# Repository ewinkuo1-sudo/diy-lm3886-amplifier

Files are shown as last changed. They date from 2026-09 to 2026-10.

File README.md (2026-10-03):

# LM3886 DIY AB 類立體聲後級

用兩顆 LM3886T 製作**內建電源的雙聲道純後級**，搭配使用者現有的 **Eversolo DAC-Z10（DAC＋前級）**。訊號路徑為 **DAC-Z10 RCA 前級輸出 → 本後級 → 喇叭**，音量與訊源選擇由 Z10 負責。本機採固定增益，前面板規劃電源及狀態指示。

這是第三個獨立擴大機專案，可與 [TPA3255 練習機](https://github.com/ewinkuo1-sudo/diy-tpa3255-amplifier) 及 [Purifi 主力機](https://github.com/ewinkuo1-sudo/diy-purifi-amplifier) 比較架構與製作經驗。

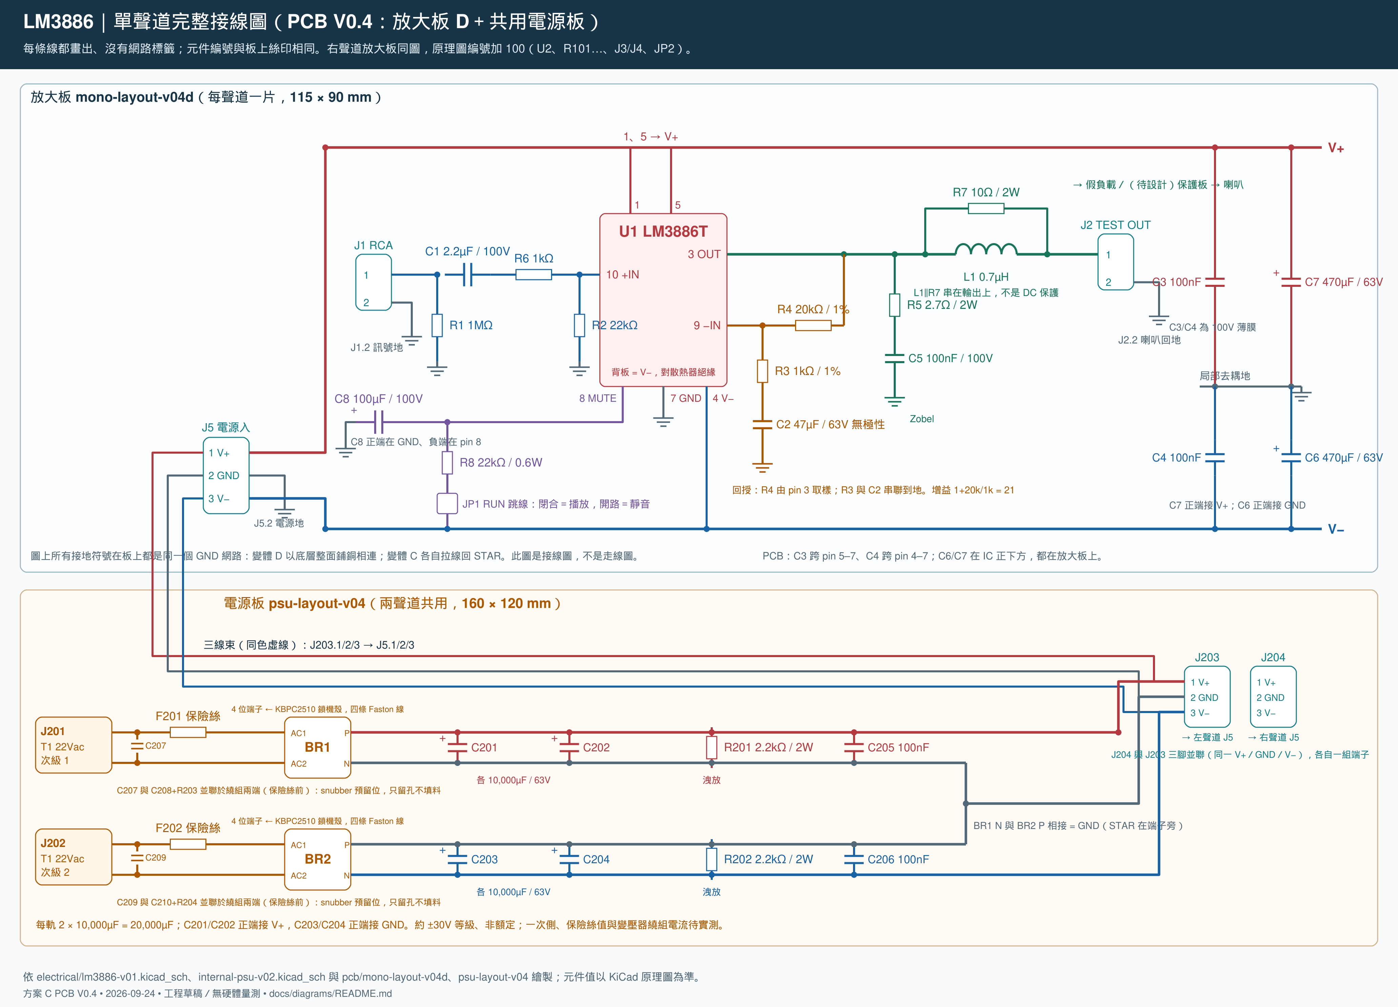
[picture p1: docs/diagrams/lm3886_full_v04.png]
單聲道完整接線圖（放大與電源電路自 V0.4 起未變，適用 V0.5.1 與規劃中的 V0.6）


## 目前狀態（2026-10-01 深夜）

- **方向改為「先挑殼、散熱器放殼內、以現有零件重排 PCB＝V0.6」**。機殼改選台灣現貨 **弘宙 102**（型錄 b420 前面板寬、d395 機身寬、c285 深不含把手、e105 高 → 內尺寸估 **393×273×100**，賣家未確認；BZ4312A2 留給下一台）。配置：後排「放大板 L｜電源板｜放大板 R」、前排變壓器居中、左前控制板、右前市電板；散熱器 **150×90×30 鋁擠 ×2 內置兩側**（鰭片朝牆、底板朝板、上蓋底板開通風孔；規格依 8 Ω 連續正弦 θSA ≤1.2 °C/W）。3D 配置：[chassis_102_v06_3d.png](docs/diagrams/chassis_102_v06_3d.png)。下單前問賣家內寬、通風孔、後面板是否空白。
- **控制／保護板 CTRL 與市電板 MAINS 第一版原理圖＋PCB V0.6 已畫**（2026-10-01 深夜）：CTRL 70×120（UPC1237 保護、7812 輔助電源、G2RL-1-E 喇叭繼電器 ×2、SFH617A 光耦靜音、TL431 旁通計時）、MAINS 70×100（SL22 10005 NTC、K_BYP、K_TRIG）。ERC 0、DRC 0 錯誤，市電／低壓銅箔距離 7.25 mm。繼電器 DC 分斷取 30 VDC 等級（使用者接受）。見 [docs/14](docs/14-V0.4-控制與保護板設計草案.md) 狀態列、[pcb/README「PCB V0.6」](pcb/README.md)。
- **放大板與電源板 V0.6 也畫了（2026-10-02 凌晨，以型錄幾何先畫）**：放大板 **90×80**，U1 用 KiCad 函式庫 TO-220-11 直立封裝、背板貼板邊直接鎖散熱器；電源板 **92×120**，兩欄 381LX、GBJ 朝前、AC 端子朝變壓器、DC 端子朝放大板（snubber 預留位未上板）。**V0.6 五板皆 DRC 0 錯誤**，機箱 3D 已換成真板。IC 幾何、C2 腳距、繼電器腳位到貨要核對。詳見 [pcb/README](pcb/README.md)；V0.5.1／V0.5／V0.4／V0.3 為歷史。**全部仍是工程草稿，不可送製。**
- **放大板與電源板現行為 V0.6.1（2026-10-03 使用者選定併入 main）**：零件、擺位、板尺寸、機殼與散熱器配置與 V0.6 完全相同，只把載流走線加寬到間距規則與鄰近焊盤允許的上限（放大板負電源腳間線 0.5→0.9、電源板主幹 3→5 等），兩板 DRC 0；V0.6 vs V0.6.1 走線電阻對照見 [pcb/README「PCB V0.6.1」](pcb/README.md)。CTRL／MAINS 仍為 V0.6 板檔。
- **目標喇叭 Usher Be-718**（標稱 8 Ω、實測低中音 >6 Ω、約 85 dB）：匹配估算見 [docs/01](docs/01-設計規格.md)；功率／散熱討論以 6–8 Ω 為準。
- **已到貨**：環形變壓器、yosontw 40 件電阻／WIMA／CDE／ROE（2026-09-22）、LM3886T 拆機品 ×4（2026-09-29，T 封裝、NS 打標）。已付 NT$4,821，整機估 10.9k–16.2k（[採購總表 §5](docs/00-採購總表.md)）。
- **2026-10-01 已量變壓器電氣**（採購總表 §1）：標籤 22V 4.2A×2＋12V 1A ≈ **197 VA**；兩組 22V 空載各 22.29 Vac（DCR 0.25／0.2 Ω）、串接 44.6 Vac 同相；12V 12.27 Vac；一次側約 2 Ω；市電 110 V。最壞軌電壓 **±33.5 V**，帶載推估連續 30–32 W／8 Ω。保險絲提案：一次側 T2.5A（有軟啟動）／T3.15A、22V 各 T5A、12V T1.25A。**未量：帶載電壓、絕緣、溫升。**
- **已量零件尺寸**（2026-09-23）：381LX Ø35×50 腳距 10；EKE Ø12×25 腳距 5；EGW 軸向 40×Ø20（V0.5 起改站立封裝，**腳距 15 是假設待實量**）；變壓器 Ø120×約 50、中心孔 Ø40。
- **選型定案**：C 方案雙聲道、雙橋整流、4×10,000µF／63V；47µF＝ROE EGW 無極性、470µF＝ROE EKE／63V；每聲道 30～40W／8Ω 為探索範圍而非額定。
- **本輪可買**：GBJ2510 ×2＋小散熱片＋M3 件、保險絲、機殼（弘宙 102）、散熱器 150×90×30 ×2、控制板零件一套（G2RL-1-E 12VDC ×5、UPC1237 ×2、SL22 10005、SFH617A-3 ×2、TL431、BC327 ×2、7812 等，見採購總表控制板列）；其餘未購件與順序見採購總表 §2／§3。

**要買零件看 [採購總表](docs/00-採購總表.md)**（已買／未買兩張表＋購買順序）。**要接手看 [HANDOFF.md](HANDOFF.md)**。**歷史逐日紀錄看 [CHANGELOG.md](CHANGELOG.md)**。

## 系統方塊

```mermaid
flowchart LR
    PRE[DAC-Z10\nDAC＋前級／音量控制]
    subgraph AMP[LM3886 純後級機殼]
        IN[RCA 輸入] --> C[兩顆 LM3886T 功率級]
        C --> D[輸出穩定網路]
        D --> REL[喇叭保護／繼電器\nCTRL 板 V0.6 草稿]
        AC[AC 入口／保險絲／開關] --> SS[軟啟動 NTC＋旁通\nMAINS 板 V0.6 草稿]
        SS --> T[隔離環形變壓器]
        T --> PSU[雙橋整流／濾波]
        PSU --> C
        CTRL[UPC1237 啟停／DC 偵測\nCTRL 板 V0.6 草稿] -. 控制 .-> C
        CTRL -. 控制 .-> REL
    end
    PRE --> IN
    REL --> SPK[喇叭]
```

## 設計重點

| 項目 | 目前選擇／待驗證 |
|---|---|
| 功率級 | LM3886T ×2，非橋接、非並聯；已訂拆機品，/NOPB 未確認 |
| 輸出目標 | 每聲道約 30～40W／8Ω 探索範圍，額定待實測 |
| 電源 | 已訂雙 22Vac＋單 12Vac；雙橋架構保留，約 ±30V 等級；VA／電流／最大電壓待確認 |
| 增益 | IC 中頻閉迴路 21 倍；含輸入串阻後約 20.09 倍 |
| 輸入 | DAC-Z10 RCA 前級輸出；後級 40W 約需 0.89Vrms，音量由 Z10 控制 |
| 靜音／保護 | 放大板保留測試跳線；CTRL 板 V0.6 草稿以 UPC1237 做 DC 偵測、開機延遲、掉電快斷，光耦接管 JP1 靜音，解除靜音＝喇叭繼電器吸合 |
| 散熱 | T 封裝，**2026-10-01 改以 8 Ω 連續正弦為準：每聲道散熱器 ≤1.2 °C/W**（6 Ω 正弦需 ≤0.65）、介面 ≤0.3 °C/W；選 150×90×30 鋁擠內置兩側，估法 θSA≈1000／表面積(cm²)；原 0.4 °C/W 是 ±41 V 前提的保守值 |
| 本版負載 | 8Ω 非感性假負載；目標喇叭 Usher Be-718（標稱 8Ω、低中音實測 >6Ω、靈敏度實測約 85dB），匹配估算見 [01](docs/01-設計規格.md)「目標喇叭」節；真實喇叭需另外驗證 |

TI 列出 ±35V、8Ω 下 50W 的元件性能條件；這不是本機實測規格。[原廠資料](https://www.ti.com/product/LM3886)

## 文件

| 文件 | 內容 |
|---|---|
| [採購總表](docs/00-採購總表.md) | **採購單一入口**：已買／未買、購買順序、商品連結 |
| [設計規格](docs/01-設計規格.md) | 電路、接地、Z10 介面與保護邊界 |
| [功率與散熱估算](docs/02-功率與散熱估算.md) | 可重算的數字、公式與假設 |
| [上電與驗收](docs/04-上電與驗收.md) | 從低電壓到雙聲道功率測試 |
| [內建電源與機構](docs/05-內建電源與機構.md) | 變壓器、整流、接地、機殼分區與電源估算 |
| [喇叭保護與啟停設計計畫](docs/13-喇叭保護與啟停設計計畫.md) | V0.4 需求：保護、延遲、DC 偵測與啟停方案 |
| [V0.4 控制與保護板設計草案](docs/14-V0.4-控制與保護板設計草案.md) | 控制板架構、啟停時序、與現有板介面、繼電器篩選、軟啟動與輔助電源計算；開頭狀態列記 2026-10-01 的選型決定與原理圖／PCB V0.6 偏離之處 |
| [控制板原理圖 CTRL](electrical/preview/control-v01.png)／[市電板 MAINS](electrical/preview/mains-v01.png) | 2026-10-01 第一版（生成器 `tools/build_control_board.py`，ERC 0）；[CTRL PDF](electrical/preview/control-v01.pdf)、[MAINS PDF](electrical/preview/mains-v01.pdf) |
| [導讀圖索引](docs/diagrams/README.md) | 單聲道完整接線圖（放大板＋電源板全部畫出）與五張中文導讀圖 |
| [BOM 草案](electrical/bom-draft.csv) | 由 KiCad netlist 匯出，含選型條件 |
| [驗證紀錄](electrical/validation.md) | ERC、網路核對與未驗證事項 |
| [原理圖說明](electrical/README.md) | 放大板與電源次級 KiCad 圖、看圖與重建方式 |
| [PCB](pcb/README.md) | **現行五板：放大板 V0.6.1 90×80 ×2、電源板 V0.6.1 92×120（V0.6 擺位＋加寬走線）、CTRL V0.6 70×120、MAINS V0.6 70×100，皆 DRC 0**；V0.6 放大板／電源板、V0.5.1／V0.5／V0.4／V0.3 歷史：板檔、DRC、審查結論與載流計算表 |
| [機箱 3D 配置](docs/diagrams/chassis_102_v06_3d.png) | 弘宙 102 內部等角＋俯視（`tools/draw_chassis_scene_v06.py`，pyvista；CTRL／MAINS 為真板 3D，放大板與電源板為 V0.6 目標外形示意） |
| [PCB 看圖資料](pcb/inspection-v051/README.md) | V0.5.1（放大板 D＋電源板）正反面銅箔、組裝、3D 預覽與零件核對表；[V0.5](pcb/inspection-v05/README.md)／[V0.4](pcb/inspection-v04/README.md)／[V0.3](pcb/inspection-v03/README.md) 版保留 |
| [工具說明](tools/README.md) | 各腳本用途與執行順序 |
| [接班進度](HANDOFF.md) | 現況與下一階段工作 |
| [變更紀錄](CHANGELOG.md) | 逐日進度歷史 |

## 電路圖與 PCB 預覽

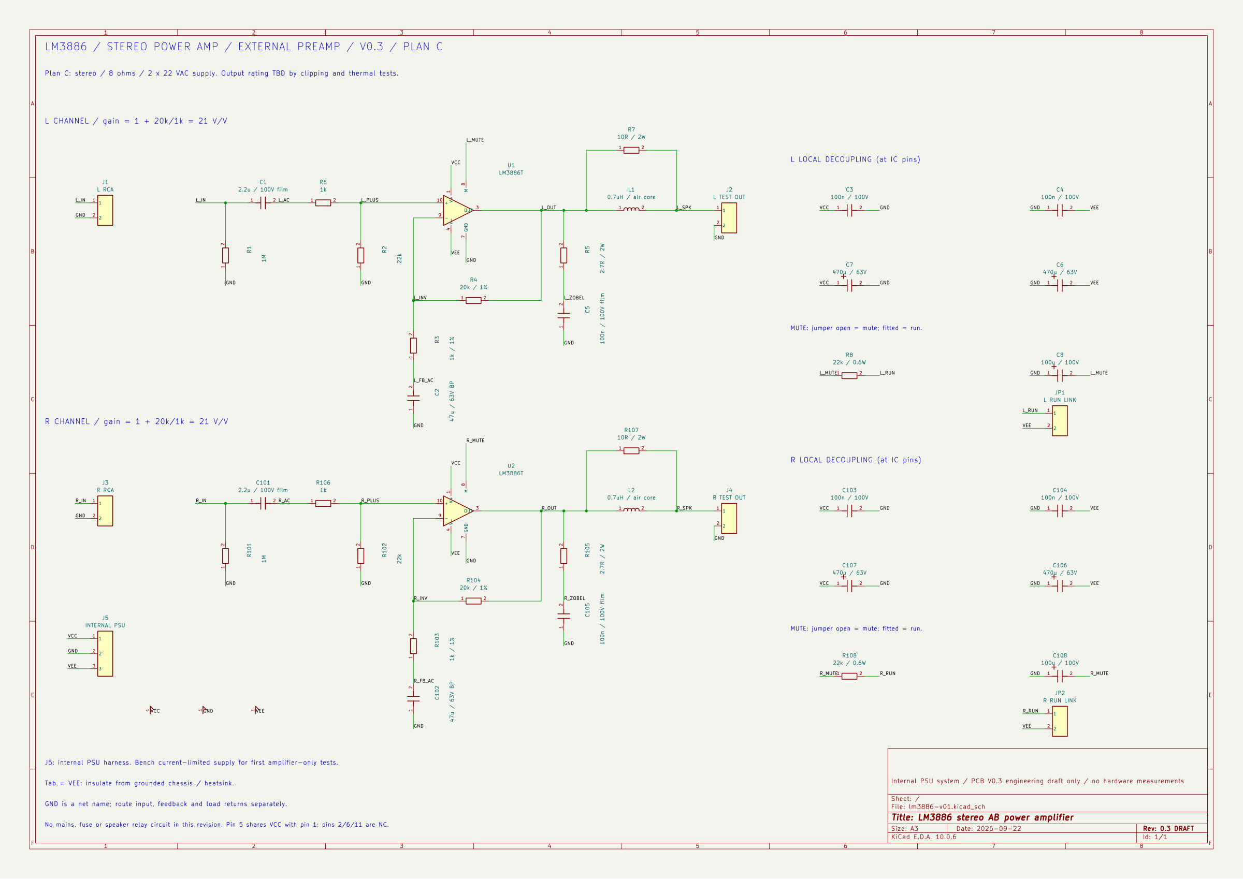
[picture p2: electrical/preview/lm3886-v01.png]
LM3886 放大板電路草案


[放大板 PDF](electrical/preview/lm3886-v01.pdf) · [KiCad 原理圖](electrical/lm3886-v01.kicad_sch)

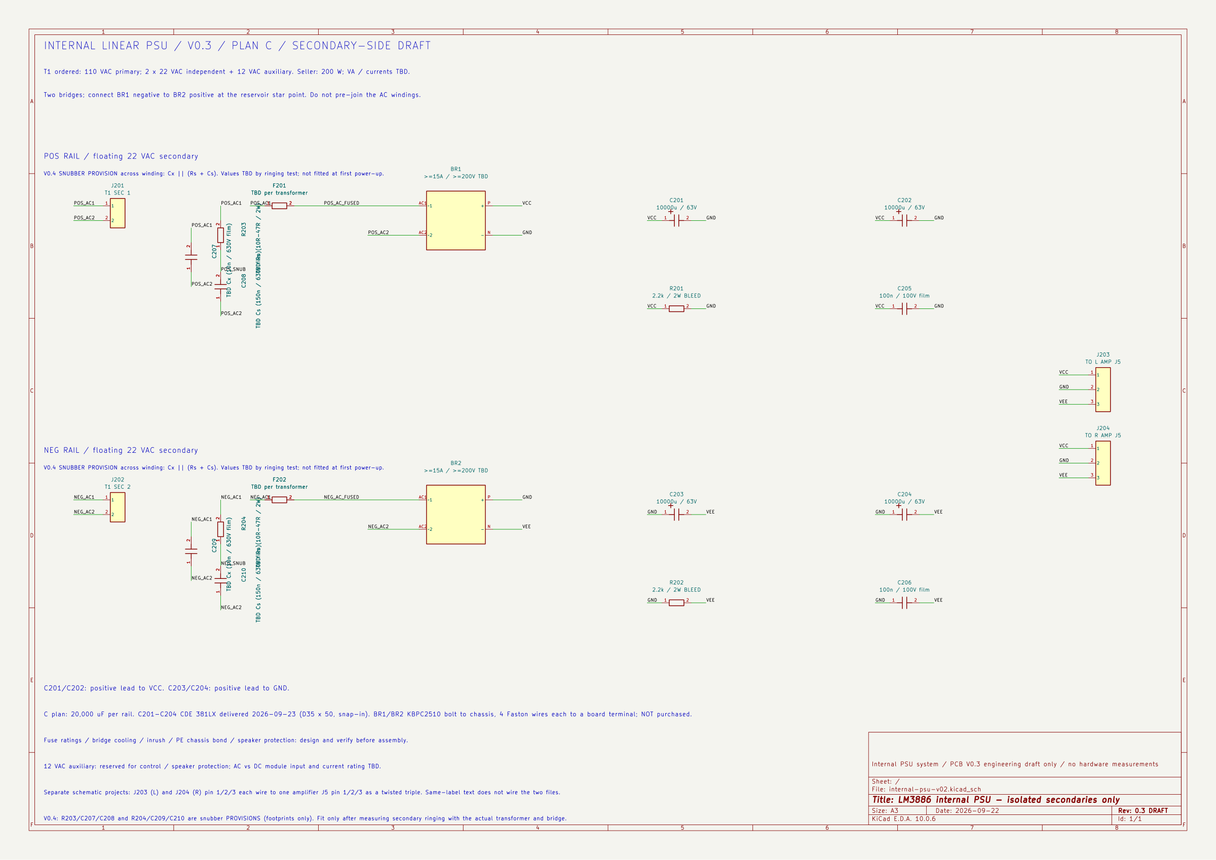
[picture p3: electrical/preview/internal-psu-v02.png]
內建電源次級整流濾波草案


[電源 PDF](electrical/preview/internal-psu-v02.pdf) · [電源 BOM](electrical/psu-bom-draft.csv)

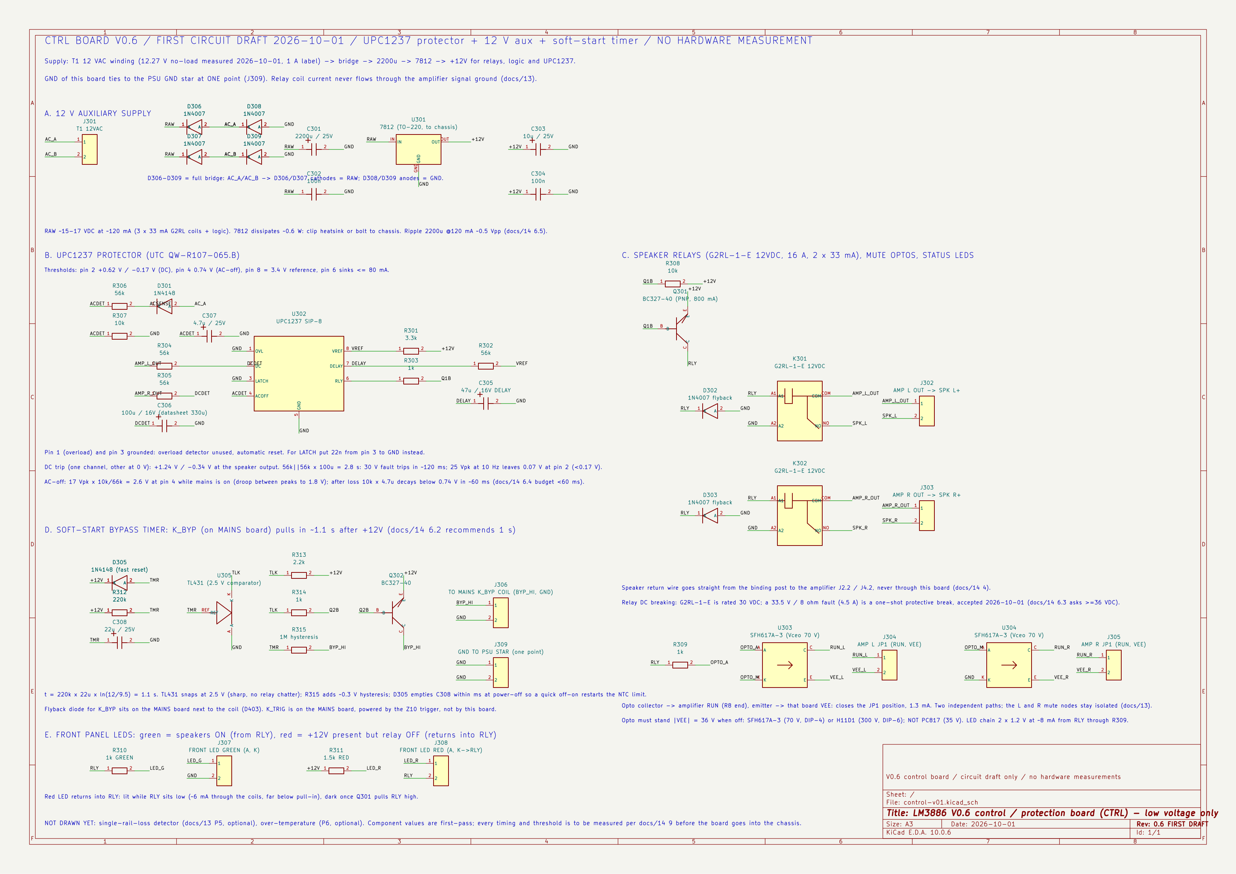
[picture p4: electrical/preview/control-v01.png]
控制／保護板 CTRL 原理圖 V0.6 第一版


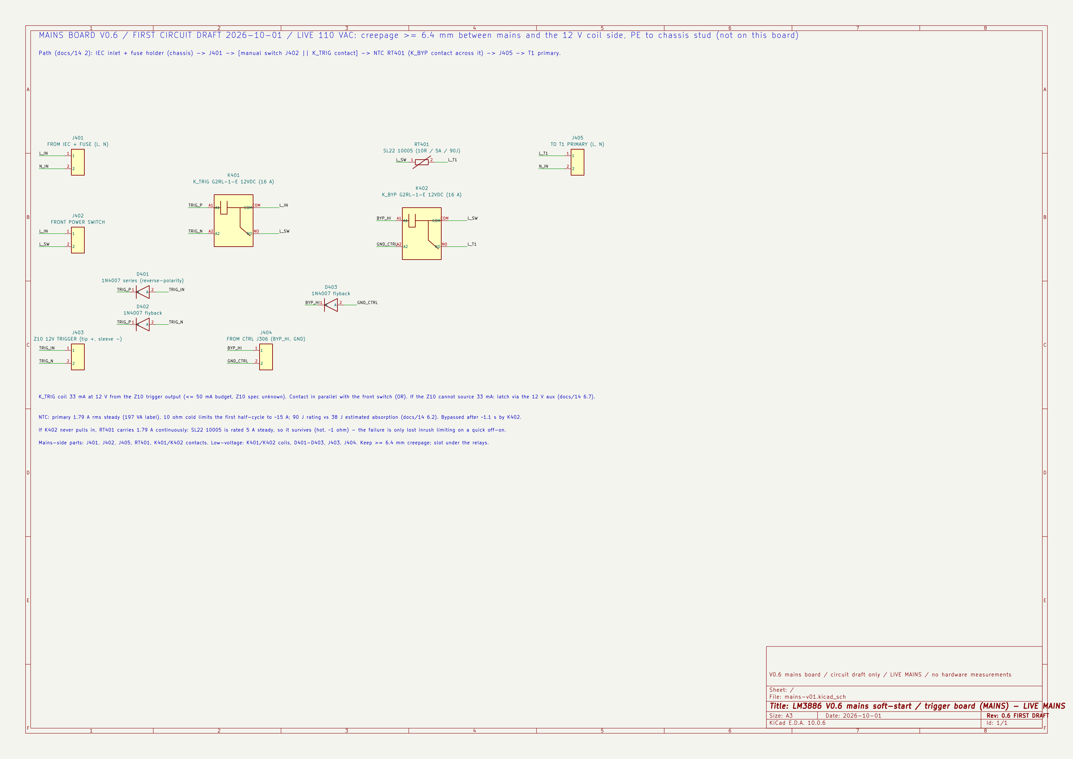
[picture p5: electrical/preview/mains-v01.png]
市電板 MAINS 原理圖 V0.6 第一版


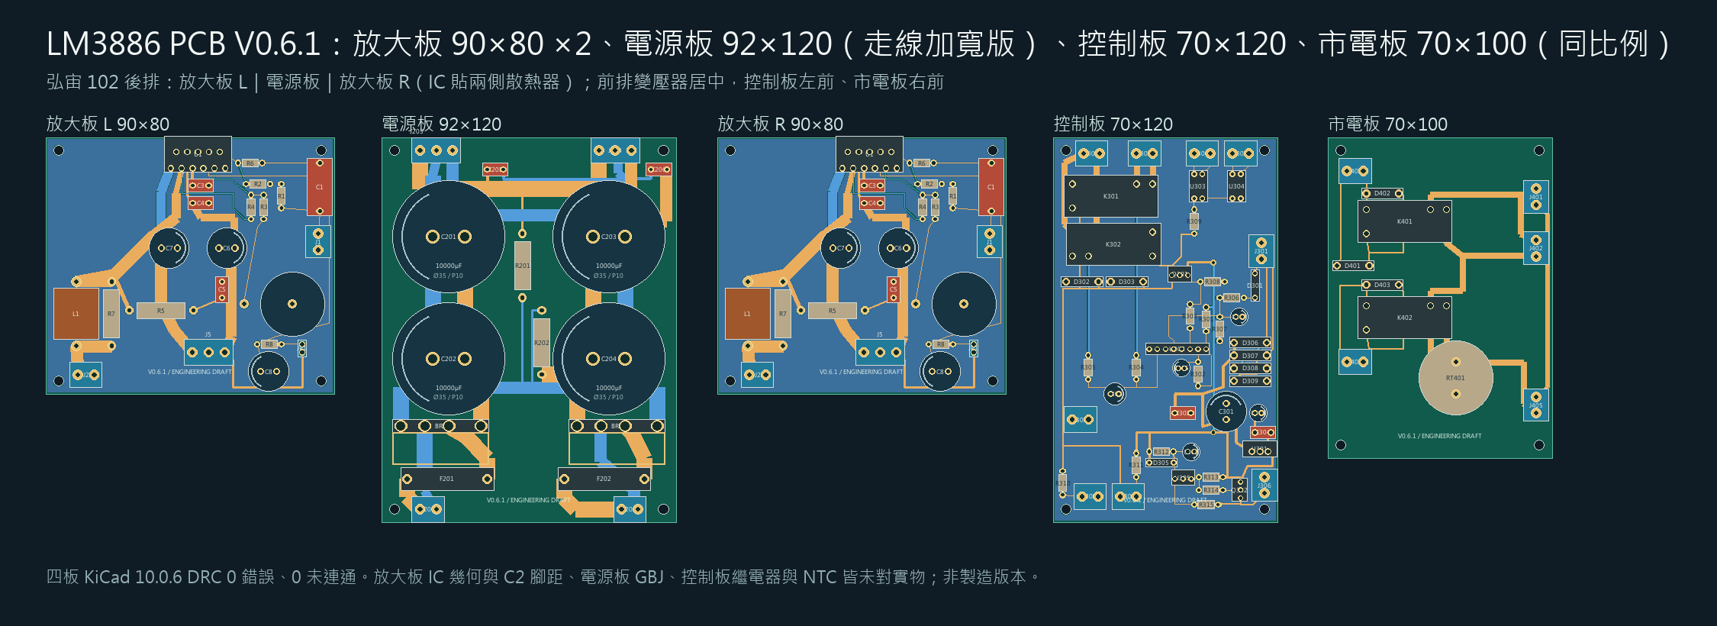
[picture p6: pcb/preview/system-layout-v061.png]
PCB 現行五板：放大板 V0.6.1 90×80 ×2、電源板 V0.6.1 92×120、控制板 V0.6 70×120、市電板 V0.6 70×100


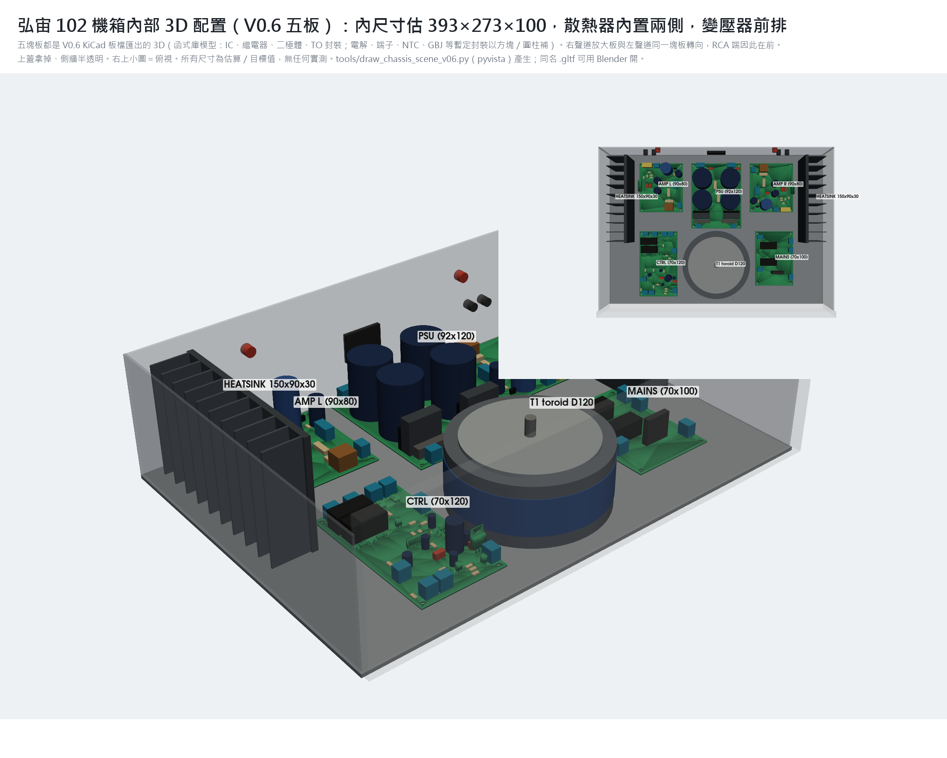
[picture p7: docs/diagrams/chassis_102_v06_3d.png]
弘宙 102 機箱內部 3D 配置（V0.6 五板；V0.6.1 外形、零件與擺位相同，3D 不變）


## 重建與下一步

需要 Python 3、KiCad 10 CLI、Poppler 的 `pdftoppm`，Python 無第三方套件需求：

```sh
python3 tools/rebuild.py
```

`rebuild.py` 目前只重建放大板與電源次級原理圖；控制板與市電板（`tools/build_control_board.py`）和所有 PCB 腳本要手動跑，順序見 [tools/README](tools/README.md)。

下一步（詳見 [HANDOFF](HANDOFF.md)）：量 LM3886T 三個尺寸、問賣家弘宙 102 內寬 → 必要時修正 V0.6.1 放大板的 U1 位置；審控制板原理圖與 PCB、買控制板零件並核對繼電器腳位；麵包板實測 UPC1237 在 12 V 供電下的門檻與延遲；變壓器帶載量測。放大板單獨驗證時仍可用限流實驗電源；成機供電採內建方案。

PDF 重製：先執行 `python3 tools/rebuild.py`，再以安裝 reportlab／pypdf 的 Python 執行 `tools/build_project_pdf.py`；非 Windows 環境需設定 `LM3886_FONT` 指向 CJK TrueType 字型。產物在 `output/`，不入版控。

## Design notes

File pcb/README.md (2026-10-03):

# PCB

**現行版本：放大板與電源板 V0.6.1（2026-10-03 使用者選定併入 main，V0.6 擺位不動、載流走線加寬，見「PCB V0.6.1」節），CTRL／MAINS V0.6。** V0.6 放大板／電源板自同日起為歷史（板檔保留）。**V0.5.1 自 2026-10-02 起為歷史**（2026-10-01 使用者選定併入 main：電源板的整流橋改為 GBJ2510 直立上板，取代 KBPC2510 鎖機殼＋Faston 線；放大板 D 90×90 與 V0.5 相同），兩板 KiCad 10.0.6 DRC 0 違規、0 未連通，見下方「PCB V0.5.1」節；正反面銅箔、組裝極性、3D 預覽與零件核對表在 [inspection-v051](inspection-v051/README.md)。**V0.5 電源板（`psu-layout-v05`）自 2026-10-01 起為歷史**，板檔與 [inspection-v05](inspection-v05/README.md) 保留。**V0.4 自 2026-09-29 起為歷史版本**（放大板 D／C 與電源板板檔、DRC、[inspection-v04](inspection-v04/README.md) 保留）。**V0.3 自 2026-09-24 起為歷史版本**：板檔、DRC、雜湊綁定與審查結論原樣保留供對照，不再修改。

PCB 現行五板（放大板／電源板 V0.6.1，CTRL／MAINS V0.6）

---

## PCB V0.3（B 方案，歷史版本）

**兩片 100×90 mm 單聲道放大板＋一片 160×120 mm 共用電源板。**（2026-09-24 放大板已改為 **115×90 mm** 並重建，DRC 0 違規、0 未連通。）

> ⚠️ **工程草稿，不可送製。** 兩板在 KiCad 10.0.6 下 0 DRC 違規、0 未連通，54＋35 焊盤網路與原理圖相符；但封裝是暫定外框與假設高度，溫升、散熱、機構與線束都沒驗證，**沒有 Gerber**。DRC 與中心線幾何不代表高頻穩定、載流溫升或製造條件已驗證。

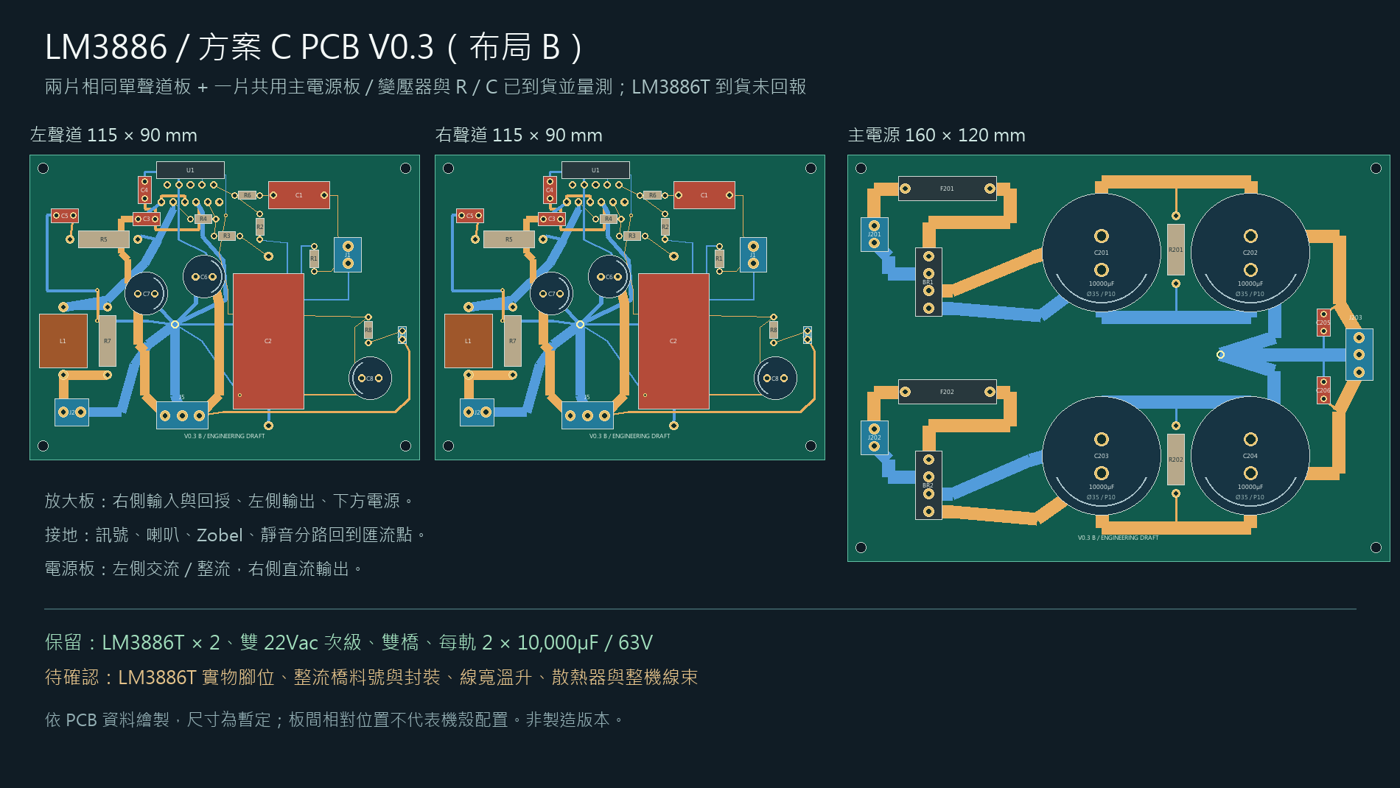
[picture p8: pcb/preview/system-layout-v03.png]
PCB V0.3（歷史）


| 項目 | 單聲道板 ×2 | 電源板 ×1 |
|---|---|---|
| 可編輯 PCB | [mono-layout-v03.kicad_pcb](mono-layout-v03.kicad_pcb) | [psu-layout-v03.kicad_pcb](psu-layout-v03.kicad_pcb) |
| 專案規則 | [KiCad 專案](mono-layout-v03.kicad_pro) | [KiCad 專案](psu-layout-v03.kicad_pro) |
| 圖面 | [PNG](preview/mono-layout-v03.png)／[原生 SVG](preview/mono-v03-native.svg) | [PNG](preview/psu-layout-v03.png)／[原生 SVG](preview/psu-v03-native.svg) |
| 封裝假設 | [清單](mono-layout-v03-footprints.csv) | [清單](psu-layout-v03-footprints.csv) |
| 原生 DRC | [0 違規、0 未連通](mono-v03-drc.json) | [0 違規、0 未連通](psu-v03-drc.json) |

其他資料：[銅箔計算表](current-budget-v03.md)／[完整計算資料與輸入雜湊](current-budget-v03.json)、[驗證摘要](validation-v03.json)、[DRC 檔案綁定](drc-provenance-v03.json)、[正反面／組裝／3D 看圖資料](inspection-v03/README.md)、[零件與封裝核對表](inspection-v03/parts-audit.md)、[左右聲道對照](mono-channel-mapping.csv)。

V0.1／V0.2 板檔、封裝庫與舊腳本已於 2026-09-21 刪除，從 Git 歷史（`41b217c`）取回；僅保留 `archive/v02/*-layout-v02.json` 供 `analyze_pcb_v03.py` 做 V0.2→V0.3 對照。

## PCB V0.4 放大板・變體 C（改良星型接地，2026-09-24 晚）

> ⚠️ **工程草稿，不可送製。** 電路、零件與封裝外框全部沿用 V0.3；只改零件位置與銅箔。KiCad 10.0.6 下 **0 DRC 違規、0 未連通**，54 焊盤網路與原理圖相符，接地分路檢查通過（[validation-v04.json](validation-v04.json)）。變體 D 與電源板 V0.4 見後兩節；**使用者 2026-09-24 選定 D 為主，C 保留備查**。

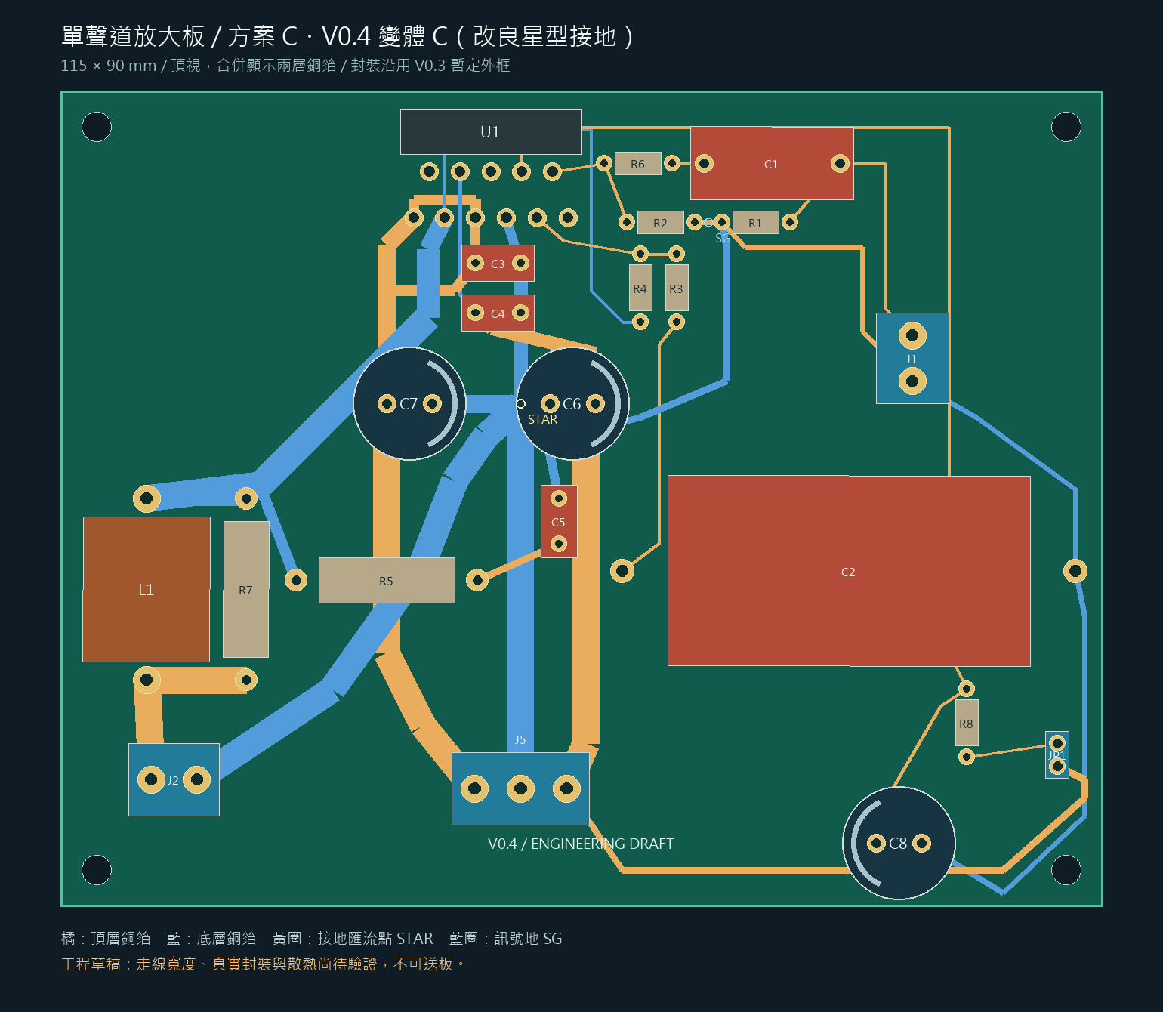
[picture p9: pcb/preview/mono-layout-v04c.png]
PCB V0.4 變體 C


| 項目 | 檔案 |
|---|---|
| 可編輯 PCB／專案 | [mono-layout-v04c.kicad_pcb](mono-layout-v04c.kicad_pcb)／[.kicad_pro](mono-layout-v04c.kicad_pro) |
| 位置與逐段走線定義 | [tools/pcb_layout_v04.py](../tools/pcb_layout_v04.py)（生成器 [build_pcb_v04.py](../tools/build_pcb_v04.py) 沿用 V0.3 封裝庫與 `build()`） |
| 原生 DRC／驗證 | [mono-v04c-drc.json](mono-v04c-drc.json)／[validation-v04.json](validation-v04.json)（`verify_pcb_v04.py`，匯合半徑 5 mm，V0.3 為 4 mm） |
| 走線資料／封裝清單 | [mono-layout-v04c.json](mono-layout-v04c.json)／[footprints.csv](mono-layout-v04c-footprints.csv) |

**改了什麼（對應 2026-09-24 審 V0.3 的七點中屬於放大板的五點）：**

1. 100n 旁路貼 IC 腳：C3 (45.8,19) 跨 pin 5 (V+)–pin 7 (GND)，C4 (50.8,24.5) 跨 pin 4 (V-)–pin 7；V- 從 pin 3／pin 5 之間以 0.5 mm 底層線直下 pin 4（IC 腳間隙 1.4 mm 只容得下這個寬度，是全板最窄處）。
2. 470µF C7 (36,34.5)／C6 (54,34.5) 上移到 IC 正下方，**STAR (50.8,34.5) 就是兩顆之間 9 mm 長的接地條**；J5 留板底，GND 以 3 mm 底層線沿 x=50.8 直上 STAR。
3. J1 訊號與接地並排走到 C1／R1／R2 角落，R1.1 與 R2.1 相鄰 3 mm 形成訊號地 SG (71.5,14.5)，再一條 0.8 mm 底層線回 STAR；C2 與 C8 的接地併入這條訊號地分路（靜音電容只有 mA 級，不再另走一路）。
4. Zobel C5 移到 (55,45)，接地 1.0 mm 直入 STAR；R5 輸出端接到輸出主幹的轉折點 (22,43.5)。
5. C2 改平放在右半 (112,53)，C2.2 靠 R3.1；R8／C8／JP1 移到右下角。**4 個過孔全部取消**（V0.3 有 3 個），每個網路都在單層走完或用零件焊盤換層。

| 銅箔中心線長度（mm） | V0.3 | V0.4 C |
|---|---:|---:|
| C3 接地端→U1.7 | 24.2 | **5.2** |
| C4 接地端→U1.7 | 33.2 | **10.7** |
| C3 旁路迴路（U1.5→C3.1＋C3.2→U1.7） | 43.6 | **10.2** |
| C4 旁路迴路（U1.4→C4.2＋C4.1→U1.7） | 50.2 | **27.0** |
| C6 接地端→STAR | 16.5 | **3.2** |
| C7 接地端→STAR | 11.5 | 9.8 |
| Zobel C5 接地端→STAR | 72.1 | **11.5** |
| J1 接地→STAR（訊號地） | 64.6 | 76.5 |
| C2 接地→STAR（訊號地） | 69.7 | 107.1 |
| J5 接地→STAR | 27.4 | 42.5 |
| U1.3→L1.1 輸出主幹 | 48.8 | 50.2 |
| U1.3→R4.2 回授取樣線 | 7.1 | **50.4** |
| U1.9→R4.1（-IN） | 5.5 | 12.5 |

粗體是本輪目標項。**代價**（有意為之、可再議）：回授取樣線改由 pin 3 向上穿過 pin 2／pin 4 之間，沿 IC 本體下方（y=4.3，底層）繞到右側 R4，長 50 mm——它是低阻抗的輸出取樣，長度本身影響小，但與 -IN 線的 12.5 mm 一起，比 V0.3 多暴露在 IC 附近；訊號地與 J5 回流變長是把 STAR 上移到 IC 下方的直接結果。這些都是中心線幾何，**不代表失真或穩定度已改善**，要等實板量。

**還沒做：** 變體 D（同位置、底層整面 GND 鋪銅取代分支；`verify` 的分路檢查對 D 要跳過）、電源板 V0.4（原理圖已加 J204／snubber，PCB 未畫）、V0.4 的 `current-budget`／`analyze` 對照、3D 與導讀圖。V0.3 板檔與雜湊全部未動。

### 變體 D（底層整面接地，2026-09-24 深夜）

零件位置、訊號與電源銅箔與變體 C **完全相同**；只把 C 的全部 GND 分路線拿掉，改成一整片底層 GND 鋪銅（`AMP_D`，間距 0.3、最小寬 0.35、焊盤熱阻隔 spoke 0.8／gap 0.5）。KiCad 10.0.6 **0 DRC 違規、0 未連通**，鋪銅填完只有一個連通區（沒有孤島）；`verify_pcb_v04.py` 對 D 跳過分路檢查，只核對焊盤網路與鋪銅連通區數。

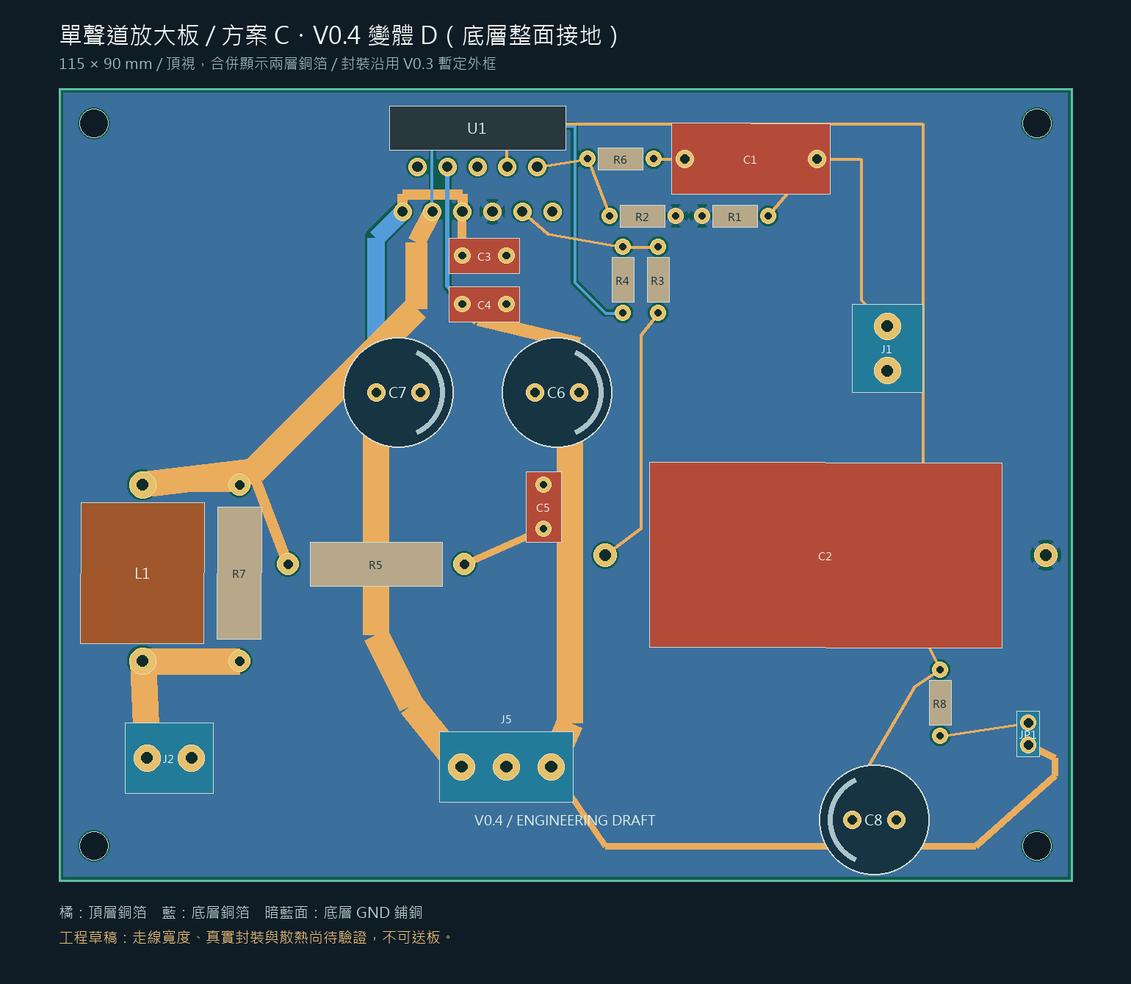
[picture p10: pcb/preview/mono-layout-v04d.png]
PCB V0.4 變體 D


| 項目 | 檔案 |
|---|---|
| 可編輯 PCB／專案 | [mono-layout-v04d.kicad_pcb](mono-layout-v04d.kicad_pcb)／[.kicad_pro](mono-layout-v04d.kicad_pro) |
| 原生 DRC／走線＋鋪銅資料 | [mono-v04d-drc.json](mono-v04d-drc.json)／[mono-layout-v04d.json](mono-layout-v04d.json)（含填銅多邊形） |

**2026-09-24 使用者決定：以 D 為主、C 保留。** 隨即修掉 D 的缺點：3 mm 輸出主幹（pin 3→L1）與 Zobel 接主幹的線改走**頂層**，C7→pin 1 的 V+ 進線改走底層（只在 x=36 切一道 20 mm 的短縫），原本多給 C3.1 的一條 V+ 分支拿掉（C3.1 由 pin 1→pin 5 連線供電）。修後底層鋪銅仍是單一連通區，板左半改由 C7 下方整片相連，不再只靠窄帶；DRC 0 違規、0 未連通。C 與 D 的取捨（星型分路 vs 整面低阻抗回流）沒有實測前不能說哪個一定好，所以 C 的板檔照樣留著。

### 電源板 V0.4（每聲道端子＋snubber 預留，2026-09-24 深夜）

AC 進線、保險絲、橋堆端子、四顆 10,000µF、洩放電阻的位置與 V0.3 相同，對應 2026-09-24 審查的第 5、6 點：

- **J203（左聲道）／J204（右聲道）各一組 3P 端子**在右板邊 (151,42)／(151,66)。STAR 移到 (138,59.08)，C202／C204 的接地各一條 4 mm 底層線斜入 STAR，再各一條 4 mm 線到兩個端子的 G 腳；V+ 走頂層 x=145 到 J203 再沿板邊 x=157 到 J204，V- 走頂層 x=145 從底部上來分別接兩個端子。C205／C206 100n 貼在 STAR 旁。
- **每繞組一組 snubber 預留位**（Cx‖(Rs+Cs)）排在橋堆端子下方一列：C207／C208／R203 在 y=53，C209／C210／R204 在 y=113。接在保險絲**前**的繞組兩端（J201／J202 那一側），1 mm 細線；Cx、Cs 用 `Film_P15`、Rs 用 `R_2W_P20` 暫代，**只留孔不填料**，等變壓器實測振鈴再決定值與是否裝。
- KiCad 10.0.6 **0 DRC 違規、0 未連通**，50 焊盤網路與 V0.4 電源原理圖相符（[psu-v04-drc.json](psu-v04-drc.json)、[validation-v04.json](validation-v04.json)）。負半邊的 snubber 回線原本與 V- 充電線（4 mm）重疊 0.2 mm，改到 y=110.6 後通過。

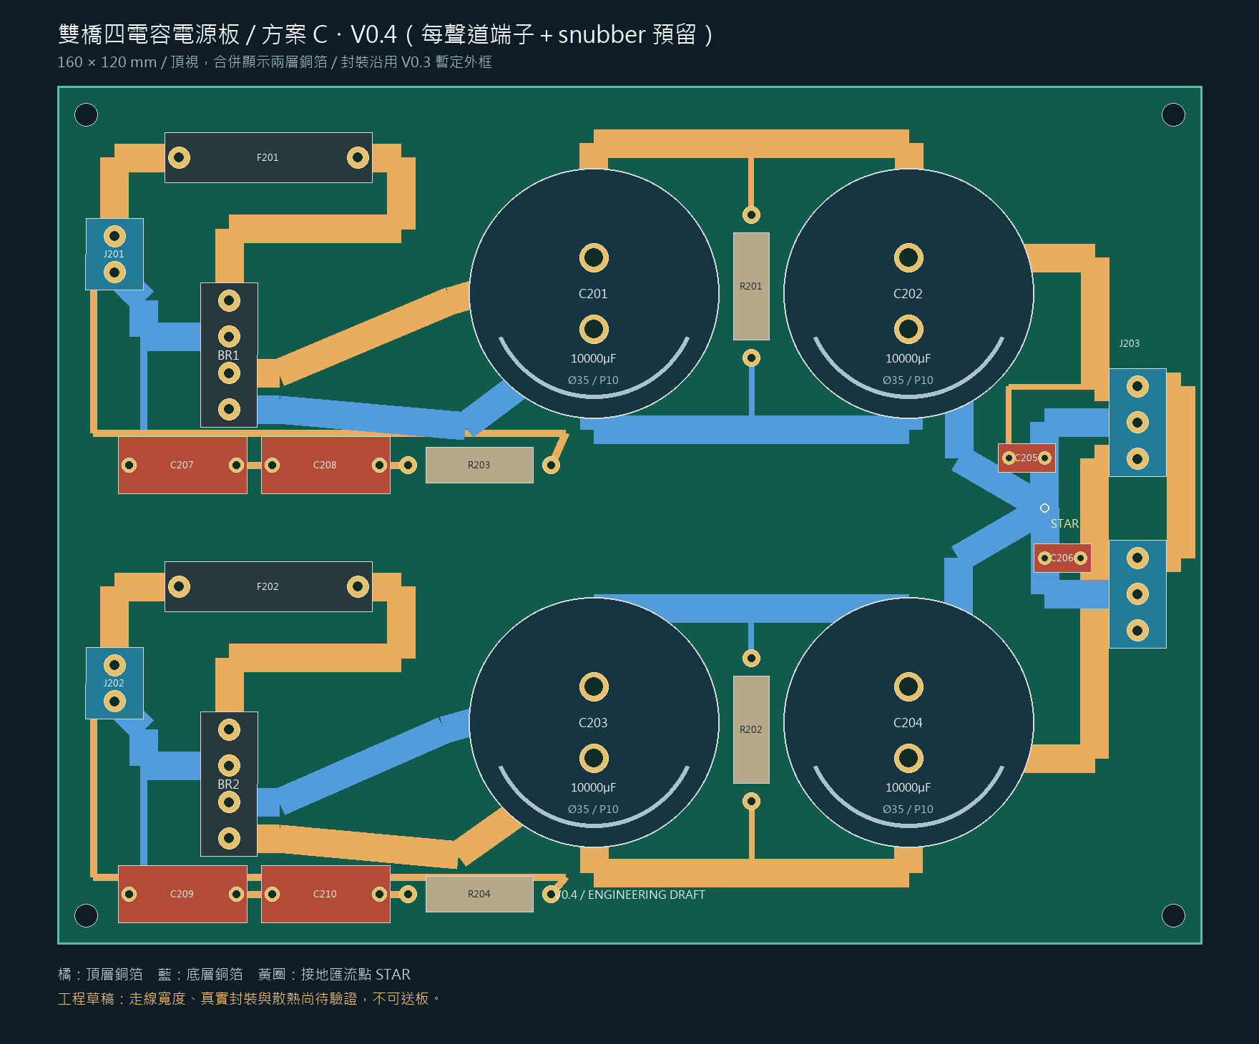
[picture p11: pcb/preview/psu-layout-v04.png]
PCB V0.4 電源板


| 項目 | 檔案 |
|---|---|
| 可編輯 PCB／專案 | [psu-layout-v04.kicad_pcb](psu-layout-v04.kicad_pcb)／[.kicad_pro](psu-layout-v04.kicad_pro) |
| 位置與走線定義 | [tools/pcb_layout_v04_psu.py](../tools/pcb_layout_v04_psu.py) |
| 原生 DRC／走線資料／封裝清單 | [psu-v04-drc.json](psu-v04-drc.json)／[psu-layout-v04.json](psu-layout-v04.json)／[footprints.csv](psu-layout-v04-footprints.csv) |

**V0.4 三塊板都畫完了（放大板 C、放大板 D、電源板）**，等使用者看圖選 C 或 D。之後才做：V0.4 的 `current-budget`／`analyze` 對照、3D 與導讀圖、系統並排圖；V0.3 檔案與雜湊全部未動。

## PCB V0.6.1（2026-10-03，現行：放大板與電源板）

**V0.6.1 = V0.6 放大板與電源板，零件、位置、網路、板尺寸、機殼（弘宙 102）與散熱器（150×90×30 內置）全部不動，只把載流路徑的銅箔加寬到 0.3 mm 間距規則與鄰近焊盤允許的上限。** CTRL／MAINS 不在此版（沿用 V0.6）。兩板 KiCad 10.0.6 DRC **0 錯誤、0 未連通**，[validation-v061.json](validation-v061.json) 通過（同 V0.6 的檢查：焊盤網路、IC 背板貼邊、GBJ 散熱片包絡、鋪銅單一連通區）。

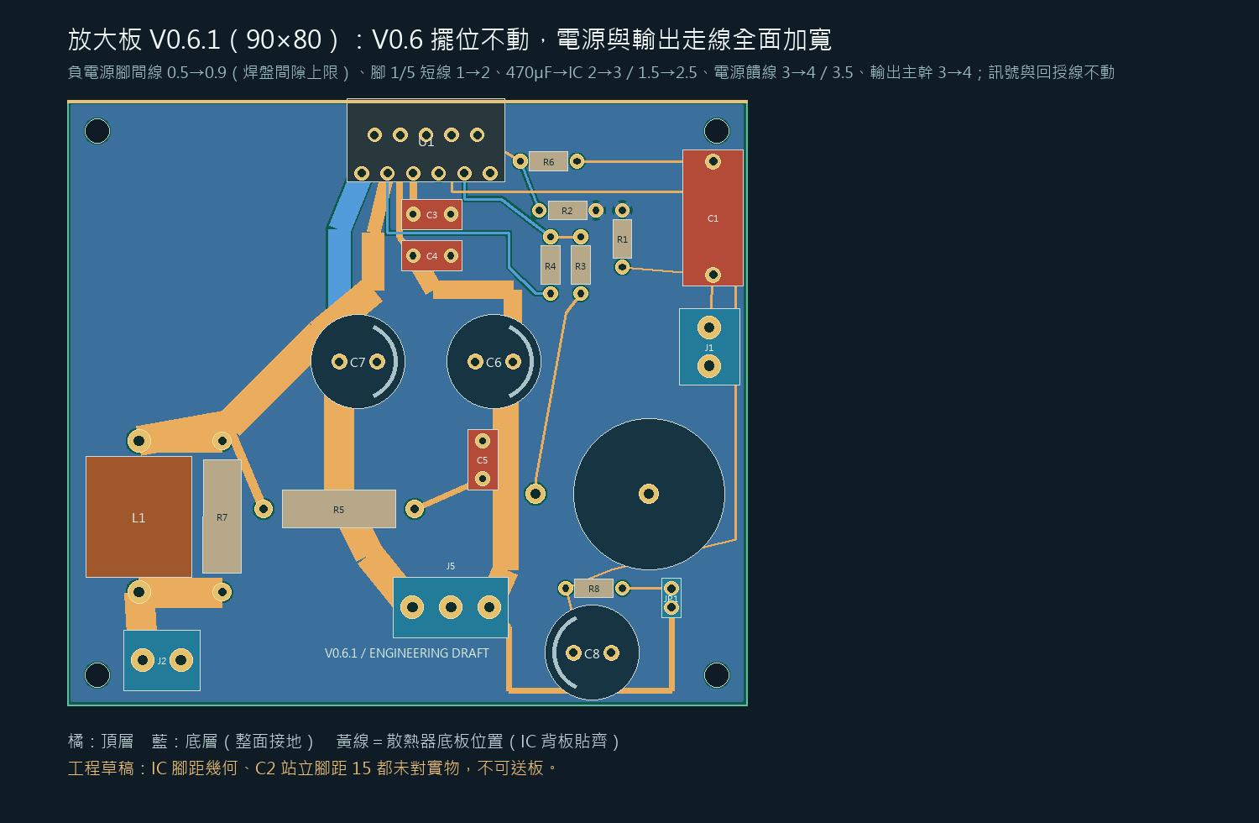
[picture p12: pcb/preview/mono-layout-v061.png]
PCB V0.6.1 放大板


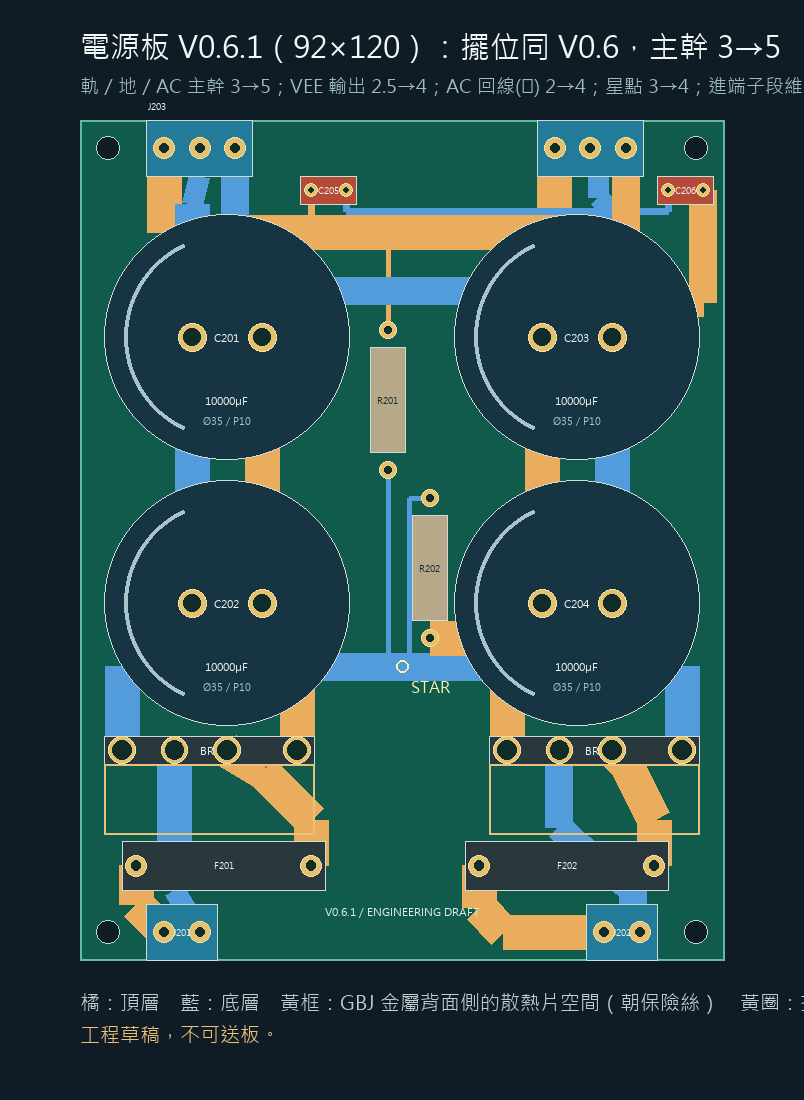
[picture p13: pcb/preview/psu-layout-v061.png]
PCB V0.6.1 電源板


**改了什麼（寬度 mm，V0.6→V0.6.1）**

| 板 | 走線 | V0.6 | V0.6.1 | 限制來源 |
|---|---|---:|---:|---|
| 放大板 | 負電源腳間線 C4→U1 腳 4（從腳 3／5 之間下去） | 0.5 | **0.9** | 焊盤 1.8、同排腳距 3.4 → 最多 1.0；腳 3 的輸出短線同時縮到 1.8（＝焊盤直徑）才能各留 0.3 |
| 放大板 | 腳 1／5 V+ 底層短線（兩排腳之間） | 1.0 | 2.0 | 兩排腳間隙 5.08 扣焊盤 |
| 放大板 | 470 µF→IC：C7→腳 1（底層）／C6→C4（頂層） | 2.0／1.5 | 3.0／2.5 | — |
| 放大板 | 電源饋線 J5→C7／J5→C6 | 3.0／3.0 | 4.0／**3.5** | 負饋線 x=58 夾在 C5（x=55）與 C2.2（x=62）之間，4.0 會碰 C2.2 |
| 放大板 | 輸出主幹 腳 3→L1：短線／立段／主幹 | 2.0／2.5／3.0 | 1.8／3.0／4.0 | 主幹兩個轉折點各往左上移 0.6（(34,31.5)→(33.4,30.9)、(22,43.5)→(21.4,42.9)）避開 4.0 的 VCC 饋線；Zobel 饋線改接到新頂點 |
| 放大板 | L1→R7、L1→J2 喇叭線 | 1.5／3.0 | 3.0／4.0 | — |
| 電源板 | 正負軌、地、AC 主幹 | 3.0 | 5.0 | — |
| 電源板 | VEE 輸出（頂層 y=26、底層 y=24.5） | 2.5 | 4.0 | — |
| 電源板 | AC 回線（−）J202→BR2 | 2.0 | 4.0 | 原本是唯一比同類細的一段 |
| 電源板 | GND 星點連線 y=78 | 3.0 | 4.0 | 5.0 會離 R202.2 焊盤只剩 0.30 |
| 電源板 | 進 3P 端子的地線末段、J201.2→(13.5,110) | 3.0 | 3.0 | 端子焊盤 3.0、腳距 5.08，寬線進焊盤會碰隔壁腳；首輪 DRC 抓到 POS_AC2 的 5.0 端蓋壓到 J201.1，改從 y=110 起寬 |

訊號、回授、靜音、Zobel、洩放與 100 nF 旁路的細線不動（不載負載電流）。回授取樣線長度 35.5 mm、反相輸入線 16.5 mm 與 V0.6 相同；安靜線對電源線的投影最小邊距由 2.33 降到 2.08 mm（L_FB_AC 對 VEE 饋線，頂層同層），對負載線由 9.03 升到 9.13 mm。

**走線電阻對照**（`tools/analyze_pcb_v061.py` → [current-budget-v061.json](current-budget-v061.json)；1 oz／25 °C，±30 V、每聲道 40 W／8 Ω 正弦為尺寸計算點、靜態 85 mA、充電脈衝 15 % 導通；只算銅箔中心線，不含焊盤、孔壁、焊點、接頭、線材、ESR 與電感，**不是溫升預測**）

| 路徑 | 長度 mm | 最窄 V0.6→V0.6.1 | R V0.6 mΩ | R V0.6.1 mΩ | 變化 | 峰值 A | 峰值壓降 V0.6.1 mV | 發熱 V0.6.1 mW |
|---|---:|---:|---:|---:|---:|---:|---:|---:|
| 放大板 IC 腳 3→L1 | 54 | 2.0→1.8 | 9.8 | 8.1 | −17 % | 3.2 | 26 | 41 |
| 放大板 L1→喇叭端子 | 9 | 3.0→4.0 | 1.5 | 1.1 | −25 % | 3.2 | 3 | 6 |
| 放大板 正電源端子→U1 腳 1 | 61 | 2.0→3.0 | 12.0 | 8.5 | −29 % | 3.2 | 28 | 23 |
| 放大板 正電源端子→U1 腳 5 | 73 | 1.0→2.0 | 17.8 | 11.4 | −36 % | 3.2 | 37 | 31 |
| 放大板 負電源端子→U1 腳 4 | 75 | 0.5→0.9 | 29.8 | 18.5 | −38 % | 3.2 | 60 | 50 |
| 放大板 470µF C7→U1 腳 1 | 26 | 2.0→3.0 | 6.2 | 4.2 | −33 % | 3.2 | 13 | 11 |
| 放大板 470µF C6→U1 腳 4 | 42 | 0.5→0.9 | 24.4 | 13.9 | −43 % | 3.2 | 45 | 37 |
| 電源板 正軌 電容→L 輸出 | 79 | 3.0→5.0 | 12.9 | 7.7 | −40 % | 3.2 | 25 | 21 |
| 電源板 正軌 電容→R 輸出 | 107 | 3.0→5.0 | 17.4 | 10.4 | −40 % | 3.2 | 34 | 28 |
| 電源板 負軌 電容→L 輸出 | 109 | 2.5→4.0 | 20.0 | 12.4 | −38 % | 3.2 | 40 | 33 |
| 電源板 負軌 電容→R 輸出 | 77 | 2.5→4.0 | 13.8 | 8.5 | −39 % | 3.2 | 28 | 23 |
| 電源板 地 STAR→L 輸出 | 104 | 3.0→3.0 | 17.0 | 11.7 | −31 % | 3.2 | 37 | 58 |
| 電源板 地 STAR→R 輸出 | 105 | 3.0→3.0 | 17.1 | 11.9 | −31 % | 3.2 | 38 | 59 |
| 電源板 正橋→第一顆電容 | 23 | 3.0→5.0 | 3.8 | 2.3 | −40 % | 14.6 | 33 | 73 |
| 電源板 正橋充電回地 | 31 | 3.0→4.0 | 5.0 | 3.2 | −36 % | 14.6 | 47 | 103 |
| 電源板 負橋→第一顆電容 | 23 | 3.0→5.0 | 3.8 | 2.3 | −40 % | 14.6 | 33 | 73 |
| 電源板 負橋充電回地 | 31 | 3.0→4.0 | 5.0 | 3.2 | −36 % | 14.6 | 47 | 103 |
| 電源板 AC 端子→保險絲（+） | 11 | 3.0→5.0 | 1.8 | 1.1 | −40 % | 14.6 | 16 | 35 |
| 電源板 保險絲→正橋 | 22 | 3.0→5.0 | 3.6 | 2.2 | −40 % | 14.6 | 32 | 69 |
| 電源板 AC 回線（+） | 27 | 3.0→3.0 | 4.5 | 3.1 | −31 % | 14.6 | 45 | 98 |
| 電源板 AC 端子→保險絲（−） | 25 | 3.0→5.0 | 4.1 | 2.5 | −40 % | 14.6 | 36 | 79 |
| 電源板 保險絲→負橋 | 18 | 3.0→5.0 | 3.0 | 1.8 | −40 % | 14.6 | 26 | 57 |
| 電源板 AC 回線（−） | 31 | 2.0→4.0 | 7.6 | 3.8 | −50 % | 14.6 | 56 | 121 |

23 條路徑的發熱合計由 1.99 W 降到 1.23 W（同一情境）。**怎麼看：** 這些 mΩ 跟喇叭 8 Ω、變壓器二次側實量 0.25／0.2 Ω、G2RL 接點（規格上限 100 mΩ）、整流橋壓降相比都是零頭，加寬不會改變聲音或功率數字；改的理由是放大板負電源那段 0.5 mm 與電源板 AC 回線 2.0 mm 明顯比同類細、而加寬不花任何成本。**訂板選 2 oz 銅可以再把全部數字減半**（含改不寬的腳間線），JSON 內附 2 oz 與 85 °C 兩個敏感度欄位。

| 項目 | 放大板 90×80 ×2 | 電源板 92×120 |
|---|---|---|
| 可編輯 PCB | [mono-layout-v061.kicad_pcb](mono-layout-v061.kicad_pcb) | [psu-layout-v061.kicad_pcb](psu-layout-v061.kicad_pcb) |
| 走線 JSON／封裝清單 | [mono-layout-v061.json](mono-layout-v061.json)／[清單](mono-layout-v061-footprints.csv) | [psu-layout-v061.json](psu-layout-v061.json)／[清單](psu-layout-v061-footprints.csv) |
| 原生 DRC | [0 錯誤](mono-v061-drc.json) | [0 錯誤](psu-v061-drc.json) |
| 驗證摘要／電阻對照 | [validation-v061.json](validation-v061.json)／[current-budget-v061.json](current-budget-v061.json) | 同左 |
| 五板同比例圖 | [system-layout-v061.png](preview/system-layout-v061.png)（CTRL／MAINS 為 V0.6） | 同左 |

生成器：`tools/pcb_layout_v061.py`（匯入 V0.6 的定義，只覆寫寬度與兩個轉折點，檔頭列出每項限制）、`build_pcb_v061.py`、`verify_pcb_v061.py`、`render_pcb_v061.py`、`analyze_pcb_v061.py`。**2026-10-03 使用者看圖後「沒問題就併入 main」→ 已 fast-forward 併入，V0.6.1 為放大板／電源板現行版，V0.6 兩板退為歷史。** 機箱 3D 圖仍由 V0.6 板檔 STL 畫（外形、零件、擺位相同，銅箔不入 STL）。

## PCB V0.6（2026-10-02 凌晨；CTRL／MAINS 現行，放大板／電源板自 2026-10-03 起由 V0.6.1 取代）

**V0.6 是為弘宙 102 機殼（散熱器內置兩側）重排的一整套：放大板 90×80 ×2、電源板 92×120、控制板 CTRL 70×120、市電板 MAINS 70×100。** 四種板 KiCad 10.0.6 DRC **0 錯誤、0 未連通**（剩絲印重疊警告），`validation-v06.json`（放大板／電源板）與 `validation-v06-ctrl.json`（CTRL／MAINS）通過。

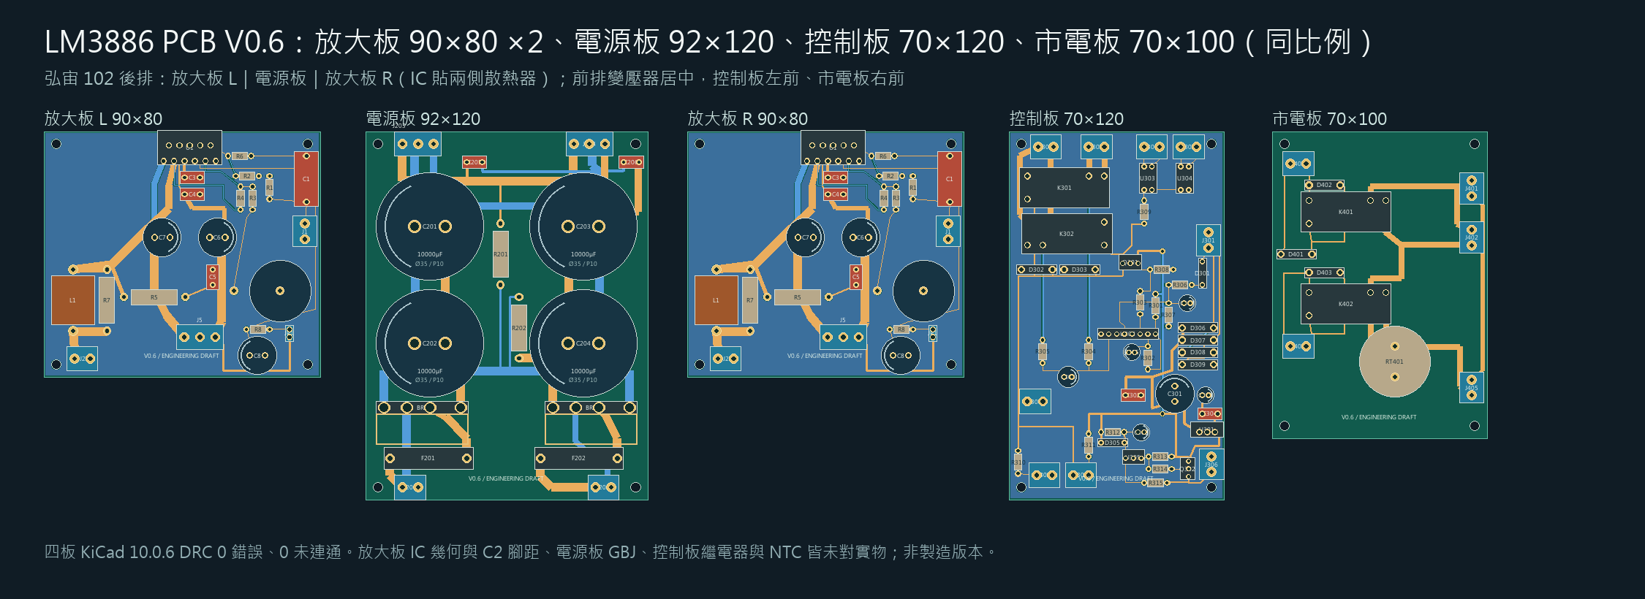
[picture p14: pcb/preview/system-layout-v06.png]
PCB V0.6 五板


- **放大板 `mono-layout-v06` 90×80**：V0.5 D 的電路與大部分擺位，**U1 改用 KiCad 函式庫 TO-220-11 直立封裝並放在 y=9.58，背板與板邊齊平，直接鎖散熱器底板**（使用者方案 B；型錄幾何，未對實物）。IC 上方不再走線：Kelvin 回授改走底層 y=17.5、靜音線從腳 7／9 之間下來走 y=12、pin 1／5 的 V+ 以底層短線在兩排腳之間相連。板高 90→80，輸出端子、電源端子、靜音零件上移 10，C2 站立電容移到 y=52。**同一塊板左右聲道共用**：右聲道板轉 180° 讓 IC 貼右側散熱器，RCA 端子因此在前側，輸入線要沿板邊拉約 90 mm。
- **電源板 `psu-layout-v06` 92×120**：四顆 381LX 兩欄（正欄 x=21、負欄 x=71），洩放電阻立在兩欄之間，GBJ2510 ×2 轉 180° 放前段（金屬背朝保險絲，10 mm 散熱片包絡 y 92–102），保險絲與 AC 端子沿前緣朝變壓器，兩組 3P 直流輸出沿後緣朝放大板。GND 星點是底層 y=78 的連線。**snubber 預留位 C207–C210／R203／R204 放不下、未上板**（原理圖仍有；需要時改接在變壓器端子）。
- **CTRL 70×120**：UPC1237 保護、7812 輔助電源、G2RL-1-E ×2、SFH617A 光耦靜音 ×2、TL431 旁通計時、底層整面接地。**MAINS 70×100**：SL22 10005 NTC、K_BYP、K_TRIG；市電側與低壓側銅箔最小距離 7.25 mm ≥ 6.4。電路來自 `electrical/control-v01`／`mains-v01`。

> ⚠️ 工程草稿，不可送製。U1、繼電器、SIP／DIP／TO、二極體封裝取自 KiCad 10 函式庫（焊盤編號改成原理圖腳名，3D 模型保留）；電解、端子、GBJ、NTC、C2 站立腳距 15 是暫定外框或型錄值，全部未對實物。G2RL 腳位（IEC 11＝COM、14＝NO）到貨要核對。

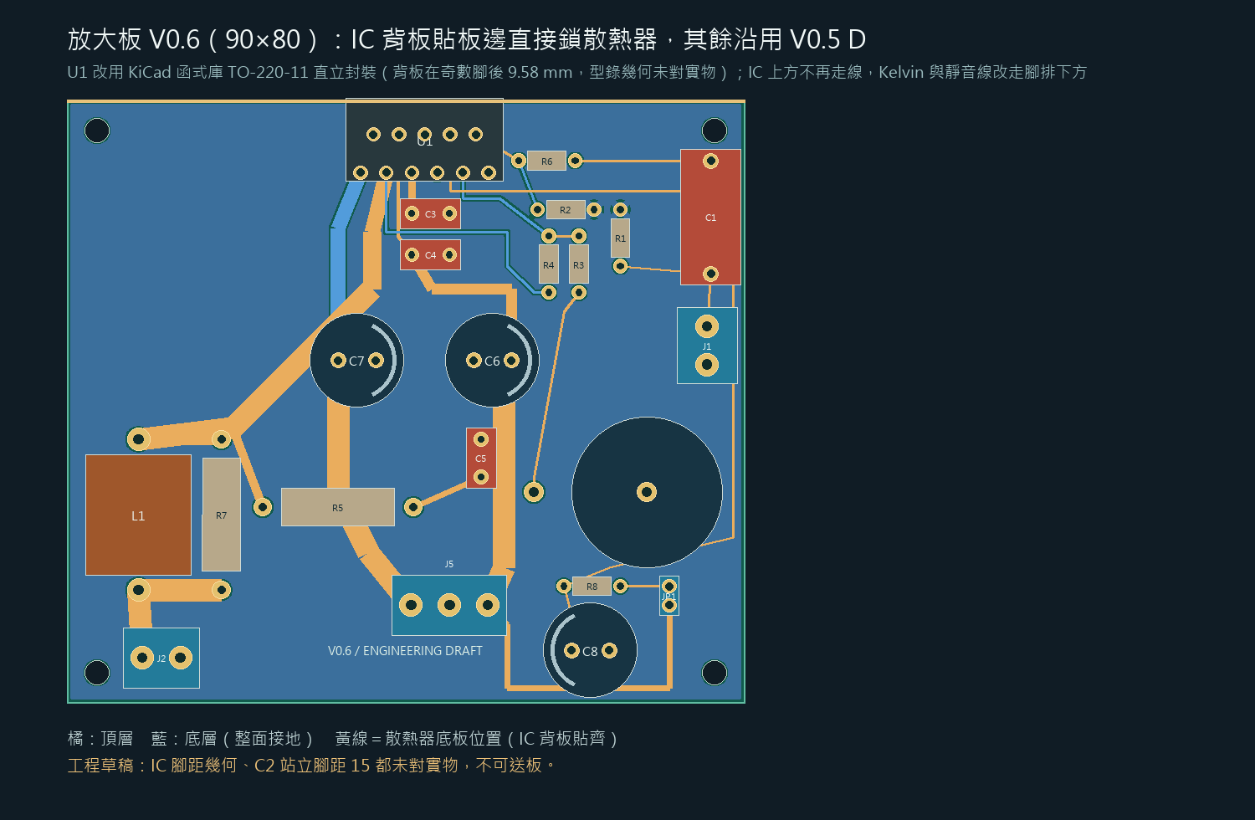
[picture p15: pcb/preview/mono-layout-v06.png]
PCB V0.6 放大板


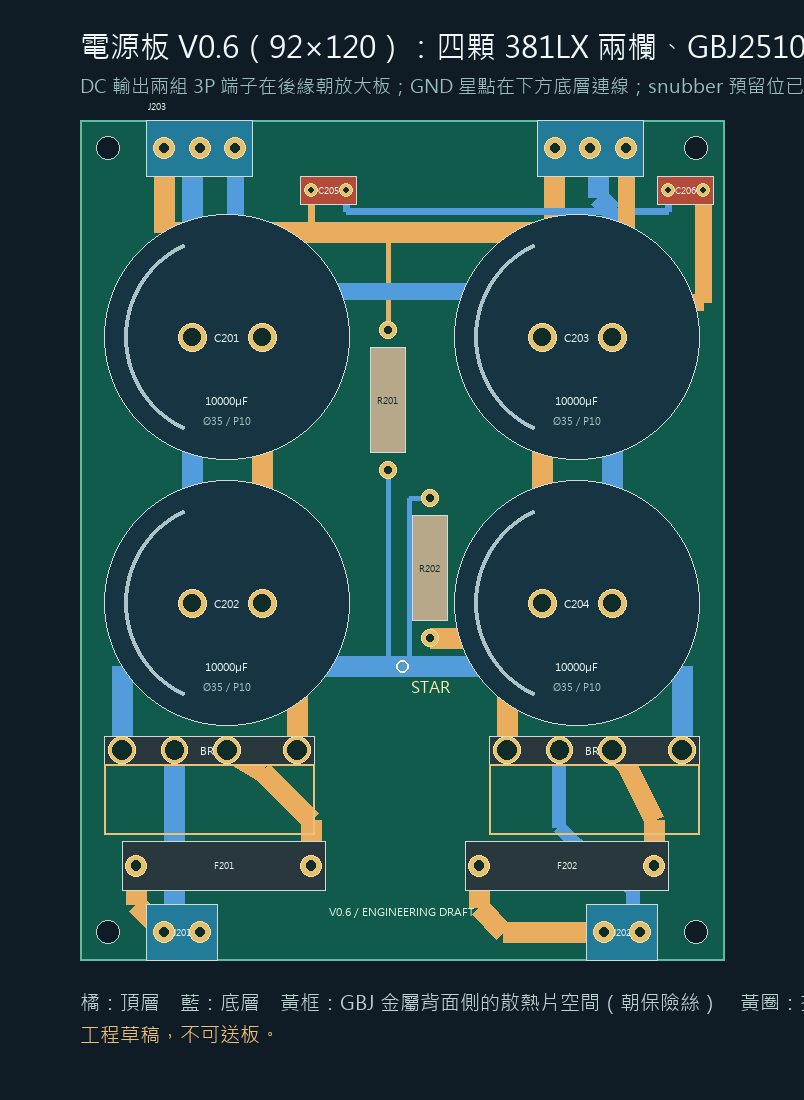
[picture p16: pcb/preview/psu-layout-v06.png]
PCB V0.6 電源板


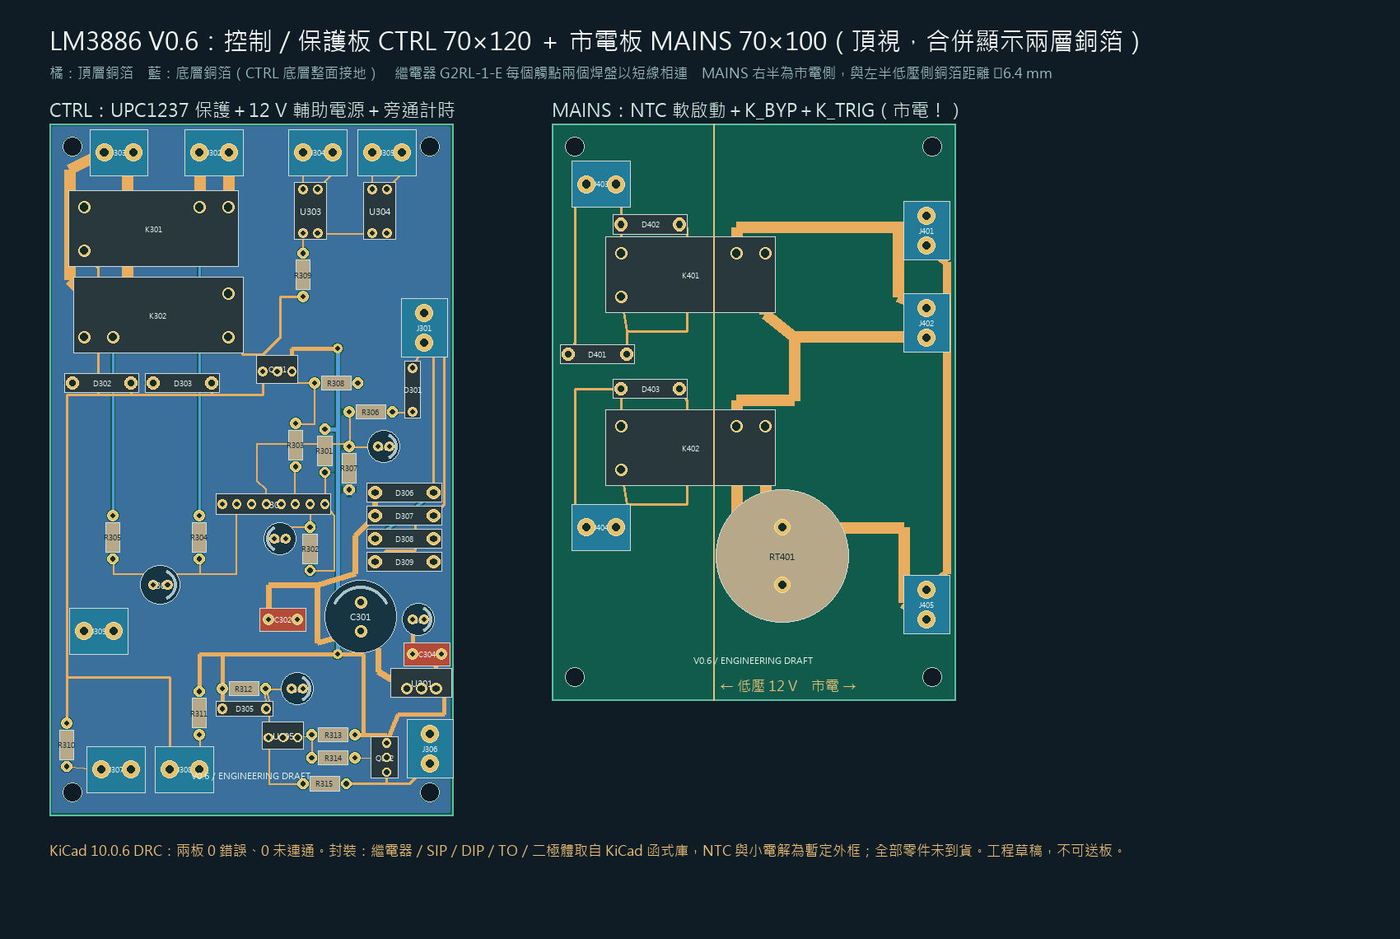
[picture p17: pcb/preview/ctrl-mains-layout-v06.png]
PCB V0.6 CTRL＋MAINS


| 項目 | 放大板 90×80 ×2 | 電源板 92×120 | CTRL 70×120 | MAINS 70×100 |
|---|---|---|---|---|
| 可編輯 PCB | [mono-layout-v06.kicad_pcb](mono-layout-v06.kicad_pcb) | [psu-layout-v06.kicad_pcb](psu-layout-v06.kicad_pcb) | [ctrl-layout-v06.kicad_pcb](ctrl-layout-v06.kicad_pcb) | [mains-layout-v06.kicad_pcb](mains-layout-v06.kicad_pcb) |
| 封裝假設 | [清單](mono-layout-v06-footprints.csv) | [清單](psu-layout-v06-footprints.csv) | [清單](ctrl-layout-v06-footprints.csv) | [清單](mains-layout-v06-footprints.csv) |
| 原生 DRC | [0 錯誤](mono-v06-drc.json) | [0 錯誤](psu-v06-drc.json) | [0 錯誤](ctrl-v06-drc.json) | [0 錯誤](mains-v06-drc.json) |
| 驗證摘要 | [validation-v06.json](validation-v06.json)（含 IC 背板貼邊、GBJ 散熱片包絡） | 同左 | [validation-v06-ctrl.json](validation-v06-ctrl.json)（含市電／低壓距離） | 同左 |

機箱 3D 配置（弘宙 102，散熱器內置、變壓器前排）：[docs/diagrams/chassis_102_v06_3d.png](../docs/diagrams/chassis_102_v06_3d.png)，由 `tools/draw_chassis_scene_v06.py`（pyvista）用 kicad-cli 匯出的五塊板 STL 畫。生成器與流程見 [tools/README](../tools/README.md)。V0.5.1 三板（放大板 D 90×90＋電源板 125×130）自 V0.6 起為歷史。

## PCB V0.5.1（整流橋上板，2026-10-01，現行）

> ⚠️ **工程草稿，不可送製。** 只改電源板：BR1／BR2 由「4 位端子接機殼上的 KBPC2510」改為 **GBJ2510 直立裝在板上**，電路、零件、網路、板尺寸 125×130 與其他零件位置全部不變；放大板 D 沿用 V0.5 板檔（`mono-layout-v05d`）。電源板 KiCad 10.0.6 **0 DRC 違規、0 未連通**，50 焊盤網路與原理圖相符（[validation-v051.json](validation-v051.json)）。**2026-10-01 使用者看過預覽後選定併入 main。** 3D／正反面／零件核對見 [inspection-v051](inspection-v051/README.md)。

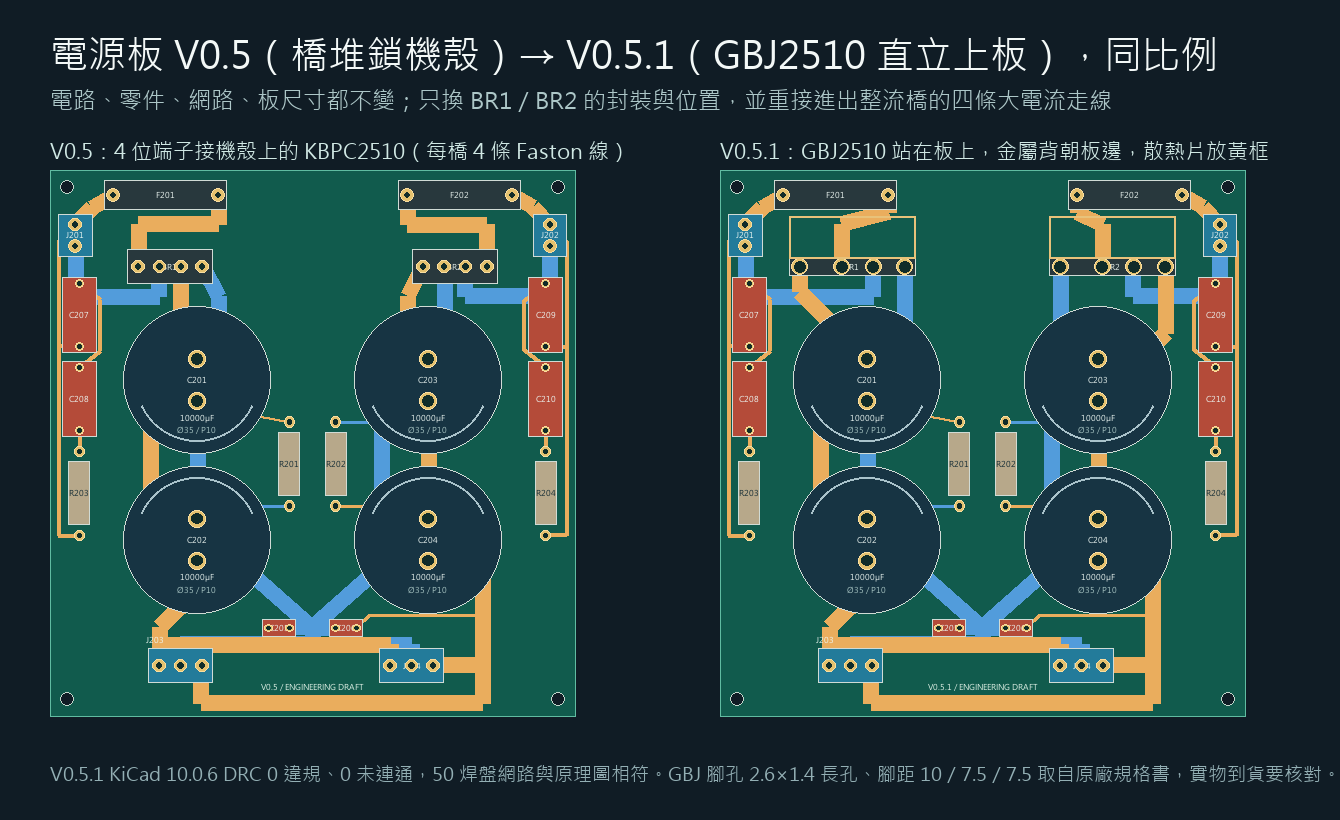
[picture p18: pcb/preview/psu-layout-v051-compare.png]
電源板 V0.5 → V0.5.1


**為什麼改：** 變壓器 2026-10-01 量完（2×22.29 Vac 空載、繞組 4.2 A、次級迴路約 0.3 Ω），使用者想把整流放回板上少掉八個 Faston 壓接點與四條大電流線。KBPC2510W（接腳版）28.5 mm 方塊塞不進上緣 27 mm 的條帶，GBJ2510 直立只占 30×4 mm，放得下且板不必加大。

| 項目 | V0.5 | V0.5.1 |
|---|---|---|
| BR1／BR2 封裝 | `BridgeTerminal4_P5.08`（4 位 5.08 螺絲端子） | **`GBJ_Upright_P10_7.5_7.5`**（新；Diodes DS21221：腳距 10／7.5／7.5、扁腳 1.0×2.2 → 長孔 2.6×1.4、焊盤 3.8×2.6，腳序 ＋ ～ ～ －，絲印標極性與散熱面粗線） |
| 位置 | (21,23) 轉 0°／(104,23) 轉 180° | **(19,23)／(81,23) 都轉 0°**：印字面朝電容（+y）、金屬背朝板邊（−y）。右邊不鏡射旋轉，否則金屬背會朝向電容；右半四條線因此另外佈，與左邊不完全對稱 |
| 散熱 | 橋堆鎖機殼 | 金屬背那側預留寬 30×厚 10 mm 散熱片空間（離保險絲座 1.0、離電容外框 1.5 mm，`verify_pcb_v051.py` 檢查） |
| 進出走線 | — | 僅 POS／NEG_AC_FUSED、POS／NEG_AC2、VCC／GND／VEE 進電容的七條重接；其餘 0 改動 |

| 板 | 檔案 |
|---|---|
| 電源板 V0.5.1 | [psu-layout-v051.kicad_pcb](psu-layout-v051.kicad_pcb)／[.kicad_pro](psu-layout-v051.kicad_pro)／[JSON](psu-layout-v051.json)／[封裝清單](psu-layout-v051-footprints.csv)／[DRC](psu-v051-drc.json)／[預覽](preview/psu-layout-v051.png)／[與 V0.5 對照](preview/psu-layout-v051-compare.png) |
| 放大板 D | 同 V0.5：[mono-layout-v05d.kicad_pcb](mono-layout-v05d.kicad_pcb) |
| 生成器／驗證 | `tools/pcb_layout_v051_psu.py`（由 `pcb_layout_v05_psu.py` 衍生，只覆寫 BR 與七條走線）、`build_pcb_v051.py`（新增 `make_fp_oval`）、`verify_pcb_v051.py`、`render_pcb_v051.py`、`*_inspection_v051.py` |

重建：`kicad-cli sch export netlist`（psu）→ KiCad 內建 python 跑 `tools/build_pcb_v051.py` → `kicad-cli pcb drc --format json --exit-code-violations -o pcb/psu-v051-drc.json pcb/psu-layout-v051.kicad_pcb` → `py -3.13 tools/verify_pcb_v051.py` → `render_pcb_v051.py` → `git checkout -- pcb/DraftV03.pretty`（只保留新增的 `GBJ_Upright_P10_7.5_7.5.kicad_mod`）。**未做：** GBJ 實物核對、散熱片選定後的 3D、原理圖 BR 符號的封裝欄位（原理圖未重建，網路表不受影響）。

## PCB V0.5（機殼配合縮板，2026-09-29；電源板自 2026-10-01 起為歷史、放大板沿用）

> ⚠️ **工程草稿，不可送製。** 電路、零件、網路與 V0.4 完全相同；只改板形與零件位置。兩板 KiCad 10.0.6 **0 DRC 違規、0 未連通**，54＋50 焊盤網路與原理圖相符，放大板底層鋪銅單一連通區、0 過孔（[validation-v05.json](validation-v05.json)）。**2026-09-29 使用者看過預覽後選定，已併入 main 成為現行版本；** 3D／正反面／零件核對見 [inspection-v05](inspection-v05/README.md)。

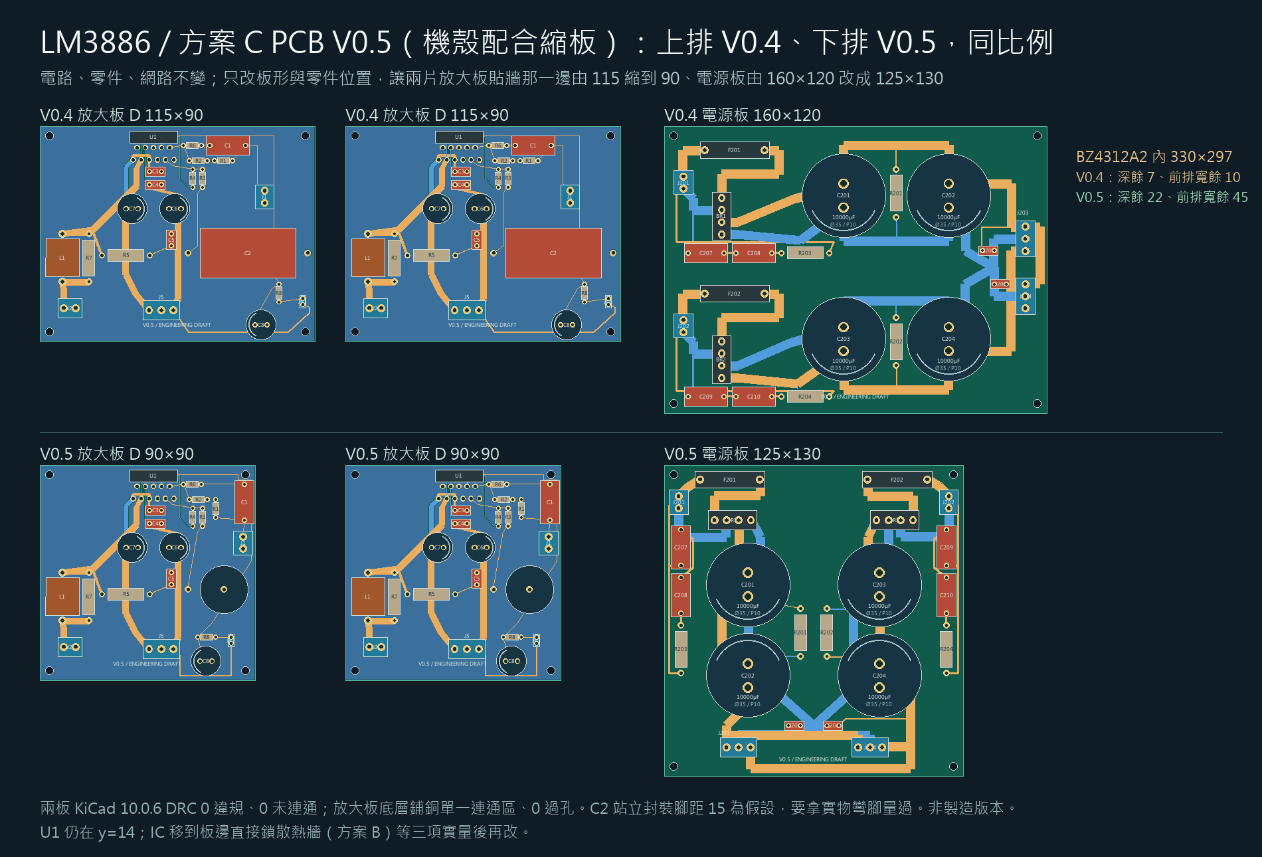
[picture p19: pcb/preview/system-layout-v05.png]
PCB V0.5 對照 V0.4


**為什麼要縮：** BZ4312A2 內 330×297 配置 A 下，放大板貼牆那一邊是 115 mm 那邊，直接吃深度：25（後板端子帶）＋115＋30＋120（變壓器）＝290，前面只剩 7 mm；前排變壓器 Ø120＋電源板 160 只剩 30 mm 空隙。三板分法本身沒錯（IC 一定貼側牆散熱器，重物一定在前排），要改的是兩塊板的形狀。對照圖 [docs/diagrams/chassis_bz4312a2_v05_fit.png](../docs/diagrams/chassis_bz4312a2_v05_fit.png)（`tools/draw_chassis_fit_v05.py`，板尺寸直接讀板檔 JSON）。

| 板 | V0.4 | V0.5 | 改了什麼 |
|---|---|---|---|
| 放大板 D | 115×90 | **90×90** | C2（ROE EGW 47µF）由躺式 `BP_Axial_L40_D20_P50` 改**站立** `BP_Axial_Vert_D20_P15`（pad 1 在本體正下方、pad 2 為反折腳，腳距 15 **是假設，要拿實物彎腳量**）；R1 改直立 (73.5,14.5)、C1 改沿右邊直立 (85.5,23)、J1 移到 C1 正下方 (85,30)，右上角固定孔才不會壓進 C1 保留區；靜音零件 R8／C8／JP1 搬到 C2 下方右下角，L_MUTE 沿上緣→穿過固定孔與 C1.2 之間→沿右邊 x=88.5 下行→穿過 C2 本體下方到 R8；靜音 VEE 沿下緣 y=88。IC 區（U1、C3、C4、C6、C7、J5）、輸出區（L1、R7、R5、C5、J2）與回授網路（R2–R4、R6）座標與 V0.4 相同 |
| 電源板 | 160×120 | **125×130** | 四顆 381LX 本來就是 2×2；160 寬是左邊 AC／橋堆端子區 50＋右邊輸出端子區 20 夾著電容。V0.5 把 AC 區（J201／F201／BR1 左、J202／F202／BR2 右，鏡射）搬到上緣，輸出區（STAR、C205／C206、J203／J204）搬到下緣；電容兩欄 x=35（正電容組）、x=90（負電容組），每欄下面那顆轉 90° 讓同網路焊盤相鄰、組內匯流線走本體下方直線，另一軌繞欄外側（VCC x=24 頂層、GND x=79 底層）；洩放電阻 R201／R202 站在兩欄之間 20 mm 空隙；snubber 預留位（每繞組 Cx、Cs＋Rs）直立貼左右邊；VCC 匯流頂層 y=113、GND 底層 y=113、VEE 繞外側 y=127 |

**機殼結果（配置 A，同樣假設：後板帶 25、排距 30、變壓器左右各 20）：** 深度餘裕 7 → **22** mm，前排寬餘 10 → **45** mm（validation-v05.json `chassis_fit_bz4312a2`）。

**沒改的：** U1 仍在 y=14。IC 移到板邊直接鎖散熱牆（使用者 2026-09-29 選的方案 B）等 docs/00 §3 第 2 條的三項實量後再改，屆時只動 U1／C3／C4 與相關中繼點，不影響這次的縮板。變體 C 不做 V0.5。

**DRC 三輪：** 第一輪放大板 1 錯（固定孔 H2 在 C1 保留區內）＋1 警告，電源板 2 錯（C205／C206 與大電容保留區重疊 0.5 mm）＋6 絲印警告；第二輪放大板 1 錯（R1 直立後與 R2 保留區重疊 0.15）、電源板 1 錯（VEE 4 mm 短樁頂到 y=114 的 VCC 匯流）；第三輪兩板 0 違規、0 未連通。

| 項目 | 檔案 |
|---|---|
| 放大板 D | [mono-layout-v05d.kicad_pcb](mono-layout-v05d.kicad_pcb)／[.kicad_pro](mono-layout-v05d.kicad_pro)／[走線＋鋪銅 JSON](mono-layout-v05d.json)／[封裝清單](mono-layout-v05d-footprints.csv)／[DRC](mono-v05d-drc.json)／[預覽](preview/mono-layout-v05d.png) |
| 電源板 | [psu-layout-v05.kicad_pcb](psu-layout-v05.kicad_pcb)／[.kicad_pro](psu-layout-v05.kicad_pro)／[JSON](psu-layout-v05.json)／[封裝清單](psu-layout-v05-footprints.csv)／[DRC](psu-v05-drc.json)／[預覽](preview/psu-layout-v05.png) |
| 生成器／驗證 | `tools/pcb_layout_v05.py`、`pcb_layout_v05_psu.py`、`build_pcb_v05.py`（沿用 V0.3 封裝庫與 `build()`、V0.4 `add_zones()`；新增 `BP_Axial_Vert_D20_P15`）、`verify_pcb_v05.py`、`render_pcb_v05.py`、`draw_chassis_fit_v05.py` |

重建：`kicad-cli sch export netlist` 兩份 → KiCad 內建 python 跑 `tools/build_pcb_v05.py` → `kicad-cli pcb drc --format json --exit-code-violations -o pcb/mono-v05d-drc.json pcb/mono-layout-v05d.kicad_pcb`（電源板同理）→ `py -3.13 tools/verify_pcb_v05.py` → `render_pcb_v05.py` → `git checkout -- pcb/DraftV03.pretty`。**未做：** current-budget 對照、導讀圖的 PCB 對應文字（仍寫 V0.4 座標描述，電路未變）。

## 審查結論（2026-09-17，以 V0.2 `d39b623` 為比較基準）

**改了什麼：** C3/C4 的高頻回地改在 IC 附近接至 U1.7，再由獨立局部去耦地線回匯流區，輸入／回授仍走自己的低電平支路；主輸出改走 B.Cu，R4 取樣仍由 U1.3 單獨走 F.Cu；放大板主電流段加寬（主幹 3.0 mm），電源板 AC／DC 主幹由 2.0／3.0 加寬至 4.0 mm；**移除正電源上的兩個換層導通孔**，剩下 3 孔只用於靜音與 Zobel 地線，不在主供電或喇叭電流路徑上；固定生成後的專案規則並加入 DRC 前後設定核對與檔案雜湊綁定。沒有改增益、元件值或電路網路。

| 量化結果 | V0.2 | V0.3 |
|---|---:|---:|
| C3 地端→U1.7 中心線路徑 | 102.94 mm | 24.15 mm |
| C4 地端→U1.7 中心線路徑 | 126.16 mm | 33.15 mm |
| C3→U1.1 電源線＋回地線總長 | 110.55 mm | 32.76 mm |
| C4→U1.4 電源線＋回地線總長 | 147.18 mm | 50.17 mm |
| U1.3→L1.1 走線電阻（1 oz／25°C） | 20.93 mΩ | 9.25 mΩ |
| 正電源 J5→U1.5 走線電阻 | 33.41 mΩ | 22.98 mΩ |
| 負電源 J5→U1.4 走線電阻 | 30.33 mΩ | 26.77 mΩ |

這些是**銅箔中心線的幾何與電阻指標**，不是完整換流迴路、電感或阻抗值，**不能換算成失真改善比例或不振盪保證**。計算條件：±30V、每聲道 40W／8Ω 正弦（40W 是走線尺寸計算點，不是額定）、每軌 85mA 靜態電流、`R = ρΣ(L/W)/t × [1+α(T−25)]`（ρ=17×10⁻⁶ Ω·mm，α=0.0039/°C）、名義 1 oz／2 oz 銅厚 0.0348／0.0696 mm，並以 25°C／85°C 作敏感度比較——**85°C 是輸入值，不是算出來的溫度**。孔壁、焊點、接頭、線材與元件電阻未併入。依據 [TI LM3886 datasheet pp.20–22](https://www.ti.com/lit/ds/symlink/lm3886.pdf) 與 [TI Analog Engineer's Pocket Reference](https://www.ti.com/seclit/eb/slyw038c/slyw038c.pdf)。

**整流充電只有情境、沒有預測。** 變壓器繞組電阻、漏感、空載電壓、橋壓降與電容 ESR 都未知，採矩形脈衝敏感度模型 `Ipeak=Idc/d`、`Irms=Idc/√d`：d=15% 時每軌平均 2.183A、RMS 5.637A、峰值 14.554A；d=35% 時 RMS 3.690A、峰值 6.238A。**這不是實測預測也不是保證上界**，到貨後波形可能超出。保險絲到橋的 50 mm AC 銅箔加寬到 4.0 mm 後，15% 情境下發熱由 0.388 降至 0.194 W，所以本輪優先加寬 AC 線而不只加寬 DC 輸出。

**本輪算的是發熱功率 W，不是溫升 °C**；實際溫升還取決於成品銅厚、板材、鄰近發熱零件、機殼溫度與通風。沒有使用 [IPC-2152](https://www.ipc.org/TOC/IPC-2152.pdf) 完整圖表，不宣稱符合該標準。

**規則重設問題的更正：** V0.2 生成器的 `SaveBoard` 會重建同名 `.kicad_pro` 把人工設定還原，已發布的 V0.2 實際是 Default 網路類別 0.2 mm，不是舊文字宣稱的 0.3 mm。V0.3 在所有 PCB 儲存後才寫入規則，`run_pcb_drc_v03.py` 於執行前後檢查 0.30 mm 間距、0.35 mm 線寬、0.50 mm 板邊距、0.20 mm 導通孔環寬、0.15 mm 絲印間距，並綁定 DRC／PCB／專案／走線 JSON 的 SHA-256。

**2026-09-19 絲印組裝標記（僅改封裝庫與生成器，板檔未重建）：** `DraftV03.pretty` 的 `CP_D12.5_P5`／`CP_D8_P3.5`／`CP_D35_P10` 加上「+」記號與負極粗條，`LM3886T_UNVERIFIED` 加上 pad 1 標記與「TAB = V- HEATSINK」字樣。幾何集中在 [tools/silk_marks_v03.py](../tools/silk_marks_v03.py)，重建時自動寫入；**兩份 `.kicad_pcb`、預覽圖與 DRC 雜湊未變**，要在 KiCad 環境跑完下方指令才會出現在板面。C8 極性依 mute 拓樸推定，到料後再核對。

**2026-09-24 橋堆裝法定案（方案 A）：** 使用者比較兩張預覽（A 鎖機殼＋4 位端子／B KBPC-W 焊板）後選 A。`Bridge_LOGICAL_UNVERIFIED` 移除，改 `BridgeTerminal4_P5.08`（焊盤編號沿用 AC1／AC2／P／N，原理圖不必改），BR1／BR2 位置 (24,30)／(24,90) 轉 270°，四條進出走線各加一個轉折點以避免 4 mm 寬線壓到相鄰端子。電源板重建後 DRC 0 違規、0 未連通。

**2026-09-23 依實量改（2026-09-24 已重建）：** ROE EGW 47µF 實量軸向 40×Ø20、腳徑約 0.8–1.0 → 新增 `BP_Axial_L40_D20_P50`（腳距 50、鑽孔 1.2、焊盤 2.6、外框 40×21），C2 躺式直放於 (70.5,80) 轉 90°，C2.2 在上方距 R3.1 約 10 mm、C2.1 在下方以 1.0 mm B.Cu 回 SG；放大板 100→**115×90**，R8／C8／JP1 右移至新增區（R8 100,48／C8 103,66 轉 180／JP1 110,52），R2 接地改繞 (76,26)(76,43) 避開 C2.2，靜音供電 VEE 改走 F.Cu 沿 y=76 避開 C2.1 接地線。`CP_D12.5_P5` 鑽孔 0.9→1.0（EKE、361R 腳徑 0.8）。**2026-09-24 KiCad 重建結果：** 首輪 DRC 抓到 C2 與 R1 零件保留區重疊（C2 由 x=72 移到 70.5 解決），以及 9/19 絲印那輪留下的兩個警告（U1「TAB」字高 0.7→0.8、U1 位號移到 (60,3) 不再壓字）；`verify_pcb_v03.py` 抓到 C2 訊號地與靜音回流在 (72,56) 相碰（同為 GND，DRC 不報，但違反「分路只在 STAR 匯合」），靜音回流改為 C8.1→F.Cu→`via_mute_ret` (62,71)→B.Cu→STAR。修正後兩板 0 違規、0 未連通、回地分組通過。走線寬度與訊號完整性仍只是工程假設。C2 本體下方有 F.Cu（L_MUTE、靜音回流）與 B.Cu 走線及 `via_mute_ret`；EGW 為絕緣套管軸向件，靠阻焊隔離，組裝時不要刮傷套管。

**2026-09-22 依型錄改封裝庫與生成器（板檔未重建，比照 9/19 絲印那輪）：** `LM3886T_UNVERIFIED` 鑽孔 0.9→1.1、焊盤 1.65→2.0（TI 腳寬 0.97）；`CP_D35_P10` 鑽孔 1.3→2.5、焊盤 3→4（snap-in 腳片 2.0×0.8，圓孔暫代槽孔，腳距 10 待到貨確認）；`pcb_layout_v03.py` C8 改 `CP_D12.5_P5`（CDE 361R EG 殼 Ø12.5×20、腳距 5.0；位置 74,63 不動，與 R8／JP1 淨空已按座標核過）。C2 `BP_D10_P5` 立式→臥式等 ROE EGW 實測。**兩份 `.kicad_pcb`、預覽圖、DRC 雜湊未變**；重建後 U1 焊盤變大，要重看 pin 間走線間距。預覽圖標題已改為「方案 C PCB V0.3（布局 B）」，B 只是布局代號，不是電路方案。

**2026-09-29 待改（IC 直接鎖機殼側牆，使用者決定）：** BZ4312A2 配置 A 下放大板長邊貼牆，U1 需由 (39,14) 移到離板邊約 2–3 mm（依實量「背板背面到腳距離」−1），C3/C4 與 `negative-pin`／`local-decoupling` 走線的中繼點同步上移；`LM3886T_UNVERIFIED` 外框改為不含背板以免邊緣間距 DRC；只改 D 板，C 不動。等 IC 三項實量（見 docs/00 §3 第 2 條）後執行。

**還不能定案，依序要核對：** ①LM3886T 實際腳距／彎腳／散熱片位置，再縮短負軌去耦與 470µF 回路（負電源近 IC 的 0.8 mm 段是目前最窄處）②變壓器 VA／繞組電流、整流橋與電容的實際料號與尺寸 ③板廠成品銅厚、孔壁最小鍍層、接頭與保險絲座額定 ④板外線束、機殼接地與整機保護 ⑤板級限流上電、假負載、示波器穩定性與熱量測。

## 重建

需要 KiCad 10 CLI、能匯入 `pcbnew` 的 Python、繪圖用 Pillow。位置與逐段走線定義在 `tools/pcb_layout_v03.py`。

```sh
kicad-cli sch export netlist --format kicadxml -o electrical/netlist.xml electrical/lm3886-v01.kicad_sch
kicad-cli sch export netlist --format kicadxml -o electrical/psu-netlist.xml electrical/internal-psu-v02.kicad_sch
python3 tools/build_pcb_v03.py
python3 tools/run_pcb_drc_v03.py --cli kicad-cli
python3 tools/verify_pcb_v03.py
python3 tools/analyze_pcb_v03.py
python3 tools/test_pcb_analysis_v03.py
python3 tools/render_pcb_v03.py
kicad-cli pcb export svg --layers F.Cu,B.Cu,F.SilkS,Edge.Cuts --mode-single --fit-page-to-board --exclude-drawing-sheet -o pcb/preview/mono-v03-native.svg pcb/mono-layout-v03.kicad_pcb
kicad-cli pcb export svg --layers F.Cu,B.Cu,F.SilkS,Edge.Cuts --mode-single --fit-page-to-board --exclude-drawing-sheet -o pcb/preview/psu-v03-native.svg pcb/psu-layout-v03.kicad_pcb
```

繪圖 Python 可與 KiCad Python 分開；非 macOS／Windows 以 `LM3886_FONT` 指向中文字型。**改過 PCB、規則或走線 JSON 後必須重跑原生 DRC，否則雜湊驗證會拒絕舊報告。**

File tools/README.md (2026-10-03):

# tools/ 腳本索引

更新：2026-10-01。腳本以 PCB 版號分家族（v03／v04／v05／v051），**現行是 V0.5.1**：放大板用 v05 家族建、電源板用 v051 家族建。舊家族保留，只為重現歷史板檔，不再修改。

原理圖側入口只有一支：

```sh
python3 tools/rebuild.py
```

`rebuild.py` 需要 KiCad 10 CLI 與 Poppler `pdftoppm`；它只重建**原理圖側**：畫兩份 KiCad 原理圖、跑 ERC、匯出 netlist／PDF／PNG、獨立核對網路，再重新產生 docs/02。任何驗證失敗即中止。**它不呼叫任何 pcb 腳本**；PCB、看圖資料、導讀圖、PDF 需另外手動執行。Windows 本機沒有 `pdftoppm`，照 rebuild.py 的步驟手動跑並用 PyMuPDF 轉 PNG（見 HANDOFF「環境注意」）。

## 原理圖與估算（由 rebuild.py 呼叫）

| 腳本 | 用途 |
|---|---|
| `build_schematic.py` | 產生放大板原理圖 `electrical/lm3886-v01.kicad_sch`（純標準庫） |
| `build_power_supply.py` | 產生次級電源原理圖 `electrical/internal-psu-v02.kicad_sch`；引用 build_schematic 的繪圖函式 |
| `build_control_board.py` | **2026-10-01 新增，rebuild.py 尚未呼叫**：產生控制／保護板 `electrical/control-v01.kicad_sch`（UPC1237、G2R-1-E ×2、光耦靜音、TL431 旁通計時、7812 輔助電源）與市電板 `electrical/mains-v01.kicad_sch`（NTC、K_BYP、K_TRIG）。手動跑 `kicad-cli sch erc／export pdf／export netlist`，PyMuPDF 轉 PNG 到 `electrical/preview/` |
| `verify_electrical.py` | 以獨立電路規格核對 KiCad 匯出的放大板 netlist |
| `verify_power_supply.py` | 電源板拓樸、極性與線束核對 |
| `power_budget.py` | 理想 B 類功率／散熱估算，輸出 docs/02 |
| `mains_budget.py` | 市電變動、空載電壓、紋波估算，**只印到 stdout**，人工更新 docs/05 估算段（docs/06 已於 2026-09-21 併入 docs/05）；引用 power_budget。**前提仍是「22 V＋8% 調整率」，尚未改成 2026-10-01 實測值** |
| `control_budget.py` | 控制板估算：湧流／軟啟動、繼電器 DC 分斷、掉電時序、12 Vac 輔助電源、靜音、Z10 trigger；輸出 docs/14 §6（不由 rebuild.py 呼叫，手動執行） |

## PCB 現行 V0.5.1（需 KiCad Python 環境）

每個版本家族都是同一組角色：**layout（資料檔）→ build → DRC → verify → render**，再加六支 inspection 腳本。V0.5.1 只重畫電源板，放大板沿用 V0.5。

| 腳本 | 用途 |
|---|---|
| `pcb_layout_v05.py` | 放大板 D 90×90 位置與走線定義（**現行放大板**；底層整面接地） |
| `pcb_layout_v05_psu.py` | 電源板 V0.5 125×130 定義（歷史；v051 由它衍生） |
| `pcb_layout_v051_psu.py` | 電源板 V0.5.1 定義：V0.5 只覆寫 BR1／BR2 改 GBJ2510 直立上板與相關七條走線（**現行電源板**） |
| `build_pcb_v05.py` | 一次建放大板 D＋電源板 V0.5（沿用 v03 的 `build()` 與 v04 的 `add_zones()`；新增封裝 `BP_Axial_Vert_D20_P15`） |
| `build_pcb_v051.py` | 只建電源板 V0.5.1；新增封裝 `GBJ_Upright_P10_7.5_7.5`（`make_fp_oval` 長孔） |
| `verify_pcb_v05.py` | DRC 0、焊盤網路對照、放大板鋪銅單一連通區 → `pcb/validation-v05.json` |
| `verify_pcb_v051.py` | 同上（電源板）＋ GBJ 本體與 10 mm 散熱片包絡不撞件 → `pcb/validation-v051.json` |
| `render_pcb_v05.py` | 由 JSON 畫 `pcb/preview/*-v05*.png` 與 `system-layout-v05.png` |
| `render_pcb_v051.py` | 畫 `psu-layout-v051.png` 與 V0.5／V0.5.1 並排對照圖 |
| `build_pcb_inspection_v051.py` → `export_` → `frame_` → `render_` → `write_pcb_parts_audit_v051.py` → `verify_pcb_inspection_v051.py` | 看圖資料 `pcb/inspection-v051/`：導讀 SVG、暫定 VRML、預覽板、kicad-cli 分層與 3D 匯出、加註假設框、SVG→PNG（PyMuPDF）、零件核對表、來源綁定核對。中間產物（`3d/models/`、`*-preview.*`、`raw-*.png`）不入版控 |

DRC 不再有專用腳本（v03 的 `run_pcb_drc_v03.py` 之後直接用 `kicad-cli pcb drc`），完整指令順序見 HANDOFF「V0.5.1 重建流程」。

## PCB V0.6.1（放大板／電源板現行，2026-10-03 併入 main）

| 腳本 | 用途 |
|---|---|
| `pcb_layout_v061.py` | 匯入 `pcb_layout_v06` 的 AMP_V06／PSU_V06，依 (網路, 群組, 原寬) 表與逐條覆寫改走線寬度、替換輸出主幹兩個轉折點與三條進端子走線；檔頭列出每項寬度的限制來源。零件位置不動 |
| `build_pcb_v061.py`／`verify_pcb_v061.py`／`render_pcb_v061.py` | 由 v06 三支 sed 衍生（板名 v061、`validation-v061.json`、`preview/*-v061.png`；系統圖的 CTRL／MAINS 仍讀 v06） |
| `analyze_pcb_v061.py` | 載流路徑銅箔電阻對照 V0.6 vs V0.6.1（重用 `analyze_pcb_v03` 的 path／resistance／coupling_screen；1 oz／2 oz、25／85 °C 敏感度）→ `pcb/current-budget-v061.json`，並印出 pcb/README 用的 Markdown 表 |

流程同 V0.6（netlist → KiCad python `build_pcb_v061.py` → DRC 兩板 → `verify_pcb_v061.py` → `render_pcb_v061.py` → `analyze_pcb_v061.py`），跑完 `git checkout -- pcb/DraftV03.pretty`。

## PCB V0.6（現行五板，2026-10-01 深夜～10-02 凌晨；需 KiCad Python 環境與 `py -3.13`）

| 腳本 | 用途 |
|---|---|
| `pcb_layout_v06.py` | 放大板 90×80（U1 用函式庫 TO-220-11，背板貼板邊 y=0）與電源板 92×120 的位置與走線定義；檔頭列出與 V0.5／V0.5.1 的差異 |
| `build_pcb_v06.py` | 一次建放大板＋電源板；借 `build_pcb_v06_ctrl.import_std` 複製 TO-220-11 封裝成 `LM3886T_TO220-11`（3D 模型保留），GBJ 封裝來自 `build_pcb_v051` |
| `verify_pcb_v06.py` | DRC 0 錯誤、焊盤網路對照、焊盤在板內、放大板鋪銅單一連通區、U1 背板在板邊、GBJ 本體與 10 mm 散熱片包絡（+y 側）不撞件、列出未上板的 snubber 零件 → `pcb/validation-v06.json` |
| `render_pcb_v06.py` | `pcb/preview/mono-layout-v06.png`、`psu-layout-v06.png`、五板同比例 `system-layout-v06.png` |
| `pcb_layout_v06_ctrl.py` | CTRL 70×120 與 MAINS 70×100 的位置與走線定義（檔頭有樓層圖；CTRL 底層 GND 鋪銅、+12V 走底層 x=50 兩個過孔；MAINS 市電側 x≥32、低壓側 x≤24） |
| `build_pcb_v06_ctrl.py` | 一次建兩板。`import_std()` 把 KiCad 函式庫封裝（G2RL-1-E、SIP-8、DIP-4、TO-92 wide、TO-220、DO-41、DO-35）複製進 `pcb/DraftV03.pretty` 並把焊盤編號改成原理圖腳名；另做 `NTC_D22_P10`、`CP_D5_P2`、`CP_D6.3_P2.5` 暫定外框。跑完 `git checkout -- pcb/DraftV03.pretty` 只還原既有檔（新封裝檔要保留） |
| `verify_pcb_v06_ctrl.py` | DRC 0 錯誤、焊盤網路對照、焊盤在板內、CTRL 鋪銅單一連通區、**MAINS 市電網路與低壓網路銅箔最小距離 ≥6.4 mm** → `pcb/validation-v06-ctrl.json` |
| `render_pcb_v06_ctrl.py` | 畫 `pcb/preview/ctrl-mains-layout-v06.png`（兩板並排，頂視） |
| `draw_chassis_scene_v06.py` | 弘宙 102 機箱內部 3D（pyvista／VTK 離屏算圖）：吃 `kicad-cli pcb export stl --subst-models --include-pads` 匯出的五塊板 STL（`place_board(name, origin, rot)` 以純旋轉放進機殼，右聲道放大板＝左板轉 180°），沒有模型的零件照板檔 JSON 補方塊／圓柱；散熱器、變壓器為估算尺寸 → `docs/diagrams/chassis_102_v06_3d.png`（另輸出 .gltf 給 Blender，不入版控） |

流程：`kicad-cli sch export netlist`（四份原理圖）→ KiCad python `build_pcb_v06.py`、`build_pcb_v06_ctrl.py` → `kicad-cli pcb drc --format json --severity-all --exit-code-violations`（四板）→ `py -3.13 verify_pcb_v06.py`、`verify_pcb_v06_ctrl.py` → `render_pcb_v06.py`、`render_pcb_v06_ctrl.py` → `kicad-cli pcb export stl` ×4 → `draw_chassis_scene_v06.py <stl 目錄>`。跑完 `git checkout -- pcb/DraftV03.pretty` 還原既有封裝的 UUID（新封裝檔保留）。

## 歷史家族（保留，不再改）

| 家族 | 板 | 腳本 |
|---|---|---|
| **v03**（2026-09-17～24） | 放大板 115×90＋電源板 160×120 | `pcb_layout_v03.py`、`build_pcb_v03.py`（其他版本的 `build()` 都來自這支）、`run_pcb_drc_v03.py`（雜湊綁定 DRC）、`verify_pcb_v03.py`、`render_pcb_v03.py`（其他版本的畫圖函式來源）、`silk_marks_v03.py`（封裝極性絲印）、`analyze_pcb_v03.py`＋`test_pcb_analysis_v03.py`（載流對照 V0.2→V0.3，讀 `pcb/archive/v02/*.json`，**之後版本沒再做**）、`*_inspection_v03.py` 五支＋`render_pcb_inspection_v03.cjs`（需 sharp） |
| **v04**（2026-09-24） | 放大板 C（星型改良）／D（整面接地）115×90＋電源板 160×120 | `pcb_layout_v04.py`（含 AMP_C／AMP_D）、`pcb_layout_v04_psu.py`、`build_pcb_v04.py`（一次建三板；`add_zones()` 鋪銅）、`verify_pcb_v04.py`、`render_pcb_v04.py`、`*_inspection_v04.py` 六支（SVG→PNG 改用 PyMuPDF） |
| **v05**（2026-09-29） | 放大板 D 90×90（現行）＋電源板 125×130（歷史） | 見上表 |

## 機殼、導讀圖與 PDF

| 腳本 | 用途 |
|---|---|
| `draw_chassis_fit_v05.py` | BZ4312A2 俯視配置 A，左 V0.4／右 V0.5 三板，板尺寸讀 `pcb/*.json` → `docs/diagrams/chassis_bz4312a2_v05_fit.png` |
| `draw_chassis_iso.py` | BZ4312A2 內部等角立體示意（配置 A）→ `chassis_bz4312a2_3d.png`（PIL） |
| `build_diagram_full_v04.py` | 單聲道完整接線圖 `docs/diagrams/svg/lm3886_full_v04.svg`（每條線畫出、無網路標籤；電路到 V0.5.1 未變，仍適用） |
| `build_diagrams.py` | 其餘五張導讀 SVG（色塊圖需 PyMuPDF 讀 KiCad PDF） |
| `render_diagrams.py` | SVG→PNG（PyMuPDF，Windows 用這支） |
| `render_diagrams.cjs` | SVG→PNG（Node＋sharp；mac 用） |
| `build_project_pdf.py` | 產生 `output/pdf/*.pdf`（需 reportlab、pypdf、CJK 字型；非 Windows 設 `LM3886_FONT`）。`output/` 不入版控 |

## 已刪除的歷史腳本

V0.1（`*_draft.py`）與 V0.2（`*_v02.py`）腳本已於 2026-09-21 刪除，需要時從 Git 歷史（`41b217c`）取回。`pcb/archive/v02/mono-layout-v02.json`、`psu-layout-v02.json` **刻意保留**，因為 `analyze_pcb_v03.py` 要讀它們做對照。

**檔名裡的 v01／v02 是 PCB 版號；`electrical/` 的 lm3886-v01、internal-psu-v02 是現行原理圖，別混淆。**

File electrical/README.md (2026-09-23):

# V0.3 放大板與內建電源次級圖

> 2026-09-16：本目錄兩份圖面、PDF／PNG 與計算已更新成 V0.3 C 方案；檔名保留以維持連結。12Vac 控制／一次側仍待設計，電氣檢查結果見 validation.md。
>
> 2026-09-24：本目錄的 `.kicad_sch`、PDF、PNG、BOM 已以 KiCad 10.0.6 重建，帶入實購規格（C1／C3／C4／C8 100V、R8 0.6W）；ERC 0 違規，netlist 獨立核對通過。

原理圖預覽

[下載 PDF](preview/lm3886-v01.pdf)。以 KiCad 10 開啟 [lm3886-v01.kicad_pro](lm3886-v01.kicad_pro)，即可編輯原理圖；自有符號庫已隨附。未指派 footprint，尚無 PCB。

放大板檔名保留 `lm3886-v01` 以維持既有連結，圖框版本已更新為 V0.3。J5 現在表示機內電源線束，日常使用由內建電源供電，訊號由現有前級送入。

內建電源次級整流濾波草案

[電源 PDF](preview/internal-psu-v02.pdf) · [電源 KiCad 專案](internal-psu-v02.kicad_pro) · [電源 BOM](psu-bom-draft.csv)。這份圖只畫變壓器隔離次級之後的整流、濾波與洩放，市電一次側及軟啟動仍在[整機規劃](../docs/05-內建電源與機構.md)階段。

電源 J203 的 1／2／3 與放大板 J5 的 1／2／3 用線束相接。兩份圖是獨立 KiCad 專案，不靠同名網路自動跨檔連線。橋式整流符號的 AC1／AC2／P／N 是功能端子，選實體料件後再對應腳位。

左右各一套相同電路，RCA／電源／靜音間相同的網路名稱表示電氣相接。IC 1、5 兩腳共用正電源符號位置，2、6、11 是隱藏的 NC 腳；匯出 netlist 會分別核對。

本版 C2／C102 為無極性回授電容；C6／C106 負軌電解及 C8／C108 靜音電解的正端接 GND。輸出標記 TEST OUT，供假負載使用。

在專案根目錄執行 `python3 tools/rebuild.py` 會重建兩份原理圖、ERC、netlist、BOM、PDF、PNG、功率／市電報告與驗證紀錄。生成器會覆寫原理圖；手動修改後需先同步修改生成器，或明確改成以 KiCad 手動檔為主，避免覆蓋人工編輯。

[BOM](bom-draft.csv) · [驗證紀錄](validation.md) · [中文設計說明](../docs/01-設計規格.md)

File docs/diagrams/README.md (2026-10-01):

# 方案 C 電路導讀圖

更新：2026-10-01 補註——本頁六張圖畫的是**電路**（元件與接線），V0.4→V0.5→V0.5.1 只改板形、零件位置與整流橋封裝，電路與元件編號沒變，所以圖仍適用於現行 V0.5.1；唯一差異是整流橋 BR1／BR2 現在在電源板上，接線圖裡「橋堆→板上端子」那段線束已不存在。機殼配置圖另見 `chassis_bz4312a2_*.png`（`tools/draw_chassis_iso.py`、`draw_chassis_fit_v05.py`）。

2026-09-24。新增**單聲道完整接線圖**（每條線都畫出、沒有網路標籤、元件編號＝板上絲印），取代舊的「完整電路總覽」；其餘四張向量圖與兩張色塊圖重建，底圖改用 2026-09-24 匯出的 KiCad PDF（電源圖含 J204 與 snubber 預留位）。舊總覽移到 [archive-v03/](archive-v03/)。沒有新增硬體量測或重跑 ERC／DRC。

| 圖片 | 內容 |
|---|---|
| [單聲道完整接線圖](lm3886_full_v04.png) | 放大板 D（22 件）＋共用電源板（22 件）全部畫出；電源、去耦、靜音、回授、Zobel、線束都在同一張 |
| [輸入級與回授](lm3886_input_stage.png) | R1/C1/R6/R2、R4 回授與串聯 R3/C2 |
| [IC → 輸出級](lm3886_ic_to_output.png) | Zobel、L1∥R7、假負載及回授取樣點 |
| [電源級 → IC](lm3886_power_to_ic.png) | 雙橋四電容、極性、線束、去耦與靜音 |
| [放大板色塊導讀](lm3886_sch_annotated.png) | 現行雙聲道 KiCad 原理圖的向量底圖與功能分區 |
| [電源板色塊導讀](lm3886_psu_sch_annotated.png) | 現行次級 KiCad 原理圖（含 J204、snubber 預留）的向量底圖與功能分區 |

單聲道完整接線圖

## 為什麼要另畫一張接線圖

KiCad 原理圖（`electrical/*.kicad_sch`）電氣上是完整的，PCB 就是從它匯出的網路表建的；但它用 VCC／GND／VEE／L_MUTE 等**網路標籤**代替實際畫線，去耦電容、靜音電路、C2 都孤立擺在旁邊，看起來像沒接。接線圖把這些線全部畫出來，並標出哪些零件在放大板、哪些在電源板、線束怎麼接。**元件值以 KiCad 原理圖為準**；接線圖是導讀，不是走線圖，所有接地符號在板上是同一個 GND 網路（變體 D 以底層鋪銅相連、變體 C 各自拉線回 STAR）。

## 與 V0.3 導讀圖不同之處

- 電源板加了 J204（右聲道端子）與每繞組的 snubber 預留位（Cx‖(Rs+Cs)，只留孔不填料）。
- 整流橋定案 KBPC2510 鎖機殼，板上是 4 位端子，四條 Faston 線接入。
- PCB 對應文字改為 V0.4：C3 跨 pin 5–7、C4 跨 pin 4–7 貼 IC 腳；變體 D 底層整面接地、主輸出走頂層。
- 採購狀態改為 9/22 到貨後的現況；電路、元件值與網路沿用 V0.3 未改。

## 來源與核對

電路以 [放大板](../../electrical/lm3886-v01.kicad_sch)、[次級電源](../../electrical/internal-psu-v02.kicad_sch) 及各自生成器為準。色塊底圖直接從 `electrical/preview/` 的向量 PDF 轉出，沒有重新猜畫原理圖。接線圖依原理圖網路表與 [PCB V0.4](../../pcb/README.md) 的元件編號手繪，逐一核對 54＋50 個焊盤網路（見 [pcb/inspection-v04](../../pcb/inspection-v04/drawings/)）。這是文件同步，不代表新的電氣驗證或製造核准。

## 重建

可編輯原稿位於 [svg/](svg/)，SHA-256 來源清單在 [sources.json](sources.json)（綁四個生成器與兩份 PDF，不綁 `.kicad_sch`）。需要 Python 3 與 PyMuPDF；PNG 轉檔改用 `render_diagrams.py`（PyMuPDF），不再需要 Node.js／sharp（`render_diagrams.cjs` 保留可用）。中文字型預設 Microsoft JhengHei，其他平台需 Noto Sans CJK TC。

```sh
py -3.13 -X utf8 tools/build_diagrams.py          # 五張導讀圖 SVG + sources.json
py -3.13 -X utf8 tools/build_diagram_full_v04.py  # 單聲道完整接線圖 SVG + PNG
py -3.13 -X utf8 tools/render_diagrams.py         # 全部 SVG -> PNG
```

若改動電路，先依專案流程重建 KiCad 原理圖、netlist、PDF 與電氣檢查，再同步兩支生成器的導讀內容，重建並逐張檢視。色塊圖的彩色框座標是依當前 PDF 版面手調的，PDF 版面變動後要重新對位。

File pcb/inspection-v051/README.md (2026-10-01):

# PCB V0.5.1：正反面、組裝、3D 與零件核對

2026-10-01，依 `v051-psu-gbj` `456e574` 的 PCB V0.5.1 製作：**放大板變體 D**（與 V0.5 完全相同的 `mono-layout-v05d` 板檔，圖面重出以便整套對齊）與**電源板 V0.5.1**（整流橋 BR1／BR2 由機殼上的 KBPC2510＋4 位端子改為 **GBJ2510 直立裝在板上**，新封裝 `GBJ_Upright_P10_7.5_7.5`；其他零件、走線與 125×130 板形同 V0.5）。做法、限制與 [V0.5 那套](../inspection-v05/README.md) 相同；**沒有改變原理圖、PCB 走線、元件值或採購狀態**。這是一套工程審查資料，尚不可送廠。

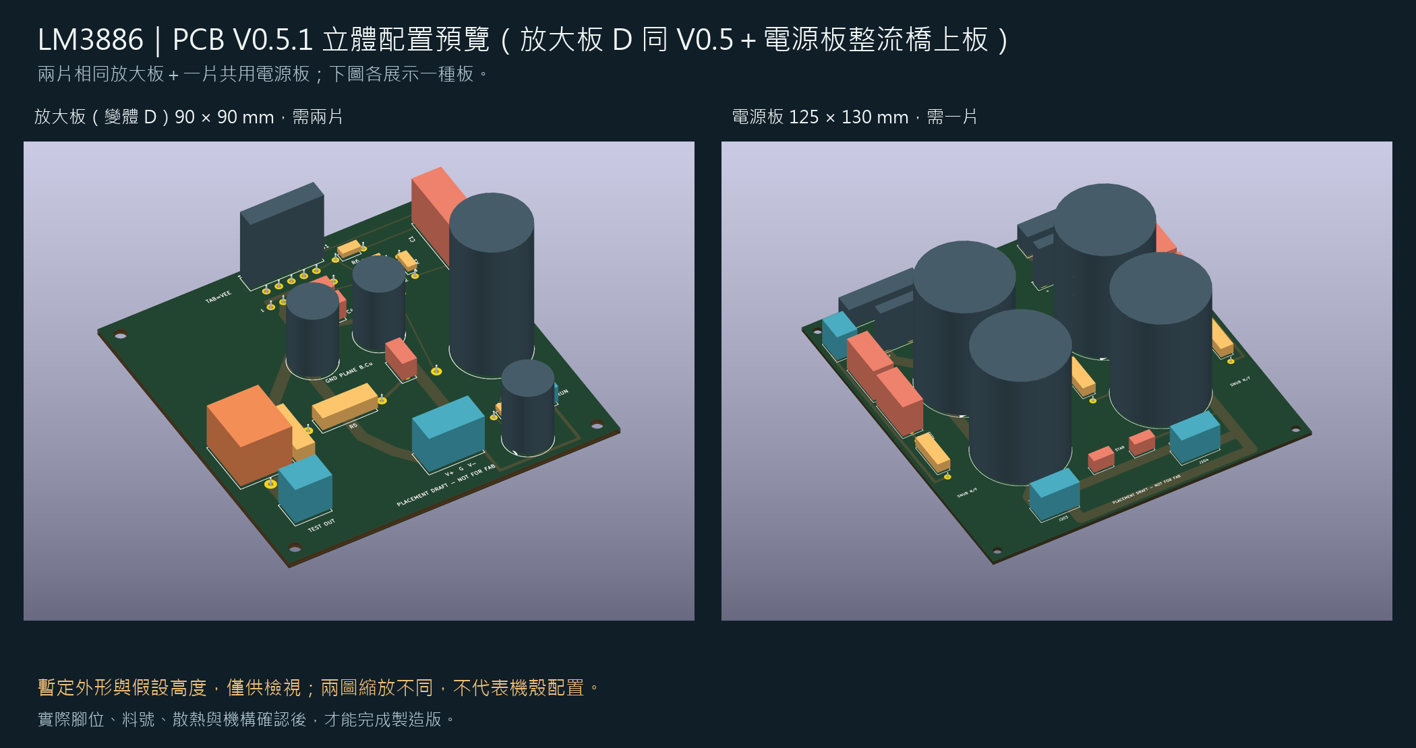
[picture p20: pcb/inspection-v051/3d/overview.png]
PCB 立體預覽


## A：正反面與組裝圖

兩片單聲道板完全相同，因此提供一套放大板圖與一套電源板圖。

| 圖面 | 單聲道板（D）×2 | 電源板 ×1 |
|---|---|---|
| 正面銅箔 F.Cu | [PNG](drawings/mono-top.png)／[SVG](drawings/mono-top.svg) | [PNG](drawings/psu-top.png)／[SVG](drawings/psu-top.svg) |
| 背面銅箔 B.Cu | [PNG](drawings/mono-bottom.png)／[SVG](drawings/mono-bottom.svg) | [PNG](drawings/psu-bottom.png)／[SVG](drawings/psu-bottom.svg) |
| 正面組裝／極性圖 | [PNG](drawings/mono-assembly.png)／[SVG](drawings/mono-assembly.svg) | [PNG](drawings/psu-assembly.png)／[SVG](drawings/psu-assembly.svg) |
| 值、接頭用途、逐腳網路 | [對照表](drawings/mono-assembly-notes.md) | [對照表](drawings/psu-assembly-notes.md) |
| KiCad 原生銅箔匯出 | [正面](native/mono-top.svg)／[背面](native/mono-bottom.svg) | [正面](native/psu-top.svg)／[背面](native/psu-bottom.svg) |

**觀看方向：**正面圖從元件側看；背面銅箔圖相對正面左右鏡像，等於沿垂直軸把板子翻過來。背面圖中的元件編號只是對位註解，不表示元件裝在背面。原生背面 SVG 同樣使用 KiCad `--mirror`。沒有提供製板底片或保證 1:1 列印的加工圖。

**放大板 D 的背面圖**：暗藍色整面是 GND 鋪銅（KiCad 填銅結果，單一連通區），焊盤周圍的深色環是熱阻隔間隙；淺藍線是底層非接地走線（C7→pin 1 的 V+、pin 4 的 V- 進腳、回授取樣線），它們把鋪銅切出的縫就是圖上看到的深色細線。電源板沒有鋪銅，背面仍是 4 mm 接地與交流走線。

組裝圖的 `1 +`／`2 -` 表示有極性電解的正負焊盤。C2 是無極性電容，不加正負標記。C6、C8、C203／C204 的**正端在 GND**，不能把所有 GND 一律當成電容負端。BR1／BR2 是 GBJ2510 直立整流橋：焊盤 P＝＋、N＝－、AC1／AC2＝～（原廠腳序 ＋ ～ ～ －），**印字面朝電容、金屬背面朝板邊**（板上絲印粗線那側，裝散熱片）；3D 模型只是 30×4×20 的方塊，沒有畫出固定孔與散熱片。C207–C210、R203／R204 是 snubber 預留位，**只留孔不填料**，值等變壓器實測振鈴再定。

左右聲道實體板都使用 U1、R1、C1 等同一套絲印；右聲道對應 U2、R101、C101 等原理圖編號，見 [原理圖對照](../mono-channel-mapping.csv)。

## B：PCB 3D 預覽

| 角度 | 單聲道板（D） | 電源板 |
|---|---|---|
| 斜視 | [PNG](3d/mono-isometric.png) | [PNG](3d/psu-isometric.png) |
| 正面 | [PNG](3d/mono-top.png) | [PNG](3d/psu-top.png) |
| 背面 | [PNG](3d/mono-bottom.png) | [PNG](3d/psu-bottom.png) |

**可旋轉的 KiCad 預覽板不入版控。** 先執行 `python3 tools/build_pcb_inspection_v051.py`（純 Python 標準庫，不需 KiCad），它會產生 `3d/models/*.wrl` 與 `3d/*-preview.kicad_pcb/.kicad_pro`；再用 KiCad 開啟 preview 專案，「檢視 → 3D 檢視器」即可旋轉縮放。模型以 `${KIPRJMOD}/models/…` 相對路徑連結，`models/` 要留在 preview 板旁邊。

原 PCB 沒有修改；另產生的 preview 板只新增 3D 模型引用。外框高度沿用 V0.3 的假設值表（2026-09-22 已把 WIMA、LM3886T、CDE A05 改成型錄值，其餘仍是假設），詳見核對表；不是原廠 CAD，也不是保證能容納實物的最大外框。模型沒有表達 IC 真正彎腳及背板、電感繞線、接頭插線口、螺絲工具空間、保險絲夾、散熱器或焊錫。板厚 1.6 mm 及四角固定孔仍是設計假設。3D 圖有助於討論配置，但不能據此宣稱無干涉或散熱合格。沒有 STEP、Gerber 或鑽孔製造包。

原生算繪的未加框 PNG（`3d/raw-*.png`）是 `export_pcb_inspection_v051.py` 的中間產物，**不入版控**；上表是加了假設說明框的版本。

## C：零件與封裝核對

[完整核對表](parts-audit.md) 按板上編號列出元件值、暫定外形、假設高度、腳距、孔徑、採購狀態與選料優先順序。[JSON](parts-audit.json) 另含每個焊盤的本地座標與網路。**採購狀態欄的文字沿用 2026-09-22 的版本**，之後的量測與到貨以 [docs/00](../../docs/00-採購總表.md) 為準；V0.5.1 的 BR1／BR2 改為「待購 GBJ2510＋散熱片＋M3」；散熱片選法見 docs/00 §2.1。

## 檢查與來源

- [來源 SHA-256](sources.json)：`mono-layout-v05d`／`psu-layout-v051` 的 PCB、專案與走線 JSON。
- [本輪核對結果](verification.json)：preview 板刪除模型節點後與原板語法樹一致；22＋22 個模型、外框尺寸與 54＋50 焊盤位置／網路對照通過。雜湊表**不含**可重建中間產物（models／preview 板／raw PNG），跑 `verify_pcb_inspection_v051.py` 前要先重建它們。
- [KiCad 匯出紀錄](native-export-log.json)：四份原生銅箔 SVG 與六張 3D 算繪。
- 既有 PCB V0.5.1 的 DRC／網路驗證見 [上層說明](../README.md)。本輪沒有改走線，沒有新增 ERC／DRC 或實機測試；不把 3D 顯示當作電氣驗證。

## 重建

依序執行（Python 3、KiCad 10 CLI；PNG 需 PyMuPDF 與 Pillow，不再需要 node／sharp）：

```sh
python3 tools/build_pcb_inspection_v051.py
python3 tools/write_pcb_parts_audit_v051.py
python3 tools/render_pcb_inspection_v051.py
python3 tools/export_pcb_inspection_v051.py --cli kicad-cli
python3 tools/frame_pcb_inspection_v051.py
# 使用能匯入 pcbnew 的 KiCad Python：
python3 tools/verify_pcb_inspection_v051.py
```

中文圖片字型：macOS 用 STHeiti，Windows 預設微軟正黑體（`msjh.ttc`），或以 `LM3886_FONT` 指定字型檔。若電路或封裝改動，需先依主專案流程重建與檢查，再重製本套圖面；不得把本資料夾的 preview 板當成後續電路來源。

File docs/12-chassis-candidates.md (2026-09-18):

# 12 機殼候選（淘寶，2026-09-18 查）

**本文件是選型調查，不是採購決定。所有尺寸為賣場標題標示的外部尺寸，未向賣家確認內部可用空間，未核對散熱熱阻，未下單。** 台幣為淘寶頁面自帶換算，**不含運費與集運**。

## 1. 需求推導

依 V0.3 C 方案現有文件：

| 項目 | 尺寸／需求 | 來源 |
|---|---|---|
| 環形變壓器 | Ø120 × H43 mm、約 2.4kg | [09 採購後修訂計畫](09-purchased-plan.md)，賣場宣稱 |
| 電源板 | 160 × 120 mm | [README](../README.md) PCB V0.3 |
| 放大板 | 100 × 90 mm × 2 片 | 同上 |
| 主濾波電容 | 10,000µF／63V × 4，**料號未選** | [08 採購狀態](08-procurement.md) |
| 散熱 | 每聲道 ≤0.4 °C/W、介面 ≤0.3 °C/W，每聲道耗散約 20–23W | [05 內建電源與機構規劃](05-internal-power.md)、[02 功率與散熱估算](02-calculations.md) |
| 絕緣 | **LM3886T 背板為 VEE**，鎖上接地機殼必須用絕緣介面與螺絲絕緣套 | [01 設計規格](01-design.md) |

推得最低內部空間：

- **寬 ≥ 300 mm** — 環牛（含固定盤約 140）＋電源板 160 並排
- **深 ≥ 250 mm** — 環牛 120 ＋電源板 120／160 前後排列，另需線束空間
- **高 ≥ 90 mm** — 被主電容卡住：Ø35 × 50 mm snap-in 加腳座約需 70 mm；若選牛角式（如 CDE 381LX）需 110 mm 以上

**高度需求會隨主電容選型改變。電容料號未定前，機殼高度不應定案。**

另需容納：市電入口／開關／保險絲、浪湧限制、喇叭 DC 保護板、PE 機殼接地點。

## 2. 首選

### ¥408（約 NT$1,960）4312A 兩側散熱全鋁功放機箱 430 × 120 × 311 mm

<https://www.taobao.com/list/item/V0lLOFBGSFJKTXZKS0Nrc0txaW9FQT09.htm>

唯一三圍全部標示、且兩側帶散熱的候選。430 寬容得下環牛與電源板並排，311 深可容環牛（120）＋電源板（160）前後排列，120 高即使改用牛角電容也有餘裕。評分 5.0。

## 3. 次選

### ¥315（約 NT$1,513）全銀色兩側散熱全鋁機箱 360 × 120 × 275 mm

<https://www.taobao.com/list/item/aG5UZU02OTVHVmZRTGx4TTF5anJRZz09.htm>

比首選便宜約 NT$450，仍在需求之上。深 275 放環牛加電源板較擠，走線與一次側元件空間變少。評分 5.0。

### ¥338（約 NT$1,623）3212 兩側散熱小甲機箱

<https://www.taobao.com/list/item/V3J3K3Fud2RZK1Z3TWJkTzQrMDF2dz09.htm>

型號推測為 320 寬 × 120 高，**深度未標示，需向賣家確認**。評分 5.0。

## 4. 替代路線：素機箱 ＋ 另購散熱鋁擠

總價可壓到約 ¥270（NT$1,300）以下，但**需自行加工開孔、對位，並處理散熱片與機箱的機械與熱介面**。

素機箱：

- ¥198（NT$951）3690 全鋁 360 × 90 — <https://www.taobao.com/list/item/dXJmQnllY3NvNVpSY2h6QU1iblZjdz09.htm>
- ¥178（NT$855）3290 全鋁 320 × 92 — <https://www.taobao.com/list/item/T3N6WjAvQjNBbGcvT0RkR3ZNMDFydz09.htm>

散熱鋁擠：

- ¥59（NT$283）寬 300 × 高 85 mm — <https://www.taobao.com/list/item/WEZZV29JZnRSWTVQRGxQNmlvRHNxZz09.htm>
- ¥75（NT$360）寬 350 × 高 80 mm 高倍齒 — <https://www.taobao.com/list/item/M1RITFJBWWQ2WlBMVHJhZmkwVkpvZz09.htm>
- ¥105（NT$504）寬 300／400 × 高 50 mm — <https://www.taobao.com/list/item/KzlOOUJuaGEvWGVrZHRwc3RuWFBFUT09.htm>

## 5. 已排除

| 商品 | 價格 | 排除理由 |
|---|---|---|
| [1560 機箱 151 × 60，標題寫「適合安裝 LM3886/LM1875」](https://www.taobao.com/list/item/elpFWWwrLzdLejVLczFZNncvZXE3UT09.htm) | ¥85 | **標題有 LM3886 但尺寸不可能**。環牛直徑就 120 mm |
| [BRZHiFi BZ3207S 單側散熱](https://www.taobao.com/list/item/TUtXRjhBN3dENy9jU1E1VkVpZmprdz09.htm) | ¥198 | 型號推測高度僅 70 mm，主電容立不起來；且僅單側散熱 |
| [BRZHiFi 2107 兩側散熱](https://www.taobao.com/list/item/YU4yb1hKN2ZDL2RzVTdORHJwWnJJZz09.htm) | ¥155 | 型號推測 210 × 70 mm，過小 |
| [430 × 200 純後級大功率散熱機箱](https://www.taobao.com/list/item/Y2xqTU1NSStvMitVeGFiRFg2eTA1dz09.htm) | ¥780 | 高度 200 mm 對本機過剩，價格近首選兩倍 |
| LM833+LM3886 / 5532+LM3886 功放機 | ¥989–998 | **是整機成品，不是機殼**。搜尋結果混入 |

## 6. 下單前必須確認

1. **散熱熱阻**：所有候選都只標尺寸，**沒有任何一個標 °C/W**。需求是每聲道 ≤0.4 °C/W，必須自行按鰭片面積估算或到料實測
2. **內部可用空間**：標示為外部尺寸，扣除側板與散熱片基座厚度後的淨空間未知
3. **型號推測的尺寸**：3212、2107、3207 的長寬高是依命名慣例推的，**不是賣家標示**
4. **主電容選型先於機殼**：高度需求由電容決定，見 [10 預計下單清單](10-planned-parts.md)
5. **變壓器到貨核對**：實際直徑、高度與固定件尺寸需以實物為準，賣場 Ø120 × 43 未經驗證
6. **絕緣介面**：LM3886T 背板帶 VEE，兩側散熱機箱的側板通常與機殼共構並接 PE，必須確認絕緣墊片與絕緣套方案
7. 運費與集運成本未計入

## 7. 查詢方法備註

淘寶搜尋頁（`s.taobao.com/search`）為 JS 渲染，無法直接讀取。可用的是關鍵字落地頁 `https://www.taobao.com/list/product/<關鍵字>.htm`，標題、價格、台幣換算與評分均可取得；**商品詳情頁不含規格文字**，故本文件所有尺寸皆來自商品標題。

查詢關鍵字：`全铝功放机箱`、`后级功放机箱`、`铝合金功放机箱`、`功放机箱diy`、`大功率功放机箱`、`lm3886功放机箱`、`全铝机箱`，共取得 126 筆去重商品。

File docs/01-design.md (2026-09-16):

# V0.3 設計規格

> V0.3／2026-09-16：採用 C 方案，只有變壓器與 LM3886T 已購；額定電流、保護與實際功率待確認。

本版規劃內建線性電源的純後級，外接 Eversolo DAC-Z10 的 RCA 前級輸出，音量由 Z10 控制。數值分為原廠條件、專案選擇及計算估算；沒有實測性能宣稱。

## 範圍與訊號路徑

左右聲道各一顆 LM3886T，非反相接法。RCA 訊號依序經 2.2µF 薄膜隔直電容、1k 串聯電阻進入正相輸入，22k 提供輸入偏壓回路，插座側另有 1M 洩放。本機由 DAC-Z10 的可調 RCA 輸出驅動；原廠 2.5Vrms／0dBFS 全電平超過本設計滿功率需要，詳見[Z10 電平搭配](07-z10-interface.md)。

20k 回授及 1k 回授下臂設定約 21 倍中頻增益。47µF 無極性回授電容使 DC 增益趨近 1，減少 DC 偏移放大。加入輸入 1k／22k 分壓後，中頻整機增益約 20.09 倍；實際結果還包括訊源阻抗、元件誤差與 IC 頻率響應。

輸出腳先接 2.7Ω／2W 與 100nF 串聯的 Zobel 支路，再經 0.7µH 與 10Ω／2W 並聯的隔離網路送往假負載。回授取自電感之前。這些值是本專案的起始選擇，需以 PCB 原型確認高頻穩定度。

## IC 腳位與靜音

| 腳位 | 網路／用途 |
|---|---|
| 1、5 | VCC，兩腳都接正電源；符號中重疊顯示 |
| 2、6、11 | NC，不接線 |
| 3 | 功率輸出，接回授及輸出網路 |
| 4 | VEE，負電源 |
| 7 | GND，電源中點／訊號參考 |
| 8 | 各聲道 MUTE 節點 |
| 9、10 | 反相、正相輸入 |

來源：[TI SNAS091C，圖 1–2、Application Information](https://www.ti.com/lit/ds/symlink/lm3886.pdf)。原廠最低穩定閉迴路增益為 10；不能單純調低回授比來配合大輸出 DAC。

每聲道 pin 8 → 22k → RUN 跳線 → VEE。跳線開路時靜音，閉合後由負電源汲取電流解除靜音。100µF 靜音電容正端接 GND、負端接 MUTE。原廠要求解除靜音電流超過 0.5mA；±20V 至 ±36V 的本版計算約 0.79–1.52mA，詳見估算報告。

`22k × 100µF = 2.2s` 只是元件 RC 時間常數，**不等於固定的開機或關機靜音時間**。啟停行為受 pin 8 內部電路與電源變化影響，待量測。JP1／JP2 可於下一版改成額定足夠的雙極開關；兩個 MUTE 節點不直接相接。接點開路時可能承受接近 36V DC，建議選 ≥60V DC 額定。

## 電源與接地

J5 依序為 1=VCC、2=GND、3=VEE；這是正、零、負三線電源，不可把單顆 70V 電源的兩端直接當作本機雙電源。

成機採已訂 AC110V、兩組獨立 22Vac 加一組 12Vac 變壓器。兩組主次級各接一橋，DC 輸出串聯形成正負電源，每軌 20,000µF（10,000µF／63V ×2）。J203 的 1／2／3 接放大板 J5 的 VCC／GND／VEE。供電約 ±30V 等級，實際帶載與空載電壓待測；36V 只是假設情境。詳見[內建電源規劃](05-internal-power.md)。±20V 限流實驗電源只用於板級初測。

每聲道正負軌各有 100nF 及 470µF／63V 去耦；470µF 只負責本地儲能，不替代整機電源濾波。負電源的 470µF 正端接 GND、負端接 VEE。

原理圖上的 GND 為相同電氣網路，但 PCB 必須分開安排輸入、回授、Zobel、喇叭回流至合適匯流點，避免大電流流經輸入地線。100nF 去耦與 Zobel 靠近 IC；輸入接線遠離電源及喇叭線。以上佈線原則參照 [TI datasheet 的 Layout, Ground Loops and Stability](https://www.ti.com/lit/ds/symlink/lm3886.pdf)。

## 散熱與保護邊界

選 LM3886T 非絕緣封裝；金屬背板為 VEE，安裝到接地散熱器／機殼時需合適的絕緣介面與螺絲絕緣套。不可把 LM3886TF 的熱阻當成 T 封裝相同；若改料必須重算。[TI 封裝說明，圖 2 註 1](https://www.ti.com/lit/ds/symlink/lm3886.pdf)

散熱初選每聲道 ≤0.4°C/W、絕緣介面 ≤0.3°C/W，兩者都是選型條件。估算對象為 8Ω 電阻及機內 40°C 環境；真實喇叭阻抗與相角可能加重熱負擔。詳見[計算](02-calculations.md)。

放大板有 IC 內建保護與手動靜音；V0.3 電源次級圖加入整流、儲能、洩放及未定額定值的次級保險絲位置。一次側保險絲與浪湧控制、單軌掉電監測、喇叭 DC 偵測及輸出繼電器尚未完成。上電使用受限流保護的實驗電源與假負載。後續喇叭保護需驗證正負 DC 故障、繼電器 DC 斷開能力、延遲接通與快速斷開；不能以靜音功能替代。

## 原廠參考

- [LM3886 datasheet SNAS091C](https://www.ti.com/lit/ds/symlink/lm3886.pdf)：腳位、電路拓樸、靜音、供電、熱阻與佈線。
- [LM3886 產品頁](https://www.ti.com/product/LM3886)：50W／8Ω／±35V 的元件條件，查閱日期 2026-09-11。

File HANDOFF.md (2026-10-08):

# 接班進度

更新：2026-10-01（整理版，取代 9 月累積的逐日段落；逐日細節一律看 [CHANGELOG.md](CHANGELOG.md)）。

使用者指定**內建供電、純後級，外接現有 DAC 與前級**。已確認 Eversolo DAC-Z10（DAC＋前級，RCA 2.5 Vrms／0 dBFS；XLR 5 Vrms）；音量由 Z10 控制，本機固定增益約 20 倍。目標喇叭 **Usher Be-718**（標稱 8 Ω、實測低中音 >6 Ω、約 85 dB），匹配估算在 [docs/01](docs/01-設計規格.md)「目標喇叭」節。

## 現況（2026-10-01）

- **電路**：放大板 `electrical/lm3886-v01` 與電源次級 `electrical/internal-psu-v02` 兩份 KiCad 原理圖是電路唯一來源（生成器 `tools/build_schematic.py`／`build_power_supply.py`），43＋15 元件，ERC 0 錯誤 0 警告。改電路 → 改生成器 → `python3 tools/rebuild.py`。**2026-10-01 深夜新增控制／保護板第一版**：`electrical/control-v01`（CTRL，46 件：UPC1237、7812 輔助電源、G2R-1-E ×2、光耦靜音 ×2、TL431 旁通計時）＋`electrical/mains-v01`（MAINS，11 件：SL22 10005 NTC、K_BYP G2R-1-E、K_TRIG G5LE-1），生成器 `tools/build_control_board.py`，ERC 0；**rebuild.py 尚未呼叫它**，手動跑 ERC／PDF／netlist。決定與偏離 docs/14 之處見 docs/14 開頭狀態列。**同夜 PCB 也畫了**：`pcb/ctrl-layout-v06`（70×120）與 `pcb/mains-layout-v06`（70×100），DRC 0 錯誤、`validation-v06-ctrl.json` 通過（含市電／低壓 ≥6.4 mm 檢查），工具 `tools/*_v06_ctrl.py`，見 pcb/README「PCB V0.6」。繼電器定為 G2RL-1-E ×4（低背，KiCad 有封裝）、橋改 1N4007 ×4、光耦 SFH617A-3。機箱 3D：`docs/diagrams/chassis_102_v06_3d.png`（`tools/draw_chassis_scene_v06.py`，pyvista）。
- **機殼與配置（2026-10-01 深夜改向）**：BZ4312A2 延到下一台；**改選弘宙 102**（型錄 d395×c290×e105，內估 393×273×100，賣家未確認），**散熱器內置**兩側：150 長×90 高×30 深黑色鋁擠 ×2（規格依 8 Ω 連續正弦 θSA ≤1.2 °C/W，估法 θSA≈1000/表面積 cm²），鰭片朝牆、底板朝板、上蓋底板開通風孔。配置：後排 放大板 L 80×90｜電源板 87×120｜放大板 R 80×90，變壓器前排中央，控制板 70×120 平放左側、市電板右側。**V0.6 三板尚未畫**（目標尺寸如上，對 103 也成立）。下單前問賣家：內寬實際值、上蓋通風孔、後面板是否空白。
- **PCB：現行為放大板／電源板 V0.6.1（2026-10-03 併入 main；`pcb/mono-layout-v061`、`psu-layout-v061`，與 V0.6 只差走線寬度，見 pcb/README「PCB V0.6.1」）＋ CTRL／MAINS V0.6**。**2026-10-08 放大板與電源板 V0.6.1 已送嘉立創試印（各 5 片、1 oz、US$12.87；送件檔 `pcb/fab-20261008/`；IC／C2／機殼內寬都未實量就送，到貨先乾插核對，見 CHANGELOG）**；CTRL／MAINS 仍是工程草稿，不可送製。V0.6 基礎：放大板 `pcb/mono-layout-v06` 90×80（U1 用 KiCad TO-220-11 直立封裝、背板貼板邊 y=0 直接鎖散熱器＝方案 B，型錄幾何）、電源板 `pcb/psu-layout-v06` 92×120（兩欄 381LX、GBJ 朝前、AC 朝變壓器、DC 朝放大板；snubber 預留位未上板）、CTRL 70×120、MAINS 70×100。四板 DRC 0 錯誤、`validation-v06.json`／`validation-v06-ctrl.json` 通過；圖 `pcb/preview/system-layout-v06.png`。**看圖資料（inspection-v06）未做。** V0.5.1、V0.5、V0.4、V0.3 均為歷史，檔案原樣保留。右聲道放大板＝左板轉 180°，RCA 端子落在前側。
- **機殼**：定案淘寶清風工作室 **BZ4312A2**（BRZHIFI，「無音量前＋平衡後」版，¥458，內 330×297×112，兩側散熱器 300×118×50，附保險絲尾插與電源開關）。**未下單**，只剩問賣家能否加開 12 V trigger 孔。配置 A（放大板貼後側牆、中間控制板、前排變壓器＋電源板）餘裕深 22／前排寬 45 mm，圖 `docs/diagrams/chassis_bz4312a2_v05_fit.png`。XLR 只當接頭：pin 2→DPDT→J1，pin 3 空接。
- **IC 固定**：使用者傾向方案 B（IC 搬到板邊直接鎖側牆散熱器，不用 L 型鋁角），**等三項實量才改板**。
- **採購**：已付 NT$4,821（變壓器、yosontw 40 件、LM3886T ×4 拆機品已到貨，T 封裝、NS 打標）。整機估 10.9k–16.2k，總覽在 [docs/00](docs/00-採購總表.md) §5。待買清單與順序一律看 docs/00 §2／§3；本輪可買：GBJ2510 ×2＋小散熱片＋M3 件、保險絲（提案：一次側 T2.5A 有軟啟動／T3.15A 無、22 V 各 T5A、12 V T1.25A）、機殼、XLR 母座 ×2、DPDT 開關。
- **變壓器**：2026-10-01 已量空載——標籤 22 V 4.2 A×2＋12 V 1 A ≈ 197 VA；兩組 22 V 各 22.29 Vac（DCR 0.25／0.2 Ω，串接同相 44.6 V）；12 V 12.27 V；一次側約 2 Ω；市電 110 V。最壞軌電壓 **±33.5 V**，帶載推估連續 30–32 W／8 Ω。**未量：帶載電壓、繞組間絕緣（應 OL）、溫升。**
- **選型定案**：C2／C102＝ROE EGW 47 µF 無極性（V0.5 起站立封裝 `BP_Axial_Vert_D20_P15`，**腳距 15 是假設**）；C6／C7／C106／C107＝ROE EKE 470 µF／63 V；C8 `CP_D12.5_P5`；主電容 381LX A05 殼 Ø35×50 `CP_D35_P10`。

## 下一步（依順序）

1. **核對 LM3886T 實物與 V0.6 放大板的 IC 幾何**：量①背板背面到奇數／偶數腳排的距離（板檔假設 9.58／4.5）②背板孔中心離腳根高度 ③背板厚度。差超過 0.5 mm 就改 `pcb_layout_v06.py` 的 U1 y 值（其他零件不動；`pcb_layout_v061.py` 匯入它所以會跟著變），重跑 `build_pcb_v061.py`→DRC→`verify_pcb_v061.py`→`render_pcb_v061.py`→`analyze_pcb_v061.py`。散熱器底板每聲道一個 M3 孔，高＝8（銅柱）＋1.6＋②。
2. **C2 站立腳距實量**：把 EGW 47 µF 實物彎腳量腳距，不是 15 就改 `BP_Axial_Vert_D20_P15` 並重建。
3. **變壓器帶載量測**：照 [docs/04](docs/04-上電與驗收.md) 與 [docs/14](docs/14-V0.4-控制與保護板設計草案.md) §8 量帶載電壓、絕緣、溫升；然後把 `tools/mains_budget.py` 的「22 V＋8% 調整率」前提改成實測值重跑，更新 docs/05 試算段。
4. **採購**：照 docs/00 §3 順序。機殼下單前問 trigger 孔；GBJ2510 到貨核腳距 10／7.5／7.5、本體 30×20×3.8、背面絕緣；原理圖 BR1／BR2 的封裝欄位還沒改成 `GBJ_Upright_P10_7.5_7.5`（板檔已是）。
5. **控制板（docs/13／14）**：原理圖與 PCB 第一版都已畫（見現況）。接下來：①使用者審圖；②買零件（G2RL-1-E 12VDC ×5、UPC1237 ×2、SL22 10005 ×1、SFH617A-3 ×2、TL431、BC327 ×2、7812、1N4007 ×9、1N4148 ×2、2200µF/25V 等）→ 到貨核對 G2RL 腳位（COM／NO）、SL22 腳距 10、小電解直徑；③把 `build_control_board.py` 接進 `rebuild.py`，補 `verify_control_board.py`（比照 verify_power_supply）；④docs/14 §6 用 22.4 J 重算、§3 時序表改成「解除靜音＝繼電器吸合」、§7 清單改 G2RL；⑤麵包板實測 UPC1237 在 12 V 供電下的門檻與延遲（型錄是 25–60 V）；⑥CTRL／MAINS 看圖資料（inspection）與絲印整理尚未做。
5b. **V0.6 放大板與電源板已畫（2026-10-02）**。剩：①賣家回 102 內寬後核對 55＋90＋（餘）＋92＋（餘）＋90＋55 ≤ 內寬；②`inspection-v06`（比照 v051 六支腳本衍生）；③~~current-budget 載流對照仍未做~~ → 2026-10-03 `analyze_pcb_v061.py` 已做 V0.6 vs V0.6.1；④決定右聲道 RCA 線走法（同板轉 180°，接頭在前）或另出鏡像放大板。
5c. **V0.6.1（走線加寬）已於 2026-10-03 併入 main 成為放大板／電源板現行版**。後續改放大板／電源板一律改 `pcb_layout_v06.py`（擺位）或 `pcb_layout_v061.py`（寬度）再跑 v061 流程；`inspection` 若要做請做 v061。訂板時另決定 1 oz 或 2 oz（2 oz 全部電阻減半）。機箱 3D 仍吃 V0.6 STL（外形相同）。
6. **工具對照**：V0.4／V0.5／V0.5.1 沒做 current-budget；V0.6→V0.6.1 已有 `analyze_pcb_v061.py`（模型同 v03）。
7. **測試順序**：放大板先用限流實驗電源；內建電源獨立驗證後再整合；假負載／熱／失真量完才接喇叭（docs/04）。

封裝定案後另有待辦：J1／J2 極性標示、JP1（RUN）說明文字、全板零件值顯示。

## 未解決問題

- **一次側接線、軟啟動、控制輔助電源與喇叭 DC 保護尚未設計。** 電源圖只涵蓋隔離次級，**不是完整市電施工圖**。
- **沒有 SPICE 模擬、Gerber、機構加工圖或任何實機量測。** ERC／DRC 通過不等於電路穩定、安全或低失真。
- 每聲道 30–40 W／8 Ω 是探索範圍不是額定；Be-718 低中音 >6 Ω、±36 V 連續 6 Ω 時散熱可能超溫，要實測；4 Ω 未驗。
- 機殼散熱器熱阻賣家未標（估 0.5 °C/W 級），介面材料（雲母＋絕緣粒＋導熱膏）已選未買；PE 接點、屏障、端子與線束尚未納入整機 BOM。
- GBJ2510 散熱片候選未找（鋁鰭片寬 ≤30、厚 ≤10、高 25–35、M3 孔，估 8–12 °C/W），`inspection-v051` 的 GBJ 高度 20 mm 是假設。
- 軟體檢查的詳細結果與限制見 [electrical/validation.md](electrical/validation.md)。

## 環境注意（這台 Windows）

- **KiCad 10.0.6 有裝但不在 PATH**：`%LOCALAPPDATA%\Programs\KiCad\10.0\bin\` 有 `kicad-cli.exe` 與內建 `python.exe`（可 import pcbnew）。沒有 `pdftoppm`，`rebuild.py` 會停在那一步，用 PyMuPDF 轉 PNG 代替並手動照 `rebuild.py` 的步驟跑。
- **行尾**：OneDrive 工作樹是 `autocrlf=true`（CRLF），repo 是 LF。重建板檔一律另開 `git clone -c core.autocrlf=false` 的工作樹（放 scratchpad），改完 commit → push → 回 OneDrive repo `git merge --ff-only`（OneDrive 的 main 是 checked-out，不能直接 push 進去）。雜湊綁定檔（`verification.json`、`sources.json`、`drc-provenance`）一律 LF 正規化後再算。
- **Python**：PyMuPDF、Pillow 只在 3.13，圖表腳本用 `py -3.13 -X utf8`。SVG→PNG 用 `tools/render_diagrams.py`（PyMuPDF），不需 sharp；PyMuPDF 不支援巢狀 `<svg viewBox>` 與 `clip-path`。
- `verify_pcb_v0x.py` 需要 `electrical/netlist.xml`／`psu-netlist.xml`，由 `kicad-cli sch export netlist` 匯出且不入版控；沒匯出就會失敗，不是程式錯誤。
- 板檔生成器會重寫 `pcb/DraftV03.pretty` 的 UUID，跑完要 `git checkout -- pcb/DraftV03.pretty`。
- `tools/build_project_pdf.py` 需 reportlab、pypdf，非 Windows 設 `LM3886_FONT`；產物在 `output/`，不入版控。
- 每次接手先檢查 Git 工作樹與遠端，保留其他協作者的修改，不強制覆寫遠端。

## V0.5.1 重建流程

```
# 在 LF 工作樹，PATH 已加 KiCad bin
kicad-cli sch export netlist -o electrical/netlist.xml     electrical/lm3886-v01.kicad_sch
kicad-cli sch export netlist -o electrical/psu-netlist.xml electrical/internal-psu-v02.kicad_sch
<KiCad python> tools/build_pcb_v051.py            # 只建電源板；放大板用 build_pcb_v05.py
kicad-cli pcb drc --format json --exit-code-violations -o pcb/psu-v051-drc.json pcb/psu-layout-v051.kicad_pcb
py -3.13 -X utf8 tools/verify_pcb_v051.py
py -3.13 -X utf8 tools/render_pcb_v051.py
# 看圖資料：build_ → export_ → frame_ → render_ → write_pcb_parts_audit_ → verify_pcb_inspection_v051.py
git checkout -- pcb/DraftV03.pretty
```

## 分支

- `main`：現行。GitHub `origin/main` 同步。
- `v052-layout`：**未採用**的 V0.5.2 合板候選（每聲道放大＋濾波 90×142，DRC 0），保留供日後參考，不併入。
- `origin/v04-layout`、`origin/v05-layout`、`origin/v051-psu-gbj`：都已併入 main，只剩遠端分支。

## 歷史紀錄

逐日進度、各版 PCB 與採購的完整歷史見 [CHANGELOG.md](CHANGELOG.md)。V0.1／V0.2 板檔與舊腳本已刪除，從 Git 歷史（`41b217c`）取回。

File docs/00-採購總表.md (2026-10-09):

# 00 採購總表

**買零件看這一份就好。** 分「已買」與「未買」兩張表，後面是購買順序與相容性結論。

價格為 2026-09-18 商品頁顯示的參考價，**全部未含運**。商品標題不是原廠認證、不是真偽保證、不是 PCB 封裝核對。已購不等於已驗收，目前**沒有任何實測數據**。

2026-09-22 更新：補入 CDE 原廠型錄尺寸（標「型錄值」，到貨仍要實測）、四項先前漏列的整機零件、小計，以及電感自繞方案。

---

## 1. 已買

露天 yosontw 訂單 **26092068825254**（2026-09-20 結帳，40 件 $2,238＋運 $60＝$2,298）。變壓器為蝦皮「小白的生活工場」**$1,700**（含運；商品名「200W 環型變壓器 雙22+單12 A芯矽鋼片 (22-0)X2組」，2026-09-22 取貨）；LM3886T 為露天 zergaiur 訂單 **26091168002383**（2026-09-11 下單，「二手 功放積體電路 原裝進口拆機 LM3886T 141-17928」4 顆×$187＝$748＋運 $75＝**$823**，2026-09-29 取貨）。**已付合計 $4,821。**

**到貨狀態（2026-09-22）：** yosontw 40 件與環形變壓器**已到貨**；LM3886T **2026-09-29 已到貨，實收 4 顆**（訂購 4 顆，2 顆裝機、2 顆備品）；照片初核：四顆皆金屬背板 T 封裝、NS 商標；細節見下表該列，**腳長、腳寬、背板平整度尚未實測**。**2026-09-23 已量機構尺寸**（變壓器外形、四款電解；細節在各列）。**2026-10-01 已量變壓器電氣：各繞組直流電阻、空載電壓、線色分組、兩組 22V 串接相位，並抄下標籤電流（22V 4.2A×2、12V 1A ⇒ 約 197 VA）；量測時市電 110 V**；細節在下表該列，**帶載電壓與溫升未測**。下表「到貨要核對／要量什麼」欄是待辦清單，量完寫回本節與 1.1。

| 料件 | 數量 | 對應位號 | 到貨要核對／要量什麼 |
|---|---:|---|---|
| 環形變壓器 AC110V／2×22Vac＋12Vac（標示 200W） | 1 | — | **最優先**：標籤、線色相位、三組繞組是否互相獨立、**各繞組電流**、空載電壓、熱保護。200W 不等於 200VA。**2026-09-23 初量**（[到貨照片](photos/20260923-transformer-arrival.jpg)）**：外徑約 Ø120 mm、高度 ≥45 mm（含出線處鼓起約 50 mm）、出線 8 條各約 30 cm**（8 條＝一次側 2＋22V×2 組 4＋12V 2，與三組獨立繞組相符）（賣場標 Ø120×43；中心為開放孔，內徑目測約 Ø40 mm，非灌封）。**2026-10-01 電氣實量**（三用電表，電阻值已扣掉表筆短路讀值；[手寫稿照片](photos/20261001-transformer-electrical.jpg)）：**標籤 22V 4.2A ×2、12V 1A ⇒ 22×4.2×2＋12×1≈197 VA**（使用者 2026-10-01 核對標籤確為 4.2 A）。**量測時市電 110 V**。線色分組（22V 兩組線色由使用者口頭確認，一次側與 12V 依手寫稿字母）：一次側 R＋B（B 是黑或藍未問，接法上不影響），DCR 4.4／4.5 讀值扣 2.4／2.6 ⇒ **約 1.9–2.0 Ω**；12V 繞組 **黃＋黃**，**空載 12.27 Vac、0.4 Ω**；22V 第 1 組 **綠＋綠**，**空載 22.29 Vac、0.25 Ω**；22V 第 2 組 **藍＋藍**，**空載 22.29 Vac、0.2 Ω**（手寫稿寫 G／B 是指串接時兩端取的那條綠與那條藍）。同組兩條線同色，**裝機前仍要先用電阻檔配對再接**（同色線互量約 0.2–0.25 Ω 才是同一組，OL 就不是）。兩組 22V 串接：**一端綠到另一端藍讀 44.6 Vac、串接 DCR 9.7−9.3＝0.4 Ω** ⇒ 兩組同相、可當 22-0-22 用；電壓用 1 kΩ 假負載（約 22 mA）量的，等同空載。匝比 110／22.29＝4.93。由電阻推估：滿載銅損約 15 W（一次側 1.79 A×1.95 Ω＝6.2 W、22V 兩組 4.4＋3.5 W、12V 0.4 W，約 7% VA）、每組 22V 滿載 4.2 A 時電壓約掉 1.6–1.8 V（**調整率約 7–8%**，滿載約 20.5 V），與 200 VA 環形變壓器的常見值相符；標籤的 22 V 因此是偏空載的標法，不是滿載值。**仍未做：帶載電壓（真正接整流濾波帶電阻負載量）、繞組間與對一次側的絕緣（應 OL）、溫升、熱保護有無。** |
| LM3886T（二手拆機） | 4（裝機 2＋備品 2） | U1, U2 | **2026-09-29 到貨，實收 4 顆**（[照片](photos/20260929-lm3886t-arrival.jpg)）。照片初核：**四顆皆為金屬裸背板＋單孔 ⇒ T 封裝（背板＝VEE）**，不是 TF；本文第 133 行「若為 TF 要重算」的疑慮解除。打標皆為 National Semiconductor 商標＋第二行 `LM3886T`（NS 時期品，/NOPB 不印在殼上，無法由打標判斷）；批號第一行由左至右約為 `M04AEE3`、`M11PDG3`、`3CA97?HG3`（照片斜拍，字元不確定），圓圈記號 T1／?／U4／T1。**第 1 顆（最左）正面打標幾乎全磨掉，只剩圓圈 T1**——可能是拆機時清潔磨損，也可能是重印品，**要換角度補拍或用放大鏡看**；先當備品，不裝機。背板有刮痕與導熱膏／氧化殘留，確為拆機品（賣場「全新」欄位不實）。引腳 11 支、已上錫、有舊焊錫；第 2、3 顆數支腳明顯歪斜，插板前要理直。**待實測：腳長（剪短過嗎，需 ≥ 板厚 1.6 mm＋焊點）、腳寬（封裝鑽孔已改 1.1 mm）、背板是否平整（放玻璃上看縫）**。/NOPB 未確認 |
| ROE EGW 47µF／63V BP-NP 臥式 | 2 | C2, C102 | **量臥式本體長度與引線腳距**。現板是立式 `BP_D10_P5`，**立式改臥式為必改**。ROE（Roederstein）為停產品牌，沒有可靠的公開型錄，尺寸只能實測。**2026-09-23 實量：本體長約 40 mm、直徑約 Ø20 mm**（軸向），腳徑目測約 0.8–1.0 mm（比 EKE 粗、未超過 1.0；新封裝鑽孔宜取 1.2 mm） |
| ROE EKE 470µF／63V | 4 | C6, C7, C106, C107 | **量直徑與腳距**；現板占位 Ø12.5／腳距 5mm，超過就要改封裝。同上，無公開型錄。**2026-09-23 實量：Ø約 12 mm、高約 25 mm、腳距約 5 mm → 現板 `CP_D12.5_P5` 相容，不必改封裝**；腳徑目測約 0.8 mm，現行鑽孔 0.9 mm 餘隙僅 0.1 mm，**建議 `CP_D12.5_P5` 鑽孔改 1.0 mm**（C8 的 361R 腳徑也是 0.8，同封裝一併受益） |
| CDE 381LX103M063A052 10,000µF／63V 牛角 | 4 | C201–C204 | **量本體直徑、高度、牛角腳形狀與間距**、鑽孔（現板 1.3mm 不視為合格）。**這顆的高度決定機殼高度**。型錄值：尾碼 A05 ＝ **Ø35 × 50 mm**、約 74 g，snap-in 腳片寬 ≤2.0／厚 0.8 mm，圓孔 1.3 mm 一定插不進。⚠️ **現行 CDE 381LX 型錄的 63V／10,000µF 只列 K452（Ø30×45）與 K052（Ø30×50），沒有 A052 這個料號**；到貨先對殼上印字，若實收 Ø30 則封裝與機殼估算都要重算。**2026-09-23 初量：腳距約 10 mm**（與 `CP_D35_P10` 一致）；殼上印字（1 顆，隔袋拍照）：CDE USA／381LX／10000µF／63 WV／+105°C／8040（推測為日期碼），**殼上無完整料號，A05 或 K05 殼只能靠量直徑判斷**；**實量本體 Ø約 35 × 高約 50 mm、2 腳 → 確為 A05 殼尺寸**，`CP_D35_P10` 外框相容；底部照片：2 支扁片 snap-in 腳、腳片中段有卡勾彎折，端子頂面刻「−」「＋」，負極端靠套管黑色負極條；**腳片實量寬約 1.5 × 厚約 1.0 mm**（比型錄厚 0.8 略厚），對角約 1.8 mm，現行 2.5 mm 圓孔可插入；圓孔內卡勾卡不牢，本體（約 74 g）另以束帶或矽膠固定 |
| CDE 361R101M100EG2 100µF／100V | 2 | C8, C108 | 型錄值：EG 殼 ＝ **Ø12.5 × 20 mm、腳距 5.0 mm、腳徑 0.8 mm**。現板 `CP_D8_P3.5`（Ø8／3.5 mm）**確定不合，必改為 Ø12.5／P5**（可沿用 `CP_D12.5_P5`）；到貨量一次確認即可。**2026-09-23 使用者目視核對：直徑、高度、腳距、腳徑與型錄值相符**（未逐項以尺量出數字），`CP_D12.5_P5`（鑽孔已改 1.0）可用 |
| WIMA MKS4 2.2µF／100V 15mm | 2 | C1, C101 | 對值與數量即可，腳距與現板相容 |
| WIMA MKS2 100nF／100V 5mm | 8 | C3, C4, C5, C103, C104, C105, C205, C206 | 同上 |
| Vishay PR02 2.2kΩ／2W／1% | 2 | R201, R202 | 對值與數量即可，軸向件可彎腳吸收腳距 |
| Vishay PR02 10Ω／2W／1% | 2 | R7, R107 | 同上 |
| RNU2 2.7Ω／2W | 2 | R5, R105 | 同上；製造商與低電感特性待確認 |
| Vishay MRS25 1kΩ／0.6W／1% | 4 | R3, R103, R6, R106 | 同上 |
| Vishay MRS25 20kΩ／0.6W／1% | 2 | R4, R104 | 同上；**這顆決定增益** |
| Vishay MRS25 22kΩ／0.6W／1% | 4 | R2, R102, R8, R108 | 同上 |
| Vishay MRS25 1MΩ／0.6W／1% | 2 | R1, R101 | 同上 |

**到貨後的動作鏈：** 量四款電解尺寸（其中 C8 已由型錄確定要改 Ø12.5／P5，C2 確定改臥式）→ 改 `pcb/DraftV03.pretty/` 封裝 → 重建 PCB、重跑 DRC。量變壓器各繞組電流 → 才能決定保險絲與整流橋。

型錄來源與逐項比對見下方 1.1。
### 1.1 型錄尺寸 vs 現板封裝（2026-09-22 查閱）

只列原廠文件查得到的項目；ROE 兩款沒有公開型錄，只能實測。「通過」指腳距與孔徑相容，不代表已核對真實彎腳與相鄰零件淨空。

| 元件（來源） | 型錄尺寸 | 現板封裝 | 結論 |
|---|---|---|---|
| LM3886T（[TI NDJ0011B](https://www.ti.com/lit/ds/symlink/lm3886.pdf)） | 11 腳、腳距 1.7 mm、兩排交錯 5.08 mm、全寬 17.02 mm；腳 0.97×0.41 mm；本體寬 20.02、厚 4.5 mm；散熱片孔 Ø3.81 mm | `LM3886T_UNVERIFIED`：1.7／5.08／17.0 mm，鑽孔 0.9 mm | 腳位排列正確。**鑽孔 0.9 mm 小於腳寬 0.97 mm，必改 ≥1.1 mm**。TF 版（背板絕緣）同腳位，不影響 PCB |
| KBPC2510（[EIC BR50M 外形](http://www.eicsemi.com/DataSheet/KBPC2500%20-%20KBPC2510.pdf)） | 28.4–28.7 mm 方、高 10.95–11.25 mm、中心孔 Ø5.1–5.3 mm；四支 6.35×0.8 mm **Faston 端子**，端子間距 15.7–16.7 mm | ~~`BridgeTerminal4_P5.08`~~ → **`GBJ_Upright_P10_7.5_7.5`**（2026-10-01 起，PCB V0.5.1） | ~~2026-09-24 定案：橋堆鎖機殼，四支 Faston 各接一條線到板上 4 位端子~~ **2026-10-01 改為 GBJ2510 直立上板**（Diodes DS21221：本體 30×20×3.8、扁腳 1.0×2.2、腳距 10／7.5／7.5、#6 孔）：封裝長孔 2.6×1.4、焊盤 3.8×2.6。KBPC2510 不買了，這列的 KBPC 尺寸只留紀錄 |
| WIMA MKS4 2.2µF／100V（[MKS4 型錄](https://www.wima.de/wp-content/uploads/media/e_WIMA_MKS_4.pdf)） | 8 × 15 × 18 mm（W×H×L）、PCM 15 mm、腳 Ø0.8 mm | `Film_P15`：外框 18×8、腳距 15、鑽孔 1.0 mm | 通過；3D 假設高 12 應為 15 |
| WIMA MKS2 100nF／100V（[MKS2 型錄](https://www.wima.de/wp-content/uploads/media/e_WIMA_MKS_2.pdf)） | 2.5 × 6.5 × 7.2 mm、PCM 5 mm、腳 Ø0.5 mm | `Film_P5`：外框 8×4、腳距 5、鑽孔 0.8 mm | 通過 |
| Vishay PR02 2W（[28729](https://www.vishay.com/docs/28729/pr010203.pdf)） | Ø3.9 mm、本體 10 mm（含帽 12 mm）、腳 Ø0.78 mm | `R_2W_P20`：外框 15×5、腳距 20、鑽孔 1.0 mm | 通過；每側彎腳約 4 mm |
| Vishay MRS25（[28724](https://www.vishay.com/docs/28724/mrs16m25.pdf)） | Ø2.5 × 6.5 mm、腳 Ø0.6 mm | `R_P7.5`：外框 5.1×2.5、腳距 7.5、鑽孔 0.8 mm | 通過 |
| CDE 361R101M100EG2（[361R](https://www.cde.com/resources/catalogs/361R.pdf)） | Ø12.5 × 20 mm、腳距 5.0 mm、腳 Ø0.8 mm | `CP_D8_P3.5`：Ø8、腳距 3.5、鑽孔 0.9 mm | **必改**為 Ø12.5／P5（可沿用 `CP_D12.5_P5`） |
| CDE 381LX A05 殼（[381LX](https://www.cde.com/resources/catalogs/381-383.pdf)） | Ø35 × 50 mm；snap-in 腳片寬 ≤2.0、厚 0.8 mm。**腳距未從型錄文字取得**（2026-09-23 實物初量約 10 mm） | `CP_D35_P10`：Ø35、腳距 10、鑽孔 1.3 mm 圓孔（2026-09-22 已改 2.5） | 2026-09-23 實量 Ø35×50、腳片 1.5×1.0 → 2.5 mm 圓孔可用；**圓孔 1.3 必改為可容 2.0×0.8 腳片的槽孔或 ≥2.5 mm 圓孔** |
| ROE EGW 47µF、ROE EKE 470µF | 無公開型錄；**2026-09-23 實量** EGW 長約 40 × Ø約 20 mm（軸向）、EKE Ø約 12 × 高約 25 mm、腳距約 5 mm | `BP_D10_P5`（立式）、`CP_D12.5_P5` | EKE **通過**；EGW 本體遠大於 Ø10，**C2／C102 必改**：臥式腳距約需 ≥50 mm、占板約 50×20 mm（或立式反折，腳距約 25 mm、高 >40 mm）。**2026-09-23 使用者選躺式**：已新增 `BP_Axial_L40_D20_P50`（腳距 50、鑽孔 1.2）並將放大板加寬為 115×90 mm（2026-09-24 已重建，DRC 0 違規）；EKE 同封裝鑽孔改 1.0 |

歸納：不必等到貨就能改的封裝有 **LM3886T 鑽孔、C8、C2 臥式、C201–C204 槽孔** 四項；KBPC 是設計決策不是量測問題；ROE 兩款才是真的要等。

**2026-09-22 已改（封裝庫＋生成器，板檔未重建）：** `LM3886T_UNVERIFIED` 鑽孔 0.9→1.1／焊盤 1.65→2.0；`CP_D35_P10` 鑽孔 1.3→2.5／焊盤 3→4（圓孔暫代槽孔）；`pcb_layout_v03.py` 的 C8 改指派 `CP_D12.5_P5`；3D 高度表 Film_P15→15、LM3886T→22。**C2 臥式沒改**（ROE EGW 無型錄，本體長度未知）。

---

## 2. 未買

### 2.1 電路上必要的

| 料件 | 商品頁 | 數量 | 價格 | 下單前要問什麼 |
|---|---|---:|---:|---|
| **GBJ2510 整流橋（直立上板）** | 候選待找（Diodes GBJ2510-F、Panjit、光寶、MCC 同型皆可；[Diodes 規格書 DS21221](https://www.diodes.com/assets/Datasheets/ds21221.pdf)） | 2 | 約 $20–40／顆 | **2026-10-01 使用者定案：整流橋改上電源板，PCB V0.5.1 已畫（`pcb/psu-layout-v051`，DRC 0）**，取代 9/24 的 KBPC2510 鎖機殼方案。規格核對（以 2026-10-01 變壓器實測）：1000 V 對反向峰值約 63 V；25 A（有散熱片）對每橋平均直流約 2.5 A；單次湧浪 350 A 對實測次級迴路 0.3 Ω 推估約 100 A；I²t 510 A²s。封裝 `GBJ_Upright_P10_7.5_7.5`：腳距 10／7.5／7.5、扁腳 1.0×2.2、長孔 2.6×1.4，腳序 ＋ ～ ～ －，**印字面朝電容、金屬背面朝板邊**（絲印粗線那側）。到貨核對：腳距、腳寬、本體 30×20×3.8、孔徑 3.1–3.4、背面是否絕緣（原廠 2500 Vrms）。耐熱：裸裝約 20 °C/W，聽音樂每橋 1–1.5 W 可裸裝，滿功率正弦每橋 4–5 W 一定要散熱片 |
| **GBJ 用小散熱片＋M3×8 螺絲、螺帽、彈簧華司** | 候選待找 | 2 組 | 約 $20–50／片 | **放在金屬背面那側，板上已預留寬 30 × 厚 10 mm 的空間（離保險絲座 1.0、離電容外框 1.5 mm，`validation-v051.json`）**。選法：鋁擠鰭片式，寬 ≤30、含鰭總厚 ≤10、高 25–35 mm，中間有 M3 孔（或自鑽；GBJ 孔中心離本體底約 11 mm），估 8–12 °C/W → 滿功率正弦時溫升約 40–55 °C，機內 40 °C 環境下外殼約 85–95 °C，接面在 150 °C 上限內；若只找得到 30×30×3 mm 鋁平板（約 15 °C/W）也可，只是正弦測試要縮短。背面與散熱片間薄塗導熱膏（與 TS-KS101 共用），GBJ 背面原廠已絕緣，不需雲母片。**不要買 TO-220 夾式小散熱片**（只有 10 mm 寬，夾不住 30 mm 寬的 GBJ） |
| ~~KBPC2510 整流橋~~ | [露天](https://www.ruten.com.tw/item/22605098060064/) | ~~2~~ | ~~$51~~ | **2026-10-01 作廢**（使用者改選 GBJ2510 上板）。保留紀錄：2026-09-24 曾定案鎖機殼＋Faston 線接；2026-10-01 曾以實測核過 PIV／電流／湧浪／耗熱皆可 |
| ~~Faston 6.35 mm 母端子（絕緣護套）＋耐溫線~~ | — | ~~8 只＋約 1.5 m~~ | — | **2026-10-01 作廢**（整流橋上板後沒有橋堆到板的線）。變壓器到板端子的線另計：22 V 繞組 4.2 A ⇒ AWG18 即夠、AWG16 更保險，耐溫 105 °C |
| 5×20mm 保險絲座 | [露天](https://www.ruten.com.tw/item/21840721329469/) | 2 | $4 | PCB 安裝型態、腳距、孔徑、DC 額定。5×20 是保險管尺寸不是焊腳距 |
| 5×20 延時保險絲 | [露天](https://www.ruten.com.tw/item/22410976060232/) | 一次側 1＋次級 2 起 | $136 | 禁止照頁面預設值買。**2026-10-01 依標籤 197 VA 初定（提案，未買）**：一次側滿載約 1.8 A，有軟啟動（docs/14）用 **T2.5A**、沒有軟啟動用 **T3.15A**（環形變壓器開機湧浪大，太小會莫名斷）；次級每組 22V（額定 4.2 A）各 **T5A**；12V（額定 1 A）**T1.25A** 或 T1.6A。一次側那顆裝在機殼附的尾插保險管座（BZ4312A2 配件），要確認是 5×20 還是 6.3×32 |
| 0.7µH 空心電感 | **建議自繞**；備選 [露天](https://www.ruten.com.tw/item/22615433056210/) | 2 | 自繞 ≈ $0；買 $379 | 露天品線徑 2.1mm、腳距 28mm，**塞不進現板 `AirCoil_P20`**，兩顆 $758 是未買清單最貴的一項。TI LM3886 datasheet 建議的輸出隔離電感為 0.7µH 空心，用 Ø1.0 mm 漆包線在 Ø10 mm 圓棒上密繞約 10 圈即接近此值，腳距可直接做成 20 mm，DCR 自行量測。繞好用 LCR 表或以已知電容諧振法核對感值 |
| KF301 2P／5.08mm | [露天](https://www.ruten.com.tw/item/22409916143944/) | 6（電源板橋堆端子另需 4P×2，或 2P×4 拼接） | $1 | 一件含幾個、廠牌、孔徑、插線方向、載流 |
| KF301 3P／5.08mm | [露天](https://www.ruten.com.tw/item/22410924930141/) | 3 | $2 | 一件含幾個、**VCC/GND/VEE 順序**、孔徑、載流 |
| 2.54mm 單排針 1×40P | [露天](https://www.ruten.com.tw/item/21839712907740/) | 裁 2 段×2pin | $3 | 單件包裝、跳線帽配合高度、≥60VDC 絕緣。是排針不是排母 |
| 2.54mm 跳線帽 | [露天](https://www.ruten.com.tw/item/22410924645672/) | 2 | $23／100只 | ≥60VDC 絕緣。買 1 包會剩 98 只 |
| RCA 面板母座 | [露天](https://www.ruten.com.tw/item/21840724685995/) | 紅 1 黑 1 | $12 | **必須附能隔離外殼與金屬面板的絕緣墊圈／套管**，商品頁沒證明 |
| 喇叭接線柱 | [露天](https://www.ruten.com.tw/item/22410923188279/) | 紅 2 黑 2 | $17 | 頁面沒有顏色選項要問；≥60VDC、載流、面板絕緣、開孔與板厚 |
| TO-3P 雲母絕緣片 22×30mm | [露天](https://www.ruten.com.tw/item/22410921549515/) | 2 | $23／10張 | 是否適合 LM3886T 孔位與金屬背板；整套介面熱阻 ≤0.3°C/W、耐壓、公差 |
| 絕緣螺絲套（TO-220 絕緣粒／T 型絕緣粒 M3） | [露天](https://www.ruten.com.tw/item/21711492321878/)；關鍵字「TO-220 絕緣粒」「T型絕緣粒 M3」 | 2（買 10 顆包） | $20／10顆 | **規格（2026-09-29）：管外徑 3.5–3.7（LM3886T 背板孔 Ø3.81）、管內徑約 3.2（M3）、帽緣外徑 6–7、管長 ≤ 背板厚（約 1.5，到貨實量）——管過長會先頂散熱器，背板壓不緊。** 候選頁寫「外徑 6／內徑 3」不知指管還是帽緣，下單前要問；6 是管外徑就不能用。材質尼龍／PBT；不可用尼龍螺絲代替（受熱鬆弛）。**不取代雲母片**，兩者一起用（見 mica_washer 圖） |
| TS-KS101 導熱膏 | [露天](https://www.ruten.com.tw/item/22410921235113/) | 1 | $57／45g | 材料是否導電；**導熱膏不提供 LM3886T 背板絕緣**。橋堆鎖機殼也共用這一管 |
| ~~KBPC2510 固定件：M5 螺絲＋螺帽＋彈簧華司~~ | — | ~~2 組~~ | — | **2026-10-01 作廢**（KBPC2510 不買了；GBJ 的 M3 固定件併入上面散熱片那列） |
| 環形變壓器固定件：中央螺栓、上下橡膠墊、金屬壓碟 | 候選待找（先問變壓器賣家是否附） | 1 組 | — | 賣場未說明是否附；螺栓長度等變壓器實高（本體含出線鼓起約 50 mm → 加上下墊與壓碟疊高約 65–70 mm，螺栓約 M6×75–80；中心開孔約 Ø40，螺栓粗細由壓碟決定、不由孔徑決定，壓碟須 ≥Ø100 壓住繞組頂面，橡膠墊 ≥Ø120）。**壓碟不可同時碰到機殼上下蓋形成短路環**。**先前漏列** |
| 熱縮套管（Ø3–10 mm 混裝）與 UL 認證絕緣套 | 候選待找 | 1 包 | — | 市電端子、變壓器接線、保險絲座腳都要包；一次側用 600V 級。**先前漏列** |

**2.1 小計（粗估，頁面單價×需求數，不含運）：約 NT$1,230，其中電感 $758；電感改自繞則約 NT$480。** 三項「候選待找」未計。

⚠️ LM3886T 的金屬背板是 VEE（負電源），鎖到接地機殼一定要絕緣介面＋螺絲絕緣套，這不是可選項。

### 2.2 設計未定案（買了可能白買）

| 料件 | 商品頁 | 數量 | 價格 | 下單前要問什麼／卡在哪 |
|---|---|---:|---:|---|
| 大型鋁型材散熱器 400×50×200 | [露天](https://www.ruten.com.tw/item/22407792090091/) | 2 | $1,012–2,531 | **沒有任何賣家標 °C/W**，需求是每聲道 ≤0.4°C/W。可能超出機殼空間；買附散熱器的機殼就不要重複買 |
| 機殼（BRZHIFI **BZ4312** 兩側散熱全鋁 430×120×311；淘寶常寫「4312 兩側散熱 甲類機箱」） | [原廠頁](https://brz-hifi-audio.com/products/bz4312-full-aluminum-chassis-power-amplifier-case-class-a-enclosure-hifi-diy-powersupply-box-430x120x311mm)、[Alibaba](https://www.alibaba.com/product-detail/BRZHIFI-BZ4312-Double-Radiator-Aluminum-Alloy_1600455646602.html)、AliExpress 品號 4001099426678；原淘寶連結（2026-09-24 記）已失效 | 1 | ¥408／約 NT$1,960（AliExpress 約 US$78） | **2026-09-29 查到原廠內部尺寸：寬 330／高 112／深 300 mm；面板 10 mm、後板與上下蓋 3 mm；每側散熱器 300×50×118 mm。** 對照三板：電源板 160＋變壓器 Ø120＝280 ＜ 330；深 25（後板端子）＋120＋90＝235 ＜ 300；高 112 對電容疊 60 綽綽有餘。**尺寸可放，散熱器熱阻未標，估 0.5 °C/W 級，實測為準。** 秋硕 360×80×268（內 280×74×257）已核為塞不下（2026-09-29）。**2026-09-29 使用者找到淘寶「佛山清風工作室2店（工廠店）」的 BZ4312A2，¥458≈NT$2,195，直郵台灣（大陸段 ¥21＋海運）**，落地估 2,400–2,600；**版本：「無音量前＋平衡後」**（使用者 2026-09-29 決定；前板只有電源鈕；後板預鑽每聲道 XLR＋RCA、中間一個切換開關孔、IEC 電源座、喇叭端子 ×4）。本機為單端輸入，XLR 只當接頭用：RCA 中心與 XLR pin 2 各接 DPDT 迷你搖頭開關兩側、公共腳→J1 訊號；RCA 殼與 XLR pin 1→J1 地；**XLR pin 3 空接**（Z10 差動輸出，勿接地）。走 XLR 訊號大約 6 dB，由 Z10 音量補；開關孔緊鄰電源座，訊號線用屏蔽、走短、遠離變壓器。真正平衡輸入需另加差動接收級，暫不做。未購件新增：DPDT 迷你搖頭開關 ×1、XLR 母座 ×2。**2026-09-29 商品頁規格：內 330 寬 × 297 深 × 112 高**（深比原廠網頁少 3）；外 430×310×120；重 7.2 kg；散熱器 300×118×50 每側各 1.6 kg；面板 10／後板 3／上下蓋 3。**配件含：後拉手 ×2、橡膠機腳 ×4、電源開關 ×1、帶保險管電源尾插 ×1、鋁旋鈕 ×1**（不含 RCA 與喇叭柱）。⇒ 內部尺寸與電源座孔兩問已解，**AC-01 三合一座不用買**（§2.2 該列作廢，一次側保險絲改用尾插內的保險管）；下單前只剩問 trigger 孔能否加開。**內部配置圖** `docs/diagrams/chassis_bz4312a2_layout.png`（2026-09-29）：A（建議）放大板 L/R 各 90 寬貼後側牆（IC 邊朝牆）、中間 150 留控制板、前排變壓器 Ø120＋電源板 160×120 並排，深 25＋115＋30＋120＋7＝297；B 變壓器在後中，可放但緊鄰輸入端、控制板無處放。使用者未選。**等角立體示意** `docs/diagrams/chassis_bz4312a2_3d.png`（配置 A，`tools/draw_chassis_iso.py` 產生，PIL 等角投影＋畫家排序；右散熱器與前板線框）。前板電源鈕建議只當低壓觸發接控制板繼電器（docs/14 K_TRIG），不拉市電到前板。**12 V trigger 3.5 mm 母座後板無預鑽孔：**請賣家連同電源座孔一起加開 Ø6–8（依母座螺紋），或自鑽（3 mm 鋁板）；母座買塑膠殼絕緣型，保留 trigger 地是否接訊號地的選擇（docs/14 §6.7 待定）。先不鑽也可用前板按鈕開關機。另比較過睿捷 A4312 拼裝版（¥195≈NT$934，側板平板無散熱器、深 260/320/380）：機殼便宜但散熱器另購 1,000–2,500，合計不比 BZ4312 低；若採用只選 320 深、後級版面板。需求下限 寬 ≥300／深 ≥250／高 ≥90mm（**此三值由 100×90 放大板推導，2026-09-24 放大板已加寬為 115×90，寬度需求要重算**） |
| ~~AC-01 電源入口＋帶燈開關＋保險座~~（**2026-09-29 作廢：BZ4312A2 附帶保險管電源尾插與電源開關**） | [露天](https://www.ruten.com.tw/item/22410919510431/) | 1 | $29 | 安規、極數、接地端、一次側接法、面板尺寸未核；保險絲電流還沒決定 |
| AC105–235V 軟啟動板 | [露天](https://www.ruten.com.tw/item/22546454641812/) | 1 | $660 | 只有標題電壓涵蓋 110V；額定功率、限流電阻、繼電器、失效行為未知，未整合設計 |
| UPC1237 雙聲道喇叭保護板 | [露天](https://www.ruten.com.tw/item/22631277223445/) | 1 | $258 | 賣家公告部分二手以全新欄位上架，要確認本件。需 ±DC 偵測、掉電釋放、**繼電器 DC 分斷能力**、12Vac 繞組容量。「300W×2」是文案不是規格。到貨照 [14 §9](14-V0.4-控制與保護板設計草案.md) 驗證 |
| V0.4 控制板繼電器（K_SPK×2、K_BYP、K_TRIG）、R_s／NTC、7812、小訊號零件 | **2026-10-01 深夜已選型（原理圖 `electrical/control-v01`／`mains-v01`）**：Omron **G2RL-1-E 12VDC ×5**（K_SPK×2、K_BYP、K_TRIG＋1 備；低背 16 A／250 VAC、線圈 33 mA；**PCB V0.6 已照 KiCad 函式庫的 G2RL-1-E 封裝畫**，不要買成 G2R-1-E／G5LE 腳位不同；光華今華、良興或露天約 $60–90）、**UPC1237**（UTC，SIP-8）×2、**Ametherm SL22 10005** NTC（10 Ω／5 A／90 J，腳距 10）×1、光耦 **SFH617A-3**（DIP-4，Vceo 70 V；不可 PC817 35 V；H11D1 是 6 腳與板不合）×2、TL431（TO-92）、BC327-40 ×2、7812、1N4007 ×9（含輔助電源橋 4 顆）、1N4148 ×2、2200µF/25V Ø12.5、47µF/16V、100µF/16V、4.7µF/25V、22µF/25V、10µF/25V（Ø5–6.3），電阻電容值見原理圖 | 1 套 | 繼電器約 $400、其餘約 $200 | 下單前核對：線圈 **12 VDC**、型號尾碼有 **E**（無 E 只有 12 A）。G2RL-1-E DC 額定 30 VDC，故障時 33.5 V／8 Ω 4.5 A 一次性分斷，使用者 2026-10-01 接受（docs/14 §6.3 原要求 ≥36 VDC 市售小繼電器達不到）。SL22 10005 台灣不易買時，找 20 mm 10 Ω、能量 ≥60 J、穩態 ≥3 A 的 NTC 代替。繼電器到貨先量腳位再畫封裝 |
| 電源線 POLYWELL 三腳→IEC C13 3P 10A（BSMI R41048） | [露天](https://www.ruten.com.tw/item/22420549073222/) | 1 | $110–280 | 各長度個別價格頁面沒寫（只標 60cm=$110） |
| PE 接地線 黃綠 UL3135 16AWG | [露天](https://www.ruten.com.tw/item/22623855466302/) | 依機殼 | $115–230／**米** | 單位是每米。UL 字號、絞線股數、耐壓未標 |
| O 型端子 RV2-4／RV2-5 | [露天](https://www.ruten.com.tw/item/22634438104388/) | 數個 | $66–220 | **每規格包裝數量未標**，標「散賣」但沒說最小量 |
| 星形華司（PE 接地選外齒） | [露天](https://www.ruten.com.tw/item/22016439955668/) | 數個 | $8–20／10片 | **厚度與齒數未標** |
| M3 銅柱／螺絲／螺帽 | [露天](https://www.ruten.com.tw/item/22601863290504/) | 三板共 12 支柱 | $25–95 | 長度要等機構定案。銅柱 10 個／包 |
| 16AWG 矽膠線 [黑](https://www.ruten.com.tw/item/22407795970619/)／[紅](https://www.ruten.com.tw/item/22407795970226/) | 同左 | 依機殼 | $35／米 | 長度等機殼排布。**不自動當市電線或 PE 線** |
| 20cm 屏蔽訊號線 | [露天](https://www.ruten.com.tw/item/22325050050240/) | 2 | $8 | 原帶 XH2.54 3P 插頭，現板 J1 是 2P／5.08，**插不上**，要改端接 |
| 護線圈（小孔 4.5–24mm） | [露天](https://www.ruten.com.tw/item/22432293356001/) | 依開孔 | $53–130 | **適用板厚未標，工字型必須問**。電源線入線孔常用 8–12mm |
| 護線圈（大孔 16–35mm） | [露天](https://www.ruten.com.tw/item/22434390764554/) | 依開孔 | $1–4／個 | 板厚與是否單顆出貨未標 |
| KSS 紮線帶 CV-180 | [露天](https://www.ruten.com.tw/item/22323909228462/) | 1 包 | $39／100入 | 規格明確，可直接買 |
| 機腳（鋁 20mm） | [露天](https://www.ruten.com.tw/item/22521589179236/) | 4 | $93 | 配全鋁機箱用；橡膠款見[露天](https://www.ruten.com.tw/item/22636558732515/) $20／4個 |
| 8Ω 假負載（厚膜無感 **5Ω＋3Ω 串聯**） | [露天](https://www.ruten.com.tw/item/22629123836127/) | 各 2 | $159–305 | 該賣場 100W 檔明列 3Ω／5Ω，不必賭備註。**TO-247 的 100W 是貼散熱片的額定，裸裝只有十幾瓦**；要問背板是否與端子導通（共用散熱片會短路）。露天的 RX24 鋁殼是繞線式有電感，不能做高頻驗收 |
| 假負載散熱片（每聲道 ≥40W 連續、附風扇或大面積鋁擠） | 候選待找 | 2 | — | 上一列自己寫了裸裝只有十幾瓦，卻沒列散熱片。兩顆 TO-247 若背板與端子導通，要各自絕緣或分開散熱片。**先前漏列** |

**2.2 小計（粗估）：機殼含散熱器方案約 NT$4,200–5,600**（機殼 ¥408≈$1,960、軟啟動 $660、保護板 $258、假負載 4 顆 $636–1,220、其餘線材五金約 $700–1,500）；若另購鋁擠散熱器再加 $1,000–2,500。全部為頁面顯示價，未問賣家、未含運。

仍未選型、連候選都沒有的：獨立狀態指示燈、絕緣屏障／套管、機殼獨立接地螺栓，以及機殼 PE 接點與整機線束。都要等機殼定案。

---

## 3. 購買順序（有依賴關係，別跳）

1. **等變壓器到貨，量各繞組電流與空載電壓** → 才能定**一次側與次級保險絲額定**、**整流橋規格**、AC 入口。額定靠實測，照商品頁預設值買一定錯。**2026-10-01 已量空載電壓、直流電阻與標籤電流（§1 變壓器列）：197 VA、22V 4.2A×2。保險絲額定已有提案（§2.1 該列），整流橋對 4.2 A 繞組餘裕極大，湧浪與耗熱也核過（§2.1 該列）。**2026-10-01 使用者改選 GBJ2510 直立上板（PCB V0.5.1），要買的是 GBJ2510 ×2＋小散熱片 ×2＋M3 固定件＋保險絲；KBPC2510、M5 固定件、Faston 線三列作廢。**剩下帶載電壓未量，不影響這些採購。**
2. **機殼可先買，不必等變壓器電流量測（2026-09-29 決定）。** 381LX 已實量 Ø35×50，BZ4312A2 內部 330×112×300 對三板核過（寬剩 50、深剩 65）；繞組電流只影響保險絲／橋堆／snubber 與 30 或 40 W 的取捨，散熱器是殼固定的，兩種結果都用同一個殼。**2026-09-29 晚補：V0.4 三板在配置 A 下其實只剩深 7／前排寬 30 mm（早先「寬剩 50、深剩 65」是用 100×90 舊板算的）；已另畫 V0.5 候選（放大板 90×90、電源板 125×130，分支 `v05-layout`，DRC 0），餘裕變成深 22／前排寬 45，對照圖 [chassis_bz4312a2_v05_fit.png](diagrams/chassis_bz4312a2_v05_fit.png)。機殼結論不變、照買。**下單前僅需問客服：①A2 內部尺寸是否 330×112×300（不對才停）②電源座孔規格③加開 trigger 孔。殼到貨後才能定：銅柱長度、線材長度、PE 螺栓位置。**IC 固定方式 2026-09-29 使用者選 B：IC 站直、背板直接貼側牆散熱器（不用 L 型鋁角）。** 須先量 IC 實物：①背板背面到兩排腳各自的距離 ②背板孔中心離腳根高度 ③背板厚度。之後改 `tools/pcb_layout_v04.py`：U1 由 y=14 移到「①−1」約 2–3 mm、C3/C4 與其 VEE/GND 走線轉折點同步上移、移除 TAB=VEE 絲印、封裝外框改為不含背板（否則 DRC 報邊緣間距）；只改 D 板；重跑 build→DRC→verify→render。側牆每側 M3 一孔，高＝8＋1.6＋②；板邊離牆 1 mm，銅柱孔留公差。組裝：板鎖銅柱→IC 隔雲母＋絕緣粒鬆鎖→最後才焊 IC 腳→鎖緊→量背板對機殼 OL。L 型鋁角與 M4 不必買。
3. **機殼定案後** → 才買**散熱器、M3 銅柱長度、線材長度、面板接頭**。買附散熱器與電源座的機殼就不要重複買鋁擠和 AC 入口。
4. 不受上述牽制、隨時可買：紮線帶、機腳、KF301 接頭、排針與跳線帽、RCA／喇叭端子、雲母片、絕緣套、導熱膏（仍要先問清表中的規格）。
5. 保護板與軟啟動要等 12Vac 繞組電流確認、繼電器 DC 分斷能力核完才決定，見 [喇叭保護與啟停設計計畫](13-喇叭保護與啟停設計計畫.md)。

---

## 4. 相容性結論

**所有選料的電壓與功率額定都搭配得上已購變壓器，餘裕充足。** 最壞情境軌電壓為 22×1.10×1.08×√2−1.2 ＝ **±35.8V／軌**（市電 +10%、調整率 +8%、空載）；帶載濾波峰值約 ±28.9V。以 35.8V 核對：主濾波與本地儲能電解 63V（1.76×）、靜音電容與薄膜 100V（2.80×）、整流橋 1000V、喇叭端子與 RUN 跳線需 ≥60V DC（1.68×）、LM3886 總供電 71.5V 對原廠上限 94V（餘裕 24%）——全部通過。洩放 R201／R202 實耗 0.58W 對 2W 額定為 3.4×。增益鏈也對得上：Z10 輸出 2.5Vrms／0dBFS，本機增益約 20.09 倍，40W／8Ω 只需 0.891Vrms，要衰減 8.96dB，Z10 的 R2R 音量衰減得掉（反過來不成立，**原廠最低穩定閉迴路增益是 10**）。

**真正未定的不是選料，是已購件自己的規格：變壓器的 VA 與各繞組電流未知，381LX 的 A052 料號不在現行型錄**（賣場標「200W」不是 VA）。這卡住保險絲額定、整流橋持續電流驗證，以及 2×40W 到底做不做得到（粗估需約 123–145W 持續 AC）。另一個未知是 LM3886T 拆機品若實收為 TF 封裝（背板絕緣），絕緣件、散熱器熱阻與 PCB footprint 全部要重算。以上電壓與功率數字**全部是計算估算，沒有任何一項來自實測**。

**2026-10-01 更新：** 變壓器標籤 22V 4.2A×2＋12V 1A ⇒ **約 197 VA**，兩組 22V 空載各 **22.29 Vac**（§1 該列）。對照上面：①2×40W 粗估需 123–145 W 持續 AC，197 VA 夠；雙聲道 40W／8Ω 正弦滿載每組 22V 繞組約 3.2–3.6 Arms，在 4.2 A 額定內但不寬，聽音樂實際只有幾分之一。②量測時市電 110 V，空載 22.29 V 只比標籤 22 V 高 1.3%，而由直流電阻推估的滿載調整率約 7–8%，所以標籤 22 V 是偏空載的標法。③**最壞情境軌電壓改算為 22.29×1.10×√2−1.2＝±33.5 V**，取代先前的 ±35.8 V（那個數字多乘了一次 +8% 空載調整率，現在空載值是實測的）；110 V 空載直流約 ±30.3 V。所有選料在 ±35.8 V 下已通過，±33.5 V 餘裕只會更大，**結論不變**。④帶載粗估：雙聲道 40W／8Ω 正弦時每組繞組約 3.4 Arms、電壓約掉 1.4 V 到 20.9 V，整流濾波後軌約 ±26.5 V（含紋波谷），扣 LM3886 約 4 V 壓降 ⇒ **連續雙聲道正弦約 30–32 W／8Ω，音樂瞬間（繞組輕載、軌約 ±29 V）40 W 可達**，與一直以來「30–40 W 探索範圍」一致。這一條是電阻推估，要等 docs/04 的帶載量測確認。381LX 已於 2026-09-23 實量確認 A05 殼、LM3886 已確認 T 封裝，這兩個未知已解。

機器可讀資料：[10-planned-parts.json](10-planned-parts.json)、[11-ruten-shopping-links.json](11-ruten-shopping-links.json)。

## 5. 整機預算總覽（2026-09-29）

| 項目 | 金額（NT$） | 狀態 |
|---|---:|---|
| 露天 yosontw 40 件（電阻、電容，含運 $60） | 2,298 | 已付 |
| 環形變壓器（蝦皮，含運） | 1,700 | 已付 |
| LM3886T 拆機品 ×4（露天，含運 $75） | 823 | 已付 |
| **已付小計** | **4,821** | |
| §2.1 必要小件 | 480–1,230 | 電感自繞取低值 |
| §2.2 未定案大件（機殼 BZ4312A2 落地約 2,400–2,600、軟啟動、保護板、假負載、線材五金） | 4,600–6,200 | 等機殼定案 |
| 另購鋁擠散熱器（機殼未附才需要） | 0 或 1,000–2,500 | 看機殼 |
| PCB 製板三塊含運 | 約 1,000–1,500 | **2026-10-08 試印已付 US$12.87**（放大板＋電源板 V0.6.1 各 5 片、1 oz、順豐、券 −$6）；定版重印與 CTRL／MAINS 另計 |
| V0.4 控制板零件 | 未估（數百元等級） | docs/14 仍是草案 |
| **未付小計** | **約 6,100–11,400** | |
| **整機合計** | **約 10,900–16,200** | 典型值約 12,200（機殼附散熱器、電感自繞、假負載 4 顆） |

可省的：假負載 636–1,220 為測試用不裝機，能借就省；機殼附散熱鰭片即免另購鋁擠。每買一項回來更新本表。

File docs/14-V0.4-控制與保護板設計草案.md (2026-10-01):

# 14 V0.4 控制與保護板設計草案

> **狀態（2026-10-01 更新）：原理圖第一版已畫（`electrical/control-v01.kicad_sch` CTRL＋`electrical/mains-v01.kicad_sch` MAINS，生成器 `tools/build_control_board.py`，ERC 0），沒有 PCB、沒有 BOM、沒有量測。** 2026-10-01 的決定：方案 B 自製、核心用 UPC1237 晶片（UTC 型錄 QW-R107-065.B：DC 門檻 +0.62／−0.17 V、AC-off 門檻 0.74 V、pin 8 參考 3.4 V、pin 6 ≤80 mA）、三顆繼電器都用 Omron G2RL-1-E 12VDC（低背 16 A、線圈 33 mA；DC 分斷 30 VDC 等級，§6.3 的 ≥36 VDC 市售小型繼電器達不到，使用者接受；PCB V0.6 `pcb/ctrl-layout-v06`／`mains-layout-v06` 已於同夜畫好，DRC 0）、R_s 用 Ametherm SL22 10005 NTC（10 Ω／5 A／90 J）、**分兩塊板**（CTRL 低壓板靠 RCA 側，MAINS 市電板在另一側）。與 §3 的兩點差異：解除靜音綁在喇叭繼電器（光耦 LED 由繼電器驅動節點供電，不另做 1–2 s 計時，放大板 R8·C8 仍提供 2.2 s 軟上升）；UPC1237 以 +12 V 供電而非型錄 25–60 V，pin 6 經 PNP 推兩顆線圈。元件值全為第一版，§9 式的驗證仍要做。原文（2026-09-22）如下。需求來源是 [13 喇叭保護與啟停設計計畫](13-喇叭保護與啟停設計計畫.md)，本文件不重複那份的「為什麼」。所有數字由 `tools/control_budget.py` 計算，前提列在該腳本開頭。

## 1. 範圍與已做的決定

V0.4 在 V0.3 的兩片放大板＋一片電源板之外，新增**一片控制板（CTRL）**，集中做五件事：12Vac 輔助電源、一次側軟啟動旁通、喇叭 DC 保護與繼電器、兩聲道靜音控制、Z10 12V trigger 聯動。放大板與電源板**不改電路**，只透過既有的 JP1／JP2、J2／J4、J201／J202 相接。

| 決定 | 內容 | 理由 |
|---|---|---|
| 一片控制板 | 保護、軟啟動、trigger 合在一片 | 三者共用 12Vac 輔助電源與時序；分開做要拉三組線 |
| 方案 A／B 未定 | 先買 UPC1237 模組驗證（13 號文件），本文件是**驗證它的規格書**，也是方案 B 的設計輸入 | 不論最後用模組還是自製，介面與時序都一樣 |
| trigger 繼電器由 Z10 12V 直接供電 | 後級關機時沒有待機電源 | 不必做市電側常通電路；代價是受 Z10 trigger 輸出能力限制，見 §6.7 |
| 靜音由控制板接管 | 每聲道獨立開關元件取代 JP1／JP2 跳線 | 兩個 MUTE 節點維持隔離（既有規則） |
| 掉電偵測取樣點 | 12Vac 整流前 | 時序計算見 §6.4，主軌 DC 取樣不合格 |

## 2. 系統方塊

```mermaid
flowchart LR
    Z10[Z10 trigger out<br/>12VDC] --> KT[K_TRIG 一次側繼電器<br/>線圈由 Z10 12V 供電]
    SW[手動總開關] --> OR((OR))
    KT --> OR
    AC[AC 入口／保險絲／主開關] --> OR
    OR --> RS[R_s 軟啟動電阻／NTC]
    RS --> T[T1 環形變壓器]
    KB[K_BYP 旁通繼電器] -. 並聯 R_s .-> RS
    T -- 2×22Vac --> PSU[電源板 V0.3]
    T -- 12Vac --> AUX[CTRL：全橋＋濾波＋7812]
    AUX --> SEQ[CTRL：時序邏輯]
    T -- 12Vac 取樣 --> LOSS[CTRL：掉電偵測]
    LOSS --> SEQ
    PSU --> AMP[放大板 ×2]
    AMP -- TEST OUT L/R --> DCD[CTRL：±DC 偵測]
    DCD --> SEQ
    SEQ --> KB
    SEQ --> MUTE[CTRL：靜音開關 ×2<br/>接 JP1／JP2 位]
    MUTE --> AMP
    SEQ --> KS[K_SPK 喇叭繼電器 ×2]
    AMP --> KS --> SPK[喇叭端子]
    SEQ --> LED[前面板狀態燈]
```

## 3. 啟停時序

| 步驟 | 事件 | 動作 | 時間（自上一步） | 依據 |
|---|---|---|---|---|
| 上電 1 | Z10 開機或手動開關 | K_TRIG 吸合，市電經 R_s 進變壓器 | 0 | — |
| 上電 2 | 12Vac 出現，CTRL 供電建立 | 靜音維持（開關元件不導通）、K_SPK 保持釋放 | <50ms | 上電預設安全態 |
| 上電 3 | 計時到 | K_BYP 吸合，旁通 R_s | **1s** | §6.2：電容 5τ<0.2s，餘裕給磁化 |
| 上電 4 | 主軌穩定 | 解除靜音（開關元件導通，pin 8 經 R8 接 VEE） | 1～2s | R8·C8＝2.2s 軟上升 |
| 上電 5 | DC 偵測無故障 | K_SPK 吸合 | **3～5s** | 13 號文件 P2 |
| 掉電 | 12Vac 消失 | K_SPK 釋放、靜音同時下達 | <60ms | §6.4：軌壓 1s 內仍 >20V |
| 故障 | 任一聲道 |DC| 超過門檻 | K_SPK 釋放、靜音、狀態燈 | <100ms | 13 號文件 P1 |
| 關機 | trigger 消失或開關斷 | K_TRIG／開關斷 → 進入「掉電」 | — | — |

上電步驟 3 先於 4、5：R_s 若在解除靜音後才旁通，放大器已帶負載，一次側電流大於旁通繼電器的湧流餘裕。

## 4. 與現有板的介面

| 訊號 | 從 | 到 | 電氣條件 | 現有接頭 | 備註 |
|---|---|---|---|---|---|
| 12Vac | T1 第三繞組 | CTRL 輔助電源＋掉電取樣 | 12Vac、≥0.25A rms（§6.5） | 新增 CTRL J301（2P／5.08） | 與 22Vac 繞組隔離要先量 |
| 一次側切換 | CTRL K_TRIG／K_BYP 觸點 | AC 入口→變壓器 | AC250V、≥5A、阻性 | 新增 CTRL J302／J303（一次側，間距≥6.4mm） | **市電區**，與低壓區隔離 |
| 靜音 L／R | CTRL 開關元件 | 放大板 JP1／JP2 位 | 開關耐壓 ≥60V、1.3mA；集極→RUN、射極→VEE | 放大板既有 Header2_P2.54 | 兩路獨立，不可共地短接 |
| 輸出 L／R | 放大板 J2／J4 TEST OUT | CTRL K_SPK 常開觸點與 DC 偵測輸入 | ±36V、≥9A DC 分斷 | 放大板既有 Terminal2_P5.08 | 大電流線不走訊號地 |
| 喇叭 L／R | CTRL K_SPK 觸點 | 面板接線柱 | 同上 | 新增 CTRL J304／J305 | 回線直接回放大板 J2.2／J4.2，不經 CTRL 地 |
| trigger | Z10 3.5mm | CTRL K_TRIG 線圈 | 12VDC、≤50mA | 面板 3.5mm 母座 | trigger 地與訊號地是否相接**待定** |
| 狀態燈 | CTRL | 前面板 | 12V 經限流 | 2P | 綠＝運轉、紅＝保護 |

CTRL 的低壓地（輔助電源負端）接電源板 GND 匯流點**一點**，繼電器線圈電流不流經放大板訊號地（13 號文件既有要求）。

## 5. 各區塊要求

**輔助電源**：12Vac → 全橋 → ≥1000µF／25V → 7812（或 LDO）→ 12V 邏輯與線圈。線圈用未穩壓的 ~15V 或穩壓 12V 依繼電器選擇，見 §6.5。

**軟啟動**：一次側串 R_s（線繞電阻或 NTC），K_BYP 於 1s 後旁通。R_s 要在 K_BYP 不吸合時「燒不起來」（§6.2 失效功率 73～155W），因此**線繞電阻方案必須加熱熔斷或以一次側保險絲保護**；NTC 方案能量額定 ≥58J。

**DC 偵測**：每聲道 RC 低通（截止 1～2Hz）後比較 ±門檻 1～2V，正負都要。取樣點在 K_SPK 之前的放大板側，故障時才量得到。

**掉電偵測**：12Vac 整流前取半波，RC 濾波 20～40ms 後判定消失。

**靜音開關**：每聲道 NPN 或光耦，60V 級，見 §6.6。

**繼電器**：K_SPK ×2 DPDT 或 SPST 各一，DC 分斷 ≥36V／≥9A（§6.3）；K_BYP、K_TRIG AC250V／5A。線圈電壓依 §6.5 統一 DC12V。

**Z10 trigger**：見 §6.7。3.5mm 插座極性（tip＝+12V）以 Z10 手冊確認。

## 6. 計算

以下由 `python3 tools/control_budget.py` 產生；改假設後重跑並整段替換。

### 6.1 儲能與未限流湧流

- 每軌 20000µF；標稱軌壓 28.9V 時每軌儲能 8.4J、兩軌 16.7J；高市電空載 35.8V 時兩軌 25.6J。這是軟啟動元件要吸收的能量下限。
- 未限流時充電峰值只受變壓器繞組電阻與整流橋限制。**2026-10-01 實量：22V 繞組 0.25／0.2 Ω，一次側 1.95 Ω 折算到次級（×(22.29/110)²）約 0.08 Ω，次級迴路 R≈0.3 Ω，就是下表第一列**（次級峰值約 100 A、一次側折算約 20 A、約 11×）。情境表（次級側總串聯電阻 R，峰值≈√2×22V／R；一次側折算×0.20）：

| 次級迴路 R | 次級峰值 | 一次側折算峰值 | 對 200VA 一次側額定 1.8A 的倍數 |
|---:|---:|---:|---:|
| 0.3Ω | 104A | 20.7A | 11× |
| 0.5Ω | 62A | 12.4A | 7× |
| 1.0Ω | 31A | 6.2A | 3× |
| 2.0Ω | 16A | 3.1A | 2× |

環形變壓器本身在市電相位不利時的鐵心磁化湧流另計，常見 10～50× 額定，與電容充電湧流疊加。這兩項都會讓 110V／15A 迴路的斷路器或一次側保險絲誤動作，**軟啟動列為必要**。

### 6.2 一次側軟啟動（串聯電阻／NTC＋延遲旁通）

一次側額定電流以賣場 200W 估 1.82A（2026-10-01 標籤 197 VA ⇒ 1.79 A，相符）。串聯電阻 R_s 把一次側峰值壓到 155V／R_s；電阻吸收的能量約等於電容儲能加變壓器損耗，以兩軌儲能 ×1.5 估。旁通前電容經 R_s 折算到次級的等效電阻充電，時間常數 τ = R_s×(22/110)²×C。

| R_s（一次側） | 一次側峰值 | 折算次級 R | τ／軌 | 5τ（充飽） | 吸收能量估 | 建議額定 |
|---:|---:|---:|---:|---:|---:|---|
| 22Ω | 7.1A | 0.88Ω | 18ms | 88ms | 38J | NTC 能量額定 ≥58J 且穩態電流 ≥2.7A；或線繞電阻 ≥10W 脈衝級 |
| 33Ω | 4.7A | 1.32Ω | 26ms | 132ms | 38J | 同上 |
| 47Ω | 3.3A | 1.88Ω | 38ms | 188ms | 38J | 同上 |

- 5τ 都在 0.2s 內，所以旁通延遲 0.5～2s 主要是等變壓器磁化與一次側電流穩定，不是等電容充飽。**建議 1s**。
- 旁通繼電器觸點：AC250V、≥5A、阻性；它切的是穩態一次側電流，不是湧流。
- 只用 NTC 不旁通會持續發熱且熱態阻值隨室溫變，快速關開時 NTC 未冷卻就失去限流。**旁通為必要**。
- 旁通失效模式：繼電器不吸合時 R_s 持續承受一次側電流（22Ω→73W、33Ω→109W、47Ω→155W），必須燒不起來，或以熱熔斷／保險絲保護。

### 6.3 喇叭繼電器 DC 分斷需求

| 軌壓情境 | 8Ω 故障電流 | 4Ω 故障電流 |
|---|---:|---:|
| 標稱 28.9V | 3.61A | 7.23A |
| 高市電空載 35.8V | 4.47A | 8.94A |

選型門檻：**DC 分斷電壓 ≥36V（建議 48VDC 級）、DC 分斷電流 ≥9A（含 4Ω）**，觸點 AgSnO₂／AgNi。標「10A 250VAC」不算，要看廠商曲線裡的 DC 電阻性負載線。兩組觸點串聯給同一聲道可把每觸點分斷電壓減半，值得評估。

### 6.4 掉電時序：軌壓衰減 vs 繼電器釋放

- 靜態每軌負載 ≈ 2×85mA 靜態電流 + 洩放 13mA = 183mA，軌壓衰減率 9.2V/s，從 28.9V 掉到 20V 約 1.0s。
- 12Vac 消失偵測：半波週期 8.3ms，濾波後 20～40ms 內可判定；繼電器釋放 5～15ms。**合計 <60ms，遠小於 1.0s**，所以「從 12Vac 整流前取樣」的關機快斷在時序上成立。
- 若從主軌 DC 取樣，要等軌壓掉到門檻才動作，期間 IC 已進入不對稱供電，這就是 13 號文件禁止的原因。
- 大訊號時每軌電流更大、衰減更快（40W／8Ω 約 2.2A → 110V/s），仍有 0.1s 以上，但靜音應在繼電器釋放同時或之前下達。

### 6.5 12Vac 輔助電源預算

| 負載項（假設） | 電流 |
|---|---:|
| 喇叭繼電器 ×2（DC12V 線圈） | 80mA |
| 軟啟動旁通繼電器 | 40mA |
| 狀態燈與控制邏輯 | 20mA |
| **合計** | **140mA** |

- 全橋整流：標稱峰值 15.6V；高市電空載 18.8V。1000µF 濾波、140mA 時紋波 1.17Vpp，谷值 14.4V，對 7812（需 ≥14V）餘裕 0.4V——足夠但緊，**建議 2200µF**。
- 穩壓器耗散最壞 (18.8−12)×140mA ≈ 0.95W，TO-220 加小散熱片或鎖機殼。
- 12Vac 繞組需求：DC 140mA × 1.6 ≈ 224mA rms，約 2.7VA。**到貨後用已知負載量繞組壓降確認**；12Vac 直入 UPC1237 類模組時，模組自己的整流電容也算在這裡。
- K_TRIG 線圈**不在**這張表，它由 Z10 供電。

### 6.6 既有靜音支路交給控制板

- VEE = −28.9V：I_mute = 1.28mA；−25.0V：1.10mA；−35.8V：1.59mA。全部 ≥0.5mA，符合 TI 要求。
- R8×C8 = 2.2s：解除靜音的軟上升時間常數，與喇叭繼電器 3～5s 延遲相容。
- 控制板取代 JP1／JP2：每聲道各一顆 NPN／光耦，集極接 R8 的 RUN 端、射極接 VEE，耐壓選 60V 級，開關電流僅 1.3mA。**左右兩顆各自獨立，兩個 MUTE 節點仍不相接。** 板上 JP1／JP2 保留為手動測試位。

### 6.7 Z10 12V trigger 直接驅動一次側繼電器

- 拓樸：Z10 trigger out（12VDC）→ 3.5mm 插座 → 串聯二極體（防反接）→ DC12V 繼電器線圈 ‖ 續流二極體 → trigger 地。**線圈電源就是 Z10 的 12V**，後級關機時不需要任何待機電源，符合 01 號文件「不需額外 PCB」的預留。
- 手動總開關與繼電器觸點**並聯**（OR），總開關前另有 AC 入口保險絲與主開關。
- 線圈電流上限取決於 Z10 trigger 輸出能力，**原廠規格未取得**。門檻：線圈 ≤50mA（DC12V、≥240Ω）。若 Z10 只能供 ≤20mA，改成「觸發鎖住」：trigger 只負責吸合，吸合後由 12Vac 輔助電源自保持，trigger 消失時由控制板釋放；這會多一組觸點與一條邏輯。
- 一次側繼電器觸點：AC250V、≥5A、阻性；串在 R_s 之前。

## 7. 繼電器採購篩選清單

拿去對商品頁，**任一項查不到就不買**：

- [ ] 觸點 DC 分斷曲線或明列「≥36VDC／≥9A 阻性」（K_SPK）
- [ ] 觸點材質 AgSnO₂ 或 AgNi（K_SPK）
- [ ] 線圈 DC12V，額定電流有數字（三種繼電器都要，加總回填 §6.5）
- [ ] 線圈在 15～16V 未穩壓下的耐受，或確定用穩壓 12V
- [ ] K_BYP／K_TRIG：AC250V ≥5A 阻性，一次側與線圈間絕緣 ≥2.5kV
- [ ] 腳位圖（PCB 封裝要畫）
- [ ] K_TRIG 線圈 ≥240Ω（§6.7 門檻），等 Z10 trigger 規格確認後才定

## 8. 等變壓器到貨才能定的事

| 待量 | 影響 |
|---|---|
| 12Vac 繞組是否存在、與 22Vac 隔離、空載電壓 | 整個 CTRL 供電方案 |
| 12Vac 帶載壓降（推 VA） | §6.5 是否成立、能不能直入模組 |
| 一次側空載電流、繞組電阻 | §6.1 的 R、R_s 選值 |
| Z10 trigger 輸出電壓／電流（手冊或實測） | §6.7 直驅或鎖住 |
| 主軌實測衰減曲線 | §6.4 驗證 |

**2026-10-01 狀態**（細節在 [00 §1](00-採購總表.md#1-已買)）：12Vac 繞組存在、黃／黃、空載 12.27 V（市電 110 V）；一次側繞組電阻約 1.95 Ω、22V 繞組 0.25／0.2 Ω；**未做：繞組間隔離、12Vac 帶載壓降、一次側空載電流、Z10 trigger、主軌衰減曲線。**

量法：三組繞組逐一空載量 Vrms 與線間隔離（>1MΩ）；12Vac 掛 47Ω／5W 負載（≈0.25A）量壓降；一次側串電流表量空載電流。全部寫回 [00 採購總表](00-採購總表.md) §1 的到貨核對欄與本文件 §6 的假設。

## 9. 方案 A 模組（UPC1237）到貨驗證清單

1. 反推電路圖，確認正負 DC 都偵測、掉電取樣點在 AC 側。
2. 量延遲時間、DC 門檻（正負各一）、掉電釋放時間。
3. 查板上繼電器料號的 DC 分斷規格，對 §6.3。**幾乎一定不合格**，屆時換繼電器或轉方案 B。
4. 量 AC12V 輸入電流，對 §6.5。
5. 模組**沒有**軟啟動與 trigger，這兩塊無論如何要自製或另買。

## 參考

[TI LM3886 SNAS091](https://www.ti.com/lit/ds/symlink/lm3886.pdf) §Mute Function；[13 喇叭保護與啟停設計計畫](13-喇叭保護與啟停設計計畫.md)；[05 內建電源與機構](05-內建電源與機構.md)；[04 上電與驗收](04-上電與驗收.md) §5 啟停測試待依本文件 §3 擴充。

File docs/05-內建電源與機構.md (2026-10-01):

# V0.3 C 方案內建電源與整機規劃

兩顆 LM3886T 構成雙聲道純後級，由 Eversolo DAC-Z10 的可調 RCA 輸出控制音量。兩聲道共用正負主電源，非橋接、非並聯，也非左右獨立的雙單聲道電源。

## 主電源接法

已下單變壓器的賣場規格為 AC110V，兩組獨立 22Vac＋單 12Vac，標示 200W。**2026-10-01 實量（細節與照片在[採購總表 §1](00-採購總表.md#1-已買)）：標籤 22V 4.2A×2＋12V 1A ≈ 197 VA；兩組 22V 空載各 22.29 Vac、DCR 0.25／0.2 Ω；12V 空載 12.27 Vac、0.4 Ω；一次側 DCR 約 1.9–2.0 Ω；兩組 22V 串接 44.6 Vac 同相。線色：一次側 R／B，22V 兩組各為綠／綠與藍／藍，12V 黃／黃；量測時市電 110 V，最壞情境軌電壓改為 ±33.5 V（見採購總表 §4）。**帶載電壓、頻率額定、熱保護仍待確認。兩組主次級保持彼此獨立：

1. 第一組 22Vac 接 J201，經 F201 接 BR1 AC 端。BR1 正端為 VCC，負端為 GND。
2. 第二組 22Vac 接 J202，經 F202 接 BR2 AC 端。BR2 正端為 GND，負端為 VEE。
3. BR1 負端與 BR2 正端於儲能電容匯流點形成 GND。AC 端不預先互連，不可混用單橋中心抽頭接法。
4. C201、C202 正端接 VCC、負端接 GND；C203、C204 正端接 GND、負端接 VEE。每顆 10,000µF／63V，每軌兩顆並聯成 20,000µF。
5. 每軌並聯 100nF／100V 薄膜旁路及 2.2kΩ／2W 洩放電阻。
6. J203 的 1／2／3 接放大板 J5 的 1／2／3，分別為 VCC／GND／VEE。兩份獨立原理圖需實際線束連接。

四顆主電容已購（2026-09-22 到貨）；兩顆整流橋未購。**2026-10-01 使用者定案整流橋改為 GBJ2510 直立裝在電源板上（PCB V0.5.1），金屬背朝板邊鎖小散熱片**，取代 9/24 的 KBPC2510 鎖機殼方案；以實測繞組電阻與額定電流核過：反向峰值約 63 V／1000 V、平均約 2.5 A／25 A、湧浪約 100 A／350 A、滿載每橋耗熱 4–5 W（見採購總表 §2.1）。AC1／AC2／P／N 是原理圖功能端子，尚未指定 footprint。

## 12Vac 與控制

12Vac 優先留給雙聲道喇叭 DC 保護、繼電器及啟停控制，尚未畫成可施工的控制電路。先確認繞組電流，再依模組規格決定 AC12V 直入或整流、濾波、穩壓成 DC12V。整流後不等於 DC12V；空載電壓也需量測。

整機要求正負 DC 故障偵測、開機延遲接通、掉電快速斷開、雙軌監測與過溫控制。兩個 MUTE 節點不直接相接；測試跳線不取代整機自動控制。繼電器須核對實際 DC 斷開能力。

## 電壓與功率估算

依 22Vac 假設估算約 ±30V 等級。高市電 +10%、空載調整率 +8% 情境得到約 ±35.8V，36V 僅用作熱情境，不是保證上限。繞組額定電流未知，不能保證 2×40W。30～40W／8Ω 為探索範圍，最終以削波、雙聲道連續負載及溫升測試定額定。

以下數字由 `python3 tools/mains_budget.py` 計算，**沒有硬體量測**；改動假設後重跑該腳本並更新本節。試算前提：22Vac 視為額定負載電壓（若實際為空載值，下表會高估）；市電 110V／60Hz ±10%，空載調整率假設 +8%；兩組獨立次級各接全橋、DC 串接；四顆 10,000µF／63V，每軌兩顆並聯；導通二極體帶載每顆 1.1V、空載 0.6V，不含線阻、ESR、充電角與變壓器動態下陷。

`Vpeak=√2×Vac−2Vf`；`紋波=Irail/(2×60×0.020)`；`平均值=峰值−紋波/2`。30W、40W 是計算負載，不表示供電一定支持。

| 市電 | 每聲道假設輸出 | 每軌平均電流 | 紋波 | 平均軌電壓 | 谷值 | 谷值減輸出峰值 |
|---|---:|---:|---:|---:|---:|---:|
| −10% | 30W | 1.93A | 0.80Vpp | ±25.40V | ±25.00V | 3.09V |
| −10% | 40W | 2.19A | 0.91Vpp | ±25.34V | ±24.89V | -0.41V |
| 標稱 | 30W | 1.93A | 0.80Vpp | ±28.51V | ±28.11V | 6.20V |
| 標稱 | 40W | 2.20A | 0.92Vpp | ±28.46V | ±28.00V | 2.70V |
| +10% | 30W | 1.93A | 0.80Vpp | ±31.62V | ±31.22V | 9.31V |
| +10% | 40W | 2.20A | 0.92Vpp | ±31.57V | ±31.11V | 5.81V |

若沿用每側 6V 輸出壓降的保守假設，標稱市電下 40W 餘裕不足，低市電連 30W 也不保證。

空載、放電與儲能：+10% 市電、+8% 空載調整率下 `22×1.10×1.08×√2−1.2 = 35.76V／軌`；36V 時每顆 2.2k 洩放電阻耗散 0.589W（候選 2W，仍須機內降額）；每軌 `RC=44.0s`，僅靠洩放電阻從 36V 降至 5V 約 86.9s，**實際斷電後仍要量殘壓**；兩軌 36V 總儲能約 25.92J，浪湧限制需按充電與快速關開情境設計。

還不能定案：變壓器持續供電能力與保險絲額定（等繞組電流、VA、熱與浪湧資料）；電容紋波額定與整流橋散熱（電容 −20% 容差會讓紋波增為 1.25 倍）；12Vac 全橋濾波約 15～16Vdc、空載可能更高，**AC12V 與 DC12V 保護板不得混接**。

[TI LM3886](https://www.ti.com/lit/ds/symlink/lm3886.pdf)、[TI AN-1849](https://www.ti.com/lit/an/snaa057c/snaa057c.pdf)。採購狀態見 [採購總表](00-採購總表.md)。

## 一次側與機構待辦

| 項目 | 現行要求 | 待完成 |
|---|---|---|
| AC 入口、開關、保險絲 | 機內供電 | 額定、分斷能力、隔離與防觸碰 |
| 浪湧限制 | 對應四顆主電容充電 | 冷啟動、快速關開、旁路失效驗證 |
| PE 保護接地 | 機殼專用可靠固定點 | 不經開關、保險絲或音訊地阻抗元件 |
| 散熱器及介面 | 每聲道 ≤0.4°C/W、介面 ≤0.3°C/W 初選 | 核對真實料號、氣流及安裝；T 背板為負電源 |
| 機殼 | 電源、訊號、放大及控制分區 | 依實際尺寸定開孔與固定 |

變壓器中心螺栓不可與機殼形成穿過中心的封閉導電匝。電源／整流充電回路遠離輸入，避免喇叭大電流流經訊號地。[Talema 安裝提醒](https://talema.com/products/toroidal-transformers-open-style/)

本版主次級與放大板可編輯圖已更新；一次側、12Vac 控制與保護仍是功能規劃，不是完整市電施工圖。沒有 PCB、加工圖或實機驗證。[TI 電源設計參考](https://www.ti.com/lit/an/snaa057c/snaa057c.pdf)

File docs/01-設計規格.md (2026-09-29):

# V0.3 設計規格

> V0.3／2026-09-16：採用 C 方案，只有變壓器與 LM3886T 已購；額定電流、保護與實際功率待確認。

本版規劃內建線性電源的純後級，外接 Eversolo DAC-Z10 的 RCA 前級輸出，音量由 Z10 控制。數值分為原廠條件、專案選擇及計算估算；沒有實測性能宣稱。

## 範圍與訊號路徑

左右聲道各一顆 LM3886T，非反相接法。RCA 訊號依序經 2.2µF 薄膜隔直電容、1k 串聯電阻進入正相輸入，22k 提供輸入偏壓回路，插座側另有 1M 洩放。本機由 DAC-Z10 的可調 RCA 輸出驅動；原廠 2.5Vrms／0dBFS 全電平超過本設計滿功率需要，詳見下方〈與 DAC-Z10 的搭配〉。

20k 回授及 1k 回授下臂設定約 21 倍中頻增益。47µF 無極性回授電容使 DC 增益趨近 1，減少 DC 偏移放大。加入輸入 1k／22k 分壓後，中頻整機增益約 20.09 倍；實際結果還包括訊源阻抗、元件誤差與 IC 頻率響應。

輸出腳先接 2.7Ω／2W 與 100nF 串聯的 Zobel 支路，再經 0.7µH 與 10Ω／2W 並聯的隔離網路送往假負載。回授取自電感之前。這些值是本專案的起始選擇，需以 PCB 原型確認高頻穩定度。

## IC 腳位與靜音

| 腳位 | 網路／用途 |
|---|---|
| 1、5 | VCC，兩腳都接正電源；符號中重疊顯示 |
| 2、6、11 | NC，不接線 |
| 3 | 功率輸出，接回授及輸出網路 |
| 4 | VEE，負電源 |
| 7 | GND，電源中點／訊號參考 |
| 8 | 各聲道 MUTE 節點 |
| 9、10 | 反相、正相輸入 |

來源：[TI SNAS091C，圖 1–2、Application Information](https://www.ti.com/lit/ds/symlink/lm3886.pdf)。原廠最低穩定閉迴路增益為 10；不能單純調低回授比來配合大輸出 DAC。

每聲道 pin 8 → 22k → RUN 跳線 → VEE。跳線開路時靜音，閉合後由負電源汲取電流解除靜音。100µF 靜音電容正端接 GND、負端接 MUTE。原廠要求解除靜音電流超過 0.5mA；±20V 至 ±36V 的本版計算約 0.79–1.52mA，詳見估算報告。

`22k × 100µF = 2.2s` 只是元件 RC 時間常數，**不等於固定的開機或關機靜音時間**。啟停行為受 pin 8 內部電路與電源變化影響，待量測。JP1／JP2 可於下一版改成額定足夠的雙極開關；兩個 MUTE 節點不直接相接。接點開路時可能承受接近 36V DC，建議選 ≥60V DC 額定。

## 電源與接地

J5 依序為 1=VCC、2=GND、3=VEE；這是正、零、負三線電源，不可把單顆 70V 電源的兩端直接當作本機雙電源。

成機採已訂 AC110V、兩組獨立 22Vac 加一組 12Vac 變壓器。兩組主次級各接一橋，DC 輸出串聯形成正負電源，每軌 20,000µF（10,000µF／63V ×2）。J203 的 1／2／3 接放大板 J5 的 VCC／GND／VEE。供電約 ±30V 等級，實際帶載與空載電壓待測；36V 只是假設情境。詳見[內建電源規劃](05-內建電源與機構.md)。±20V 限流實驗電源只用於板級初測。

每聲道正負軌各有 100nF 及 470µF／63V 去耦；470µF 只負責本地儲能，不替代整機電源濾波。負電源的 470µF 正端接 GND、負端接 VEE。

原理圖上的 GND 為相同電氣網路，但 PCB 必須分開安排輸入、回授、Zobel、喇叭回流至合適匯流點，避免大電流流經輸入地線。100nF 去耦與 Zobel 靠近 IC；輸入接線遠離電源及喇叭線。以上佈線原則參照 [TI datasheet 的 Layout, Ground Loops and Stability](https://www.ti.com/lit/ds/symlink/lm3886.pdf)。

## 散熱與保護邊界

選 LM3886T 非絕緣封裝；金屬背板為 VEE，安裝到接地散熱器／機殼時需合適的絕緣介面與螺絲絕緣套。不可把 LM3886TF 的熱阻當成 T 封裝相同；若改料必須重算。[TI 封裝說明，圖 2 註 1](https://www.ti.com/lit/ds/symlink/lm3886.pdf)

散熱初選每聲道 ≤0.4°C/W、絕緣介面 ≤0.3°C/W，兩者都是選型條件。估算對象為 8Ω 電阻及機內 40°C 環境；真實喇叭阻抗與相角可能加重熱負擔。詳見[計算](02-功率與散熱估算.md)。

放大板有 IC 內建保護與手動靜音；V0.3 電源次級圖加入整流、儲能、洩放及未定額定值的次級保險絲位置。一次側保險絲與浪湧控制、單軌掉電監測、喇叭 DC 偵測及輸出繼電器尚未完成。上電使用受限流保護的實驗電源與假負載。後續喇叭保護需驗證正負 DC 故障、繼電器 DC 斷開能力、延遲接通與快速斷開；不能以靜音功能替代。

## 與 DAC-Z10 的搭配

訊號路徑為 Z10 左右 **RCA 前級輸出 → 本後級 → 喇叭**；Z10 具 R2R 音量控制與前級功能，本後級是固定增益，沒有音量旋鈕。原廠列出 RCA 輸出為 **2.5Vrms／0dBFS**。[Eversolo 官方產品規格](https://www.eversolo.com/en/products/dac-z10)

| 項目 | 初步結果 |
|---|---:|
| 40W／8Ω 所需後級輸入 | 約 0.891Vrms |
| 2.5Vrms 降至 40W 所需輸入的電壓衰減 | 約 8.96dB |
| 後級中頻輸入阻抗 | 約 22.48kΩ；1M 與 23k 並聯的估算 |

衰減量由 `20log10(2.5/0.891)` 推算，假設 0dBFS 及原廠標準輸出條件，不是經校正的面板音量位置。**2.5Vrms 全電平直接送入會要求後級超出目前輸出目標**，必須使用 Z10 的可調前級輸出、關閉音量直通（volume passthrough）。原型先在假負載上以已知測試訊號確認音量位置、輸出電壓與削波點，再設定音量上限。

未取得 RCA 輸出阻抗的原廠數值，不填入電路計算；接入約 22.48kΩ 負載後的增益與頻響以實測確認。

**12V Trigger 聯動（V0.4 預留）：** Z10 背板 3.5mm trigger out 開機送 12V DC，可驅動一顆小型 DC 繼電器切通後級一次側市電，實現 Z10 開機→後級自動跟隨。手動總開關仍保留。此功能預計與喇叭保護電路一併設計，不需額外 PCB。

## 目標喇叭：Usher（亞瑟）Be-718 與功率匹配（2026-09-29）

使用者 2026-09-29 告知目標喇叭為 Usher Be-718（Tiny Dancer，兩音路書架、7 吋紙盆低音＋1.25 吋鈹高音、背反射式）。以下規格分「原廠標示」與「第三方實測」，匹配結論全部是計算，沒有接上實機量過。

| 項目 | 原廠標示 | 第三方實測 |
|---|---|---|
| 標稱阻抗 | 8Ω | Stereophile：低音與中音全程 >6Ω，只在高音區短暫低於 6Ω；最難點 2.5kHz 5.7Ω／−41°。Sound & Vision：最低 5.16Ω @2.8kHz，最大相角 −61° @78Hz |
| 靈敏度 | 87dB/W/m | Stereophile 估 85dB(B)/2.83V/m（比標示低約 2dB） |
| 建議功率 | 80–200W | — |
| 頻率響應 | 42Hz–35kHz ±3dB，分頻 2.06kHz | — |

**本機能給的（±30V 軌、每側預留 6V 壓降 → 峰值 24V；全為估算，見 [02](02-功率與散熱估算.md)）：**

| 負載 | 峰值電流 | 功率上界／聲道 | IC 最大耗散 ±30V／±36V | 估計 Tj（θ 合計 1.8°C/W、機內 40°C） |
|---|---:|---:|---:|---:|
| 8Ω（標稱） | 3.0A | 36W | 27.9W／38.9W | 90°C／110°C |
| 6Ω（低中音區實測下限） | 4.0A | 48W | 35.5W／49.9W | 104°C／130°C |
| 5.16Ω（高音區最低點，功率很小，不構成熱負擔） | 4.7A | — | — | — |

**音量（靈敏度取實測 85dB/2.83V/m，兩聲道同放 +3dB，聽音距離 2.5m 自由場 −8dB、一般房間再 +3dB）：**

| 每聲道輸出 | 單顆 1m | 一對、2.5m 房間內 |
|---|---:|---:|
| 1W | 85dB | 約 83dB |
| 10W | 95dB | 約 93dB |
| 36W（削波前） | 100.6dB | 約 98–99dB |

**結論：**

1. **阻抗與電流沒有問題。** 低音、中音全程在 6Ω 以上，峰值電流 ≤4.7A，遠低於 LM3886 的 11.5A 峰值限制；−61° 相角出現在 78Hz，會讓 IC 耗散略高於純電阻估算，但仍在 8Ω 與 6Ω 兩列之間。
2. **散熱在 ±30V 可以，市電偏高（±36V）連續推 6Ω 正弦會超過 125°C。** 這是最壞情境（連續正弦、耗散最大的中等輸出），聽音樂的平均功率遠低於此；但機殼散熱器 0.5°C/W 只是估值，**上電後一定要在 6Ω 假負載、約 1/3 功率下實測背板溫度**。
3. **音量是唯一偏緊的地方。** 原廠建議 80–200W，本機約 36W，比建議下限少 3.5dB。一對喇叭在 2.5m 的房間裡，削波前峰值約 98–99dB：一般到偏大聲的聆聽（平均 75–85dB、峰值 +15dB）夠用；大房間、離很遠、或愛開大聲聽動態大的音樂，會先碰到削波，不會壞喇叭也不會壞機（LM3886 有 SPiKe 保護），只是音量到頂。
4. **要更大聲只有換更高軌壓與更大變壓器**，不是改板；本變壓器 2×22Vac 的 VA 與繞組電流未量，先量完再談 40W 能不能連續。

來源：[Stereophile 規格頁](https://www.stereophile.com/content/usher-audio-technology-be-718-loudspeaker-specifications)、[Stereophile 量測頁](https://www.stereophile.com/content/usher-audio-technology-be-718-loudspeaker-measurements)、[Sound & Vision HT Labs 量測](https://www.soundandvision.com/content/usher-be-718-speaker-system-ht-labs-measures)，查閱日期 2026-09-29。

## 原廠參考

- [LM3886 datasheet SNAS091C](https://www.ti.com/lit/ds/symlink/lm3886.pdf)：腳位、電路拓樸、靜音、供電、熱阻與佈線。
- [LM3886 產品頁](https://www.ti.com/product/LM3886)：50W／8Ω／±35V 的元件條件，查閱日期 2026-09-11。

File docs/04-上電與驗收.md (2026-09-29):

# 原型上電與驗收

> V0.3／2026-09-16：採用 C 方案，只有變壓器與 LM3886T 已購；額定電流、保護與實際功率待確認。

本文件是未來硬體測試計畫；目前沒有焊接成品或量測結果。所有門檻是專案驗收條件，不是原廠保證。先完成單聲道，再複製第二聲道。

成機採內建電源；下列 ±20V 初測及接近實際工作電壓的實驗電源步驟是放大板獨立測試。內建市電供電須先完成一次側、浪湧及保護設計，按文末新增流程驗證後再接放大板。

## 0. 裸 IC 到貨檢測（2026-09-29 新增）

LM3886T 為二手拆機品（實收 4 顆，見 [00 §1.1](00-採購總表.md)），焊上板前先分兩關篩：

**0.1 不通電，三用電表二極體檔。** IC 正面朝自己、腳朝下，最左為 pin 1；用到 1／5（V+）、4（V−，與背板同點）、3（輸出）、7（GND）、9／10（−IN／+IN）。每組紅黑對調各量一次，四顆都量，抄成表：

| 測點 | 預期 | 判定為壞 |
|---|---|---|
| 背板 ↔ 4 | 雙向 ≈0 | 不通：背板斷或非 T 封裝 |
| 1 ↔ 5 | 雙向 ≈0 | 不通：內部斷線 |
| 1 ↔ 4 | 單向數百 mV、反向 OL | **雙向 ≈0：電源短路** |
| 3 ↔ 1、3 ↔ 4 | 單向有讀數、反向 OL | **≈0：輸出級燒毀（最常見）** |
| 10 ↔ 7、9 ↔ 7 | 雙向 OL 或很高 | ≈0：輸入級擊穿 |

判斷以**四顆互比**為主，不以絕對數字為準；同組讀數明顯不同者列為可疑。通過只代表未燒成短路，不代表可正常工作。

**0.2 通電靜態測試。** 即 §2 的做法：±20V、每軌限流 0.2A、輸入短接至 GND、不接負載、背板墊絕緣鎖小散熱片。合格：每軌約 30–60 mA 且四顆接近、輸出 DC 數十 mV 內、只微溫。拉到限流、輸出 DC 貼近任一軌、或快速發熱即判死片。需要能接線的載體：V0.4 放大板，或萬用板最簡測試電路（視退貨期限決定）。

**0.3** 增益與聽感測試見 §3 以後。第 1 顆（打標磨損者）在 0.1／0.2 未通過前一律不裝機。

## 1. 斷電檢查

確認實際 IC pin 1、5 都接 VCC，pin 4 接 VEE、pin 7 接 GND，2／6／11 不接。核對 C6／C106 與 C8／C108 的正端都在 GND；C2／C102 為無極性電容。檢查 IC 背板至散熱器的絕緣與機構固定，安裝散熱器後才上電。量測兩軌對地及彼此之間無短路，等待電容充放電讀值穩定。

## 2. 低電壓靜態測試

使用追蹤且可同步啟停的外接 ±20V 實驗電源，單聲道每軌限流先設約 0.2A。RUN 跳線先拔除，輸入短接至訊號 GND，輸出不接喇叭。

上電記錄正負電壓、每軌電流、輸出 DC、MUTE 腳電壓及散熱器溫度。若供電持續限流、只剩單軌、輸出 DC 過大或快速發熱，立即斷電排查，不直接調高限流。

接上 8Ω 假負載後再解除靜音，觀察輸出 DC。暫定 |DC| ≤50mV 為繼續條件，若超過 100mV 停止；中間區間先查輸入與回授偏壓。拔除 RUN 跳線不代表瞬間靜音：觀察實際延遲及瞬態。

## 3. 小訊號與高頻檢查

先用 1kHz 小正弦，輸入約 50mVrms，在 ±20V 下量測約 1Vrms 輸出；核對左右相位及約 20 倍增益。示波器接地夾只接 GND，不接負電源。觀察放大器 pin 3 與負載端是否有高頻振盪，使用短接地彈簧。

在約 1W 輸出下掃描 20Hz–20kHz，以 1kHz 正規化，暫定 ±0.5dB 為目標。使用小幅度方波檢查過衝及振鈴；本版只先驗證短線 8Ω 電阻負載，容性／實際喇叭負載另列測試，不直接接大電容。

## 4. 工作電源與功率探索

通過前項後，關機、確認電容放電，再設定接近預期帶載值的 ±28V；之後只在實際電源與散熱允許範圍內逐步調整，不直接套用舊版 ±35V。以足夠電流能力的電源及按額定散熱的假負載，逐步增加訊號；確認兩軌不明顯下陷、限流或失衡。

| 階段 | 每聲道負載電壓 | 每聲道功率 | 驗收重點 |
|---|---:|---:|---|
| 小訊號 | 2.83Vrms | 1W／8Ω | 增益、噪聲及頻率響應 |
| 初步探索 | 15.49Vrms | 30W／8Ω | 先單聲道，再雙聲道；出現削波或過熱即降低目標，1kHz THD+N ≤0.1% 為量測目標 |
| 上限探索 | 17.89Vrms | 40W／8Ω，非必達 | 記錄失真、削波、電源電壓與溫度，未達成則保留較低額定 |

`P = Vrms² / 8Ω`，使用實際量得的負載阻值修正。示波器無明顯削波只能證明波形觀察通過，不能證明 THD+N 合格。音訊分析器或經校正的衰減量測前端需有足夠輸入量程；不可把功率輸出直接送進一般音效卡輸入。

## 5. 熱測試與啟停

先逐步熱測，約每五分鐘記錄一次機內環境、散熱器、IC 外殼及電源情況；至少觀察 30 分鐘並確認趨於穩態。每軌 28～30V 下理想熱模型的高耗散區約為每聲道 20～23W，應測試該區，也測實際可達的雙聲道削波點以下輸出。出現保護、持續升溫或估算接面接近 125°C 即停止並重估散熱。

先把輸入降至零，開路 RUN，再觀察靜音完成後關閉雙軌。未完成自動電源監測前，不把手動順序當整機啟停保護。記錄正常啟停與靜音瞬態；單軌異常的受控故障測試留給保護電路完成後的階段。

## 6. 接喇叭前

完成 DC 偵測／輸出繼電器、開關機延遲與電源異常斷開驗證，再用可承擔風險的測試喇叭低音量聆聽。比較 TPA3255／Purifi 時須匹配負載端音量、相同訊源及量測條件，避免把音量差當音質差。

## 量測紀錄欄位

日期、硬體版本、IC／電源／散熱器型號、實測負載阻值、機內環境溫度、供電空載／負載值、輸入與輸出 Vrms、失真量測方法／頻寬、各軌電流、輸出 DC、溫度時間序列及異常波形。保留原始資料，不用計算值填入實測欄。

## 內建電源整合階段

一次側與機構防護完成並核對後，先讓電源獨立工作，檢查兩個次級確實隔離、雙橋極性及儲能中點。確認 PE 對機殼連續性與一次／二次側絕緣；這些檢查不由 KiCad ERC 取代。

測量空載及不同負載的正負軌，記錄 AC 輸入、紋波、最高峰值與最低谷值。把實際一次側額定電壓、空載調整率與電容容差帶回 `mains_budget.py`；若超出 ±36V 評估範圍，不直接接上放大板。

以合適的隔離測試設備驗證冷開機、快速關開、浪湧旁路失敗、過溫及掉電控制。確認斷電時先靜音並斷開喇叭，而不是等待大電容自然放完；放電完成須直接量測，不靠電源指示燈判斷。

通過後才以內建供電做雙聲道功率及熱測，量測中等輸出耗散區與接近削波區；若實際電源負載電壓低於實驗電源條件，依 THD+N、溫度與電壓重新定額定功率。最後接上現有 DAC 與前級，從前級最低音量開始核對增益、嗡聲與啟停聲。

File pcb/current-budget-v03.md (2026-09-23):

# PCB V0.3 銅箔計算表（程式輸出）

由 `tools/analyze_pcb_v03.py` 依 PCB 走線資料計算。完整假設與限制見 [PCB V0.3 說明](README.md)。

以下採名義 1 oz 銅厚 0.0348 mm、假設銅溫 25°C。電流情境為 40W／8Ω；充電列另採 15% 導通占空比矩形脈衝假設。

| 路徑 | RMS A | V0.2 電阻 mΩ | V0.3 電阻 mΩ | V0.3 峰值壓降 mV | V0.3 發熱 W |
|---|---:|---:|---:|---:|---:|
| IC 輸出至 L1 | 2.236 | 20.93 | 9.25 | 29.2 | 0.046 |
| L1 至喇叭端子 | 2.236 | 2.69 | 1.79 | 5.7 | 0.009 |
| 喇叭回地至匯流區 | 2.236 | 10.67 | 7.11 | 22.5 | 0.036 |
| 放大板匯流區至電源地 | 2.236 | 6.68 | 4.45 | 14.1 | 0.022 |
| 正電源端子至 U1.1 | 1.637 | 24.62 | 17.70 | 57.5 | 0.047 |
| 正電源端子至 U1.5 | 1.637 | 33.41 | 22.98 | 74.6 | 0.062 |
| 負電源端子至 U1.4 | 1.637 | 30.33 | 26.77 | 86.9 | 0.072 |
| 共用電源正軌輸出 | 3.273 | 9.39 | 7.04 | 45.7 | 0.075 |
| 共用電源負軌輸出 | 3.273 | 9.33 | 6.99 | 45.4 | 0.075 |
| 共用電源輸出地 | 4.472 | 6.68 | 5.01 | 31.7 | 0.100 |
| 正橋至第一顆濾波電容 | 5.637 | 5.60 | 6.59 | 95.9 | 0.209 |
| 正橋充電回地 | 5.637 | 6.19 | 6.79 | 98.8 | 0.216 |
| 正 AC 端子至保險絲 | 5.637 | 4.89 | 2.44 | 35.5 | 0.078 |
| 正保險絲至整流橋 | 5.637 | 12.21 | 6.11 | 88.9 | 0.194 |
| 正 AC 回線 | 5.637 | 8.57 | 2.77 | 40.3 | 0.088 |
| 負橋至第一顆濾波電容 | 5.637 | 6.16 | 6.77 | 98.5 | 0.215 |
| 負橋充電回地 | 5.637 | 5.59 | 6.59 | 96.0 | 0.209 |
| 負 AC 端子至保險絲 | 5.637 | 4.89 | 2.44 | 35.5 | 0.078 |
| 負保險絲至整流橋 | 5.637 | 12.21 | 6.11 | 88.9 | 0.194 |
| 負 AC 回線 | 5.637 | 8.57 | 2.77 | 40.3 | 0.088 |

2 oz 模型的電阻／壓降／發熱均為表中一半；假設銅溫 85°C 時，三者為 25°C 的 1.234 倍。這不是預測溫升。

各列情境不代表同時可達成，不能把所有列發熱相加當整板結果。未計入零件、導線、接頭、焊接接觸、孔壁或高頻阻抗。

| 去耦外部銅箔長度指標 | V0.2 mm | V0.3 mm |
|---|---:|---:|
| C3→U1.1 | 110.6 | 32.8 |
| C3→U1.5 | 121.4 | 43.6 |
| C4→U1.4 | 147.2 | 50.2 |

指標為電源腳至電容電源端，加電容地端至 U1.7 的中心線最短路徑。不是完整開關電流回路、迴路面積或電感模型。

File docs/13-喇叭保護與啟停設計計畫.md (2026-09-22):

# 13 喇叭保護與啟停設計計畫（V0.4）

> **設計計畫，不是已完成設計，也沒有任何硬體量測。** 架構、時序、介面與計算的設計草案見 [14 V0.4 控制與保護板設計草案](14-V0.4-控制與保護板設計草案.md)（2026-09-22）；原理圖與 PCB 仍未開始。

## 為什麼要做

LM3886 輸出級失效時 pin 3 會被拉到接近 VCC 或 VEE（±30V 等級），該電壓直接加在喇叭音圈上。IC 內建的 SPiKe 保護的是 IC 自己，不保護喇叭。本機現有的 pin 8 靜音支路（R8/22k＋JP1＋C8/100µF）是**板級測試跳線**，IC 已失效時無法切斷輸出。這是本機與成品後級之間唯一有實質安全風險的缺口。

## 必須設計的功能

| # | 功能 | 必要性 | 要求 |
|---|---|---|---|
| P1 | ±DC 偵測 | 必要 | 正負兩方向都要偵測，單向不合格。門檻典型 ±1～2VDC |
| P2 | 開機延遲接通 | 必要 | 電源建立、DC 穩定後才接通喇叭，典型 2～5 秒 |
| P3 | 關機快速斷開 | 必要 | **從 12Vac 繞組整流前取樣**；市電斷開時 12Vac 立即消失，主電容的 ±30V 還能撐數百毫秒到數秒，這個時間差就是安全窗口。不可從整流後 DC 取樣 |
| P4 | 繼電器 DC 分斷能力 | 必要 | 見下節，最容易選錯 |
| P5 | 單軌掉電偵測 | 建議 | 一軌保險絲熔斷時，另一軌會把輸出推向該極性 |
| P6 | 過溫偵測 | 選配 | LM3886 有內建熱關斷，優先度低 |
| P7 | 一次側軟啟動 | 必要 | 每軌 20,000µF、合計 40,000µF，上電湧流可達數十安培，會打跳斷路器。標準做法是一次側串 NTC 或功率電阻，延遲 0.5～2 秒後以繼電器旁通 |

啟停時序：上電＝軟啟動旁通 → 電源穩定 → 解除 MUTE → 延遲 → 繼電器接通喇叭；掉電＝偵測 12Vac 消失 → 立即斷開繼電器；故障＝偵測 DC → 立即斷開繼電器。**兩個 MUTE 節點不得直接相接**（既有規則），控制電路要維持這個隔離。

## 繼電器選型：交流額定不等於直流額定

標示「10A 250VAC / 10A 30VDC」的繼電器，實際工況是切斷帶著 ±30V DC、流過低阻抗喇叭的電路。直流沒有過零點，拉弧不會自行熄滅，觸點可能燒黏而失去保護作用。

| 項目 | 要求 |
|---|---|
| DC 分斷電壓 | ≥ 軌壓（±30V 等級 → 至少 30VDC，建議 48VDC 以上） |
| DC 分斷電流 | 軌壓 ÷ 喇叭阻抗：±30V／8Ω ≈ 3.75A；4Ω ≈ 7.5A |
| 觸點材質 | AgSnO₂ 或 AgNi，避免純銀 |
| 接點形式 | 雙刀（DPDT），左右聲道各一組。部分設計把兩組觸點串聯給同一聲道以分擔拉弧電壓，成本翻倍但安全性顯著提升，值得評估 |
| 線圈電壓 | 配合 12Vac 整流後約 15～16Vdc → 選 DC12V 線圈，須確認 16V 下耐受，或加穩壓 |

## 目前的決策狀態

- **方案 A（現成 UPC1237 模組，$258）**：AC12–18V 直入、約 3 秒延遲、約 1VDC 起控。便宜成熟，但賣家公告部分二手以全新欄位上架，「300W×2」是文案不是規格，**板上繼電器的 DC 分斷能力通常沒標**。
- **方案 B（自製保護板）**：電路全透明、繼電器可自選，代價是多一輪 PCB 打樣與除錯。
- **目前傾向**：先買一片方案 A **作為驗證與學習用，不直接裝進成機**；到貨後反推電路圖、實測延遲與 DC 門檻、查繼電器料號的 DC 分斷規格。不合格（極可能）就換繼電器或轉方案 B。**成機用哪一版尚未決定。**
- ⚠️ **12Vac 繞組電流容量確認前，不得下單保護板。** 賣場標「200W」是整顆變壓器的宣稱值，不是該繞組的配額。

## 未決事項

| 項目 | 狀態 |
|---|---|
| 12Vac 繞組是否真實存在、線色、空載電壓、是否與 22Vac 獨立 | **未確認**，變壓器未到貨。到貨用萬用表逐項量 |
| 12Vac 可供電流 | **未確認**，無法直接量測，需查廠商或以已知負載測壓降。粗估需求：兩顆 DC12V 繼電器線圈約 80mA＋控制電路，合計 150mA 以內（估算，非量測） |
| UPC1237 模組是否二手、電路是否完整 | **未確認** |
| 繼電器 DC 分斷能力與料號 | **未選型** |
| 一次側 NTC 常溫阻值／額定電流／能量額定、旁通繼電器、延遲時間、慢熔保險絲額定 | **未設計**，保險絲額定要等整機功率確認 |
| 保護板機構配置與機殼空間 | **未規劃**，機殼尚未選定 |
| 保護板對訊號地的影響 | **未評估**，繼電器線圈電流不得流經訊號地 |
| Z10 12V trigger 聯動 | **V0.4 預留**，3.5mm trigger in → 小繼電器切一次側市電，與保護板一併設計 |

⚠️ 一次側是市電電路，涉及觸電與火災風險，必須有適當絕緣距離、線徑與保護接地；**PE 的機殼連接不可由訊號 GND 替代**（見 [01 設計規格](01-設計規格.md)）。

驗收方法（未來實機，全部在假負載上做，不接真實喇叭）：開機延遲看觸點接通時 DC 是否已在門檻內；正負 DC 故障各以電阻從 VCC／VEE 注入輸出節點；掉電時觸點須先斷、輸出後衰減；拆一軌保險絲模擬單軌掉電；播大動態低頻至接近削波確認不誤動作。DC 注入會讓 IC 承受異常工況，**等 IC 到貨且有備品再做**，或先以訊號產生器模擬偵測節點電壓。整合進 [04 上電與驗收](04-上電與驗收.md)。

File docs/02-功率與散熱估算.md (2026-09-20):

# 功率、供電與散熱估算

由 `python3 tools/power_budget.py` 產生。這是理想線性電路與 class-B 能量模型，不是 LM3886 SPICE 模擬或實測。

## 計算假設

- 負載為 8Ω 電阻，兩聲道相同。以每軌 28V、30V 與 36V 情境估算；36V 只是高市電空載假設的進位值，不是保證上限。
- 每顆 IC 靜態電流採 85mA 作估算；原廠測試條件主要為 ±28V，外推到本設計電壓仍需實測。
- LM3886T 的 θJC 採 1°C/W；絕緣介面 θCS=0.3°C/W、每顆獨立散熱器 θSA=0.4°C/W 為選型假設。
- 環境為機內 40°C，設計接面溫度目標低於 125°C；不把熱保護作正常工作點。
- 功率餘裕試算預留每側 6V 輸出壓降；此為專案假設，不能套用小電流 dropout 規格來保證大功率輸出。

來源：[TI LM3886 datasheet，Electrical Characteristics／熱設計](https://www.ti.com/lit/ds/symlink/lm3886.pdf)。

## 增益與低頻

- IC 中頻閉迴路增益：1+20k/1k = 21 V/V。含輸入 1k 串阻與 22k 負載：20.087 V/V（26.06dB）。
- 輸入隔直轉折估算：1/[2π×(1k+22k)×2.2µF] = 3.15Hz。
- 回授下臂轉折：1/(2π×1k×47µF) = 3.39Hz，DC 增益趨近 1。
- 理想網路 20Hz 相對 1kHz：-0.228dB；未含 IC 頻寬、訊源阻抗與輸出網路。

## 每聲道輸出需求

| 功率／8Ω | 輸出 Vrms | 輸出 Vpeak | 負載 Ipeak | 輸入 Vrms，按中頻增益 |
|---|---:|---:|---:|---:|
| 1W | 2.828V | 4.000V | 0.500A | 0.141V |
| 30W | 15.492V | 21.909V | 2.739A | 0.771V |
| 40W | 17.889V | 25.298V | 3.162A | 0.891V |

## 供電與耗散

`Pdc = 2 × Vrail × Vpeak / (π × Rload) + 2 × Vrail × Iq`；`Pd = Pdc − Pout`。雙聲道總功率乘 2。

| 每側電源 | 6V 壓降假設下功率上界／聲道 | 30W 試算時雙聲道 DC 需求 | 30W 試算時每軌平均電流 | 最大耗散／顆 | 最大耗散對應輸出／聲道 | 估計 Tj |
|---|---:|---:|---:|---:|---:|---:|
| ±28V | 30.25W | 107.15W | 1.91A | 24.62W | 19.86W | 81.9°C |
| ±30V | 36.00W | 114.81W | 1.91A | 27.90W | 22.80W | 87.4°C |
| ±36V | 56.25W | 137.77W | 1.91A | 38.95W | 32.83W | 106.2°C |

上表的功率上界是電壓幾何估算，不包含限流、SPiKe、失真或電源下陷，不能當額定輸出。

`Pd,max = 2 × Vrail² / (π² × Rload) + 2 × Vrail × Iq`。耗散最大時的輸出功率不是滿功率；因此必須測試中等輸出。

獨立散熱器：`Tj = Ta + Pd × (θJC + θCS + θSA)`。若兩顆共用散熱器，應改成 `Tj = Ta + 2×Pd×θSA,shared + Pd×(θJC+θCS)`；同等條件需共用散熱器約 ≤0.20°C/W。

保留原有低熱阻散熱選型，仍須核對實際介面、通風及真實喇叭相角；空載上界不代表帶載可維持同樣電壓。

2×40W 同相正弦的每軌訊號峰值約 6.32A，另有靜態電流。已訂 2×22Vac 變壓器的 VA 與繞組電流未知，不宣稱連續 DC 能力；詳見[內建電源](05-內建電源與機構.md)。

## 靜音電流

依原廠近似關係：`I8 = (|VEE| − 2.6V) / 22kΩ`。電阻功耗為 `(VEE_abs−2.6)²/22k`，未含瞬態。

| 負電源 | 解除靜音電流估算 | 22k 穩態耗散 |
|---|---:|---:|
| −20V | 0.791mA | 13.76mW |
| −28V | 1.155mA | 29.33mW |
| −30V | 1.245mA | 34.13mW |
| −36V | 1.518mA | 50.71mW |

採 0.25W、1% 電阻。22k×100µF=2.2s 是 RC 常數，實際解除／進入靜音時刻仍需量測。

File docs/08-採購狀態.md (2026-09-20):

# 採購狀態

> 採購資訊的單一入口是 [00 採購總表](00-採購總表.md)；本頁為其附錄，保留設計需求與原始判斷依據。

[露天商品連結與缺項表](11-露天購物連結.md)（2026-09-18）：原清單15項＋新增23項商品；候選未購，保險絲／散熱／保護控制尚未定案。

**2026-09-20 下單：**使用者已在露天 yosontw 結帳一單（訂單 26092068825254，40 件 $2,238＋運 $60）：全部電阻（PR02／RNU2／MRS25）、WIMA MKS4／MKS2、CDE 361R 100µF ×2、CDE 381LX 10,000µF ×4、ROE EKE 470µF ×4、ROE EGW 47µF ×2。**47µF／470µF 二擇一就此定案為 ROE EGW／ROE EKE。**四款電解尺寸均未事先取得，到貨量完才能改 PCB 封裝。明細與到貨核對項見 [00 採購總表](00-採購總表.md) 開頭的下單紀錄。

**2026-09-18 選料更新：**已登記使用者預計下單清單；47µF／470µF 各保留兩款候選，尚未決定。全部未購，詳見 [目前候選與封裝影響](10-預計下單清單.md)。既有 PCB／3D 外框尚未依此換料。

> 2026-09-17 使用者確認：已訂 LM3886T 與變壓器均在寄送中，尚未收到。本次 PCB B／V0.2 修訂未新增其他採購或實物核對紀錄。

更新：2026-09-16。使用者更正：真正已下單的只有下列變壓器與 LM3886T 兩個商品連結，均待到貨；電容、整流橋及其他料件全部未購。已選 C 方案：完整雙聲道、雙橋、四顆主濾波電容。

| 料件 | 狀態與規格 | 數量紀錄 |
|---|---|---|
| [環形變壓器](https://shopee.tw/product/1151719/361359378) | 已下單待到貨；賣場 200W、AC110V、兩組獨立 22Vac＋單 12Vac；VA 與各繞組電流未知 | 設計用量 1 個，訂單數量未另核對 |
| [LM3886T 拆機品](https://www.ruten.com.tw/item/22405749782156/) | 已下單待到貨；賣場標題二手拆機、狀況欄全新，需核對；/NOPB 未確認 | 訂單數量待確認；雙聲道設計需 2 顆，不將舊紀錄 4 顆視為已確認數量 |

電源與功率調整見 [採購後修訂計畫](09-採購後修訂計畫.md)。已購不等於已驗收，沒有量測結果。

## 到料核對

- 變壓器標籤、引線、繞組獨立性、相位、電流、頻率、熱保護及空載電壓。
- IC 數量、封裝、完整打標、批號及引腳狀況；外觀不能保證真偽。若收到不同封裝，先核對機構與熱阻，不直接代換。
- 裝妥散熱與電氣絕緣後，以限流電源和假負載逐顆測試直流、靜態電流、波形及溫升。

## 採購紀錄更正

舊版記載「KBPC2510 ×1、Nichicon 10,000µF／63V ×2 已下單」不正確，依使用者本次更正撤銷。不是退貨或取消訂單，而是先前紀錄錯誤。

## 其餘全部未購

散熱器、絕緣介面、輸出電感、一次側元件、浪湧控制、保護板、機殼及其他被動件均未購。原 300VA／25Vac 變壓器不再採買；額外輔助電源先暫緩，優先評估 12Vac 繞組。

CSV BOM 是由 V0.3 KiCad netlist 自動產生的設計用量，不是庫存或訂單清單；本檔獨立保存採購事實。PCB 與 footprint 尚未定案。

## C 方案待採購清單（設計用量，實際料號待核對）

### 電源板（整流橋未購；主電容、旁路、洩放電阻 2026-09-20 已購）

| 料件 | 規格 | 還需 | 對應 | 備註 |
|---|---|---:|---|---|
| 橋式整流器 | KBPC2510 25A/1000V 可作候選，非指定料號 | 2 | BR1、BR2 | 兩組獨立次級各一橋；核對浪湧、腳位與散熱 |
| 主濾波電容 | **CDE 381LX103M063A052，2026-09-20 已購** | 0 | C201–C204 | 每軌 2 顆並聯，共 20,000µF／軌；核對紋波電流、壽命、尺寸與腳距 |
| 100nF/100V 薄膜電容 | 旁路 | 2 | C205、C206 | |
| 2.2kΩ/2W 電阻 | 洩放 | 2 | R201、R202 | 金屬皮膜或金屬氧化膜 |

### 放大板被動元件（電阻與電容 2026-09-20 已購，下表保留為設計用量）

**電阻（1% 金屬皮膜，0.25W 除非另標）**

| 值 | 數量 | 對應 | 備註 |
|---|---:|---|---|
| 1MΩ | 2 | R1、R101 | 輸入洩放 |
| 22kΩ | 4 | R2、R8、R102、R108 | 輸入偏壓＋靜音 |
| 20kΩ/1% | 2 | R4、R104 | 回授上臂，決定增益 |
| 1kΩ/1% | 2 | R3、R103 | 回授下臂，決定增益 |
| 1kΩ | 2 | R6、R106 | 輸入串聯 |
| 2.7Ω/2W | 2 | R5、R105 | Zobel，低電感 |
| 10Ω/2W | 2 | R7、R107 | 輸出隔離，低電感 |

**電容**

| 值 | 數量 | 對應 | 備註 |
|---|---:|---|---|
| 2.2µF/63V 薄膜 | 2 | C1、C101 | 輸入隔直 |
| 47µF/63V 無極性（BP） | 2 | C2、C102 | 回授，必須真正雙極性 |
| 100nF/63V | 4 | C3、C4、C103、C104 | 電源去耦（薄膜或 X7R） |
| 100nF/100V 薄膜 | 2 | C5、C105 | Zobel |
| 470µF/63V 電解 | 4 | C6、C7、C106、C107 | 本地儲能，注意極性 |
| 100µF/63V 電解 | 2 | C8、C108 | 靜音電容，正端 GND 負端 MUTE |

**電感**

| 值 | 數量 | 對應 | 備註 |
|---|---:|---|---|
| 0.7µH 空心 | 2 | L1、L2 | DCR ≤0.05Ω，≥4A，料號或繞製規格待定 |
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

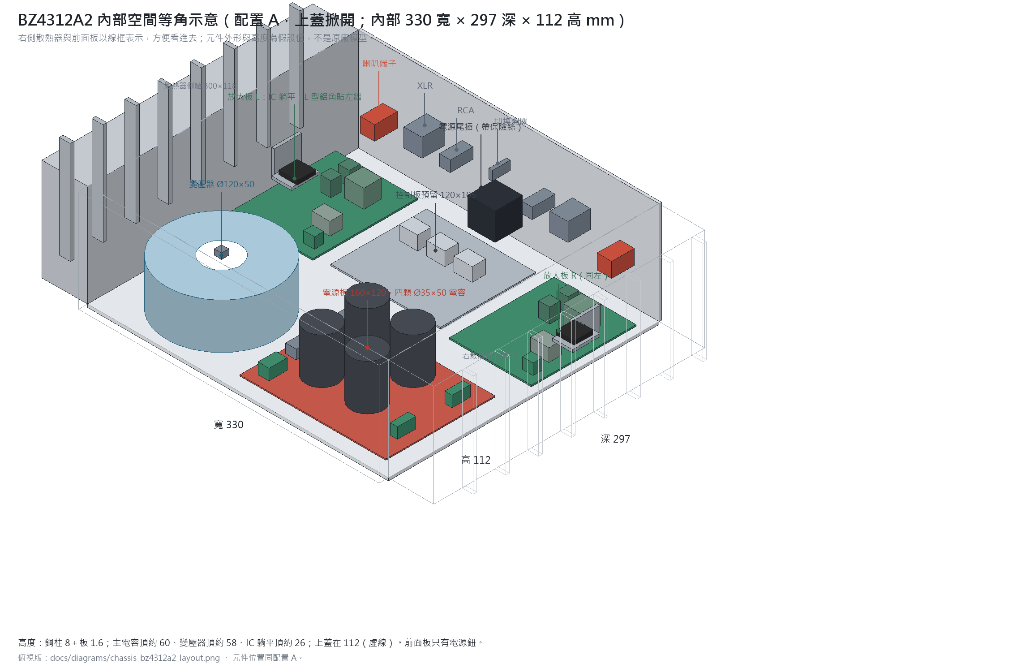
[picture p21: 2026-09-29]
docs/diagrams/chassis_bz4312a2_3d.png

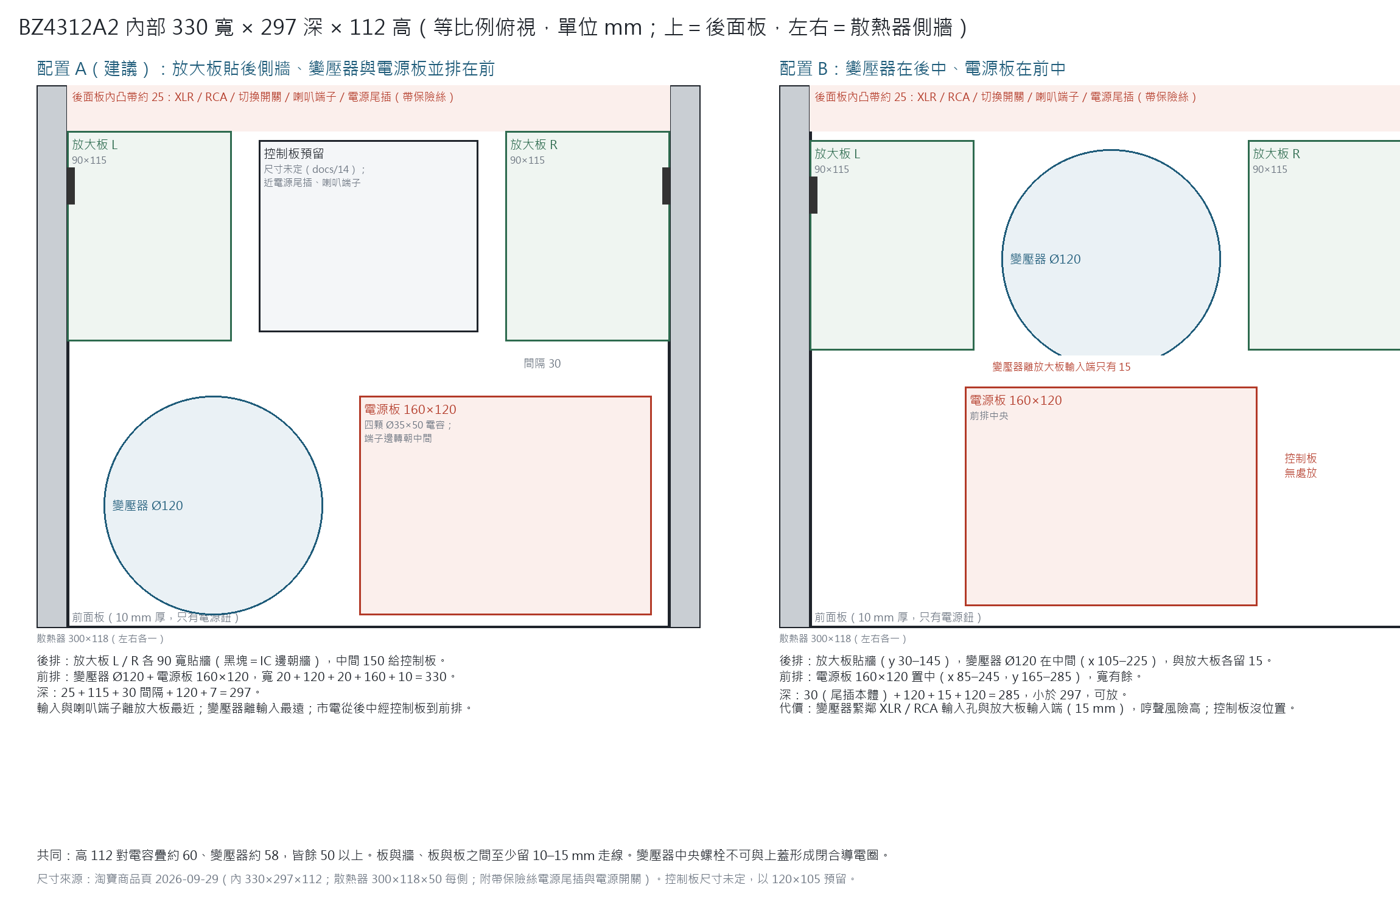
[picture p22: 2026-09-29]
docs/diagrams/chassis_bz4312a2_layout.png

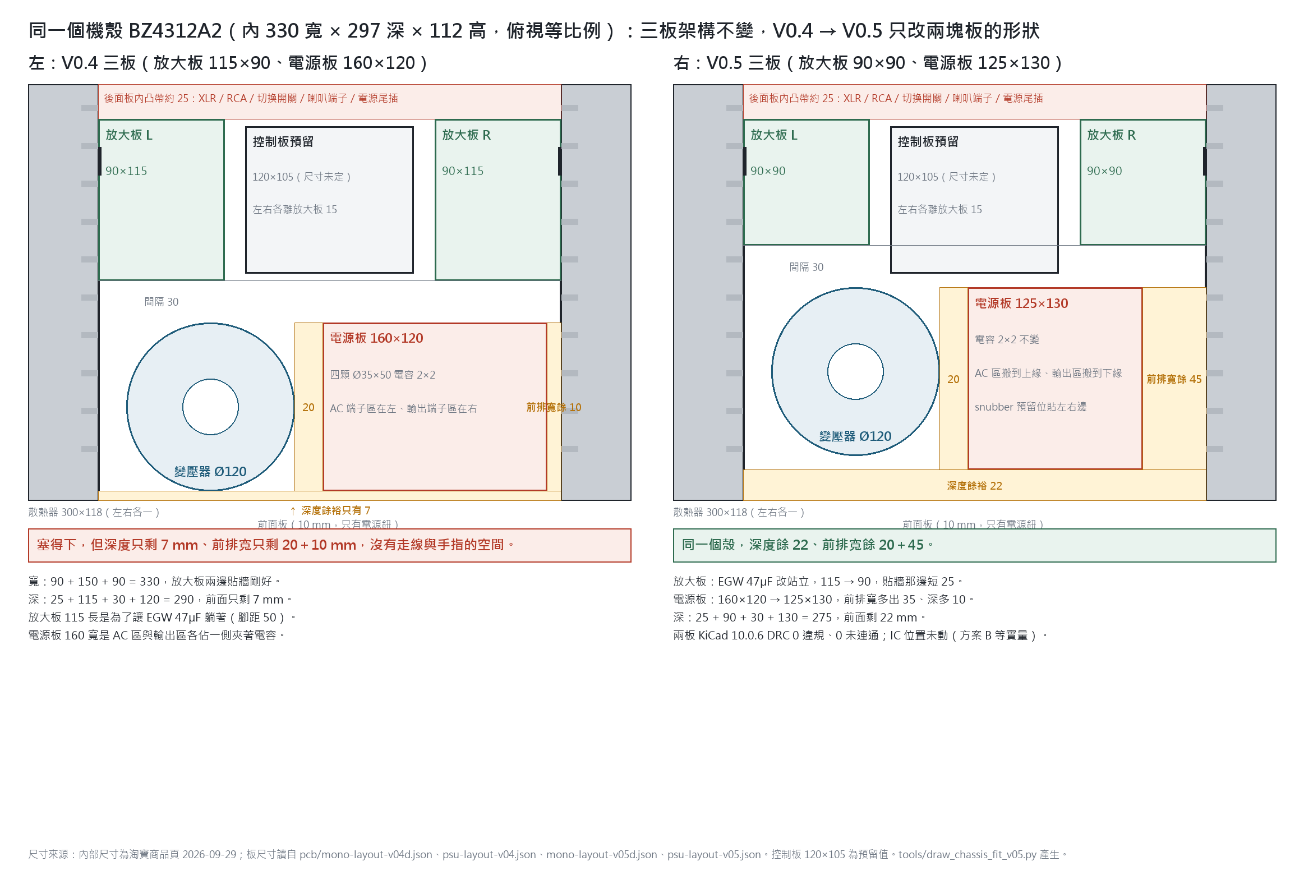
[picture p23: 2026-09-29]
docs/diagrams/chassis_bz4312a2_v05_fit.png

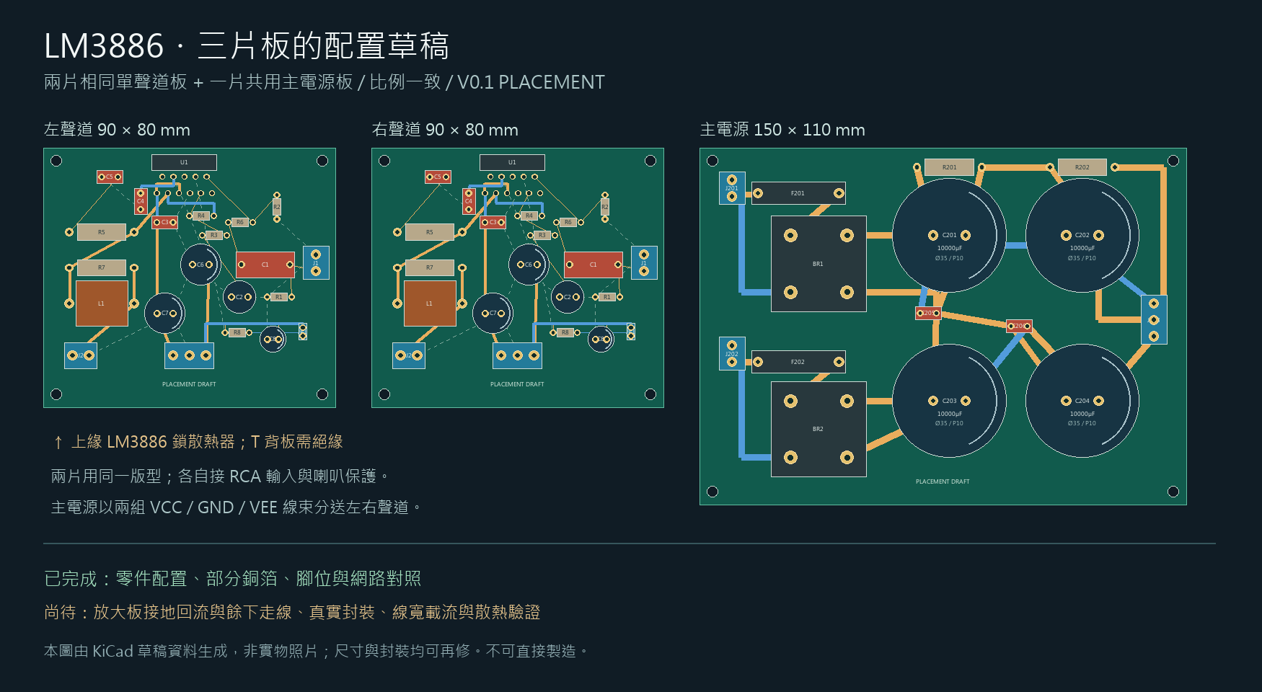
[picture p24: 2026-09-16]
pcb/preview/system-placement-overview.png

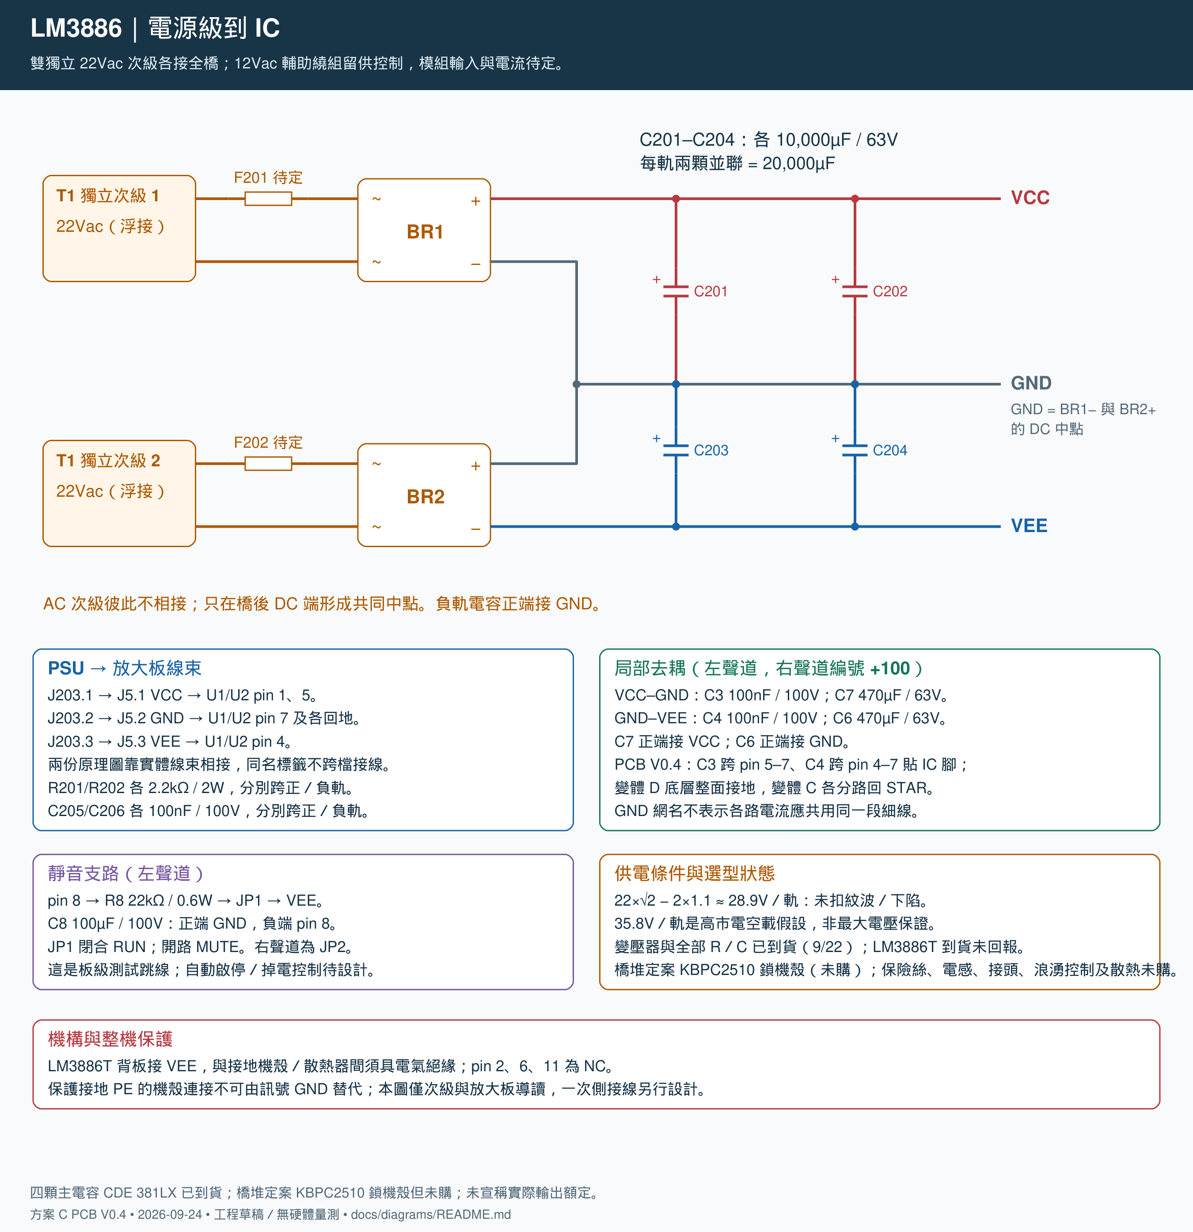
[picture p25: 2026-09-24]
docs/diagrams/lm3886_power_to_ic.png

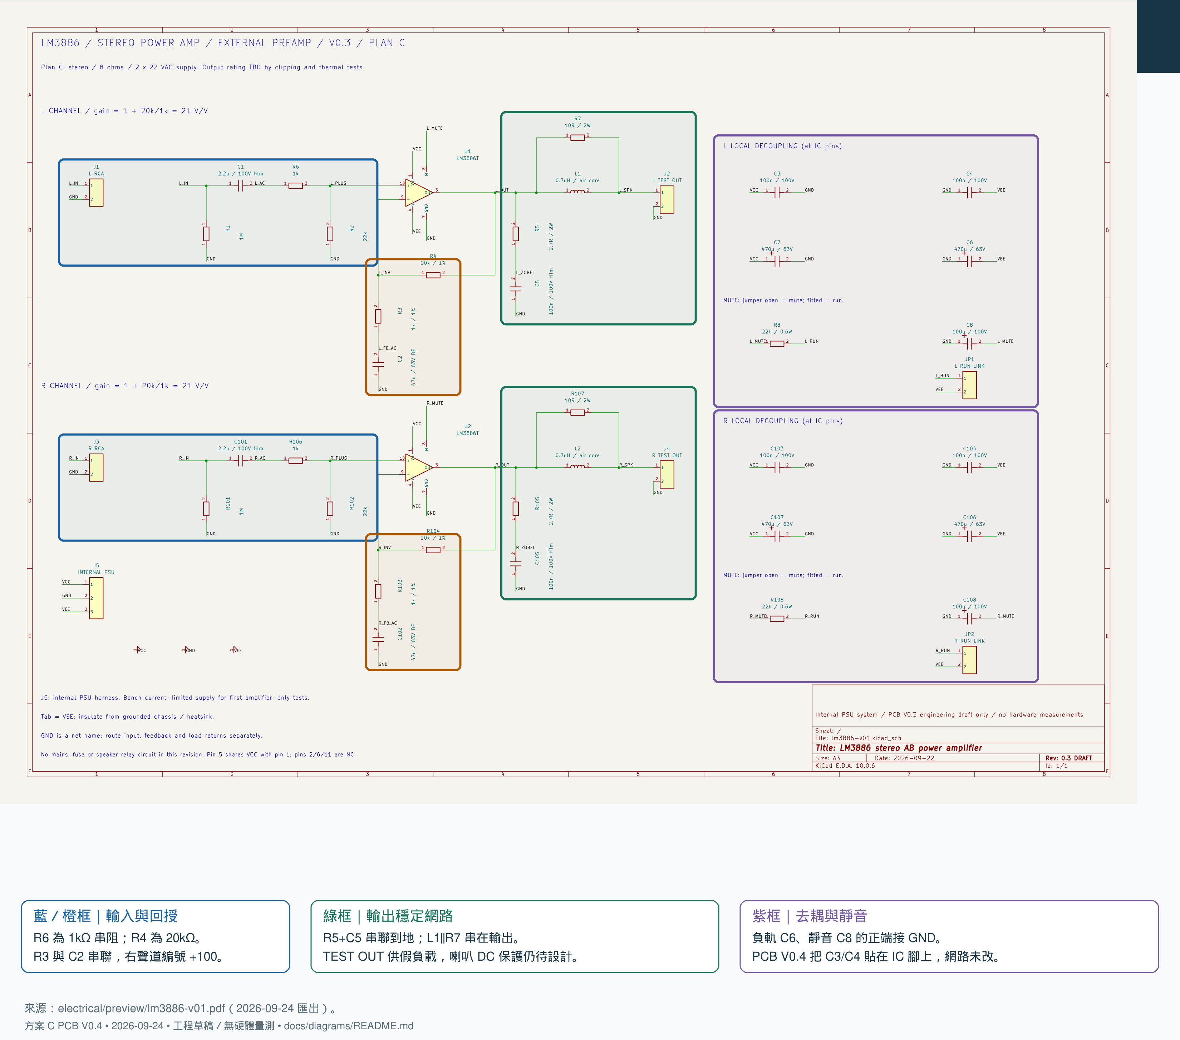
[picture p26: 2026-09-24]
docs/diagrams/lm3886_sch_annotated.png

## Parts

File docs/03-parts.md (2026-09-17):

# BOM 與整機配件

最新[露天商品直達連結](11-ruten-shopping-links.md)已另列2026-09-18查價、包裝與待確認條件；以下保留設計需求。

> V0.3／2026-09-16：採用 C 方案，只有變壓器與 LM3886T 已購；額定電流、保護與實際功率待確認。

[電路 BOM](../electrical/bom-draft.csv) 由 KiCad 匯出的 netlist 產生，涵蓋 43 個放大板元件；另有[電源次級 BOM](../electrical/psu-bom-draft.csv) 的 15 個元件。`footprint` 留空代表尚未核對實際尺寸，不能據此直接下單 PCB。沒有價格欄：本次未查供應商即時庫存與報價。

## 放大板選材

- IC：LM3886T ×2 為設計用量；已訂拆機品，訂單數量與 /NOPB 待核對；封裝與引腳彎折須依實際訂購型號核對。
- 小訊號電阻：1% 金屬膜，除 BOM 另列者外以 0.25W 起選。
- Zobel 與輸出阻尼電阻：低電感、至少 2W，保留散熱空間，量測高頻下溫升。
- 0.7µH 電感：空心，初選 DCR ≤0.05Ω，線徑與安裝須能承受至少 4A 峰值及測試溫升；40W／8Ω 的需求為 3.16A 峰值。此項仍需料號或繞製規格。
- 2.2µF 輸入電容：薄膜、≥63V。
- 47µF 回授電容：真正無極性／雙極性、≥63V；不把一般電解正反接的問題留到焊接時猜測。
- 電源／靜音電解：≥63V，依原理圖正負極組裝。100nF 去耦可用 X7R 或薄膜；Zobel 用薄膜。

## 尚未畫入放大板的整機需求

| 部件 | 數量 | 初選條件／待辦 |
|---|---:|---|
| 內建環形變壓器 | 1 | 已訂 AC110V、兩組獨立 22Vac＋單 12Vac；賣場 200W 不作已確認 VA，電流／頻率／調整率待核對 |
| 整流與大電容 | 1 組 | 電源次級 BOM 已列兩橋、4×10,000µF／63V、洩放及旁路；料號與散熱待選 |
| AC 入口／一次側保險絲／開關 | 1 組 | 核對一次側料件後決定電流額定與分斷能力 |
| 浪湧控制與旁路 | 1 組 | 含快速關開及失效情境，待設計 |
| 隔離輔助電源／輔助繞組 | 1 組 | 供保護繼電器與啟停控制，待決定電壓及容量 |
| 電源動態能力／儲能 | 1 組 | 2×40W 試算同相正弦時，每軌訊號峰值約 6.32A，另有靜態電流；由實際電源與電容共同承擔，待選型後驗證 |
| 散熱器 | 2 | 每聲道 ≤0.4°C/W，按實際機內氣流及安裝方向核對 |
| 絕緣導熱介面及螺絲套 | 2 組 | 確認熱阻 ≤0.3°C/W 與電氣絕緣；不只核對厚度 |
| 絕緣 RCA 插座 | 2 | 機殼接地規劃完成前不靠插座形成多點地 |
| 喇叭接線柱 | 4 | 額定電流、絕緣距離與面板固定待選；原型先接假負載 |
| 機殼／固定件 | 1 組 | 依散熱器、電源界面及 PCB 實際尺寸設計；尚無加工圖 |
| 電源輸入保護 | 1 組 | 下一版加入適合雙軌電源的保護；不得直接套用未定案的保險絲額定 |
| 喇叭 DC 保護／繼電器 | 1 組 | 下一版設計，包含輔助電源及 DC 斷開能力驗證 |
| 非感性假負載 | 2 | 8Ω、連續至少 100W，按額定安裝散熱 |

內建電源的架構與次級整流草案已完成；一次側接線、軟啟動及保護控制尚未完成。整機 BOM 尚須加入機殼 PE 接點、屏障、端子與線束。參見[內建電源規劃](05-internal-power.md)。

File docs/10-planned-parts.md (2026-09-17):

# 預計下單零件與替代候選（2026-09-18）

使用者提供文字清單與購物車截圖，並確認 **47µF 與 470µF 的兩組品牌都先保留候選，尚未決定**。以下全部是預計下單／候選，不是已購、已出貨或到料紀錄；沒有代為購買。

[露天購買連結、下標選項及其餘待買候選](11-ruten-shopping-links.md)已補齊；NCC店未滿$100不出貨等限制見該頁。

## 文字清單：佑昇音響／真合貿易有限公司

規格、金額及出貨天數原依使用者貼文記錄；2026-09-18已補上商品直達連結並核對商品頁，未結帳。價格暫按每顆新台幣計算；14／21 天為賣場出貨描述，不是到貨承諾。

| 品牌／系列／料號 | 規格 | 數量 | 對應原理圖 | 顯示價格／顆 | 出貨描述 | 狀態 |
|---|---|---:|---|---:|---|---|
| [Vishay BCcomponents PR02](https://www.ruten.com.tw/item/21452091096054/) | 2.2kΩ / 2W / 1% | 2 | R201, R202 | $20 | 21天內 | 預計下單，未購 |
| [RNU2（製造商待確認）](https://www.ruten.com.tw/item/21308069698811/) | 2.7Ω / 2W | 2 | R5, R105 | $5 | 21天內 | 預計下單，未購 |
| [Vishay BCcomponents PR02](https://www.ruten.com.tw/item/21452091095918/) | 10Ω / 2W / 1% | 2 | R7, R107 | $20 | 21天內 | 預計下單，未購 |
| [Vishay BCcomponents MRS25](https://www.ruten.com.tw/item/21505371267166/) | 1kΩ / 0.6W / 1% | 4 | R3, R103, R6, R106 | $5 | 14天內 | 預計下單，未購 |
| [Vishay BCcomponents MRS25](https://www.ruten.com.tw/item/21505371700382/) | 20kΩ / 0.6W / 1% | 2 | R4, R104 | $5 | 21天內 | 預計下單，未購 |
| [Vishay BCcomponents MRS25](https://www.ruten.com.tw/item/21505371269809/) | 22kΩ / 0.6W / 1% | 4 | R2, R102, R8, R108 | $5 | 21天內 | 預計下單，未購 |
| [Vishay BCcomponents MRS25](https://www.ruten.com.tw/item/21505371254476/) | 1MΩ / 0.6W / 1% | 2 | R1, R101 | $5 | 21天內 | 預計下單，未購 |
| [CDE 361R / 361R101M100EG2](https://www.ruten.com.tw/item/22111174641617/) | 100µF / 100V | 2 | C8, C108 | $48 | 21天內 | 預計下單，未購 |
| [ROE EKE](https://www.ruten.com.tw/item/21513740997288/) | 470µF / 63V | 4 | C6, C7, C106, C107 | $90 | 21天內 | 候選，二擇一 |
| [ROE EGW](https://www.ruten.com.tw/item/21515914332545/) | 47µF / 63V / 23Vac / BP-NP | 2 | C2, C102 | $300 | 21天內 | 候選，二擇一 |
| [WIMA MKS4](https://www.ruten.com.tw/item/21304180923597/) | 2.2µF / 100V / 5% | 2 | C1, C101 | $70 | 14天內 | 預計下單，未購 |
| [WIMA MKS2 / MKS2D031001A00JSSD](https://www.ruten.com.tw/item/21304114150484/) | 100nF / 100V / 5mm | 8 | C3, C4, C5, C103, C104, C105, C205, C206 | $19 | 14天內 | 預計下單，未購 |
| [CDE 381LX / 381LX103M063A052](https://www.ruten.com.tw/item/22102647676193/) | 10000µF / 63V | 4 | C201, C202, C203, C204 | $185 | 14天內 | 預計下單，未購 |
## 截圖中的替代候選

| 用途 | 文字清單 | 截圖候選 | 實際需求 |
|---|---|---|---|
| C2／C102 回授無極性電容 | ROE EGW 47µF／63V，$300×2 | [Mundorf E-Cap RAW 47µF／100V](https://www.ruten.com.tw/item/21724493448626/)，$190×2；管迷；標示3天內出貨 | 合計只需2顆，兩款尚未決定 |
| C6／C7／C106／C107 本地儲能 | ROE EKE 470µF／63V，$90×4 | [NCC KY 470µF／63V](https://www.ruten.com.tw/item/22339798786419/)，$15×4；f88911；標示3天內出貨、16×20 mm | 合計只需4顆，兩款尚未決定 |

截圖運費：管迷郵寄 $50、f88911 黑貓 $30，均為畫面當時顯示，未確認結帳。Mundorf 商品標題的「47µf」按 47µF 登記。截圖不是訂單證明。

## 數量與金額核對

文字清單共有13列、40顆，對應40個不同的原理圖位置；加入替代候選後仍為40個需求位置，不是46顆必買。所有電阻數量相符；100nF ×8 正好涵蓋兩聲道去耦4顆、Zobel 2顆、電源板旁路2顆。

若貼文價格均為單價，以下為**零件小計，不含運費與折扣**：

| 47µF 選擇 | 470µF 選擇 | 試算小計 |
|---|---|---:|
| ROE EGW | ROE EKE | $2238 |
| ROE EGW | 日本化工 NCC KY（賣場標示） | $1938 |
| Mundorf E-Cap RAW | ROE EKE | $2018 |
| Mundorf E-Cap RAW | 日本化工 NCC KY（賣場標示） | $1718 |

## 對目前 PCB／3D 的影響

這次更新選料紀錄，**未把商品名稱直接視為已驗證封裝，也未重畫 PCB**。既有 A＋B＋C 圖集是選料前的 V0.3 快照；圖中的高度及外框仍為假設。

- **C2／C102：必須重新安排臥式封裝。** ROE 文字清單與 Mundorf 截圖均為臥式候選，不能直接沿用目前立式 `BP_D10_P5` 的孔位／外框。需先確認本體長度、直徑、引腳彎折與安裝腳距。
- **470µF：NCC 候選的賣場尺寸與現板不同。** 截圖標示16×20 mm，現有占位為 Ø12.5 mm／腳距5 mm；若採 NCC，需核對完整料號與腳距並調整外框、間距及模型。ROE EKE 也未取得實體尺寸。
- **100µF：CDE 已提供完整料號。** 100V 為較高標示耐壓，仍需核對容量容差、尺寸、漏電等條件，不表示能直接塞進原 Ø8 占位。
- **主電容：CDE 381LX 已提供完整料號，但為牛角型。** 不只查腳距，也要確認接腳形狀、鑽孔及本體尺寸；現有1.3 mm孔不視為已合格。
- **電阻：軸向腳距需按本體與彎腳確認。** PR02、MRS25 的完整訂購碼尚未提供；RNU2 的4.5×15 mm只記為賣場描述，低電感特性仍待資料核對。
- **WIMA：15 mm／5 mm 腳距與目前占位方向一致，但本體寬高與完整型號仍需逐項核對。** MKS2 的完整料號已記錄；MKS4 尚缺完整訂購碼。

下一次修改封裝時，以本表候選＋原廠尺寸圖／實物為依據；再同步原板、3D、裝配圖與 DRC。這次沒有新增 ERC／DRC 或硬體測試。

## 尚未包含的零件

整流橋、次級保險絲及座、0.7µH電感、板端接頭／跳線、RCA與喇叭端子、散熱器與絕緣件、機殼固定件、保護／啟停／輔助電源及一次側配件仍需確認。變壓器與LM3886T沿用既有已訂待到貨紀錄。

## 資料來源與狀態

本表來源僅為使用者2026-09-18提供的文字與截圖，不把商品標題當成原廠認證。完整結構化紀錄見 [JSON](10-planned-parts.json)；已購狀態見 [採購紀錄](08-procurement.md)。未把含商店與價格的原始截圖上傳到專案。

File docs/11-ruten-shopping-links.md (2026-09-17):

# 露天商品連結與待買候選（2026-09-18）

這份清單可直接點到商品頁，再由使用者選規格、數量與加入購物車。**沒有新增訂單或代加購物車；47µF、470µF仍各自二擇一、尚未決定。** 全部商品頁已於2026-09-18開啟核對，看到購物操作入口；價格、庫存、可選規格與出貨條件以結帳當時為準。

「原清單相符」只代表賣場描述符合使用者選的候選，並非原廠資料、真偽、實測或PCB封裝核對。「待確認／暫緩」的新增候選，應先解決該列缺項才購買。這不是一鍵全買清單。

## 原本15項候選的商品直達連結

前13項為佑昇音響／真合貿易有限公司（yosontw），最後兩項為截圖指定賣家。數量為雙聲道設計需求，價格為單顆；完整位置對照與原始採購紀錄見[原清單](10-planned-parts.md)。

| 商品直達頁 | 規格 | 設計需求 | 單顆參考價 | 選項／注意 |
|---|---|---:|---:|---|
| [Vishay BCcomponents PR02](https://www.ruten.com.tw/item/21452091096054/) | 2.2kΩ / 2W / 1% | 2 | $20 | 單件商品；需求2顆 |
| [RNU2（製造商待確認）](https://www.ruten.com.tw/item/21308069698811/) | 2.7Ω / 2W | 2 | $5 | 單件商品；需求2顆 |
| [Vishay BCcomponents PR02](https://www.ruten.com.tw/item/21452091095918/) | 10Ω / 2W / 1% | 2 | $20 | 單件商品；需求2顆 |
| [Vishay BCcomponents MRS25](https://www.ruten.com.tw/item/21505371267166/) | 1kΩ / 0.6W / 1% | 4 | $5 | 單件商品；需求4顆 |
| [Vishay BCcomponents MRS25](https://www.ruten.com.tw/item/21505371700382/) | 20kΩ / 0.6W / 1% | 2 | $5 | 單件商品；需求2顆 |
| [Vishay BCcomponents MRS25](https://www.ruten.com.tw/item/21505371269809/) | 22kΩ / 0.6W / 1% | 4 | $5 | 單件商品；需求4顆 |
| [Vishay BCcomponents MRS25](https://www.ruten.com.tw/item/21505371254476/) | 1MΩ / 0.6W / 1% | 2 | $5 | 單件商品；需求2顆 |
| [CDE 361R](https://www.ruten.com.tw/item/22111174641617/) | 100µF / 100V | 2 | $48 | 選「1個」，數量2 |
| [ROE EKE](https://www.ruten.com.tw/item/21513740997288/) | 470µF / 63V | 4 | $90 | 單件商品；需求4顆；與同組另一款二擇一 |
| [ROE EGW](https://www.ruten.com.tw/item/21515914332545/) | 47µF / 63V / 23Vac / BP-NP | 2 | $300 | 單件商品；需求2顆；與同組另一款二擇一 |
| [WIMA MKS4](https://www.ruten.com.tw/item/21304180923597/) | 2.2µF / 100V / 5% | 2 | $70 | 選「1顆」，數量2；不要選10顆包裝 |
| [WIMA MKS2](https://www.ruten.com.tw/item/21304114150484/) | 100nF / 100V / 5mm | 8 | $19 | 選「1個」，數量8 |
| [CDE 381LX](https://www.ruten.com.tw/item/22102647676193/) | 10000µF / 63V | 4 | $185 | 選「1個」，數量4；不要選10個包裝 |
| [Mundorf E-Cap RAW](https://www.ruten.com.tw/item/21724493448626/) | 47µF / 100V / 無極性 | 2 | $190 | 單件商品；需求2顆；與同組另一款二擇一 |
| [日本化工 NCC KY（賣場標示）](https://www.ruten.com.tw/item/22339798786419/) | 470µF / 63V | 4 | $15 | 單件商品；需求4顆；與同組另一款二擇一 |

- **NCC賣場最低出貨金額：**[f88911公告](https://www.ruten.com.tw/store/f88911/)表示未含運低於$100不出貨；4顆×$15＝$60尚未達門檻。購買前確認合單或出貨條件，勿把多買的備品當成電路需求。
- WIMA MKS4頁面含1顆／10顆選項；CDE 381LX含1個／10個。表內以單件需求計，不能按最低顯示價誤選整包數量。
- Mundorf賣方新增尺寸描述為本體Ø14×37mm、引線長60mm，仍需原廠／到料核對；不把引線長當PCB腳距。NCC原款是16×20mm，不是同店的12.5×30mm款。
- 原13項小計仍為$2238；依兩組替代選擇為$1938／$2018／$1718，皆未含運、最低出貨門檻及新增配件。

## 尚未選購的板上元件與整機配件

以下都是新找到的候選來源，**沒有替使用者定案**。需求涵蓋現有三板及整機配件；額外保護模組尚未整合原理圖。包裝單位不明的條目已標出，不能把「設計需求」直接當下標件數。

### 電源板

| 商品直達頁 | 設計需求 | 選項／頁面價格 | 選型狀態與待核對 |
|---|---|---|---|
| [KBPC2510 整流橋](https://www.ruten.com.tw/item/22605098060064/) | 2個／BR1、BR2 | 標題25A／1000V，單位數量先確認；$51 | 待確認：完整廠牌、KBPC／KBPC-W端子形態、腳位、外形與散熱；25A不能當作本板持續輸出能力。 |
| [5×20mm 保險絲座](https://www.ruten.com.tw/item/21840721329469/) | 2個／F201、F202 | 保險絲座，不把附帶保險絲當已選定；$4 | 待確認：PCB安裝型態、腳距、孔徑、DC電壓／電流額定；5×20是保險管尺寸，不是焊腳距。 |

### 放大板

| 商品直達頁 | 設計需求 | 選項／頁面價格 | 選型狀態與待核對 |
|---|---|---|---|
| [0.7µH 空心電感](https://www.ruten.com.tw/item/22615433056210/) | 2個／L1、L2 | 每件1只，需求2；$379 | 待確認：賣方稱線徑2.1mm、外徑13.5mm、長10.5mm、腳距28mm；DCR≤0.05Ω、≥4A峰值與公差未證實，2.1mm線徑須重新核對PCB孔徑。 |

### 接插件

| 商品直達頁 | 設計需求 | 選項／頁面價格 | 選型狀態與待核對 |
|---|---|---|---|
| [KF301 2P／5.08mm](https://www.ruten.com.tw/item/22409916143944/) | 6個 | 2P，賣方標300V／16A、14–22AWG；確認1件所含數量；$1 | 待確認：J1／J2各2個＋J201／J202各1個；廠牌、孔徑、插線方向與載流條件，不能只憑同為KF301認定相容。 |
| [KF301 3P／5.08mm](https://www.ruten.com.tw/item/22410924930141/) | 3個 | 3P，賣方標300V／16A、14–22AWG；確認1件所含數量；$2 | 待確認：左右板J5各1個＋J203一個；核對VCC/GND/VEE順序、孔徑、插線方向與載流。 |
| [2.54mm 單排針 1×40P](https://www.ruten.com.tw/item/21839712907740/) | 2段×2pin | 一條40pin可裁出兩段；先確認單件包裝；$3 | 待確認：RUN JP1／JP2，與跳線帽配合高度、≥60VDC絕緣額定；不是排母。 |
| [2.54mm 跳線帽](https://www.ruten.com.tw/item/22410924645672/) | 2個 | 商品為100只包裝；買1包會剩98只；$23／100只 | 待確認：≥60VDC絕緣額定；僅採購包裝超額，不增加設計需求。 |

### 機殼接插件

| 商品直達頁 | 設計需求 | 選項／頁面價格 | 選型狀態與待核對 |
|---|---|---|---|
| [RCA 面板母座](https://www.ruten.com.tw/item/21840724685995/) | 2個 | 紅色1、黑色1；$12 | 待確認：必須附能隔離外殼與金屬面板的完整絕緣墊圈／套管；目前只確認紅黑款商品頁，沒有證明面板絕緣。 |
| [喇叭接線柱](https://www.ruten.com.tw/item/22410923188279/) | 4個 | 標題1只價；需求紅2、黑2，頁面未提供顏色選項，需先確認配色方式；$17 | 待確認：≥60VDC、載流、面板絕緣、開孔及板厚；不是4個單聲道端子組。 |

### 散熱／機構

| 商品直達頁 | 設計需求 | 選項／頁面價格 | 選型狀態與待核對 |
|---|---|---|---|
| [大 TO-3P 雲母絕緣片 22×30mm](https://www.ruten.com.tw/item/22410921549515/) | 2片 | 10張包裝，1包；$23／10張 | 待確認：此為尺寸候選，尚未證明適合LM3886T孔位／金屬背板；整套介面熱阻≤0.3°C/W、耐壓及安裝公差待核對。 |
| [LM3886 用絕緣螺絲套](https://www.ruten.com.tw/item/21711492321878/) | 2個 | 10顆包裝，1包；$20／10顆 | 待確認：賣方列外徑6mm／內徑3mm；套肩長、IC孔位與實際螺絲配合；螺絲套不取代導熱絕緣片。 |
| [TS-KS101 導熱膏](https://www.ruten.com.tw/item/22410921235113/) | 裝配適量 | 45g包裝，需求1份；$57 | 待確認：材料導電性與介面相容；導熱膏不能單獨提供LM3886T背板絕緣。 |
| [大型鋁型材散熱器](https://www.ruten.com.tw/item/22407792090091/) | 每聲道1個，條件成立才採買 | 頁面有「200長（批量）」與「100長（批量）」；尺寸與最小包裝需詢明；$1,012–2,531 | 暫緩：標題400×50×200mm，沒有≤0.4°C/W資料，並可能超出機殼空間；僅作詢問熱阻／裁切的來源，未認定合用。若用附散熱器機殼不要重複買。 |
| [430寬全鋁後級機箱](https://www.ruten.com.tw/item/22547543033963/) | 1個 | 有300深度／400深度；以400深度作排布候選，未定案；$3,895–4,285 | 暫緩：賣方400深款內部約330×112×400mm，附兩側散熱器及帶保險電源座；尺寸標題／內文有差異，須取加工圖。散熱片重量不是熱阻，三板／變壓器／保護板仍需排布。 |
| [M3 銅柱、螺絲、螺帽](https://www.ruten.com.tw/item/22601863290504/) | 三片PCB共12支柱，螺絲依安裝方式 | 先選M3，長度待機構定案；銅柱10個/包，若買兩包則20支；螺絲為另一選項；$25–95 | 待確認：板底焊腳間隙、銅柱高度、螺絲長度與接地用途；勿將M4或單買螺母選項當成完整固定組。 |

### 市電／控制

| 商品直達頁 | 設計需求 | 選項／頁面價格 | 選型狀態與待核對 |
|---|---|---|---|
| [AC-01 電源入口＋帶燈開關＋保險座](https://www.ruten.com.tw/item/22410919510431/) | 1組（機殼若已附合用款則免重買） | 賣方標15A／250V，需確認110Vac燈與接口規格；$29 | 暫緩：核對原廠安規、極數、接地端、一次側開關接法、面板尺寸與保險管；保險絲電流尚未決定。 |
| [5×20 延時保險絲系列](https://www.ruten.com.tw/item/22410976060232/) | 至少一次側1＋次級2，最終依保護設計 | 標題1／1.5／2／3／3.15A；沒有可直接指定的正確電流，包裝數量也待確認；$136（單位未明） | 暫緩：變壓器額定電流、浪湧、保護協調、AC/DC分斷能力未定；不保證此系列任一款符合，禁止照頁面預設值購買。 |
| [AC105–235V 軟啟動板](https://www.ruten.com.tw/item/22546454641812/) | 1組 | 接線端子式／插線端子式兩款；接線端子式先列候選；$660 | 暫緩：僅標題電壓範圍涵蓋110V；需電路／額定功率、限流電阻、繼電器、重啟及失效行為，尚未整合設計。 |
| [UPC1237 雙聲道喇叭保護板](https://www.ruten.com.tw/item/22631277223445/) | 1組 | 賣方稱獨立AC12–18V、約3秒延遲、約1VDC起控；$258 | 暫緩：賣家公告部分二手以全新欄位上架，需確認本件狀況。需完整電路、±DC偵測、掉電釋放、繼電器DC分斷能力及12Vac繞組容量；不可將300Wx2文案當規格。 |

### 線束

| 商品直達頁 | 設計需求 | 選項／頁面價格 | 選型狀態與待核對 |
|---|---|---|---|
| [16AWG 黑色矽膠線](https://www.ruten.com.tw/item/22407795970619/) | 長度待機殼排布 | 1米單位；先列候選，不先固定米數；$35／米 | 待確認：銅截面、溫度／電壓額定、端子適配；供次級／DC／喇叭線路評估，不自動作市電或PE線。 |
| [16AWG 紅色矽膠線](https://www.ruten.com.tw/item/22407795970226/) | 長度待機殼排布 | 1米單位；不同電源軌需另做清楚標識；$35／米 | 待確認：同黑色線要求，實際束線載流與溫升仍需驗證。 |
| [20cm 屏蔽訊號線](https://www.ruten.com.tw/item/22325050050240/) | 左右聲道各1段，長度待確認 | 原商品帶XH2.54 3P插頭；$8 | 待確認：現板J1是2P／5.08，不可直接插接，僅線材候選；需改端接、確認屏蔽芯線及實際長度。 |

### 測試

| 商品直達頁 | 設計需求 | 選項／頁面價格 | 選型狀態與待核對 |
|---|---|---|---|
| [8Ω／100W 鋁殼電阻](https://www.ruten.com.tw/item/21840720484921/) | 2個 | 標稱8Ω／100W；散熱器另需核算；$40 | 未符合完整需求：賣方未證實非感性及100W額定散熱條件；本頁僅阻值／功率候選，不列為已核准假負載，不可據此做高頻驗收。 |

## 尚未補到可採用商品的缺項

不是所有缺項都有足夠資料完成選型；以下保留明確缺口，不以規格不符的商品充數。

| 缺項 | 目前限制 |
|---|---|
| 台灣三腳插頭至IEC C13電源線 | 本次尚未取得可核對BSMI與正確接頭的商品直達頁；不要用兩芯線或梅花尾替代。 |
| PE黃綠接地線、環形端子、星形華司與獨立機殼接地螺栓 | 本次未核實適合的完整組合；線徑、端子孔徑、壓接及固定須隨一次側／機構定案。防靜電手環線不能作PE。 |
| 絕緣屏障、套管、護線圈、束線固定與機腳 | 依機殼孔位、線徑及材料等級選定，尚無確定尺寸，未隨意填商品。 |
| 獨立狀態指示燈／輔助穩壓 | 保護板帶LED、AC入口帶燈；先確認是否仍需要獨立前面板燈。12Vac繞組優先，不另訂變壓器或固定DC模組。 |

## 對目前PCB的影響

商品連結不會使PCB自動適配。尤其臥式47µF、Ø16mm NCC、本次0.7µH電感的粗引腳、KBPC端子以及保險絲座都要先取得尺寸，再修改封裝與檢查。此次未修改原理圖、PCB、3D、Gerber或既有PDF，也沒有新增ERC／DRC或硬體測試。

本頁38個商品直達連結包含原候選15項＋新增23項。機器可讀資料：原候選在[10-planned-parts.json](10-planned-parts.json)，新增候選／未解決項目在[11-ruten-shopping-links.json](11-ruten-shopping-links.json)。後續確認選料時，先更新候選狀態，再改PCB，不從本頁反推已購或已驗證。

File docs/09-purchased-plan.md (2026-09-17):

# 採購後修訂計畫（2026-09-16）

**2026-09-18 選料更新：**已登記使用者預計下單清單；47µF／470µF 各保留兩款候選，尚未決定。全部未購，詳見 [目前候選與封裝影響](10-planned-parts.md)。既有 PCB／3D 外框尚未依此換料。

本文件取代 V0.2 的變壓器採購候選與功率驗收目標。使用者確認兩個商品均已下單、正在等到貨；沒有到貨量測。

## 使用者選定 C 方案：完整雙聲道

- 兩聲道各一顆 LM3886T，共用正負主電源；雙橋指正、負電源整流架構，不代表左右聲道各有獨立電源。
- 主整流橋 2 顆、10,000µF／63V 主濾波電容 4 顆（每軌 2 顆並聯）全部待購；容量配置已選，實際品牌／系列、紋波額定及尺寸待選。
- 整機納入散熱與絕緣、雙聲道喇叭 DC 保護、開機延遲／掉電斷開、浪湧限制、保險絲、機殼 PE 接地及端子配線。這些均未購且尚未完成細部設計。
- 優先評估 12Vac 輔助繞組供保護與控制，模組供電類型及繞組電流確認後選型。
- 四顆主電容不代表輸出瓦數增加；功率仍受變壓器、供電下陷與散熱限制。單聲道先測只是驗證順序，最終交付目標是完整雙聲道。

## 已下單與設計方向

- [蝦皮環形變壓器](https://shopee.tw/product/1151719/361359378)：賣場標示 200W、輸入 AC110V、輸出 (0–22)/(0–22)＋(0–12)，兩組主次級可串聯；直徑 120mm、高 43mm、約 2.4kg。這些是 2026-09-16 查閱的商品宣稱，不是驗收數據。連續 VA、各繞組電流、頻率額定、調整率、熱保護及線色相位待確認；不得直接把 200W 當 200VA 或推定每繞組電流。
- [露天 LM3886T](https://www.ruten.com.tw/item/22405749782156/)：標題為二手原裝拆機，物品狀況欄卻寫全新，來源與健康狀態待核對。已確認此連結下單，訂單數量待確認；設計需 2 顆，舊紀錄 4 顆不作已確認數量。不能把賣場 T 型號直接登記為已確認 /NOPB。
- 維持兩聲道各一顆 LM3886T、非橋接非並聯、8Ω、Z10 RCA 控制音量；放大板元件值暫不更動。
- 取消另購原 300VA／2×25Vac 候選。先沿用兩組獨立次級各接全橋、橋輸出串聯形成正負軌的架構；此接法下 AC 次級不得另行串接。到貨需先核對繞組獨立性與標記。
- 依 C 方案選定每軌 20,000µF、63V 主電容配置，實際料號待選；保留原散熱初選，不因電壓降低而逕行縮小散熱器。保險絲、浪湧限制與整流橋需依實際額定再選。

## 電壓與功率：估算而非額定

雙橋每軌有兩顆導通二極體。若次級確實為 22Vrms、每顆壓降取 1.1V，濾波峰值約 22×√2−2.2 = 28.9V，尚未扣紋波與負載下陷。因此「約 ±30V 等級」不代表固定供電。

沿用舊版的 +10% 市電、+8% 空載調整率、每顆二極體 0.6V 假設，得到 22×1.10×1.08×√2−1.2 ≈ 35.8V／軌。調整率未知，這只是情境計算，不能作最大電壓保證。

先以每聲道約 30～40W／8Ω 為探索範圍；不再要求必達 2×40W，也不沿用 50W 延伸驗收。先量削波點與溫升，再決定可標示的雙聲道連續功率。TI 的 ±28V、8Ω、典型 38W 是元件參考條件，並非本機保證。[TI LM3886](https://www.ti.com/product/LM3886)

## 12Vac 輔助繞組

優先供喇叭保護與啟停控制，但待確認繞組電流及模組 AC／DC 輸入要求。12Vac 經全橋濾波約為 15～16Vdc，空載可能更高；若模組要求 DC12V，需適當穩壓。暫緩另購輔助變壓器與未定型保護板。

## 到貨與下一步

1. 核對變壓器標籤、繞組線色／相位、額定電流、尺寸及配件；取得賣家資料後更新電源模型。機殼與保險絲待此步再選。
2. 核對 IC 實收數量、完整打標及批號；外觀不能證明真偽。T 背板為負電源，保留絕緣導熱介面與螺絲絕緣套。
3. 每顆先裝散熱器，用限流雙電源檢查靜態電流、輸出直流、波形與溫升；先單聲道、假負載測試。
4. 電源獨立量測空載、負載、紋波及放電，再整合雙聲道；DC 保護與啟停驗證後才接喇叭。
5. 放大板小零件可沿用候選清單；PCB、機殼、保護板與一次側元件仍未定案。

## 圖面與 PDF 版本

V0.3 已更新兩份 KiCad 圖的供電與版本標示、PDF／PNG 預覽、BOM 及 22Vac 電源／熱估算。原放大電路與雙橋四電容網路保留；12Vac 控制與一次側只列功能框架，待詳細設計。驗證結果見 electrical/validation.md，沒有硬體量測。

新版 PDF 位於 output/pdf/，包含現行設計彙整及採購勾選清單。2026-09-11 舊 PDF 僅作歷史快照，不作現行採購依據。六張導讀圖已於 2026-09-17 同步方案 C V0.3，見 [導讀圖索引](diagrams/README.md)；舊圖由 Git 歷史保留。

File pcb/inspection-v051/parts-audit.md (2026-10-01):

# 零件與封裝核對表：PCB V0.5.1（放大板變體 D＋電源板，整流橋 GBJ2510 上板）

2026-10-01 依 V0.5.1 板檔重建（放大板同 V0.5）；採購狀態欄沿用 2026-09-22 的文字，之後的量測與到貨請以 docs/00 為準。snubber 預留位與 J204 為 V0.4 新增；V0.5 只改板形與零件位置，新增 C2 站立封裝 `BP_Axial_Vert_D20_P15`（腳距 15 為假設）。這是選料與到貨核對用表，不是驗收紀錄或製板核准；「已購」一律指已下單待到貨，尺寸仍待實測。

**平面尺寸來自現有暫定封裝；高度全部是本輪 3D 顯示假設，不是廠商尺寸，也不是保證能容納實物的最大外框。** 單位均為 mm。孔徑為目前板檔設定，不等於已核准成品孔與腳徑公差。

## 優先核對順序

1. **U1／U2 LM3886T**：完整型號、實物彎腳與腳距、背板位置、安裝孔、散熱器及絕緣介面。現有 `LM3886T_UNVERIFIED` 不應因 3D 看起來合理就定案。
2. **BR1／BR2**：2026-10-01 改為 GBJ2510 直立上板（封裝 `GBJ_Upright_P10_7.5_7.5` 依 Diodes DS21221）；實物到貨核對腳距 10／7.5／7.5、腳 1.0×2.2、孔位，並選定散熱片。
3. **C201–C204**：品牌／系列／完整料號、直徑、高度、腳距、腳形、紋波額定；不可只按 10,000µF／63V 選購。
4. **接頭與保險絲座**：實際腳距、腳徑、插線方向、螺絲工具空間、額定與固定方式。保險絲額定仍待變壓器資料。
5. **其餘被動件與電感**：封裝、功率／電壓額定、極性及溫度條件；若改尺寸，要更新 PCB 並重跑 DRC。

## 逐項尺寸與狀態

表中的單聲道板需要製作兩片；右聲道板使用相同板上編號。原理圖共用 J5 在兩片板上各有一個實體端子，因此整機板上元件數為 22×2＋22＝66（含 6 個不填料的 snubber 預留位），原理圖元件數為 43＋22＝65；差異不代表額外多買一套電源。線束分配仍需設計。

### 單聲道板（下表每項用量 ×2）

| 板上編號／右聲道原理圖 | 值 | 暫定外形寬×深 | 3D 假設高 | 腳距 | 孔徑 | 狀態 |
|---|---|---|---:|---|---|---|
| U1／U2 | LM3886T | 20 × 5 | 22 | 見完整焊盤座標 | 1.1 | 已訂（拆機）到貨未回報；封裝未核對 |
| C3／C103 | 100n / 100V | 8 × 4 | 6.5 | 5 | 0.8 | 已購 WIMA MKS2 100V 已到貨待量 |
| C4／C104 | 100n / 100V | 8 × 4 | 6.5 | 5 | 0.8 | 已購 WIMA MKS2 100V 已到貨待量 |
| C7／C107 | 470u / 63V | 12.5 × 12.5 | 20 | 5 | 1.0 | 已購 ROE EKE 已到貨待量；量直徑腳距 |
| C6／C106 | 470u / 63V | 12.5 × 12.5 | 20 | 5 | 1.0 | 已購 ROE EKE 已到貨待量；量直徑腳距 |
| R4／R104 | 20k / 1% | 5.1 × 2.5 | 2.5 | 7.5 | 0.8 | 已購 MRS25 已到貨待量 |
| R3／R103 | 1k / 1% | 5.1 × 2.5 | 2.5 | 7.5 | 0.8 | 已購 MRS25 已到貨待量 |
| R6／R106 | 1k | 5.1 × 2.5 | 2.5 | 7.5 | 0.8 | 已購 MRS25 已到貨待量 |
| R2／R102 | 22k | 5.1 × 2.5 | 2.5 | 7.5 | 0.8 | 已購 MRS25 已到貨待量 |
| R1／R101 | 1M | 5.1 × 2.5 | 2.5 | 7.5 | 0.8 | 已購 MRS25 已到貨待量 |
| C1／C101 | 2.2u / 100V film | 18 × 8 | 15 | 15 | 1.0 | 已購 WIMA MKS4 100V 已到貨待量 |
| J1／J3 | L RCA | 10.08 × 8 | 12 | 5.08 | 1.3 | 待購／未選料號 |
| C2／C102 | 47u / 63V BP | 20 × 20 | 42 | 15 | 1.2 | 已購 ROE EGW 已量 L40×Ø20；改躺式 P50 封裝，放大板加寬至 115 mm |
| L1／L2 | 0.7uH / air core | 16 × 14 | 14 | 20 | 1.3 | 待購／未選料號 |
| R7／R107 | 10R / 2W | 15 × 5 | 5 | 20 | 1.0 | 已購 PR02 已到貨待量 |
| J2／J4 | L TEST OUT | 10.08 × 8 | 12 | 5.08 | 1.3 | 待購／未選料號 |
| R5／R105 | 2.7R / 2W | 15 × 5 | 5 | 20 | 1.0 | 已購 RNU2 已到貨待量 |
| C5／C105 | 100n / 100V film | 8 × 4 | 6.5 | 5 | 0.8 | 已購 WIMA MKS2 100V 已到貨待量 |
| J5／J5 (shared PSU split into two harnesses) | INTERNAL PSU | 15.16 × 8 | 12 | 5.08 直列 | 1.3 | 待購／未選料號 |
| R8／R108 | 22k / 0.6W | 5.1 × 2.5 | 2.5 | 7.5 | 0.8 | 已購 MRS25 0.6W 已到貨待量 |
| C8／C108 | 100u / 100V | 12.5 × 12.5 | 20 | 5 | 1.0 | 已購 CDE 361R 100V 已到貨待量；量直徑 |
| JP1／JP2 | L RUN LINK | 5.14 × 2.6 | 6 | 2.54 | 1.0 | 待購／未選料號 |
### 電源板（下表每項用量 ×1）

| 板上編號／右聲道原理圖 | 值 | 暫定外形寬×深 | 3D 假設高 | 腳距 | 孔徑 | 狀態 |
|---|---|---|---:|---|---|---|
| J201 | T1 SEC 1 | 10.08 × 8 | 12 | 5.08 | 1.3 | 待購／未選料號 |
| F201 | TBD per transformer | 29 × 7 | 10 | 25 | 1.3 | 待購／未選料號 |
| BR1 | >=15A / >=200V TBD | 30 × 4 | 20 | 見完整焊盤座標 | 2.6 | 待購 GBJ2510（2026-10-01 選定上板）＋散熱片＋M3 螺絲 |
| J202 | T1 SEC 2 | 10.08 × 8 | 12 | 5.08 | 1.3 | 待購／未選料號 |
| F202 | TBD per transformer | 29 × 7 | 10 | 25 | 1.3 | 待購／未選料號 |
| BR2 | >=15A / >=200V TBD | 30 × 4 | 20 | 見完整焊盤座標 | 2.6 | 待購 GBJ2510（2026-10-01 選定上板）＋散熱片＋M3 螺絲 |
| C201 | 10000u / 63V | 35 × 35 | 50 | 10 | 2.5 | 已購 CDE 381LX 已到貨待量；量直徑高度腳距 |
| C202 | 10000u / 63V | 35 × 35 | 50 | 10 | 2.5 | 已購 CDE 381LX 已到貨待量；量直徑高度腳距 |
| C203 | 10000u / 63V | 35 × 35 | 50 | 10 | 2.5 | 已購 CDE 381LX 已到貨待量；量直徑高度腳距 |
| C204 | 10000u / 63V | 35 × 35 | 50 | 10 | 2.5 | 已購 CDE 381LX 已到貨待量；量直徑高度腳距 |
| R201 | 2.2k / 2W BLEED | 15 × 5 | 5 | 20 | 1.0 | 已購 PR02 已到貨待量 |
| R202 | 2.2k / 2W BLEED | 15 × 5 | 5 | 20 | 1.0 | 已購 PR02 已到貨待量 |
| C207 | TBD Cx (10n / 630V film) | 18 × 8 | 15 | 15 | 1.0 | snubber 預留位，只留孔不填料（值待變壓器實測） |
| C208 | TBD Cs (150n / 630V film) | 18 × 8 | 15 | 15 | 1.0 | snubber 預留位，只留孔不填料 |
| R203 | TBD Rs (10R-47R / 2W) | 15 × 5 | 5 | 20 | 1.0 | snubber 預留位，只留孔不填料 |
| C209 | TBD Cx (10n / 630V film) | 18 × 8 | 15 | 15 | 1.0 | snubber 預留位，只留孔不填料 |
| C210 | TBD Cs (150n / 630V film) | 18 × 8 | 15 | 15 | 1.0 | snubber 預留位，只留孔不填料 |
| R204 | TBD Rs (10R-47R / 2W) | 15 × 5 | 5 | 20 | 1.0 | snubber 預留位，只留孔不填料 |
| C205 | 100n / 100V film | 8 × 4 | 6.5 | 5 | 0.8 | 已購 WIMA MKS2 100V 已到貨待量 |
| C206 | 100n / 100V film | 8 × 4 | 6.5 | 5 | 0.8 | 已購 WIMA MKS2 100V 已到貨待量 |
| J203 | TO L AMP J5 | 15.16 × 8 | 12 | 5.08 直列 | 1.3 | 待購／未選料號 |
| J204 | TO R AMP J5 | 15.16 × 8 | 12 | 見完整焊盤座標 | 1.3 | 待購（與 J203 同款 3P 5.08 端子） |

## 到貨／選型記錄欄位

每個料號需補齊：**製造商、完整料號、原廠尺寸圖連結、實收照片或量測、腳距／腳徑／外形／高度、腳位對應、核對日期與結論**。目前全部未完成，因此 `verified=false`、`manufacturer_part_number=null`。

[完整逐項資料與本地焊盤座標](parts-audit.json)；[放大板逐腳／極性](drawings/mono-assembly-notes.md)；[電源板逐腳／極性](drawings/psu-assembly-notes.md)。

## 不在這三張 PCB 上的整機零件

| 項目 | 目前資訊 | 需要補什麼 |
|---|---|---|
| 變壓器 | 已訂；最後採購紀錄待到貨。賣場曾標示 Ø120、高43 | 實物尺寸、固定件、獨立繞組與額定資料；未納入本輪 3D |
| 散熱器、絕緣墊及螺絲套 | 待購／未選料號 | 外形、固定孔、熱阻及絕緣；未納入 3D |
| 機殼、支柱與固定螺絲 | 待定 | 板底焊腳空間、上蓋淨空、工具空間與板孔位置 |
| 面板 RCA、喇叭接線柱 | 待定 | 板上的 J1／J2 是板端端子占位，不是面板插座的外形 |
| 喇叭保護、12Vac 輔助供電及啟停控制 | 待設計 | 模組／電路、供電類型、端子與空間 |
| 一次側、浪湧限制、線束與接地固定點 | 待設計／選型 | 電氣及機構介面，不能從本輪 PCB 3D 推定已完成 |

## 本輪檢視發現

- 目前接頭採方塊模型，**沒有**表達插線口、螺絲方向與工具空間。
- IC 採占位外形，**沒有**表達金屬背板、真正彎腳、固定孔和散熱器。
- 電感採外框方塊，保險絲座採外框；不表示線圈繞法、夾具或可拆裝空間。
- 所有模型的小金屬柱只用來核對焊盤位置，不代表引腳實際成形；模型不含焊錫與生產公差。
- 固定孔是四角暫定 M3 孔，未加支柱或螺絲頭的完整占位，不能據此排除機構干涉。
- 尺寸表與 3D 可先協助選料；真正料號確認後才更新實體封裝及裝配模型。

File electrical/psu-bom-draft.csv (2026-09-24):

reference | quantity | value | symbol | footprint | note
BR1 | 1 | >=15A / >=200V TBD | Bridge |  | Logical pin IDs; map to selected MPN before PCB; cooling/IFSM TBD
BR2 | 1 | >=15A / >=200V TBD | Bridge |  | Logical pin IDs; map to selected MPN before PCB; cooling/IFSM TBD
C201 | 1 | 10000u / 63V | CP |  | Pin1 positive; ripple rating and dimensions TBD
C202 | 1 | 10000u / 63V | CP |  | Pin1 positive; ripple rating and dimensions TBD
C203 | 1 | 10000u / 63V | CP |  | Pin1 positive; ripple rating and dimensions TBD
C204 | 1 | 10000u / 63V | CP |  | Pin1 positive; ripple rating and dimensions TBD
C205 | 1 | 100n / 100V film | C |  | Component selection/footprint TBD
C206 | 1 | 100n / 100V film | C |  | Component selection/footprint TBD
C207 | 1 | TBD Cx (10n / 630V film) | C |  | Component selection/footprint TBD
C208 | 1 | TBD Cs (150n / 630V film) | C |  | Component selection/footprint TBD
C209 | 1 | TBD Cx (10n / 630V film) | C |  | Component selection/footprint TBD
C210 | 1 | TBD Cs (150n / 630V film) | C |  | Component selection/footprint TBD
F201 | 1 | TBD per transformer | Fuse |  | Rating and breaking capacity TBD; this is not a selected fuse
F202 | 1 | TBD per transformer | Fuse |  | Rating and breaking capacity TBD; this is not a selected fuse
J201 | 1 | T1 SEC 1 | Conn2 |  | Component selection/footprint TBD
J202 | 1 | T1 SEC 2 | Conn2 |  | Component selection/footprint TBD
J203 | 1 | TO L AMP J5 | Conn3 |  | Component selection/footprint TBD
J204 | 1 | TO R AMP J5 | Conn3 |  | Component selection/footprint TBD
R201 | 1 | 2.2k / 2W BLEED | R |  | Component selection/footprint TBD
R202 | 1 | 2.2k / 2W BLEED | R |  | Component selection/footprint TBD
R203 | 1 | TBD Rs (10R-47R / 2W) | R |  | Component selection/footprint TBD
R204 | 1 | TBD Rs (10R-47R / 2W) | R |  | Component selection/footprint TBD

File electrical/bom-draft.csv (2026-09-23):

reference | quantity | value | symbol | footprint | selection_notes
C1 | 1 | 2.2u / 100V film | C |  | Film unless 47u BP (nonpolar); 100n supply bypass may use X7R
C2 | 1 | 47u / 63V BP | C |  | Film unless 47u BP (nonpolar); 100n supply bypass may use X7R
C3 | 1 | 100n / 100V | C |  | Film unless 47u BP (nonpolar); 100n supply bypass may use X7R
C4 | 1 | 100n / 100V | C |  | Film unless 47u BP (nonpolar); 100n supply bypass may use X7R
C5 | 1 | 100n / 100V film | C |  | Film unless 47u BP (nonpolar); 100n supply bypass may use X7R
C6 | 1 | 470u / 63V | CP |  | Polarized; pin 1 positive, pin 2 negative; verify ripple and temperature rating
C7 | 1 | 470u / 63V | CP |  | Polarized; pin 1 positive, pin 2 negative; verify ripple and temperature rating
C8 | 1 | 100u / 100V | CP |  | Polarized; pin 1 positive, pin 2 negative; verify ripple and temperature rating
C101 | 1 | 2.2u / 100V film | C |  | Film unless 47u BP (nonpolar); 100n supply bypass may use X7R
C102 | 1 | 47u / 63V BP | C |  | Film unless 47u BP (nonpolar); 100n supply bypass may use X7R
C103 | 1 | 100n / 100V | C |  | Film unless 47u BP (nonpolar); 100n supply bypass may use X7R
C104 | 1 | 100n / 100V | C |  | Film unless 47u BP (nonpolar); 100n supply bypass may use X7R
C105 | 1 | 100n / 100V film | C |  | Film unless 47u BP (nonpolar); 100n supply bypass may use X7R
C106 | 1 | 470u / 63V | CP |  | Polarized; pin 1 positive, pin 2 negative; verify ripple and temperature rating
C107 | 1 | 470u / 63V | CP |  | Polarized; pin 1 positive, pin 2 negative; verify ripple and temperature rating
C108 | 1 | 100u / 100V | CP |  | Polarized; pin 1 positive, pin 2 negative; verify ripple and temperature rating
J1 | 1 | L RCA | Conn2 |  | Connector/panel hardware TBD; RUN switch contacts >=60V DC if substituted
J2 | 1 | L TEST OUT | Conn2 |  | Connector/panel hardware TBD; RUN switch contacts >=60V DC if substituted
J3 | 1 | R RCA | Conn2 |  | Connector/panel hardware TBD; RUN switch contacts >=60V DC if substituted
J4 | 1 | R TEST OUT | Conn2 |  | Connector/panel hardware TBD; RUN switch contacts >=60V DC if substituted
J5 | 1 | INTERNAL PSU | Conn3 |  | Internal PSU harness; pin1 VCC, pin2 GND, pin3 VEE; current rating TBD
JP1 | 1 | L RUN LINK | Conn2 |  | Connector/panel hardware TBD; RUN switch contacts >=60V DC if substituted
JP2 | 1 | R RUN LINK | Conn2 |  | Connector/panel hardware TBD; RUN switch contacts >=60V DC if substituted
L1 | 1 | 0.7uH / air core | L |  | Air core; DCR <=0.05 ohm target; >=4A peak; thermal validation required
L2 | 1 | 0.7uH / air core | L |  | Air core; DCR <=0.05 ohm target; >=4A peak; thermal validation required
R1 | 1 | 1M | R |  | 1% metal film; 0.25W unless value specifies 2W; output resistors low inductance
R2 | 1 | 22k | R |  | 1% metal film; 0.25W unless value specifies 2W; output resistors low inductance
R3 | 1 | 1k / 1% | R |  | 1% metal film; 0.25W unless value specifies 2W; output resistors low inductance
R4 | 1 | 20k / 1% | R |  | 1% metal film; 0.25W unless value specifies 2W; output resistors low inductance
R5 | 1 | 2.7R / 2W | R |  | 1% metal film; 0.25W unless value specifies 2W; output resistors low inductance
R6 | 1 | 1k | R |  | 1% metal film; 0.25W unless value specifies 2W; output resistors low inductance
R7 | 1 | 10R / 2W | R |  | 1% metal film; 0.25W unless value specifies 2W; output resistors low inductance
R8 | 1 | 22k / 0.6W | R |  | 1% metal film; 0.25W unless value specifies 2W; output resistors low inductance
R101 | 1 | 1M | R |  | 1% metal film; 0.25W unless value specifies 2W; output resistors low inductance
R102 | 1 | 22k | R |  | 1% metal film; 0.25W unless value specifies 2W; output resistors low inductance
R103 | 1 | 1k / 1% | R |  | 1% metal film; 0.25W unless value specifies 2W; output resistors low inductance
R104 | 1 | 20k / 1% | R |  | 1% metal film; 0.25W unless value specifies 2W; output resistors low inductance
R105 | 1 | 2.7R / 2W | R |  | 1% metal film; 0.25W unless value specifies 2W; output resistors low inductance
R106 | 1 | 1k | R |  | 1% metal film; 0.25W unless value specifies 2W; output resistors low inductance
R107 | 1 | 10R / 2W | R |  | 1% metal film; 0.25W unless value specifies 2W; output resistors low inductance
R108 | 1 | 22k / 0.6W | R |  | 1% metal film; 0.25W unless value specifies 2W; output resistors low inductance
U1 | 1 | LM3886T | LM3886 |  | LM3886T/NOPB; non-isolated T package; footprint TBD
U2 | 1 | LM3886T | LM3886 |  | LM3886T/NOPB; non-isolated T package; footprint TBD

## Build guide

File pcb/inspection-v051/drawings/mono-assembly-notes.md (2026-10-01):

# 單聲道放大板：組裝與接腳對照

2026-10-01；PCB V0.5.1 工程草稿（放大板變體 D 同 V0.5、電源板 V0.5.1 整流橋 GBJ2510 上板）。下列為板檔網路，不代表實物腳位已核准。

兩片單聲道板絲印相同；右聲道原理圖編號請看 [左右聲道對照](../../mono-channel-mapping.csv)。

| 板上編號 | 元件值 | 焊盤號＝網路 | 注意事項 |
|---|---|---|---|
| U1 | LM3886T | 1=VCC / 2=unconnected-(U1-NC-Pad2) / 3=L_OUT / 4=VEE / 5=VCC / 6=unconnected-(U1-NC-Pad6) / 7=GND / 8=L_MUTE / 9=L_INV / 10=L_PLUS / 11=unconnected-(U1-NC-Pad11) | 1=VCC；2=unconnected-(U1-NC-Pad2)；3=L_OUT；4=VEE；5=VCC；6=unconnected-(U1-NC-Pad6)；7=GND；8=L_MUTE；9=L_INV；10=L_PLUS；11=unconnected-(U1-NC-Pad11) |
| C3 | 100n / 100V | 1=VCC / 2=GND | 依料號核對額定、腳徑與安裝方式 |
| C4 | 100n / 100V | 1=GND / 2=VEE | 依料號核對額定、腳徑與安裝方式 |
| C7 | 470u / 63V | 1=VCC / 2=GND | 有極性：1=正、2=負；1=VCC；2=GND |
| C6 | 470u / 63V | 1=GND / 2=VEE | 有極性：1=正、2=負；1=GND；2=VEE |
| R4 | 20k / 1% | 1=L_INV / 2=L_OUT | 依料號核對額定、腳徑與安裝方式 |
| R3 | 1k / 1% | 1=L_FB_AC / 2=L_INV | 依料號核對額定、腳徑與安裝方式 |
| R6 | 1k | 1=L_AC / 2=L_PLUS | 依料號核對額定、腳徑與安裝方式 |
| R2 | 22k | 1=GND / 2=L_PLUS | 依料號核對額定、腳徑與安裝方式 |
| R1 | 1M | 1=GND / 2=L_IN | 依料號核對額定、腳徑與安裝方式 |
| C1 | 2.2u / 100V film | 1=L_IN / 2=L_AC | 依料號核對額定、腳徑與安裝方式 |
| J1 | L RCA | 1=L_IN / 2=GND | 1=L_IN；2=GND |
| C2 | 47u / 63V BP | 1=GND / 2=L_FB_AC | 必須無極性 BP；不可以一般有極性電解直接替代 |
| L1 | 0.7uH / air core | 1=L_OUT / 2=L_SPK | 依料號核對額定、腳徑與安裝方式 |
| R7 | 10R / 2W | 1=L_OUT / 2=L_SPK | 依料號核對額定、腳徑與安裝方式 |
| J2 | L TEST OUT | 1=L_SPK / 2=GND | 1=L_SPK；2=GND |
| R5 | 2.7R / 2W | 1=L_ZOBEL / 2=L_OUT | 依料號核對額定、腳徑與安裝方式 |
| C5 | 100n / 100V film | 1=GND / 2=L_ZOBEL | 依料號核對額定、腳徑與安裝方式 |
| J5 | INTERNAL PSU | 1=VCC / 2=GND / 3=VEE | 1=VCC；2=GND；3=VEE |
| R8 | 22k / 0.6W | 1=L_MUTE / 2=L_RUN | 依料號核對額定、腳徑與安裝方式 |
| C8 | 100u / 100V | 1=GND / 2=L_MUTE | 有極性：1=正、2=負；1=GND；2=L_MUTE |
| JP1 | L RUN LINK | 1=L_RUN / 2=VEE | 1=L_RUN；2=VEE |

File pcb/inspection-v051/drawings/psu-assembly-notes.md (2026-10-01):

# 共用電源板：組裝與接腳對照

2026-10-01；PCB V0.5.1 工程草稿（放大板變體 D 同 V0.5、電源板 V0.5.1 整流橋 GBJ2510 上板）。下列為板檔網路，不代表實物腳位已核准。

BR1／BR2 是 GBJ2510 直立整流橋（P＝＋、N＝－、AC1／AC2＝～；金屬背朝板邊、鎖散熱片）；C207–C210／R203／R204 為 snubber 預留位，只留孔不填料。

| 板上編號 | 元件值 | 焊盤號＝網路 | 注意事項 |
|---|---|---|---|
| J201 | T1 SEC 1 | 1=POS_AC1 / 2=POS_AC2 | 1=POS_AC1；2=POS_AC2 |
| F201 | TBD per transformer | 1=POS_AC1 / 2=POS_AC_FUSED | 依料號核對額定、腳徑與安裝方式 |
| BR1 | >=15A / >=200V TBD | AC1=POS_AC_FUSED / AC2=POS_AC2 / N=GND / P=VCC | GBJ2510 直立：P＝＋、N＝－、AC1／AC2＝～（原廠腳序 + ~ ~ -）；印字面朝電容、金屬背朝板邊（粗絲印線那側）裝散熱片；實物到貨核對腳距 10／7.5／7.5 |
| J202 | T1 SEC 2 | 1=NEG_AC1 / 2=NEG_AC2 | 1=NEG_AC1；2=NEG_AC2 |
| F202 | TBD per transformer | 1=NEG_AC1 / 2=NEG_AC_FUSED | 依料號核對額定、腳徑與安裝方式 |
| BR2 | >=15A / >=200V TBD | AC1=NEG_AC_FUSED / AC2=NEG_AC2 / N=VEE / P=GND | GBJ2510 直立：P＝＋、N＝－、AC1／AC2＝～（原廠腳序 + ~ ~ -）；印字面朝電容、金屬背朝板邊（粗絲印線那側）裝散熱片；實物到貨核對腳距 10／7.5／7.5 |
| C201 | 10000u / 63V | 1=VCC / 2=GND | 有極性：1=正、2=負；1=VCC；2=GND |
| C202 | 10000u / 63V | 1=VCC / 2=GND | 有極性：1=正、2=負；1=VCC；2=GND |
| C203 | 10000u / 63V | 1=GND / 2=VEE | 有極性：1=正、2=負；1=GND；2=VEE |
| C204 | 10000u / 63V | 1=GND / 2=VEE | 有極性：1=正、2=負；1=GND；2=VEE |
| R201 | 2.2k / 2W BLEED | 1=VCC / 2=GND | 依料號核對額定、腳徑與安裝方式 |
| R202 | 2.2k / 2W BLEED | 1=GND / 2=VEE | 依料號核對額定、腳徑與安裝方式 |
| C207 | TBD Cx (10n / 630V film) | 1=POS_AC2 / 2=POS_AC1 | 依料號核對額定、腳徑與安裝方式 |
| C208 | TBD Cs (150n / 630V film) | 1=POS_AC2 / 2=POS_SNUB | 依料號核對額定、腳徑與安裝方式 |
| R203 | TBD Rs (10R-47R / 2W) | 1=POS_SNUB / 2=POS_AC1 | 依料號核對額定、腳徑與安裝方式 |
| C209 | TBD Cx (10n / 630V film) | 1=NEG_AC2 / 2=NEG_AC1 | 依料號核對額定、腳徑與安裝方式 |
| C210 | TBD Cs (150n / 630V film) | 1=NEG_AC2 / 2=NEG_SNUB | 依料號核對額定、腳徑與安裝方式 |
| R204 | TBD Rs (10R-47R / 2W) | 1=NEG_SNUB / 2=NEG_AC1 | 依料號核對額定、腳徑與安裝方式 |
| C205 | 100n / 100V film | 1=VCC / 2=GND | 依料號核對額定、腳徑與安裝方式 |
| C206 | 100n / 100V film | 1=GND / 2=VEE | 依料號核對額定、腳徑與安裝方式 |
| J203 | TO L AMP J5 | 1=VCC / 2=GND / 3=VEE | 1=VCC；2=GND；3=VEE |
| J204 | TO R AMP J5 | 1=VCC / 2=GND / 3=VEE | 1=VCC；2=GND；3=VEE |

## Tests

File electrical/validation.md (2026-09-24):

# V0.3 電氣驗證紀錄

本報告由 `python3 tools/rebuild.py` 在 KiCad 10.0.6 完成檢查後產生。

| 檢查 | 結果 |
|---|---|
| 原理圖載入與 PDF 匯出 | 通過 |
| KiCad ERC，未排除規則 | 0 錯誤、0 警告 |
| 元件數 | 43，BOM 由 KiCad netlist 匯出 |
| IC 及被動元件數值 | 與獨立設計規格一致 |
| 網路與腳位核對 | 29 個網路、105 個元件腳位通過獨立規格比對；包含 6 個單腳 NC 網路 |
| 正負電源與 IC 腳位 | pin 1/5=VCC、4=VEE、7=GND；2/6/11 不接 |
| 回授、輸出隔離、左右聲道 | 拓樸及網路連接通過 |
| 負軌與靜音電解極性 | 正端在 GND，負端分別在 VEE／MUTE |
| 手動靜音回路 | 各聲道 pin 8→電阻→RUN 跳線→VEE，兩個控制節點分開 |

ERC 與網路核對不驗證 PCB 寄生、穩定度、失真、散熱、保護或喇叭相容性。本版尚無 footprint／PCB、SPICE 元件模擬或硬體量測。計算報告是理想模型，不能當實測。

產生的 `erc.json`／`netlist.xml` 為本機檢查中間檔，未版控。BOM、PDF、PNG 及本報告隨版本提交。KiCad 檔案中的符號庫檢查未關閉。

## 內建電源次級圖

ERC 0 錯誤、0 警告；15 個元件、9 個網路、35 個腳位通過獨立核對。兩個次級 AC 回路、橋式整流輸出串接、濾波／洩放極性及 J203→放大板 J5 的三線接序已核對。

這是兩個獨立 KiCad 專案，以線束相連；ERC 不會自動檢查跨檔接線。Bridge 的 AC1／AC2／P／N 為功能端子，未選實體料號或 footprint。沒有完成一次側接線、軟啟動、保護控制器、PCB、耐壓／接地測試或實機量測。

## 內建電源次級圖

ERC 0 錯誤、0 警告；22 個元件、11 個網路、50 個腳位通過獨立核對。兩個次級 AC 回路、橋式整流輸出串接、濾波／洩放極性及 J203／J204（每聲道一組）→放大板 J5 的三線接序已核對；每組次級繞組留有 Cx‖(Rs+Cs) 緩衝提供位（V0.4，元件值待量）。

這是兩個獨立 KiCad 專案，以線束相連；ERC 不會自動檢查跨檔接線。Bridge 的 AC1／AC2／P／N 為功能端子，未選實體料號或 footprint。沒有完成一次側接線、軟啟動、保護控制器、PCB、耐壓／接地測試或實機量測。

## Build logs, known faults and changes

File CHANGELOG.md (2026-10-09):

# 變更紀錄

本檔集中原本散在 README.md 與 HANDOFF.md 的逐日進度紀錄，新的在上。
現行狀態看 [README.md](README.md)，接手工作看 [HANDOFF.md](HANDOFF.md)，採購看 [docs/00-採購總表.md](docs/00-採購總表.md)。

紀錄一律保留當時的措辭與限制聲明；日期後面的段落不代表現在仍然成立，只代表當天做了什麼。

---

## 2026-10-09：補兩張到貨照片

- 使用者補傳 2026-09-22、09-23 手機照（HEIC，轉 JPG 長邊 2000）：（電容、電阻分袋攤開）、（環形變壓器實物，docs/00 變壓器列 09-23 初量處已加連結）。照片只作紀錄，未從照片讀新數值。

## 2026-10-08：放大板＋電源板 V0.6.1 第一次送嘉立創（試印）

- 使用者決定**不等實量先送看看**：IC 背板三數、C2 站立腳距 15、弘宙 102 內寬都**未核對**，不合就修正再印。只送放大板與電源板；CTRL／MAINS 先不送（UPC1237 在 12 V 未驗、G2RL 腳位未核、牽涉市電）。
- 送件檔：`kicad-cli pcb export gerbers`（F/B Cu、Mask、Silk、Edge.Cuts）＋`export drill`（Excellon mm、PTH／NPTH 分開），壓成 `pcb/fab-20261008/mono-layout-v061-gerber.zip`、`psu-layout-v061-gerber.zip`。核過：最細線 0.35（放大板）／0.8 mm（電源板）、最小孔 0.8 mm、電源板 8 個 GBJ 長孔、NPTH 3.2 固定孔。
- 嘉立創國際站（jlcpcb.com）訂單：Y2-13757387A 放大板 90×80 ×5、Y3-13757387A 電源板 120×92 ×5（超過 100×100 無特價）。FR-4 TG135、2 層、1.6 mm、綠底白字、HASL 有鉛、**1 oz**（選 2 oz 放大板會從 US$4 跳到 39.5，試印改回 1 oz，定版再考慮 2 oz）、Tented、飛針全測、直接付款。順豐速運、新會員券 −US$6、PayPal 付款，**訂單總額 US$12.87**（訂單頁）。2026-10-08 付款成功，預計 10-10 出貨；台灣通關要 EZ WAY 申報相符。
- 右聲道沿用同一片轉 180°（沒有鏡像板），J1 輸入會朝前靠近變壓器；先用屏蔽線試聽，有哼聲再出鏡像板。
- **到貨先乾插不要焊**：IC 背板是否齊板邊並對得上散熱器、C2 腳距、GBJ 長孔、381LX 腳距 10、端子；不合就記下並修 V0.6.x。

## 2026-10-03：PCB V0.6.1 走線加寬候選（分支 `v061-layout`，未併 main）

- 使用者問「V0.6 走線能不能再粗一些、減少電阻」。先用 `analyze_pcb_v03` 的模型算 V0.6 兩板 23 條載流路徑：每條 2–30 mΩ（1 oz），對喇叭 8 Ω、變壓器二次側 0.25／0.2 Ω、繼電器接點都是零頭；但放大板負電源腳間線 0.5 mm（占該路徑 54 %）與電源板 AC 回線（−）2.0 mm 明顯比同類細。使用者決定做 **V0.6.1**：零件、擺位、板尺寸、102 機殼與 150×90×30 散熱器全部不動，只加寬。
- `tools/pcb_layout_v061.py` 匯入 V0.6 定義，依 (網路, 群組, 原寬) 表覆寫寬度：放大板 負電源腳間線 0.5→0.9（焊盤 1.8／腳距 3.4 的硬上限 1.0，腳 3 輸出短線 2.0→1.8 才夠 0.3 間距）、腳 1／5 底層短線 1→2、470 µF→IC 2→3／1.5→2.5、饋線 3→4（負饋線只到 3.5，x=58 夾在 C5 與 C2.2 之間）、輸出主幹 3→4 並把兩個轉折點左上移 0.6 避開 VCC 饋線（Zobel 饋線改接新頂點，T 接點不算連接）；電源板 主幹 3→5、VEE 輸出 2.5→4、AC 回線（−）2→4、星點 3→4（5 會離 R202.2 只剩 0.30）、進 5.08 端子焊盤的末段維持 3。
- DRC：放大板首輪 0 錯誤；電源板首輪 2 錯誤（POS_AC2 的 5.0 端蓋在 (13.5,112.5) 壓到 J201.1 焊盤）→ 寬段改從 y=110 起 → 0 錯誤、0 未連通。`verify_pcb_v061.py` 通過；`analyze_pcb_v061.py` 出 V0.6 vs V0.6.1 對照表（放大板負電源 29.8→18.5 mΩ、電源板主幹 −40 %、AC 回線（−）−50 %、23 條合計發熱 1.99→1.23 W），寫進 pcb/README「PCB V0.6.1」節與 `current-budget-v061.json`。回授線長與 V0.6 相同。
- 另提醒：訂板選 2 oz 可再把全部數字減半，含改不寬的腳間線。**使用者看圖後「沒問題就併入 main」→ 同日 fast-forward 併入，V0.6.1 為放大板／電源板現行版；README／pcb/README／HANDOFF／tools/README 同步。**

## 2026-10-02（凌晨）：放大板與電源板 PCB V0.6——V0.6 五板齊，機箱 3D 換成真板

- 使用者決定不等 IC 實量與機殼內寬，先以型錄規格畫。**放大板 `mono-layout-v06` 90×80**：U1 改用 KiCad 函式庫 `TO-220-11_P3.4x5.08mm_StaggerOdd_Lead4.58mm_Vertical`（複製成 `LM3886T_TO220-11`，背板在奇數腳後 9.58 mm、偶數腳前 5.08），放在 y=9.58 使背板與板邊齊平（方案 B）。IC 上方不能走線：Kelvin 改底層 y=17.5、靜音線從腳 7／9 間下來走 y=12、L_PLUS 的 R6→R2 段改底層跳過靜音線、pin 1／5 V+ 用底層 1 mm 短線在兩排腳之間相連（KiCad 不把同網路焊盤視為相通，V0.5 的頂層跳線拿掉後曾出現未連通）。板 90×90→90×80，J2／J5／R8／C8／JP1 上移、C2 到 y=52（避開 C6 外框）。DRC 三輪→0 錯誤。
- **電源板 `psu-layout-v06` 92×120**（原目標 87 放不下兩欄 Ø35 加 10 mm 洩放電阻縫，加寬到 92，機殼寬餘裕夠）：正欄 x=21、負欄 x=71，四顆都轉 180 讓正極在內側；VCC 頂層 x=26、GND 底層兩欄＋底層 y=78 星點連線、VEE 頂層 x=66；左輸出 VEE 走底層 y=24.5 繞過 VCC 匯流；GBJ 轉 180 放 y=90（散熱片朝保險絲），保險絲 y=106.5、AC 端子 y=116、直流 3P 端子後緣 y=4。**snubber 預留位未上板**（verify 列出 C207–C210／R203／R204 未放）。DRC 三輪→0 錯誤。
- 工具：`pcb_layout_v06.py`、`build_pcb_v06.py`、`verify_pcb_v06.py`（含 U1 背板貼邊、GBJ +y 側散熱片包絡）、`render_pcb_v06.py`（五板同比例 `system-layout-v06.png`）。
- **3D**：`draw_chassis_scene_v06.py` 改成五塊板都吃 STL，`place_board(name, origin, rot)` 只用純旋轉——發現前一版把右聲道放大板畫成鏡像是不可能的實體：同一塊板轉 180° 貼右側散熱器後 **RCA 端子會在前側**，右聲道輸入線要沿板邊拉約 90 mm（或日後另出鏡像板）。
- pcb/README「PCB V0.6」擴成五板現行、V0.5.1 退歷史；tools/README、HANDOFF、README 同步。

## 2026-10-01（深夜 2）：控制板 CTRL 與市電板 MAINS 的 PCB V0.6、弘宙 102 機箱 3D 配置

- **原理圖微調後再畫板**：繼電器全部改 Omron **G2RL-1-E**（低背 16 A、線圈 33 mA；KiCad 函式庫有封裝與 3D 模型，G2R-1-E／G5LE-1 沒有或腳位不確定）；輔助電源橋 DF06M 改成 **1N4007 ×4**（D306–D309，封裝無疑義）；光耦改 **SFH617A-3**（DIP-4，Vceo 70 V；H11D1 是 6 腳）；pin 6 與 D301 節點補標籤 RLYDRV／ACSENSE。ERC 仍 0。
- **PCB**：`tools/pcb_layout_v06_ctrl.py`＋`build_pcb_v06_ctrl.py` → `pcb/ctrl-layout-v06`（70×120，49 件）與 `pcb/mains-layout-v06`（70×100，11 件）。封裝：G2RL／SIP-8／DIP-4／TO-92 wide／TO-220／DO-41／DO-35 由 KiCad 函式庫複製進 DraftV03.pretty 並把焊盤編號改成腳名（G2RL 的 11→COM、14→NO、刪 12；每個觸點兩個焊盤要用短線相連，KiCad 不把同號焊盤視為相通）；TO-92 窄版 1.27 間距過不了 0.3 mm 間隙規則，改 wide 版。DRC 三輪→兩板 **0 錯誤、0 未連通**（剩絲印警告）。`verify_pcb_v06_ctrl.py`：MAINS 市電／低壓銅箔最小距離 7.25 mm（L_IN 焊盤 vs TRIG_P 走線）。
- **3D**：`tools/draw_chassis_scene_v06.py`（pyvista，`py -3.13 -m pip install pyvista`）：kicad-cli 匯出 CTRL／MAINS STL（含函式庫模型；G2RL 模型未隨 KiCad 安裝，以方塊補），散熱器 150×90×30、變壓器、放大板與電源板 V0.6 目標外形示意 → `docs/diagrams/chassis_102_v06_3d.png`（等角＋俯視）。**座標教訓**：2D 配置圖的 x（從正面看的左右）在 VTK 右手座標要鏡射 x 才一致；kicad-cli STL 的 Y＝−板 y、板頂 z=0。另輸出 .gltf（.gitignore）。
- **配置修正**：102 多出的寬度不能分到散熱器與放大板之間——IC 要直接鎖散熱器底板，放大板必須緊貼散熱器區（x 55）；餘裕只放在放大板與電源板之間（各 18）。前一節的「四個縫各 9」作廢。
- pcb/README 新增 V0.6 節；tools/README 新增 V0.6 家族；HANDOFF 現況與下一步更新；.gitignore 補 gltf 與 STL 目錄。

## 2026-10-01（深夜）：機殼改向弘宙 102、散熱器內置、控制／保護板第一版原理圖

- **機殼**：使用者決定「先挑殼、散熱器放殼內、以現有零件重排 PCB」。依型錄（雙面板前附把手 1 series）比較 103（d355×c285×e105）與 102（d395×c290×e105），**選 102**：內尺寸估 393×273×100。配置圖（本場 scratchpad，尚未進 repo）：後排 放大板 L 80×90｜電源板 87×120｜放大板 R 80×90，變壓器前排中央，控制板 70×120 平放左側、市電板右側；三板目標尺寸對 103 也成立，102 多出的 40 mm 分成四個縫。合板（每聲道放大＋電容）在這兩個殼都塞不下，不採用。CASE106（內 230×165）判定不可能。
- **散熱器規格改為 8 Ω 連續正弦**（使用者選）：Tj 125 − Ta 40 = 85 K、Pd,max 34 W（±33.5 V／8 Ω）→ θSA ≤ 1.2 °C/W；估法 θSA ≈ 1000／表面積(cm²)（±30%）。買 150 長 × 90 高 × 30 深黑色鋁擠 ×2，鰭片朝牆、底板朝板、每側含空氣通道吃 53–55 mm，上蓋與底板須開通風孔。原 0.4 °C/W 是 ±41 V 前提下的保守值。
- **控制／保護板原理圖第一版**：新增 `tools/build_control_board.py` → `electrical/control-v01.kicad_sch`（CTRL，46 件）與 `electrical/mains-v01.kicad_sch`（MAINS，11 件），兩張 ERC 0 違規，預覽在 `electrical/preview/`。決定：自製、UPC1237 晶片（UTC QW-R107-065.B）、Omron G2R-1-E 12VDC ×3（K_SPK×2、K_BYP）＋G5LE-1 12VDC（K_TRIG）、Ametherm SL22 10005 NTC、兩塊板。與 docs/14 §3 的差異：解除靜音綁在喇叭繼電器（光耦 LED 由 RLY 節點供電），不另做 1–2 s 計時；UPC1237 以 +12 V 供電而非型錄 25–60 V（pin 8 為 3.4 V 參考，R301 3.3k 給 2.6 mA）；pin 6 經 PNP 推兩顆線圈（88 mA > 80 mA 上限）；K_BYP 計時用 TL431 當比較器（220k／22µ，約 1.1 s）。全部為第一版數值，無量測。
- `build_schematic.py`：Drawing 增加 date／rev／comment 欄位；盒狀符號（Relay、UPC1237、Opto、Reg78、TL431、PNP、NPN）的參考與數值文字改放符號上方。`.gitignore` 補 `electrical/*-erc.json`、`*-netlist.xml`。
- 繼電器 DC 分斷：docs/14 要求 ≥36 VDC／9 A，市售小型繼電器找不到；使用者接受 G2R-1-E 的 30 VDC 等級（故障時 33.5 V／8 Ω 4.5 A 一次性分斷）。

## 2026-10-01（傍晚）：repo 整理——文件對齊 V0.5.1、版控雜物清掉

- **HANDOFF.md 整份重寫**：原「下一步」是 9 月累積的 1–7＋5b＋5c，仍寫著「整流橋 KBPC2510 鎖機殼定案」「機殼未選定」「LM3886T 到貨未回報」等已作廢內容；改成 2026-10-01 現況＋七步順序待辦＋V0.5.1 重建指令＋分支說明，逐日細節全部交給本檔。
- **tools/README.md 整份重寫**：原本停在「PCB V0.3（現行）」，v04／v05／v051 共 24 支腳本沒列；改成按版本家族列出，並註明 `mains_budget.py` 輸出到 stdout（docs/06 早已併入 docs/05）。
- README 目錄表「PCB／PCB 看圖資料」兩列改指 V0.5.1 與 inspection-v051；docs/diagrams/README 補註六張圖對 V0.5.1 仍適用（電路未變，只有橋堆線束那段不存在）。
- **版控**：`.gitignore` 漏加 v051 那段，使 `pcb/inspection-v051/3d/` 的 24 個中間產物（`models/*.wrl`、`*-preview.kicad_*`、`raw-*.png`）被 commit 進來；補規則並 `git rm --cached`（磁碟上檔案保留）。已併入 main 的本地分支 `v04-layout`、`v05-layout` 刪除；`v052-layout`（未採用合板候選）依使用者決定保留。
- 使用者指出 README 首頁「目前狀態」標題仍是 09-24、系統圖仍是 V0.5：狀態節重寫為 2026-10-01 現況；`render_pcb_v051.py` 加系統視圖 `pcb/preview/system-layout-v051.png`（兩片放大板 D＋V0.5.1 電源板，同比例），README 與 pcb/README 首圖改用它。
- 無電路、板檔、估算變動。

## 2026-10-01（下午）：PCB V0.5.1——電源板整流橋 GBJ2510 直立上板，併入 main

- 使用者問整流橋能否放回電源板。查原廠：GBJ2510（Diodes DS21221）直立 30×20×3.8、扁腳 1.0×2.2、腳距 10／7.5／7.5、腳序 ＋ ～ ～ －、IFSM 350 A、RθJC 1.0；KBPC2510W（Goodark）28.5 mm 方塊、Ø1.0 圓腳間距 17–19，塞不進 V0.5 上緣 27 mm 條帶。建議 GBJ2510，使用者選定。
- 新封裝 `GBJ_Upright_P10_7.5_7.5`（`build_pcb_v051.py` 的 `make_fp_oval`，長孔 2.6×1.4、焊盤 3.8×2.6，絲印標 ＋～～－ 與散熱面粗線）；`pcb_layout_v051_psu.py` 由 V0.5 衍生，只覆寫 BR1 (19,23,0)、BR2 (81,23,0) 與進出整流橋的七條走線。BR2 不像 V0.5 旋轉 180（否則金屬背朝電容），右半另佈。板 125×130 不變。
- DRC 兩輪：第一輪 2 條絲印重疊（HS 字壓到散熱面標線，上移 0.6），第二輪 0 違規 0 未連通。`verify_pcb_v051.py` 另檢查橋體與 10 mm 散熱片包絡不撞任何零件（離保險絲座 1.0、離電容外框 1.5 mm）。預覽 `psu-layout-v051.png`、對照 `psu-layout-v051-compare.png` 傳使用者，**使用者「我覺得 OK 可以 main」→ ff 併入 main，V0.5 電源板退為歷史、放大板 D 沿用。**
- `pcb/inspection-v051/` 由 v05 六支腳本衍生（GBJ 高度假設 20 mm）：正反面／組裝／3D／零件核對重做並通過驗證。
- 採購：docs/00 §2.1 新增 GBJ2510 ×2 與小散熱片＋M3 固定件兩列（散熱片選法：鋁鰭片寬 ≤30、厚 ≤10、高 25–35、M3 孔，估 8–12 °C/W），KBPC2510／M5 固定件／Faston 線三列作廢；§1.1、§3、docs/05、README、HANDOFF 同步。

## 2026-10-01：變壓器電氣實量（直流電阻、空載電壓、線色分組、標籤電流）

- 使用者以三用電表量測並手寫記錄（`docs/photos/20261001-transformer-electrical.jpg`）：一次側 R／B 線 DCR 約 1.9–2.0 Ω（讀值已扣表筆）；12V 繞組 Y／Y 空載 12.27 Vac、0.4 Ω；22V 第 1 組 G／B 空載 22.29 Vac、0.25 Ω；22V 第 2 組 B／B 空載 22.29 Vac、0.2 Ω；兩組 22V 中間接在一起後 G 到另一端 B 讀 44.6 Vac、串接 DCR 0.4 Ω，確認兩組同相可當 22-0-22。電壓以 1 kΩ 假負載量，等同空載。
- 標籤抄錄：22V 4.2A×2、12V 1A ⇒ 約 197 VA（手寫判讀 4.2，待再核對）。由此初定保險絲提案：一次側 T2.5A（有軟啟動）或 T3.15A、22V 各 T5A、12V T1.25A。
- 由直流電阻推估滿載銅損約 15 W、每組 22V 調整率約 7–8%；與「空載只比標籤高 1.3%」對不上，可能原因是量測時市電低於 110 V。**量測當下市電未記**，下次量要同時量市電。若當時為 110 V，最壞情境軌電壓由 ±35.8 降為 ±33.5 V；市電對照量出前，選料仍以 ±35.8 V 核對。
- 第 2 組 22V 兩條線都記為 B（黑／藍／棕未分），裝機前要再用導通表分一次。仍未做：帶載電壓、繞組間絕緣（應 OL）、溫升、熱保護。
- 寫入 docs/00 §1／§2.1 保險絲列／§3／§4、docs/05 主電源接法、README 狀態列。電路、板檔、估算腳本未動。
- 同日稍後使用者補答：量測時市電 110 V；標籤確為 4.2 A；22V 兩組線色為綠／綠與藍／藍（手寫稿的 G／B 是串接兩端）。據此把最壞情境軌電壓由 ±35.8 修正為 ±33.5 V（空載值已實測，不再疊 +8% 調整率），帶載推估連續雙聲道正弦約 30–32 W／8Ω、音樂瞬間 40 W 可達。選料結論不變。
- 核對後補修：docs/00 §3 去掉「市電對照未量」、§2.2 控制板零件列改為可開始篩選（兩軌儲能 25.6→22.4 J）；docs/14 湧浪情境表帶入實測繞組電阻（次級迴路約 0.3 Ω，對應第一列約 11×）、§8 待量表標注已量與未量項。
- 使用者問整流橋可否開買：以實測核 KBPC2510（反向峰值約 63 V／1000 V、平均直流約 2.5 A／25 A、湧浪約 100 A／300 A、每橋耗熱約 4–5 W）⇒ 可買；Faston 線定 AWG18（或 16）。docs/00 §2.1 兩列、§3、docs/05 同步。

## 2026-09-29（深夜）：目標喇叭 Usher Be-718 匹配估算寫進 docs/01

- 使用者告知目標喇叭為 Usher Be-718（先前未記錄在 repo）。查原廠規格與 Stereophile／Sound & Vision 實測：標稱 8Ω、低中音 >6Ω、最低 5.16Ω @2.8kHz、靈敏度實測約 85dB。
- 結論：阻抗與電流無虞；±30V 散熱可以、±36V 連續 6Ω 正弦會超溫（要實測）；音量偏緊（本機約 36W vs 原廠建議 80–200W，一對 2.5m 房間削波前約 98–99dB）。全為計算。

## 2026-09-29（晚）：PCB V0.5 候選——為塞進 BZ4312A2 縮板，DRC 0

- 起因：BZ4312A2 配置 A 下，V0.4 三板深度只剩 7 mm、前排寬只剩 30 mm。結論是三板架構不用重做（IC 必貼側牆、重物必在前排），只改兩塊板的形狀。
- 放大板 D 115×90 → 90×90：C2（EGW 47µF）躺式改站立（新封裝 `BP_Axial_Vert_D20_P15`，腳距 15 為假設）、R1／C1 直立、J1 內移、靜音零件搬到右下、L_MUTE 沿上緣與右邊繞行。IC 區、輸出區、回授網路座標不動。
- 電源板 160×120 → 125×130：AC 區搬上緣、輸出區搬下緣、電容兩欄各下面一顆轉 90°、洩放電阻進欄間空隙、snubber 預留位貼左右邊。更正：四顆電容本來就是 2×2，160 寬是兩側端子區造成的。
- 新增 `tools/pcb_layout_v05.py`／`pcb_layout_v05_psu.py`／`build_pcb_v05.py`／`verify_pcb_v05.py`／`render_pcb_v05.py`／`draw_chassis_fit_v05.py`；產出 `pcb/*-v05*`、`validation-v05.json`（含機殼餘裕：深 7→22、前排寬 10→45）、`docs/diagrams/chassis_bz4312a2_v05_fit.png`。
- DRC 三輪：H2 固定孔壓 C1 保留區、C205／C206 與大電容保留區重疊、R1 與 R2 保留區重疊、VEE 短樁頂到 VCC 匯流；第三輪兩板 0 違規 0 未連通。
- 使用者看預覽後選定，同晚 ff 併入 main 成為現行版本；V0.4 退為歷史。`pcb/inspection-v05/`（正反面、組裝、3D、零件核對）由 v04 腳本衍生重做，驗證通過。U1 未動，IC 方案 B 等三項實量。

## 2026-09-24（深夜）：PCB V0.4 放大板變體 C 畫好、DRC 0

- 新增 `tools/pcb_layout_v04.py`／`build_pcb_v04.py`／`verify_pcb_v04.py`／`render_pcb_v04.py`，產出 `pcb/mono-layout-v04c.*`、`mono-v04c-drc.json`、`validation-v04.json`、預覽圖。電路與封裝沿用 V0.3，只改位置與銅箔。
- 五點改法（旁路貼腳、470µF＋STAR 上移、J1 並排走線＋SG、Zobel 直入 STAR、C2 平放右半）落地；C3／C4 接地路徑 24／33→5／11 mm，Zobel 接地 72→12 mm，過孔 3→0。回授取樣線 7→50 mm、訊號地變長，是有意的代價，已寫在 pcb/README。
- DRC 三輪：第一輪 3 錯（靜音供電與 L_MUTE 交叉、VEE 主幹與 C2.2 間距 0.2、C2 與 C6 保留區重疊）＋絲印警告；第二輪 3 錯（C8 回地線壓到 JP1.2、R8 與 C8 保留區重疊）；第三輪 0 違規 0 未連通，分路檢查通過（匯合半徑 5 mm）。
- 變體 D、電源板 V0.4 PCB 未畫；V0.3 板檔與雜湊未動。

---

## 2026-09-24（深夜）：修正兩張導讀圖的 PyMuPDF 渲染錯誤

- `lm3886_input_stage.png`／`lm3886_ic_to_output.png` 前一筆 commit 的版本是壞的：PyMuPDF 不支援巢狀 `<svg viewBox>` 與 `clip-path`，子圖被畫在原點且蓋住標題。`build_diagrams.py` 的 `embed()` 改成明確的 translate/scale 群組並去掉子圖底色，兩張圖重建；其餘圖不受影響。

---

## 2026-09-24（深夜）：單聲道完整接線圖、電源板原理圖預覽同步、導讀圖重建

- 使用者指出原理圖看起來不完整：KiCad 圖以網路標籤代替畫線，且電源板預覽 PNG／PDF 是改 J204／snubber 之前匯出的。重新匯出 `electrical/preview/internal-psu-v02.pdf/.png`（ERC 0）。
- 新增 `tools/build_diagram_full_v04.py` → `docs/diagrams/lm3886_full_v04.png`：放大板 D 22 件＋電源板 22 件全部以實線畫出（電源、去耦、靜音、回授、Zobel、J5↔J203 線束、J204），元件編號＝板上絲印。
- `build_diagrams.py`：舊「完整電路總覽」停產並移到 `docs/diagrams/archive-v03/`；其餘五張重建，色塊圖彩色框依新 PDF 版面重新對位，文字改 V0.4／到貨現況；`render_diagrams.py` 以 PyMuPDF 取代 sharp。`sources.json` 重綁。

---

## 2026-09-24（深夜）：V0.4 的 3D／正反面／組裝圖與零件核對表

- 新增 `pcb/inspection-v04/`（放大板 D＋電源板）：正反面銅箔 SVG／PNG（D 的背面圖畫出鋪銅）、組裝極性圖、逐腳對照、KiCad 原生 SVG、六張 3D 算繪＋總覽、`parts-audit.md/json`（44 列，含 snubber 預留位與 J204）。
- 工具 `tools/*_inspection_v04.py` 由 V0.3 版衍生；SVG→PNG 改用 PyMuPDF 取代 node／sharp。`verify_pcb_inspection_v04.py`（KiCad Python）通過：preview 板只多模型節點、22＋22 模型外框、54＋50 焊盤網路對照。中間產物加入 .gitignore。

---

## 2026-09-24（深夜）：V0.4 併入 main，V0.3 退為歷史版本

- 新增 `pcb/preview/system-layout-v04.png`（兩片 D＋電源板 V0.4）。README／pcb/README／HANDOFF 改為「V0.4 現行、V0.3 歷史」，V0.3 檔案與雜湊原樣保留。`v04-layout` 以 fast-forward 併入 `main`。

---

## 2026-09-24（深夜）：放大板選定 D 為主、C 保留；D 輸出主幹改頂層

- 使用者看過三張預覽後決定以變體 D（整面接地）為主要方案，C 板檔保留。
- D 的輸出主幹與 Zobel 接線改頂層、C7→pin 1 的 V+ 改底層、拿掉 C3.1 的多餘 V+ 分支；底層鋪銅單一連通區、左半不再靠窄帶相連。DRC 0 違規、0 未連通，`verify_pcb_v04.py` 三板通過並重綁雜湊。

---

## 2026-09-24（深夜）：PCB V0.4 電源板畫好、DRC 0，三塊板齊

- 新增 `tools/pcb_layout_v04_psu.py`，`build_pcb_v04.py` 一次建三板。電源板加 J203／J204 每聲道 3P 端子（STAR 移到端子旁）、每繞組 snubber 預留位一列（只留孔）。
- DRC 第一輪 1 錯（負半邊 snubber 回線壓到 V- 充電線）＋絲印警告，改線位後 0 違規 0 未連通；`verify_pcb_v04.py` 三板通過並綁定雜湊；`render_pcb_v04.py` 出三張圖。
- 放大板 C／D 板檔未變（生成器重跑只動 UUID，已還原）。

---

## 2026-09-24（深夜）：PCB V0.4 放大板變體 D 畫好、DRC 0

- `pcb_layout_v04.py` 加 `AMP_D`（座標與 C 相同、拿掉 GND 分路、加底層 GND 鋪銅）；`build_pcb_v04.py` 加 zone 建立與 `ZONE_FILLER` 填銅、填銅多邊形寫進 JSON；`render_pcb_v04.py` 畫鋪銅；`verify_pcb_v04.py` 對有鋪銅的板改檢查連通區數。
- 變體 D DRC 0 違規、0 未連通，鋪銅單一連通區。變體 C 檔案未變（重跑生成器只動 UUID，已還原）。
- 電源板 V0.4 PCB 仍未畫。

---

## 2026-09-24（晚）：整流橋裝法定案為鎖機殼

- 產生 A（KBPC2510 鎖機殼、板上 4 位端子）與 B（KBPC-W 線腳版焊板）兩張電源板預覽，皆 DRC 0；使用者選 A。
- `BridgeTerminal4_P5.08` 取代 `Bridge_LOGICAL_UNVERIFIED`；四條橋堆進出線加轉折點；電源圖註記更新；採購總表 §1.1／§2.1 改寫，新增 Faston 母端子與線材項；HANDOFF 步驟 2 更新。
- 電源板重建、DRC 0、驗證通過；`analyze_pcb_v03.py` 重算。3D／導讀圖仍未重建。

---

## 2026-09-24：原理圖與 PCB 在本機重建

- 發現這台 Windows 其實裝有 KiCad 10.0.6（不在 PATH），先前「本機無 KiCad」判斷錯誤。在 `core.autocrlf=false` 的 clone 中重建，Python 文字寫檔強制 LF。
- 原理圖：兩份 ERC 0 違規；`verify_electrical.py` 期望值改為實購（C1／C3／C4／C8 100V、R8 0.6W），核對通過。本機無 pdftoppm，預覽 PNG 以 PyMuPDF 轉出（2400 px 長邊）。docs/02 重算結果無變化。
- PCB：首輪 DRC 3 項（C2／R1 保留區重疊、U1 絲印字高與壓字），驗證抓到 C2 訊號地與靜音回流相碰；修正見 pcb/README。最終兩板 DRC 0 違規、0 未連通，`verify_pcb_v03.py` 通過，`analyze_pcb_v03.py` 重算、單元測試通過，預覽圖重繪。
- 工具：`build_pcb_v03.py`／`run_pcb_drc_v03.py` 把 KiCad 在 Windows 寫出的 CRLF 轉 LF 後才雜湊；四支腳本的雜湊路徑改 `as_posix()`，避免 Windows 反斜線路徑。
- 自我複核後補修：系統預覽圖與電源圖上的「待到貨／C2 立式改臥式」過期字樣、pcb/README 的 R3.1–C2.2 距離改為實算 10 mm、機殼寬度需求標註待重算（原以 100×90 推導），並註明 C2 本體下方有走線與過孔。
- **未重建**：`pcb/inspection-v03/`（3D、parts-audit）與 `docs/diagrams/`。

---

## 2026-09-23：到貨件初量，C2 改躺式、放大板加寬

- 使用者實量（尺量／目測，非卡尺）：變壓器 Ø約120、本體含出線鼓起約 50 mm、中心開孔約 Ø40、出線 8 條各約 30 cm；CDE 381LX Ø約35×50、2 腳、腳距約 10，印字 10000µF／63WV／+105°C／8040，殼上無完整料號；ROE EKE 470µF Ø約12×25、腳距約 5、腳徑約 0.8；ROE EGW 47µF 軸向約 40×Ø20、腳徑約 0.8–1.0。寫入 docs/00 §1／§1.1。
- 使用者決定 EGW 躺著裝、放大板加寬。新增 `BP_Axial_L40_D20_P50`；`pcb_layout_v03.py` 放大板 115×90、C2 移至 (72,80) 轉 90°、R8／C8／JP1 右移、三段走線改道；`CP_D12.5_P5` 鑽孔 0.9→1.0；預覽圖尺寸文字與系統圖位置同步。
- **板檔、DRC、預覽圖、parts-audit 皆未重建**（當時誤以為本機無 KiCad；9/24 已重建板檔）。自寫座標幾何檢查無新增違規，不取代 DRC。兩片放大板加寬後，機殼內寬需求增加約 30 mm，機殼估算待重算。

---

## 2026-09-22（晚）：變壓器與 yosontw 40 件到貨

- 使用者回報：環形變壓器與 9/20 露天 yosontw 訂單（電阻、WIMA、CDE、ROE 共 40 件）已到家。**尚未開箱核對、未量測。** LM3886T 到貨與否未回報。
- 狀態同步：docs/00 §1、README、HANDOFF、10-planned-parts.json（`delivered_2026-09-22_unmeasured`）、parts-audit 採購狀態欄。無其他變更。

---

## 2026-09-22（下午）：V0.4 進入設計草案

- 新增 `docs/14-V0.4-控制與保護板設計草案.md`：一片控制板整合軟啟動旁通、喇叭 DC 保護、靜音接管、Z10 trigger、12Vac 輔助電源；系統方塊、啟停時序表、與 V0.3 三板的介面表、繼電器採購篩選清單、變壓器到貨量測清單、UPC1237 模組驗證清單。
- 新增 `tools/control_budget.py`（純標準庫）：儲能／湧流情境、R_s 選值與失效功率、K_SPK DC 分斷需求（≥36V／≥9A）、掉電時序（軌壓 1s 內 >20V vs 釋放 <60ms）、12Vac 預算（140mA、2.7VA、7812 餘裕 0.4V）、靜音電流核對、trigger 直驅門檻（線圈 ≥240Ω）。
- 決定：K_TRIG 線圈由 Z10 12V 直接供電，不做待機電源；掉電取樣點在 12Vac 整流前；靜音由控制板每聲道獨立元件接管。
- 沒有原理圖、PCB、BOM；放大板與電源板電路不變。README／HANDOFF／13／00／tools README 加連結。

---

## 2026-09-22：圖片與採購資料同步到 9/20 下單後狀態

- **導讀圖六張重建**（`tools/build_diagrams.py`）：C1／C3／C4／C8 耐壓改為實購 100V、R8 改 0.6W；「僅變壓器與 IC 已訂」「四顆主電容未購」等過期文字改為現況；修正放大板色塊圖橙框遮住 R4 標籤、電源圖 GND 註記壓線；IC→輸出圖頁尾指向已不存在的 `pcb/review-v03.md` 改為 `pcb/README.md`。`sources.json` 改為只綁生成器與 PDF（sch 每次重建 UUID 都變，雜湊不可重現）。
- **PCB 預覽圖重繪**（`render_pcb_v03.py`）：標題「B 方案」改為「方案 C PCB V0.3（布局 B）」，副標「已訂 IC 與變壓器均在寄送中」改為現況。走線 JSON、板檔、DRC 未動。
- **原理圖生成器改值但未重建**：`build_schematic.py` C1／C3／C4 → 100V、C8 → 100V、R8 → 0.6W、title block 移除「no PCB」；`build_power_supply.py` 的「NOT purchased」註記改為 381LX 已購。**`.kicad_sch`／PDF／PNG／BOM／validation.md 仍為 9/16 產物**，等封裝改完在有 KiCad 的機器一起 `rebuild.py`。
- **採購總表**：補 CDE 361R／381LX 型錄尺寸（361R EG 殼 Ø12.5×20／P5 → C8 封裝必改；381LX A05 殼 Ø35×50，但 **A052 料號不在現行型錄**，63V／10,000µF 只有 Ø30 K 殼）；補四項漏列（橋堆固定件、環形變壓器固定件、熱縮套管、假負載散熱片）；加 2.1／2.2 小計；0.7µH 電感改建議自繞、露天品降為備選；購買順序第 2 步改為先用型錄值估機殼。
- **機器可讀資料**：`10-planned-parts.json` 全部項目由 `planned_not_ordered` 改為已下單待到貨，Mundorf／NCC 標為未選；`11-ruten-shopping-links.json` 修正 KF301 2P 數量說明、新增四項「候選待找」。
- **PCB 核對資料**：`build_pcb_inspection_v03.py` 依實購料件逐項寫入採購狀態，重跑產生 `parts-audit.json/md`；`*-footprints.csv` 與 `build_pcb_v03.py` 的狀態字串同步；`inspection-v03/verification.json` 的檔案雜湊手動重算並註明。
- **型錄比對（採購總表新增 1.1）**：查 TI、EIC、WIMA、Vishay、CDE 原廠文件逐項對現板封裝。新發現：LM3886T 鑽孔 0.9 mm 小於腳寬 0.97 mm 必改；KBPC2510 是 Faston 端子，`Bridge_LOGICAL` 的 1.5 mm 孔兩種裝法都不合，要先決定鎖機殼或改 KBPC-W；WIMA／Vishay 六款全部相容。只改 00 總表、HANDOFF、本檔，沒動封裝庫與 PCB。
- **依型錄改封裝庫與生成器（板檔未重建）**：`build_pcb_v03.py`＋`DraftV03.pretty` 的 `LM3886T_UNVERIFIED` 鑽孔 0.9→1.1／焊盤 2.0，`CP_D35_P10` 鑽孔 1.3→2.5／焊盤 4.0；`pcb_layout_v03.py` C8 改 `CP_D12.5_P5`；`build_pcb_inspection_v03.py` 3D 高度 Film_P15 15、Film_P5 6.5、LM3886T 22。C2 臥式待 ROE 實測。
- 沒有改電路、走線、元件值（僅耐壓／功率額定向上對齊實購件）；沒有硬體量測。

---

## 2026-09-21：大幅精簡文件與檔案

- **刪除 `pcb/archive/`、`tools/archive/`、`docs/archive/`**（含 2026-09-20 剛歸檔的六份採購附錄與 2026-09-11 舊完整 PDF）。**檔案沒有消失，最後包含它們的 commit 是 `41b217c`，用 `git show 41b217c:<路徑>` 或 `git checkout 41b217c -- <路徑>` 取回。**
- **例外保留** `pcb/archive/v02/mono-layout-v02.json`、`pcb/archive/v02/psu-layout-v02.json`：`tools/analyze_pcb_v03.py` 的 `layout_path()` 讀這兩個檔做 V0.2→V0.3 載流對照，刪掉會讓比較表壞掉。
- 合併文件：07 Z10 介面 → 01 設計規格；06 市電與電源估算 → 05 內建電源與機構；`pcb/README-v03.md`＋`pcb/review-v03.md` → `pcb/README.md`。13 喇叭保護計畫縮到 60 行內。
- 精簡 `pcb/inspection-v03/`：刪掉六張 `raw-*.png`、兩組 `*-preview.kicad_pcb/.kicad_pro` 與 `3d/models/`（全部可由 `build_pcb_inspection_v03.py`／`export_pcb_inspection_v03.py` 重建），已加入 `.gitignore`。
- `docs/00-採購總表.md` 重寫為 150 行內：已買表、未買表、購買順序、相容性結論。

---

## 2026-09-20：第二批零件下單

- 使用者提供露天訂單截圖（yosontw，訂單 26092068825254，2026-09-20 結帳）：13 種 40 件 $2,238＋運 $60。內容＝採購總表第 4 節 9 項＋第 6 節 2 項＋第 5 節兩組的 ROE 選項（EGW 47µF ×2、EKE 470µF ×4）。
- **設計決策落地：** C2／C102 用 ROE EGW 47µF 臥式無極性；C6／C7／C106／C107 用 ROE EKE 470µF／63V。這兩項與 CDE 381LX、361R 的實體尺寸下單前都沒有，**到貨後量尺寸 → 改 `DraftV03.pretty` 封裝（C2 立式改臥式為必改）→ 重建 PCB**。
- 已更新 `docs/00-採購總表.md`（開頭新增下單紀錄表與到貨待辦、進度表狀態）、`docs/archive/08-採購狀態.md`、`README.md`。其餘文件（10、11）保留原候選紀錄未改。
- 未購項不變：整流橋、保險絲座／保險絲、電感、KF301 接頭、排針、RCA／喇叭端子、雲母片、絕緣套、導熱膏、散熱器、AC 入口、軟啟動、保護板、線材、假負載、機殼。
- 沒有改原理圖、PCB、BOM、3D；沒有重跑 ERC／DRC。

### 首頁同步紀錄（原 README「預計下單清單（2026-09-18）」段落，2026-09-20 更新）

已登記 Vishay／RNU2 電阻、CDE／WIMA 電容，以及 ROE／Mundorf／NCC 替代候選。**2026-09-20 已下單（露天 yosontw，40 件 $2,298 含運）；47µF 選 ROE EGW、470µF 選 ROE EKE。** 查看數量、價格試算與封裝影響（`docs/archive/10-預計下單清單.md`，已刪除）。現有PCB與3D尚未按這批料件定版。

---

## 2026-09-19：封裝絲印組裝標記

- 新增 `tools/silk_marks_v03.py`（純 Python，無 pcbnew 依賴），`build_pcb_v03.py` 的 `make_fp` 於存檔前呼叫它，為 `CP_*` 電解加「+」與負極條、為 `LM3886T_UNVERIFIED` 加 pad 1 標記與散熱片側標線／字樣。
- 同步以相同幾何手動寫入 `pcb/DraftV03.pretty/` 四個 `.kicad_mod`（每個新增 3 個 F.SilkS 項目，括號平衡已檢查）。**未改 `.kicad_pcb`、`.kicad_pro`、預覽圖與任何 DRC／驗證 JSON**，雜湊綁定不受影響。
- 極性核對來源：`pcb_layout_v03.py` 走線 —— C7 (VCC,GND)、C6 (GND,VEE)、C8 (GND,L_MUTE)、C201/C202 (VCC,GND)、C203/C204 (GND,VEE)，pad 1 一律為正。
- 驗證：`py_compile` 通過；`test_pcb_analysis_v03.py` OK。`verify_pcb_v03.py` 因缺 `electrical/netlist.xml`（需 kicad-cli 匯出）在改動前後同樣失敗，非本輪引入。本機無 KiCad，`PCB_TEXT` 於 footprint 內的 API 用法未實跑，重建時若報錯請優先檢查該兩行。
- **待辦（封裝定案後）：** J1／J2 極性標示、JP1（RUN）說明文字、全板零件值顯示。

---

## 2026-09-18：歸檔舊版板檔與腳本

- 依前輪議定執行，範圍只搬位置不刪檔，全部 `git mv` 保留歷史。`electrical/` 的 v01／v02 原理圖是現行檔案，未動。
- `pcb/archive/v01/`：`mono-placement-v01.*`、`psu-placement-v01.*`、`README-v01.md`、`Draft.pretty/`、`footprint-assumptions.csv`、`mono-drc.json`、`psu-drc.json`，以及 `preview/` 內三張 v01 PNG 與原本散在 pcb/ 頂層的 `mono-native.svg`、`psu-native.svg`（2026-09-16 產生，屬 V0.1）。
- `pcb/archive/v02/`：`mono-layout-v02.*`、`psu-layout-v02.*`、兩份 `*-footprints.csv`、`mono-v02-drc.json`、`psu-v02-drc.json`、`validation-v02.json`、`README-v02.md`、`DraftV02.pretty/`，以及 `preview/` 內五張 v02 PNG／SVG。
- `tools/archive/`：`build_pcb_draft.py`、`render_pcb_draft.py`、`build_pcb_v02.py`、`render_pcb_v02.py`、`verify_pcb_v02.py`、`pcb_layout_v02.py`。六支腳本的 repo 根目錄改為 `parents[2]`、輸出改指 `pcb/archive/v0X/`，並加註歷史腳本標頭；未在 KiCad 環境重跑。
- `docs/archive/`：2026-09-11 舊完整 PDF。README、HANDOFF 連結同步更新。
- **修正一個計畫沒列到的陷阱：** 現行 `tools/analyze_pcb_v03.py` 會讀 V0.2 板檔 JSON 做 V0.2→V0.3 對照，原本寫死 `pcb/`。已改為 `layout_path()` 依版本指向 `pcb/archive/v02/`；`current-budget-v03.json` 只改兩個來源雜湊的路徑鍵，數值未變（Python 3.14 重跑數值只有末位浮點差，未採用）。回歸測試 4 個通過。
- `pcb/fp-lib-table` 只保留 DraftV03；v01／v02 各自附一份 fp-lib-table 指向自己的封裝庫。三代板檔的 footprint 均無庫前綴，載入不受影響。
- 新增 `tools/README.md`：入口為 `rebuild.py`（只跑原理圖四支），其餘依用途分組。
- 驗證：全庫 Markdown 相對連結 0 斷裂；舊路徑字串 0 殘留；全部 .py 通過 py_compile。本機無 kicad-cli，`tools/rebuild.py` 未執行；`rebuild.py` 不引用任何被搬檔案。
- 沒有改原理圖、PCB V0.3、BOM、3D、PDF 內容；沒有重跑 ERC／DRC。

**順帶建議（未做）：** 03／08／09／10／11／12 六份文件的採購資訊仍散落，建議下輪做單一入口總表；README／HANDOFF 的逐日流水帳可移至 CHANGELOG.md。
（註：這兩項建議已分別於 2026-09-19 的 `docs/00-採購總表.md` 與 2026-09-20 的本檔落實。）

---

## 2026-09-18：docs 檔名中文化與機殼候選

- `docs/` 全部 12 份 .md 改為中文檔名（01-設計規格 … 12-機殼候選），編號前綴保留。`.json` 資料檔維持英文名，因為是腳本 I/O。
- 同步更新 README、HANDOFF、`docs/diagrams/README.md`、`electrical/README.md`、`pcb/README-v03.md`（已併入 `pcb/README.md`），以及 `build_project_pdf.py`、`rebuild.py`、`power_budget.py`、`mains_budget.py` 四支腳本內的檔名字串。全庫連結檢查 0 斷裂、0 處舊檔名殘留。
- 新增 `docs/archive/12-機殼候選.md`（已刪除）：由環牛 Ø120×43、電源板 160×120、放大板 100×90 與主電容尺寸推導最低內部空間（寬 ≥300／深 ≥250／高 ≥90 mm），列淘寶候選與商品連結。首選 4312A 兩側散熱 430×120×311（¥408）。
- **機殼未下單，散熱熱阻全部未標 °C/W，內部淨空間未向賣家確認，型號推測尺寸未經賣家背書。主電容料號未定前機殼高度不應定案。**
- 本輪沒有改動原理圖、PCB、BOM、3D 或 PDF，沒有重跑 ERC／DRC。

---

## 2026-09-18：露天商品連結

- `docs/archive/11-露天購物連結.md`（已刪除）整合38個已開啟核對的商品直達頁：原15項＋新增23項；docs/10的原表與JSON也補上連結／包裝選項。
- 47µF與470µF替代群組仍未決定，40個原需求位置不變；無代購、加購物車、已購或到貨狀態變更。
- 明列NCC店未含運$100出貨門檻、單件／10件／100件包裝，以及部分賣家二手以全新欄上架的公告。賣場規格只作候選，沒有原廠或真偽背書。
- 散熱器、介面、保險絲、軟啟動、喇叭保護板與假負載仍有關鍵缺項；市電電源線、PE接地組件等未核實項目在缺項表保留。
- 本輪僅文件／採購JSON更新；原理圖、PCB、3D、既有PDF及凍結inspection-v03未變。驗證38個唯一商品URL、15項／40位置與替代群組數量、相對文件連結及git diff；無重跑ERC／DRC。

---

## 2026-09-18：預計下單零件

- 使用者提供13列文字清單及2列截圖替代品；明確確認兩組皆列候選，尚未決定。沒有新增已購／到貨紀錄。
- docs/archive/10-預計下單清單.md／json保存15個候選條目、40個不重複元件位置、原文價格／出貨描述及完整料號。兩個替代群組不重複計量。
- 優先封裝影響：C2／C102改用臥式候選，NCC 470µF賣場Ø16與舊Ø12.5占位不同；CDE100µF與牛角主電容需原廠尺寸、接腳與孔徑核對。
- 本次僅更新採購與選料文件，未改原理圖、PCB、BOM電氣值或3D；inspection-v03仍為前次驗證快照，最新選料以docs/10為準。未重跑ERC／DRC或新增實測。

### 首頁同步紀錄（原 README「預計下單清單（2026-09-18）」段落）

露天商品直達連結與其餘待買候選（`docs/archive/11-露天購物連結.md`，已刪除）：已核對原15項候選及23項新增商品，附數量、包裝選項與尚待確認的規格。

---

## 2026-09-18：PCB A＋B＋C 看圖與核對

- 使用者選擇本輪 A（正反面與組裝）、B（3D）、C（零件／封裝表），並要求完成後推送 GitHub；這些字母不是更換電路方案。
- 基準為遠端 a71b2c4。新增 pcb/inspection-v03/：6 張導讀圖（PNG＋SVG）、4 份 KiCad 原生分層 SVG、2 份逐腳／極性表；底面銅箔以左右鏡像從板底觀看。
- 新增 15 種自建 VRML 暫定外框，覆蓋 22＋15 元件位置；衍生 preview 板僅添加模型引用。6 張原生 3D 角度圖及加框版本、總覽；可由 KiCad 3D viewer 旋轉檢視。
- 全部高度為顯示假設，不是原廠 CAD 或保證最大尺寸。IC 彎腳／背板、端子插線／工具空間、散熱器、機殼、焊錫與公差未建模；沒有 STEP 或製造檔。
- 37 項 parts-audit.json／md 列平面尺寸、假設高度、腳距、孔徑、採購狀態及核對欄位；料號、實物核對全部仍未完成。沒有新增到料資訊。
- 來源與驗證見該資料夾 README、sources.json、verification.json；以語法樹核對 preview 僅多 model 節點，原生讀取核對 89 個焊盤位置與網路，3D 模型尺寸與表格一致，圖面逐張檢視。沒有改原板／電路，也沒有重跑 ERC／DRC 或新增實測。
- tools/*pcb_inspection_v03* 與 write_pcb_parts_audit_v03.py 提供重建。preview 不是電路來源；後續先確定實際料號／尺寸再修改 pcb_layout_v03 及原板。

### 首頁同步紀錄（原 README「PCB 看圖與選料資料（2026-09-18）」段落）

已完成正反面銅箔圖、極性／組裝圖、兩板三種角度的 3D 預覽、可旋轉的 KiCad 預覽板，以及 37 項零件／封裝核對表。**元件模型採暫定外框與假設高度，尚非可製造裝配模型。** 原理圖與 PCB V0.3 走線保持不變。

[正反面、組裝與 3D 圖索引](pcb/inspection-v03/README.md) · [零件與封裝核對表](pcb/inspection-v03/parts-audit.md)

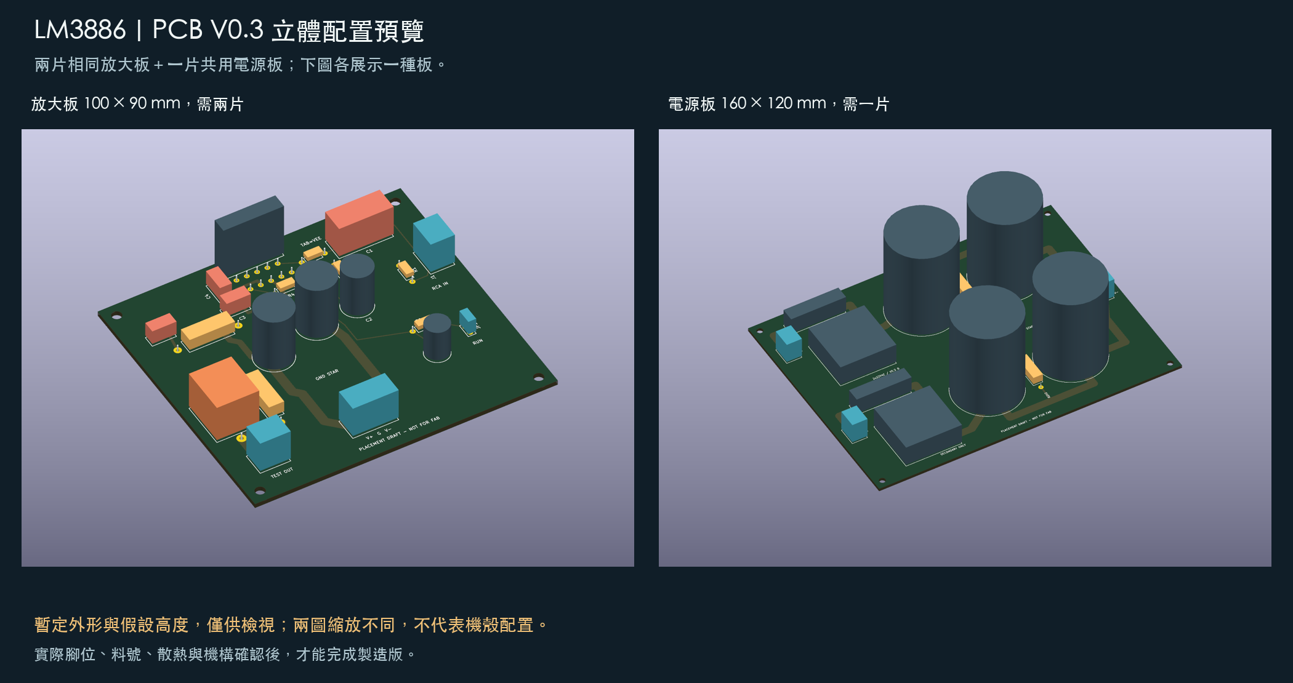
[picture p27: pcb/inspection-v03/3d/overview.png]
PCB 3D 工程預覽


---

## 2026-09-17：六張電路導讀圖

- `docs/diagrams/` 六張 PNG 以同名更新，加入 SVG 原稿、來源雜湊、索引及 build/render_diagrams 工具。
- 更正舊總覽中的單橋中心抽頭電源、回授 R3/C2 並聯畫法與元件編號；同步雙獨立 22Vac／雙橋、每軌 20,000µF、靜音與負軌電解極性、待設計保護及未購料件。
- 兩張色塊圖直接取現行 KiCad PDF 向量內容；補充 PCB V0.3 去耦回流說明，未修改任何原理圖／PCB／元件值。
- 六張 PNG 已逐張檢視；對照原理圖生成器、BOM 與既有 netlist 規格核對。沒有重跑 ERC／DRC，沒有新增實測；原來 PDF 保持既有快照。
- 詳見 [導讀圖說明](docs/diagrams/README.md)。日後改電路需先重建原理圖，再同步導讀程式及圖片。

### 首頁同步紀錄（原 README「電路圖」段落）

**2026-09-17：六張中文導讀圖已同步方案 C V0.3。** 更新雙 22Vac／雙橋四電容、回授串聯關係、元件編號與靜音極性，補上 PCB V0.3 回流說明。[導讀圖索引與重建方式](docs/diagrams/README.md)。

---

## 2026-09-17：PCB V0.3 去耦與載流

- 使用者要求直接進行下一輪去耦／回授審查與載流估算。沿用 ±30V、8Ω 設計假設，沒有新增採購或到料確認。
- 保留 V0.2 板檔，新增 mono／psu-layout-v03。C3/C4 地端改在 IC 附近回 U1.7；主輸出改 B.Cu，回授獨立取樣保留；放大板主要電流段加寬、移除兩個正軌供電導通孔，電源板 AC／DC 主幹改 4 mm。
- 去耦回地中心線長度 C3：102.94→24.15 mm，C4：126.16→33.15 mm；這是幾何指標，非電感或穩定性模擬。
- 新增 tools/analyze_pcb_v03.py 與 pcb/current-budget-v03.json／md；40W／8Ω、1 oz／25°C 情境下 U1.3→L1.1 銅箔電阻 20.93→9.25 mΩ。充電電流為 15–35% 占空比敏感度模型，非量測或保證上界。未計算實際溫升，未宣稱 IPC-2152 符合。
- 修正 SaveBoard 重建同名專案而還原規則的問題；V0.2 已發布實際 Default 間距為 0.2 mm，舊文字已更正。V0.3 固定 0.3 mm、DRC 前後核對設定，並綁定 PCB／專案／JSON／報告雜湊。
- KiCad 10.0.6：兩板 0 違規、0 未連通；54＋35 焊盤網路相符；分路接地幾何核對、4 個回歸測試通過，PNG 與原生 SVG 已檢視。原理圖、元件值與既有 PDF 未修改，未重跑 ERC。
- 完整來源與限制見 `pcb/README.md`（原 README-v03／review-v03，2026-09-21 合併）。下一步仍需到貨／料號核對、負軌與大電容去耦縮短、實際銅厚／孔壁／接頭載流及整機線束、保護與實測。

### 首頁同步紀錄（原 README「PCB B 方案修訂（V0.3／2026-09-17）」段落）

已訂 **LM3886T 與變壓器仍在寄送中**。本輪改善 C3/C4 的局部回地、分開輸出與回授取樣、加寬主電流路徑，並依 40W／8Ω 情境完成銅箔電阻、壓降與發熱功率估算。計算情境不是本機額定或量測。

仍採兩片 **100 × 90 mm 單聲道板**＋一片 **160 × 120 mm 共用電源板**。KiCad 10.0.6、固定 0.3 mm 間距規則下，兩板均 **0 DRC 違規、0 未連通**，54＋35 焊盤網路對照通過。封裝、實際溫升、散熱與機構仍待確認，**不可直接製造**。

PCB V0.3

[PCB V0.3 說明與審查](pcb/README.md)／[計算表](pcb/current-budget-v03.md)。V0.1／V0.2 板檔保留並已歸檔至 `pcb/archive/`；V0.2 規則文字有更正，本輪已修復重建還原設定的問題。原理圖和既有 V0.3 PDF 未修改，PDF 未收錄本版 PCB。

---

## 2026-09-17：PCB B 方案 V0.2

- 使用者選 B：保留三板架構重新布局；確認 LM3886T 與變壓器均仍在寄送中、尚未到貨。其他料件沒有新增已購或已到貨紀錄。
- 新檔 `pcb/mono-layout-v02.kicad_pcb`（100×90 mm）、`pcb/psu-layout-v02.kicad_pcb`（160×120 mm），保留 V0.1 全部原檔。位置及逐段走線來源為 `tools/pcb_layout_v02.py`，生成／繪圖／驗證工具皆有 v02 檔名。（**路徑為當時狀態**；2026-09-18 已歸檔至 `pcb/archive/v02/` 與 `tools/archive/`。）
- 輸入與回授靠近 IC；回授單獨由輸出腳取樣。放大板地線分路回到 (43,50) mm 匯流區；電源板由第一對電容接收充電、第二對電容引出 DC，接地匯流中心 (110,59.08) mm。
- KiCad 10.0.6 原生載入、54＋35 焊盤網路對照通過；舊版實際 Default 間距 0.2 mm 下兩板 DRC 均 0 違規、0 未連通；原 0.3 mm 文字已更正。放大板地線分組另經幾何取樣檢查。完整結果見 `pcb/archive/v02/README-v02.md`、兩份 v02 DRC JSON 及 `validation-v02.json`。
- 本版沒有變更原理圖、元件值、供電假設或既有 PDF；沒有重跑 ERC。真實封裝、銅厚／溫升、去耦迴路、散熱、機構與線束仍待到貨／選型核對；沒有 Gerber 或硬體測試。
- 下一步：先記錄到貨尺寸及變壓器規格，再確定整流橋／電容／接頭料號，修訂封裝及散熱器配合。不要把本次 DRC 通過視為可製造或可上電的證明。

---

## 2026-09-16：變壓器與 IC 下單

- 已確認兩個商品均下單待到貨，更新採購紀錄與 現行計畫（`docs/archive/09-採購後修訂計畫.md`，已刪除）。
- 以雙 22Vac＋單 12Vac 取代原 300VA／25Vac 採購候選；賣場 200W 不直接等同已驗證 VA。
- 每聲道 30～40W 為探索範圍，40W／50W 不再是驗收要求；輔助電源優先評估 12Vac。
- IC 訂單數量待確認，設計需 2 顆；拆機來源及 /NOPB 待核對。
- 已更新電路生成器、22Vac 計算、現行文件與新版 PDF；網路維持雙橋四電容。ERC 與獨立核對結果見 electrical/validation.md；無硬體量測。

### 首頁同步紀錄（原 README「目前進度：2026-09-16 已下單，待到貨核對」段落）

兩份 KiCad 圖、PDF／PNG、BOM 與估算已更新為 V0.3 C 方案。保留雙橋四電容接法，改為 22Vac 供電標示；變壓器 VA／電流與控制電路仍待確認。

已有放大板與電源次級兩份可編輯 KiCad 原理圖、PDF／PNG 預覽、43＋15 個元件的分板 BOM、腳位／線束核對、功率／散熱／紋波估算及上電流程。兩份圖的 KiCad ERC 均通過，0 錯誤、0 警告。

**一次側接線、軟啟動及喇叭保護控制尚待設計；已有暫定 PCB 配置與部分走線，尚無可製造 PCB、加工圖或實機量測。** 次級整流圖不是完整市電施工圖，功率與散熱仍需驗證；目前輸出端供假負載測試。

### V0.3 重建檢查紀錄（原 HANDOFF「V0.3 重建」段落）

新版設計與採購 PDF 在 output/pdf/，由 tools/build_project_pdf.py 生成（reportlab、pypdf、中文字型）；先跑 tools/rebuild.py。舊 PDF 保留為歷史；docs/diagrams 六張圖已於 2026-09-17 更新為現行 V0.3，舊圖可從 Git 歷史取回。

本次完成檢查：KiCad 10.0.6，兩份 ERC 均 0 violations；放大板 43 元件／29 網路／105 腳位，主電源 15 元件／9 網路／35 腳位，獨立網路、電解極性與線束檢查通過。新版彙整 PDF 17 頁（含兩張 A3 向量圖），採購 PDF 3 頁，已逐頁渲染檢查。

### 最新 PDF 索引（原 README「最新 PDF（V0.3／2026-09-16）」段落）

- C 方案設計與電路彙整：現行設計、整機方塊圖、估算、採購與兩張向量電路圖。由 tools/build_project_pdf.py 產生，不入版控。
- C 方案採購勾選清單：舊版（僅變壓器及 IC 已訂）。最新狀態看 [採購總表](docs/00-採購總表.md) 開頭的 2026-09-20 下單紀錄。
- 2026-09-11 舊完整 PDF（`docs/archive/LM3886_DIY_Project_Complete_2026-09-11.pdf`，2026-09-21 已刪除）：歷史快照，舊供電與採購資訊不再適用。

---

## 2026-09-16：PCB 配置草稿 V0.1

使用者批准 PCB A：兩片相同單聲道板＋共用電源板。已新增 pcb/ 與兩個 build/render_pcb_draft.py 工具（**2026-09-18 已歸檔至 `tools/archive/`**）；原理圖未變更。尺寸 90×80 mm 與 150×110 mm。焊盤網路對照通過；預設 DRC 幾何違規均為 0，放大板 14 個未連通、電源板 0 個。兩板真實封裝、接地回流與載流仍未完成；沒有 Gerber。三張 PNG 已檢視，完整限制與重建方式見 [PCB 說明](pcb/README.md)。V0.3 PDF 未納入本次 PCB 草稿。

---

## 2026-09-11：完整 PDF 彙整

- 新增 完整專案 PDF（`docs/archive/LM3886_DIY_Project_Complete_2026-09-11.pdf`，已刪除），共 52 頁，保留 33 個原始檔附件；附件 SHA-256 已逐一核對。
- 收錄基準提交：0cf78b502b1b72f2ab899b614ecd2449e5231f53。PDF 中的文件、電路與既有驗證紀錄均對應此快照；本次未重跑 ERC 或新增硬體驗證。
- 兩張電路圖保留原始向量頁面；全文、BOM、程式附錄、PDF 書籤與目錄跳頁已檢查。
- 此為固定版本彙整檔，未加入 tools/rebuild.py 自動生成流程；後續設計異動後需重新整理 PDF。

採購更正：使用者確認僅變壓器與 LM3886T 已下單；舊整流橋及電容已購紀錄錯誤。整流橋 2 顆、10,000µF／63V 主電容 4 顆均待購，品牌／料號尚未選定。六張電路導讀圖已於 2026-09-17 同步現行方案。

---

## 2026-09-11：歷史已完成（供電及功率前提已由後續計畫取代）

- 兩聲道原理圖：輸入隔直、回授、去耦、輸出穩定網路及各聲道測試用手動靜音。
- 成機改為內建線性電源；300VA、兩組獨立 25Vac 次級、雙橋、每軌 20,000µF 為候選。
- 新增電源次級 KiCad 圖及 15 元件 BOM，核對橋輸出串接、電解極性、洩放及 J203→放大板 J5 線束。
- 按 110V／60Hz 規劃；標稱市電負載下約 ±33V，高市電空載接近 ±40.8V，因此熱預算上界改為 ±41V，介面／散熱器候選改為 ≤0.3／≤0.4°C/W。
- 保留 2×40W／8Ω 目標，低市電不保證；50W／聲道是延伸驗證，未定為額定。
- 原廠 pinout、靜音及散熱條件核對；可重算的功率／熱預算。
- 兩份 KiCad ERC 與獨立 netlist 核對通過；放大板 43 元件、電源次級 15 元件，均有 PDF／PNG。
- 中文規格、內建電源機構分區、市電／紋波／放電計算、Z10 RCA 電平搭配及整合驗收流程。
- 舊 IC 數量與 /NOPB 紀錄未確認；以目前 LM3886T 商品訂單為準，設計 U1、U2 各 1 顆；到料核對項目與其餘料件採購狀態見 08-採購狀態.md（`docs/archive/08-採購狀態.md`，已刪除）。設計仍為非橋接、非並聯。

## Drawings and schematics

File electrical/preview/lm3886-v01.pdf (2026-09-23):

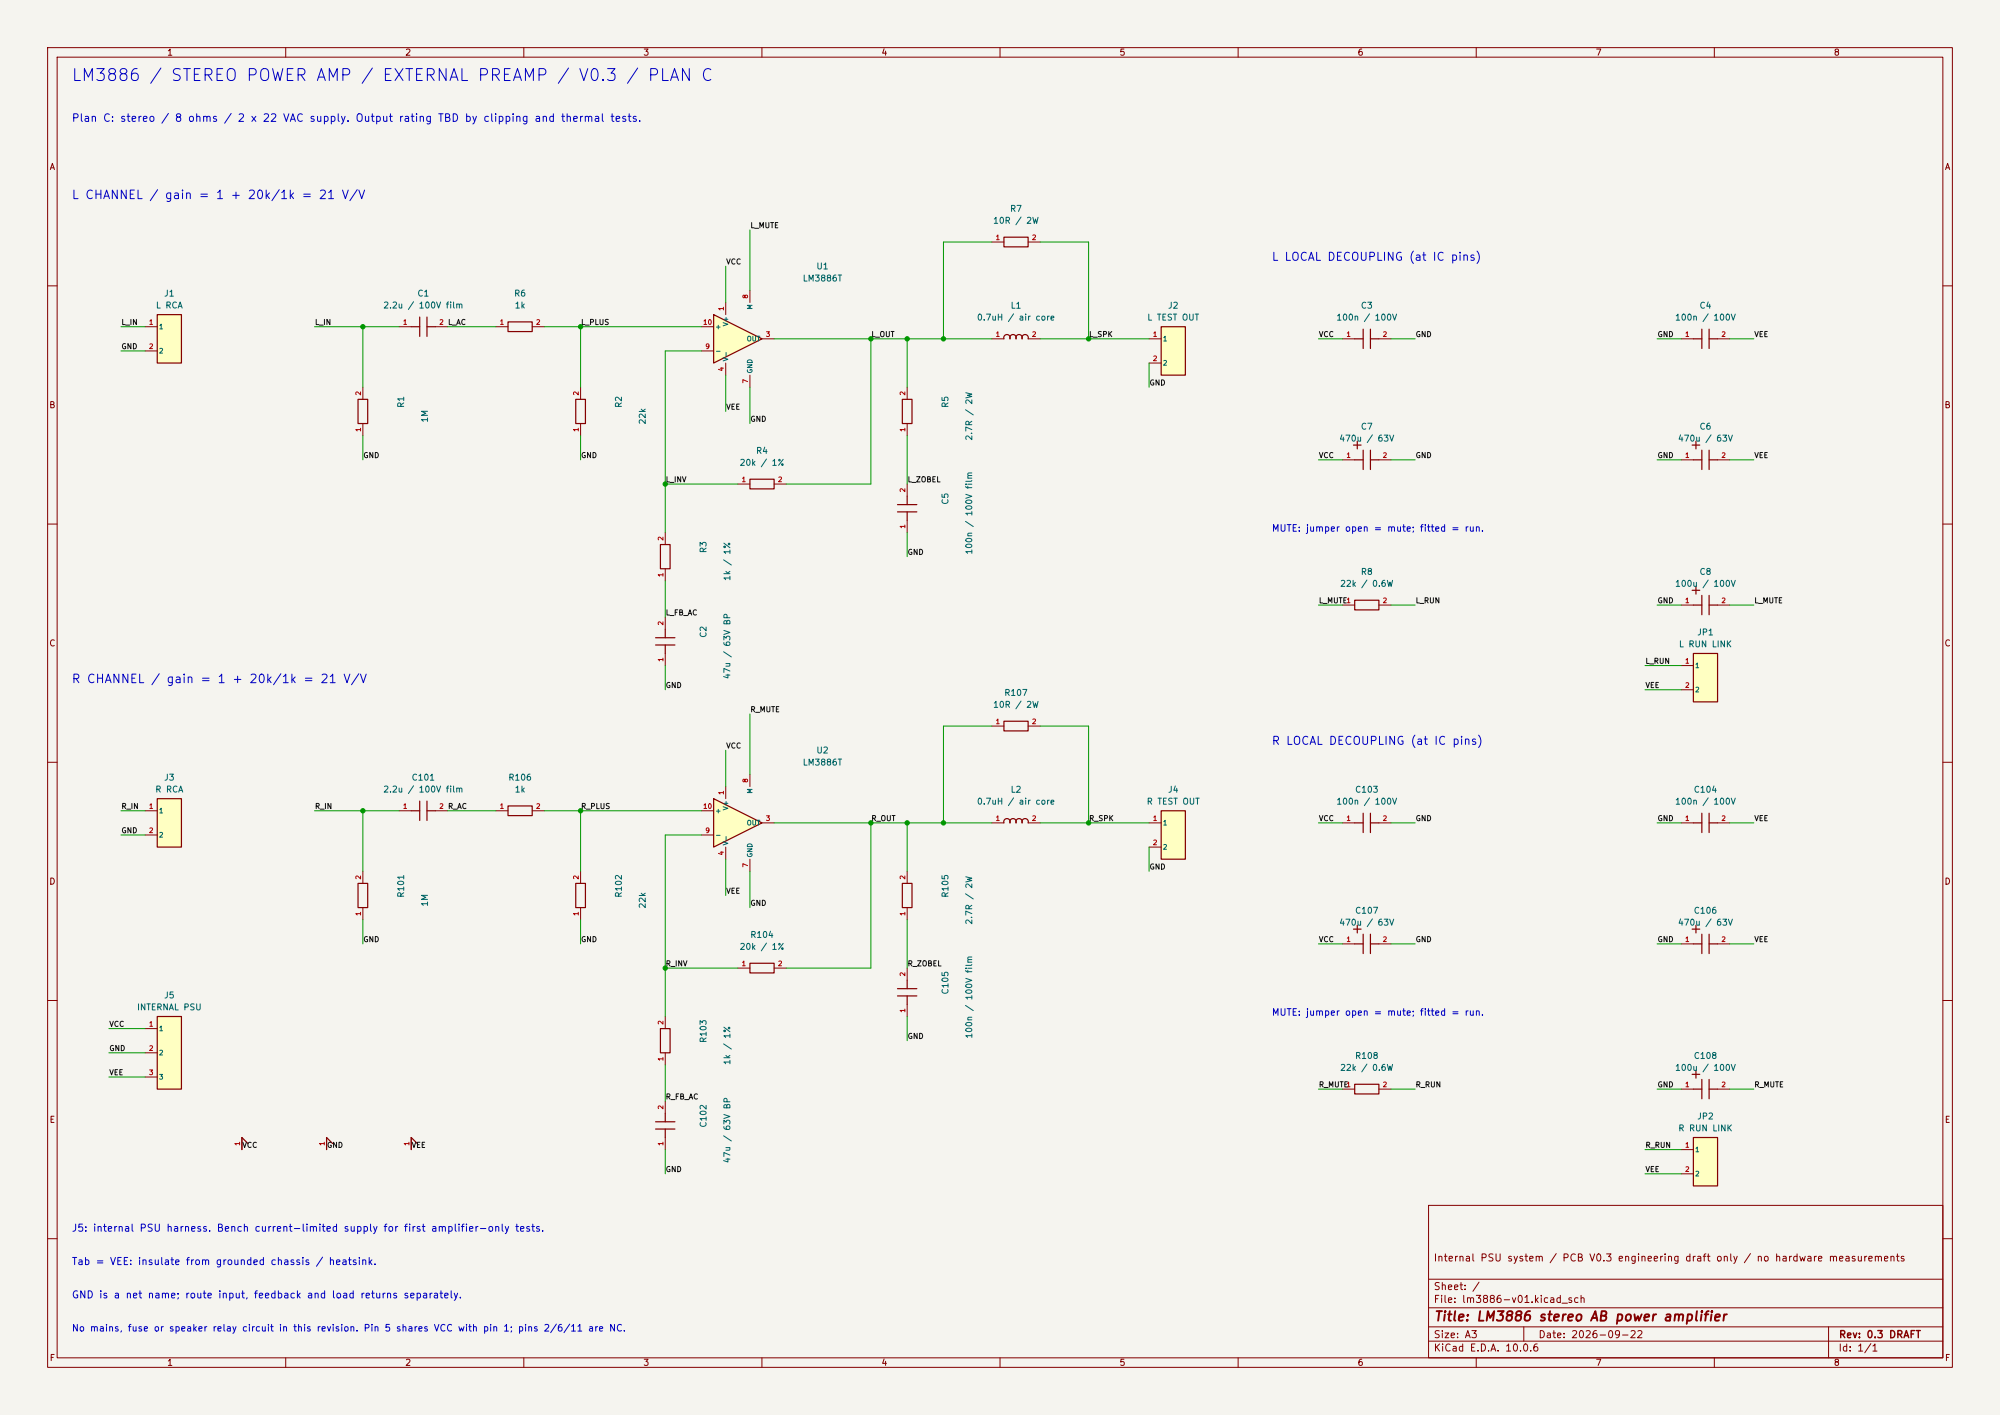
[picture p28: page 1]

LM3886 / STEREO POWER AMP / EXTERNAL PREAMP / V0.3 / PLAN C

Plan C: stereo / 8 ohms / 2 x 22 VAC supply. Output rating TBD by clipping and thermal tests.

L LOCAL DECOUPLING (at IC pins)

MUTE: jumper open = mute; fitted = run.

R LOCAL DECOUPLING (at IC pins)

J5: internal PSU harness. Bench current-limited supply for first amplifier-only tests.

Internal PSU system / PCB V0.3 engineering draft only / no hardware measurements

Sheet: /
File: lm3886-v01.kicad_sch
Title: LM3886 stereo AB power amplifier

GND is a net name; route input, feedback and load returns separately.

Size: A3 | Rev: 0.3 DRAFT | F Date: 2026-09-22
KiCad E.D.A. 10.0.6 | Id: 1/1

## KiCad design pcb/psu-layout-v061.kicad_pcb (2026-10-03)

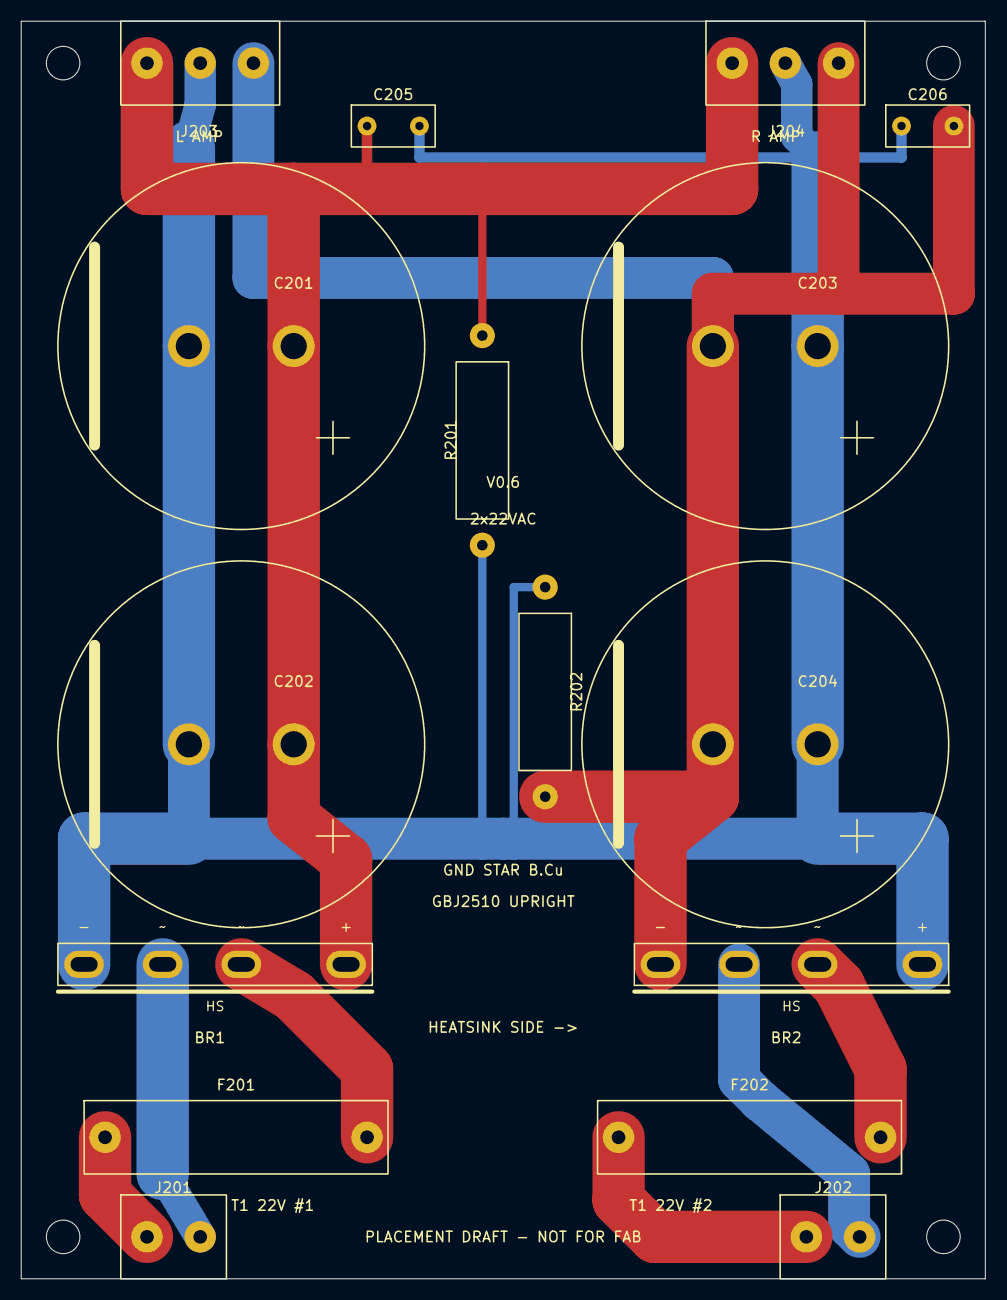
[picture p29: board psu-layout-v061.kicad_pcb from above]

Board: 2 copper layers, 92.0 x 120.0 mm, 20 parts (0 on the bottom side), 9 nets.

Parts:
BR1, BR2: >=15A / >=200V TBD; GBJ_Upright_P10_7.5_7.5
C201, C202, C203, C204: 10000u / 63V; CP_D35_P10
C205, C206: 100n / 100V film; Film_P5
F201, F202: TBD per transformer; Fuse5x20_P25
H1, H2, H3, H4: M3 provisional
J201: T1 SEC 1; Terminal2_P5.08
J202: T1 SEC 2; Terminal2_P5.08
J203: TO L AMP J5; Terminal3_P5.08
J204: TO R AMP J5; Terminal3_P5.08
R201, R202: 2.2k / 2W BLEED; R_2W_P20

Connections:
GND: BR1.N, BR2.P, C201.2, C202.2, C203.1, C204.1, C205.2, C206.1, J203.2, J204.2, R201.2, R202.1
NEG_AC1: F202.1, J202.1
NEG_AC2: BR2.AC2, J202.2
NEG_AC_FUSED: BR2.AC1, F202.2
POS_AC1: F201.1, J201.1
POS_AC2: BR1.AC2, J201.2
POS_AC_FUSED: BR1.AC1, F201.2
VCC: BR1.P, C201.1, C202.1, C205.1, J203.1, J204.1, R201.1
VEE: BR2.N, C203.2, C204.2, C206.2, J203.3, J204.3, R202.2

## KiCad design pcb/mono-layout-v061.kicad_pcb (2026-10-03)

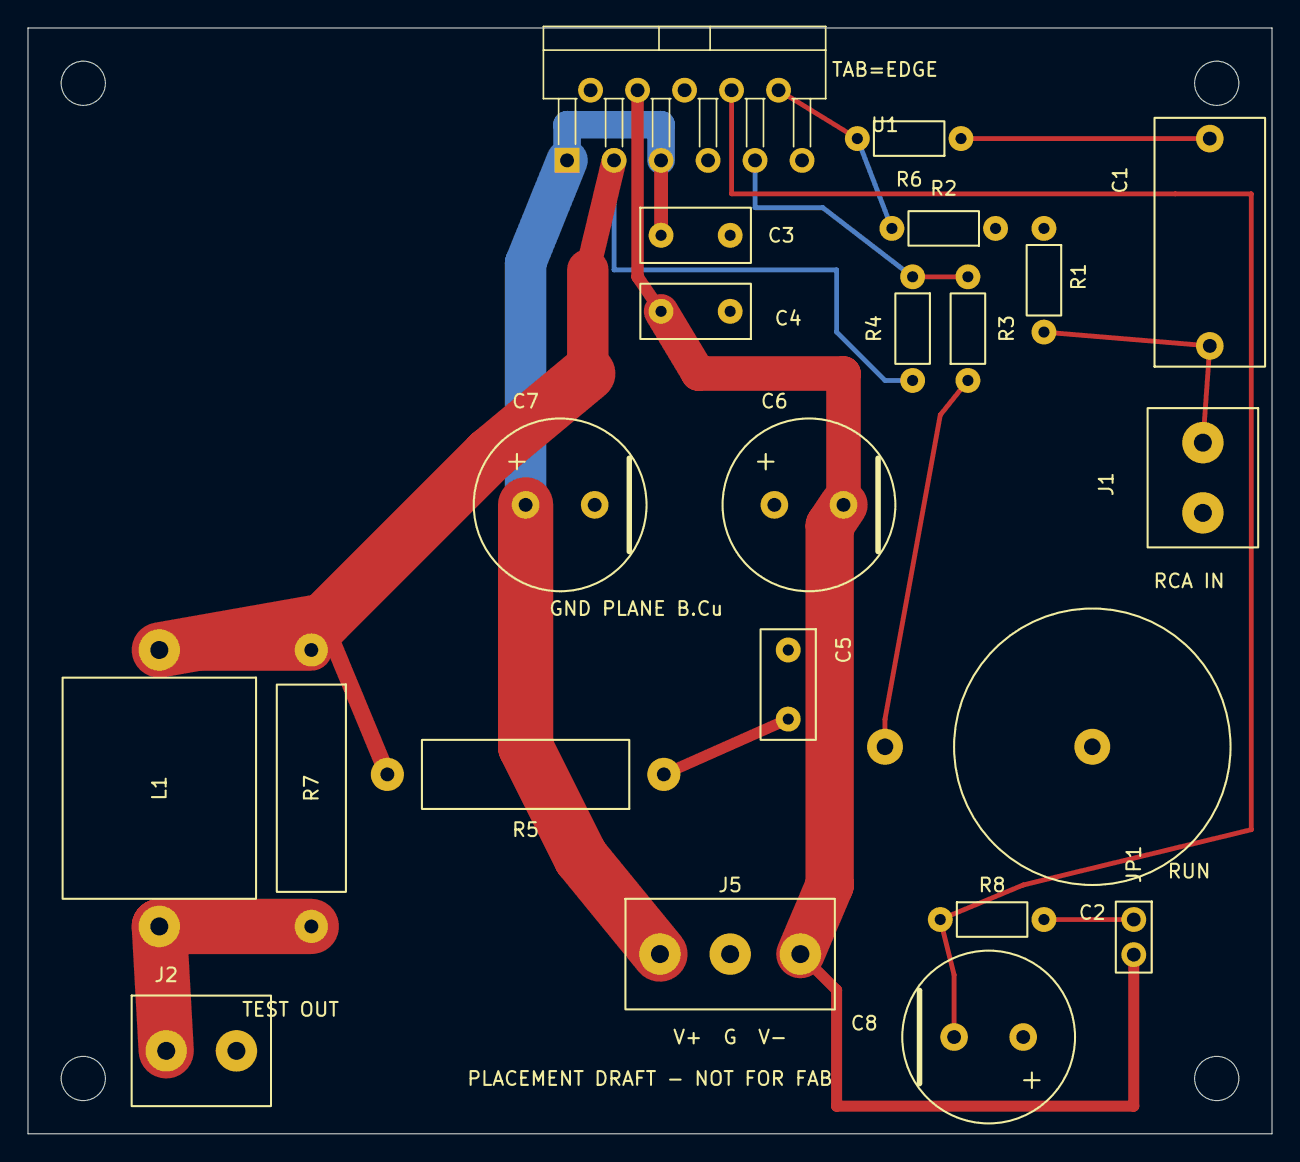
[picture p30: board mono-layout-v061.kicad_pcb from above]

Board: 2 copper layers, 90.0 x 80.0 mm, 26 parts (0 on the bottom side), 13 nets.

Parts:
C1: 2.2u / 100V film; Film_P15
C2: 47u / 63V BP; BP_Axial_Vert_D20_P15
C3, C4: 100n / 100V; Film_P5
C5: 100n / 100V film; Film_P5
C6, C7: 470u / 63V; CP_D12.5_P5
C8: 100u / 100V; CP_D12.5_P5
H1, H2, H3, H4: M3 provisional
J1: L RCA; Terminal2_P5.08
J2: L TEST OUT; Terminal2_P5.08
J5: INTERNAL PSU; Terminal3_P5.08
JP1: L RUN LINK; Header2_P2.54
L1: 0.7uH / air core; AirCoil_P20
R1: 1M; R_P7.5
R2: 22k; R_P7.5
R3: 1k / 1%; R_P7.5
R4: 20k / 1%; R_P7.5
R5: 2.7R / 2W; R_2W_P20
R6: 1k; R_P7.5
R7: 10R / 2W; R_2W_P20
R8: 22k / 0.6W; R_P7.5
U1: LM3886T; LM3886T_TO220-11

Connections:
GND: C2.1, C3.2, C4.1, C5.1, C6.1, C7.2, C8.1, J1.2, J2.2, J5.2, R1.1, R2.1, U1.7
L_AC: C1.2, R6.1
L_FB_AC: C2.2, R3.1
L_IN: C1.1, J1.1, R1.2
L_INV: R3.2, R4.1, U1.9
L_MUTE: C8.2, R8.1, U1.8
L_OUT: L1.1, R4.2, R5.2, R7.1, U1.3
L_PLUS: R2.2, R6.2, U1.10
L_RUN: JP1.1, R8.2
L_SPK: J2.1, L1.2, R7.2
L_ZOBEL: C5.2, R5.1
VCC: C3.1, C7.1, J5.1, U1.1, U1.5
VEE: C4.2, C6.2, J5.3, JP1.2, U1.4

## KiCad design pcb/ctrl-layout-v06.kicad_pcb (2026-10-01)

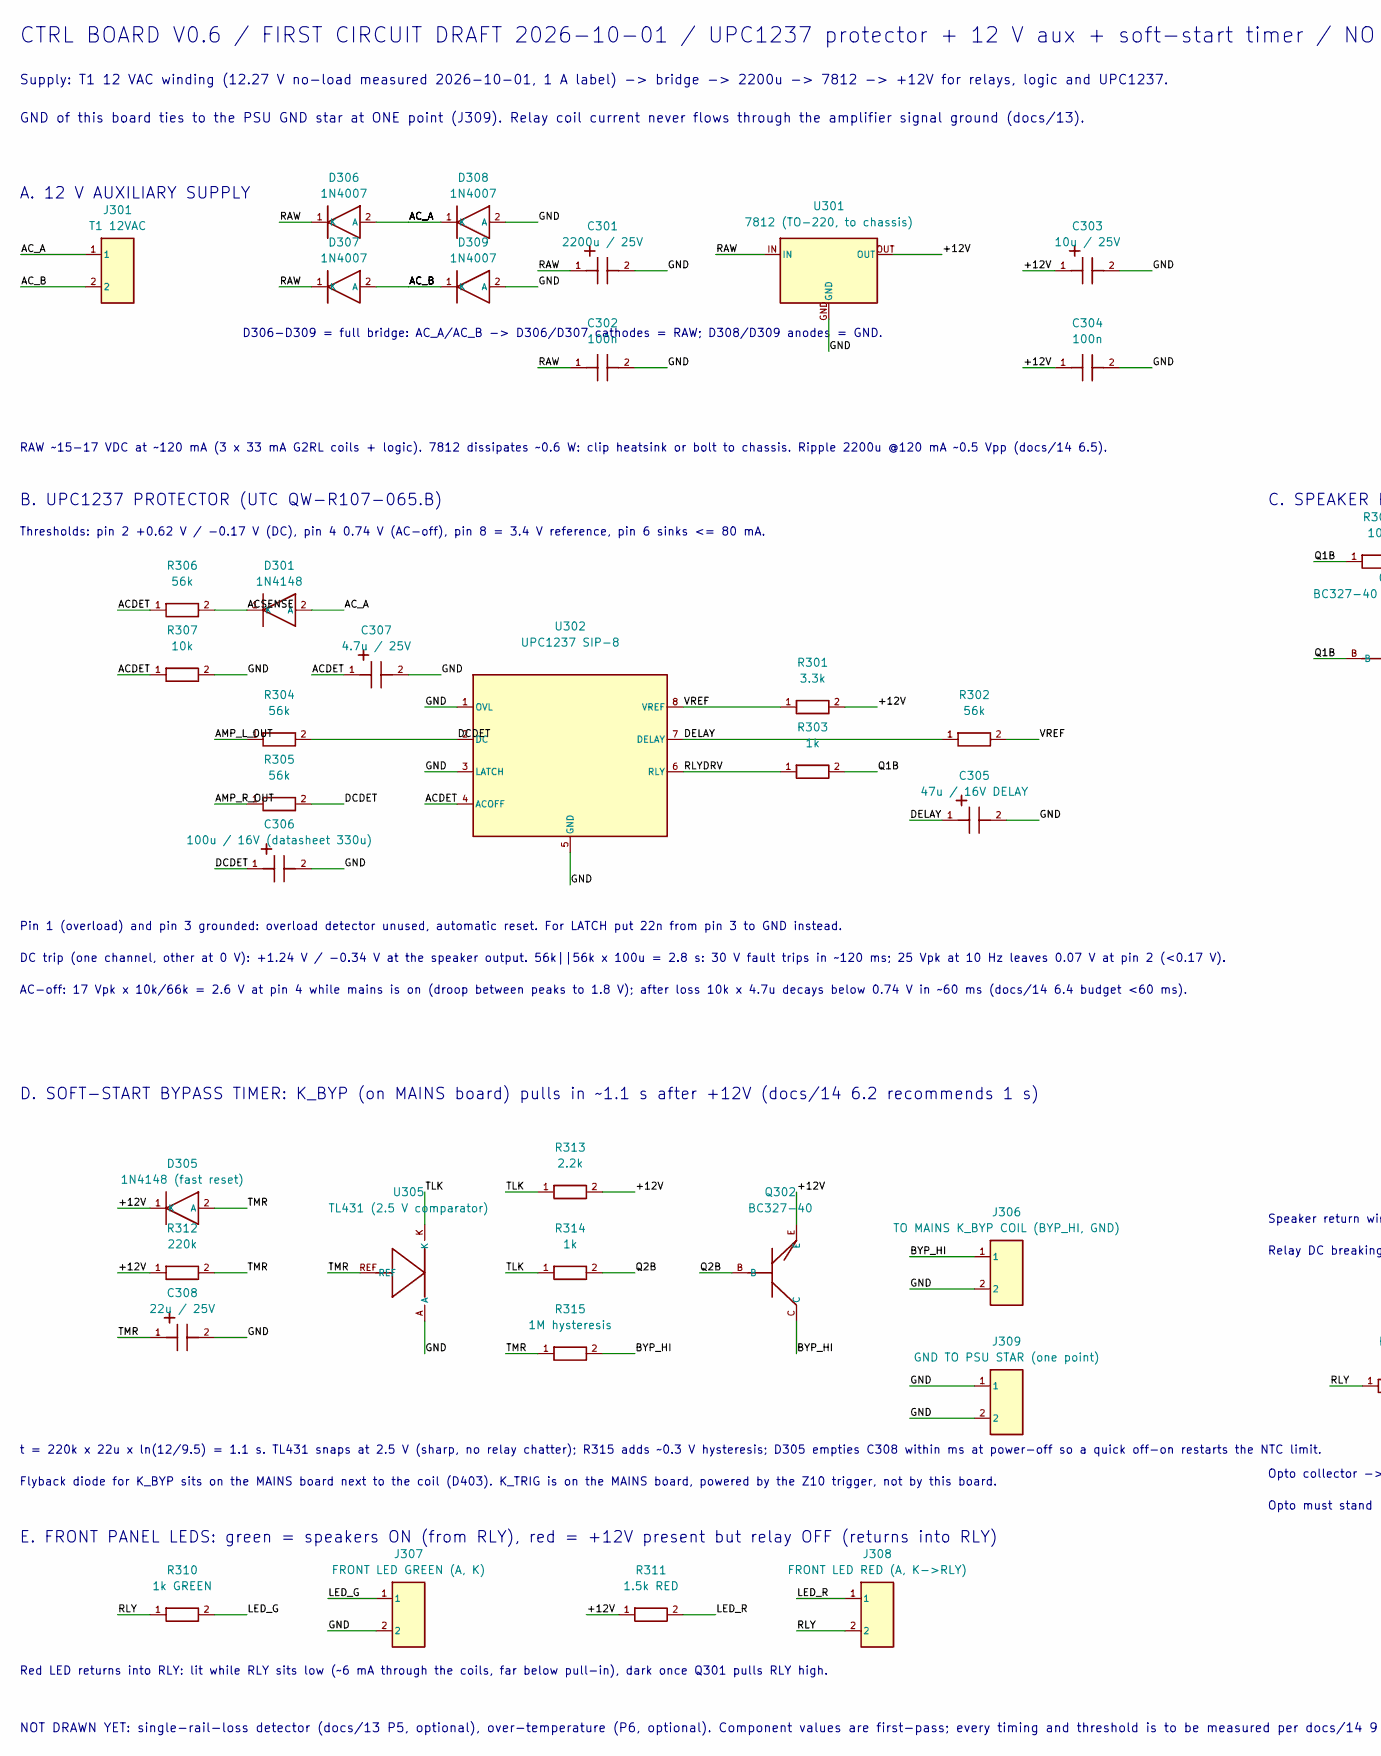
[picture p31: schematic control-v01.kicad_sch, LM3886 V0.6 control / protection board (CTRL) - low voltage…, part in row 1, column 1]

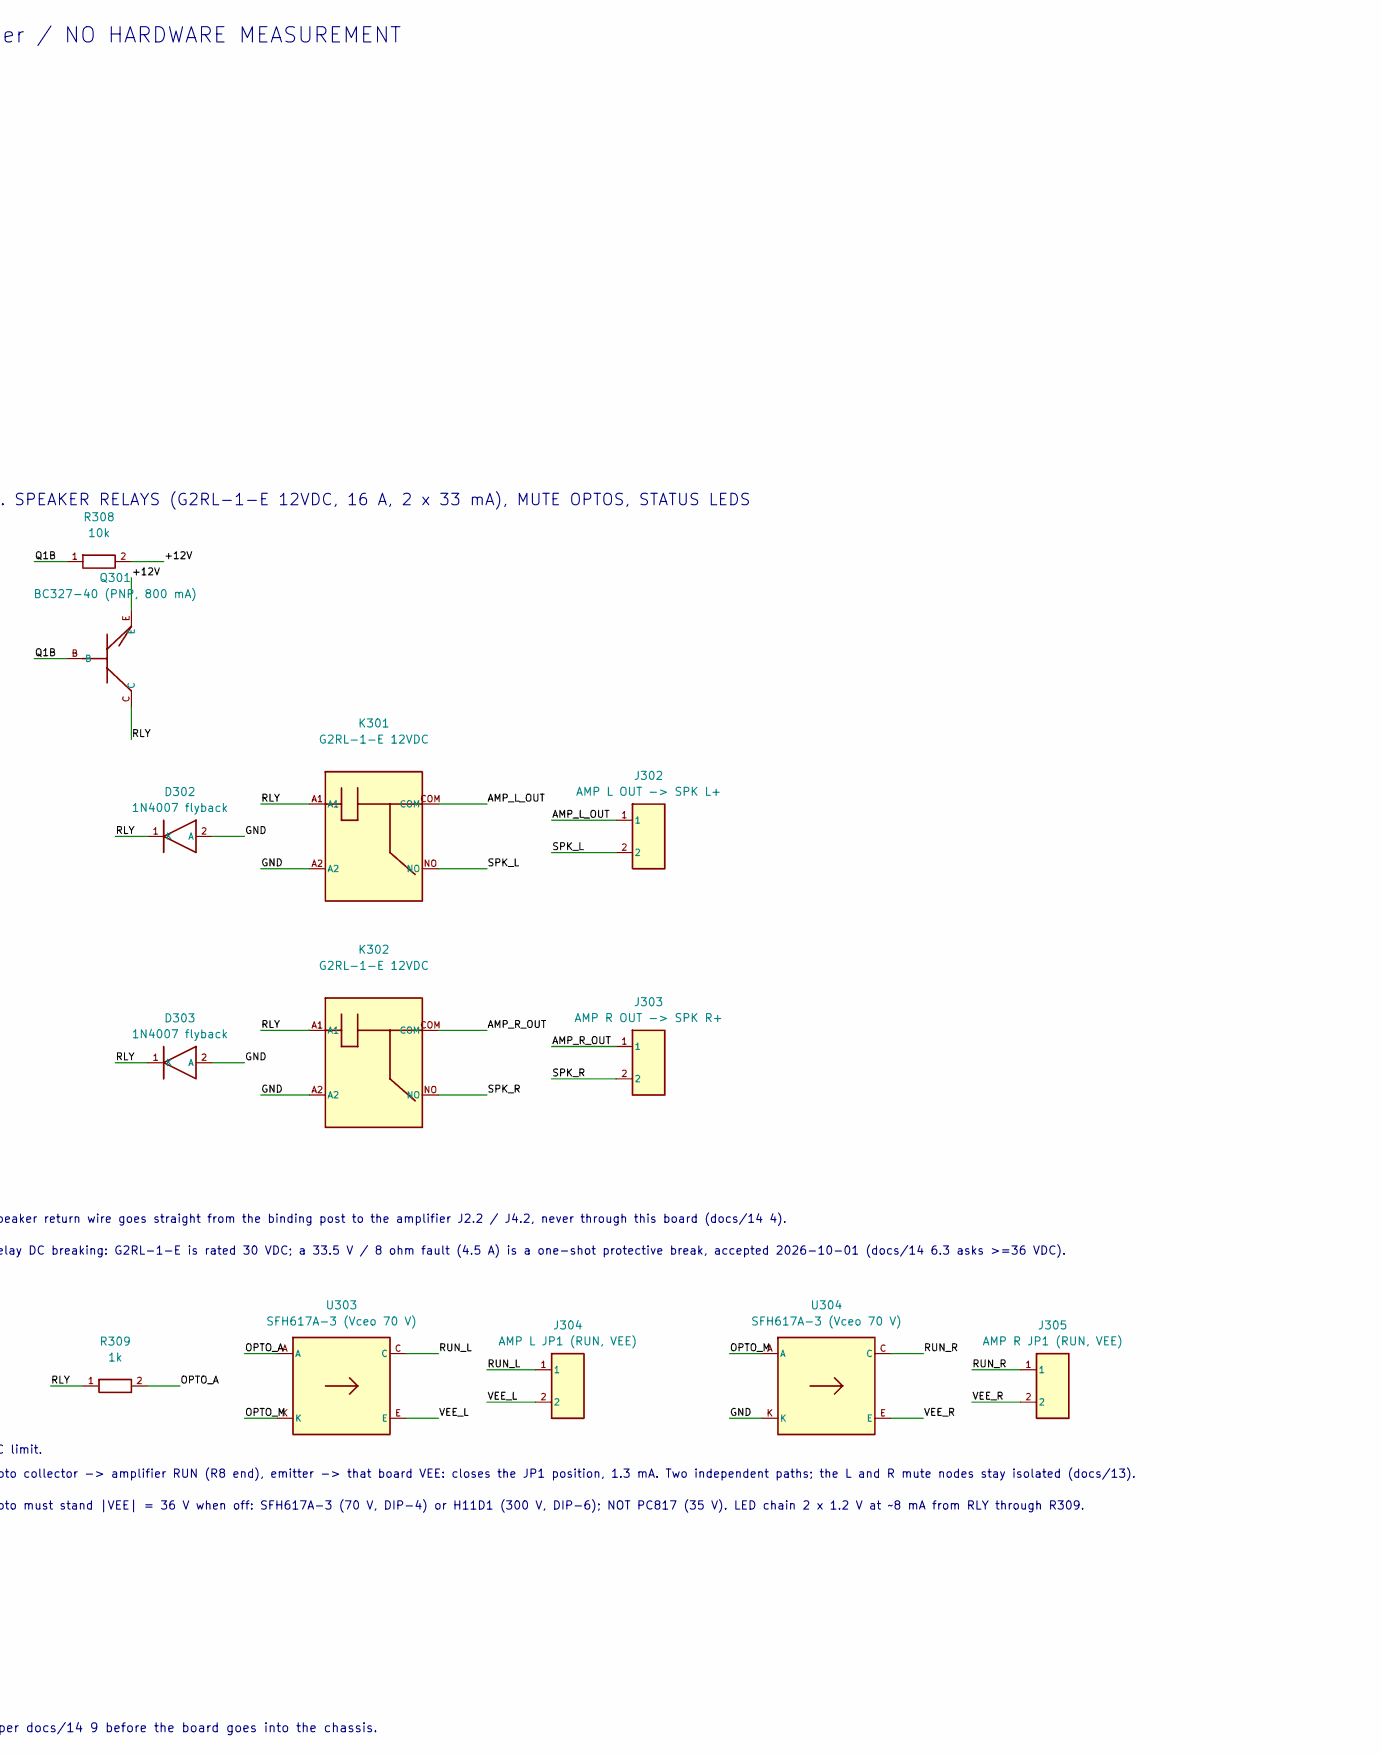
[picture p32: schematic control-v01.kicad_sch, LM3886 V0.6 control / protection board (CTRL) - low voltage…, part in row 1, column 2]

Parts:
C301: 2200u / 25V
C302, C304: 100n
C303: 10u / 25V
C305: 47u / 16V DELAY
C306: 100u / 16V (datasheet 330u)
C307: 4.7u / 25V
C308: 22u / 25V
D301: 1N4148
D302, D303: 1N4007 flyback
D305: 1N4148 (fast reset)
D306, D307, D308, D309: 1N4007
J301: T1 12VAC
J302: AMP L OUT -> SPK L+
J303: AMP R OUT -> SPK R+
J304: AMP L JP1 (RUN, VEE)
J305: AMP R JP1 (RUN, VEE)
J306: TO MAINS K_BYP COIL (BYP_HI, GND)
J307: FRONT LED GREEN (A, K)
J308: FRONT LED RED (A, K->RLY)
J309: GND TO PSU STAR (one point)
K301, K302: G2RL-1-E 12VDC
Q301: BC327-40 (PNP, 800 mA)
Q302: BC327-40
R301: 3.3k
R302, R304, R305, R306: 56k
R303, R309, R314: 1k
R307, R308: 10k
R310: 1k GREEN
R311: 1.5k RED
R312: 220k
R313: 2.2k
R315: 1M hysteresis
U301: 7812 (TO-220, to chassis)
U302: UPC1237 SIP-8
U303, U304: SFH617A-3 (Vceo 70 V)
U305: TL431 (2.5 V comparator)

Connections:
+12V: C303.1, C304.1, D305.1 (K), Q301.E, Q302.E, R301.2, R308.2, R311.1, R312.1, R313.2, U301.OUT
ACDET: C307.1, R306.1, R307.1, U302.4 (ACOFF)
ACSENSE: D301.1 (K), R306.2
AC_A: D301.2 (A), D306.2 (A), D308.1 (K), J301.1
AC_B: D307.2 (A), D309.1 (K), J301.2
AMP_L_OUT: J302.1, K301.COM, R304.1
AMP_R_OUT: J303.1, K302.COM, R305.1
BYP_HI: J306.1, Q302.C, R315.2
DCDET: C306.1, R304.2, R305.2, U302.2 (DC)
DELAY: C305.1, R302.1, U302.7 (DELAY)
GND: C301.2, C302.2, C303.2, C304.2, C305.2, C306.2, C307.2, C308.2, D302.2 (A), D303.2 (A), D308.2 (A), D309.2 (A), J306.2, J307.2, J309.1, J309.2, K301.A2, K302.A2, R307.2, U301.GND, U302.1 (OVL), U302.3 (LATCH), U302.5 (GND), U304.K, U305.A
LED_G: J307.1, R310.2
LED_R: J308.1, R311.2
OPTO_A: R309.2, U303.A
OPTO_M: U303.K, U304.A
Q1B: Q301.B, R303.2, R308.1
Q2B: Q302.B, R314.2
RAW: C301.1, C302.1, D306.1 (K), D307.1 (K), U301.IN
RLY: D302.1 (K), D303.1 (K), J308.2, K301.A1, K302.A1, Q301.C, R309.1, R310.1
RLYDRV: R303.1, U302.6 (RLY)
RUN_L: J304.1, U303.C
RUN_R: J305.1, U304.C
SPK_L: J302.2, K301.NO
SPK_R: J303.2, K302.NO
TLK: R313.1, R314.1, U305.K
TMR: C308.1, D305.2 (A), R312.2, R315.1, U305.REF
VEE_L: J304.2, U303.E
VEE_R: J305.2, U304.E
VREF: R301.1, R302.2, U302.8 (VREF)

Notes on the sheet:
CTRL BOARD V0.6 / FIRST CIRCUIT DRAFT 2026-10-01 / UPC1237 protector + 12 V aux + soft-start timer / NO HARDWARE MEASUREMENT
Supply: T1 12 VAC winding (12.27 V no-load measured 2026-10-01, 1 A label) -> bridge -> 2200u -> 7812 -> +12V for relays, logic and UPC1237.
GND of this board ties to the PSU GND star at ONE point (J309). Relay coil current never flows through the amplifier signal ground (docs/13).
A. 12 V AUXILIARY SUPPLY
D306-D309 = full bridge: AC_A/AC_B -> D306/D307 cathodes = RAW; D308/D309 anodes = GND.
RAW ~15-17 VDC at ~120 mA (3 x 33 mA G2RL coils + logic). 7812 dissipates ~0.6 W: clip heatsink or bolt to chassis. Ripple 2200u @120 mA ~0.5 Vpp (docs/14 6.5).
B. UPC1237 PROTECTOR (UTC QW-R107-065.B)
Thresholds: pin 2 +0.62 V / -0.17 V (DC), pin 4 0.74 V (AC-off), pin 8 = 3.4 V reference, pin 6 sinks <= 80 mA.
Pin 1 (overload) and pin 3 grounded: overload detector unused, automatic reset. For LATCH put 22n from pin 3 to GND instead.
DC trip (one channel, other at 0 V): +1.24 V / -0.34 V at the speaker output. 56k||56k x 100u = 2.8 s: 30 V fault trips in ~120 ms; 25 Vpk at 10 Hz leaves 0.07 V at pin 2 (<0.17 V).
AC-off: 17 Vpk x 10k/66k = 2.6 V at pin 4 while mains is on (droop between peaks to 1.8 V); after loss 10k x 4.7u decays below 0.74 V in ~60 ms (docs/14 6.4 budget <60 ms).
C. SPEAKER RELAYS (G2RL-1-E 12VDC, 16 A, 2 x 33 mA), MUTE OPTOS, STATUS LEDS
Speaker return wire goes straight from the binding post to the amplifier J2.2 / J4.2, never through this board (docs/14 4).
Relay DC breaking: G2RL-1-E is rated 30 VDC; a 33.5 V / 8 ohm fault (4.5 A) is a one-shot protective break, accepted 2026-10-01 (docs/14 6.3 asks >=36 VDC).
Opto collector -> amplifier RUN (R8 end), emitter -> that board VEE: closes the JP1 position, 1.3 mA. Two independent paths; the L and R mute nodes stay isolated (docs/13).
Opto must stand |VEE| = 36 V when off: SFH617A-3 (70 V, DIP-4) or H11D1 (300 V, DIP-6); NOT PC817 (35 V). LED chain 2 x 1.2 V at ~8 mA from RLY through R309.
E. FRONT PANEL LEDS: green = speakers ON (from RLY), red = +12V present but relay OFF (returns into RLY)
Red LED returns into RLY: lit while RLY sits low (~6 mA through the coils, far below pull-in), dark once Q301 pulls RLY high.
D. SOFT-START BYPASS TIMER: K_BYP (on MAINS board) pulls in ~1.1 s after +12V (docs/14 6.2 recommends 1 s)
t = 220k x 22u x ln(12/9.5) = 1.1 s. TL431 snaps at 2.5 V (sharp, no relay chatter); R315 adds ~0.3 V hysteresis; D305 empties C308 within ms at power-off so a quick off-on restarts the NTC limit.
Flyback diode for K_BYP sits on the MAINS board next to the coil (D403). K_TRIG is on the MAINS board, powered by the Z10 trigger, not by this board.
NOT DRAWN YET: single-rail-loss detector (docs/13 P5, optional), over-temperature (P6, optional). Component values are first-pass; every timing and threshold is to be measured per docs/14 9 before the board goes into the chassis.

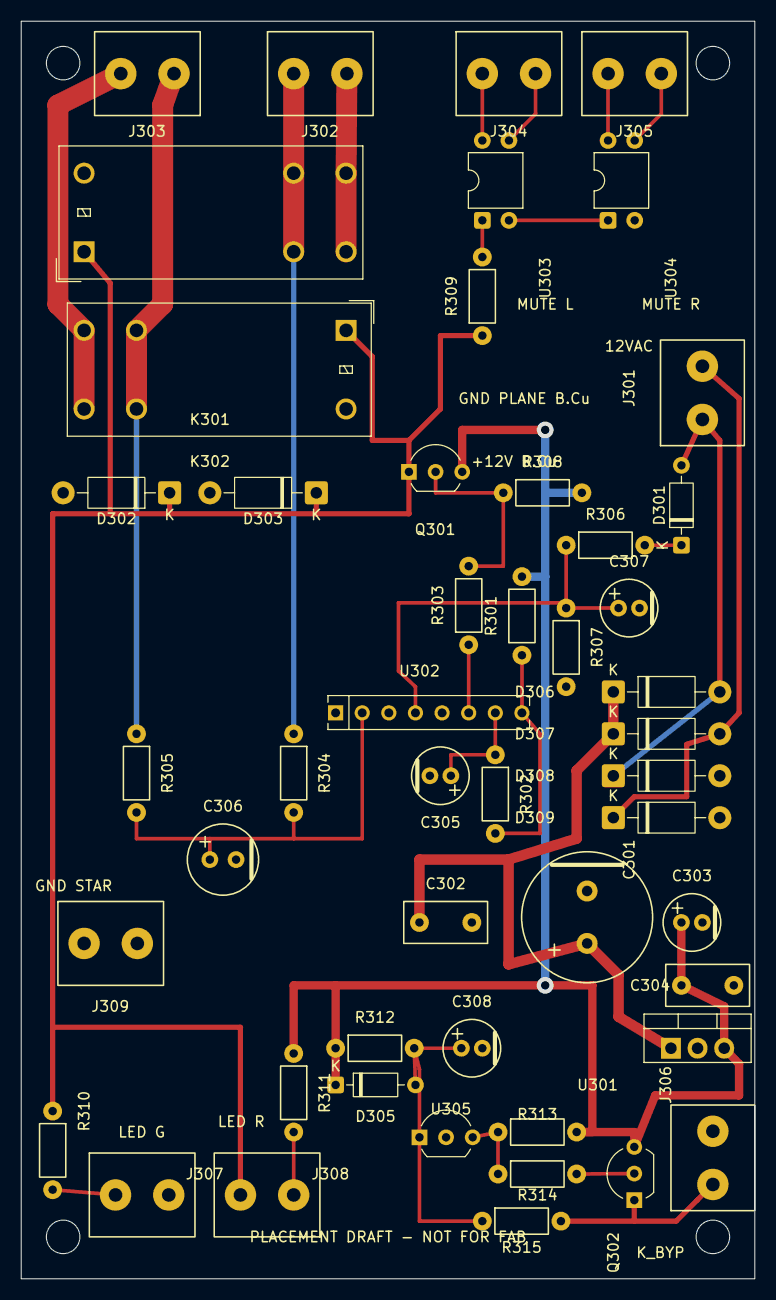
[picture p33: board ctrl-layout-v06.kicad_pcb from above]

Board: 2 copper layers, 70.0 x 120.0 mm, 53 parts (0 on the bottom side), 29 nets.

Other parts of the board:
H1, H2, H3, H4: M3 provisional

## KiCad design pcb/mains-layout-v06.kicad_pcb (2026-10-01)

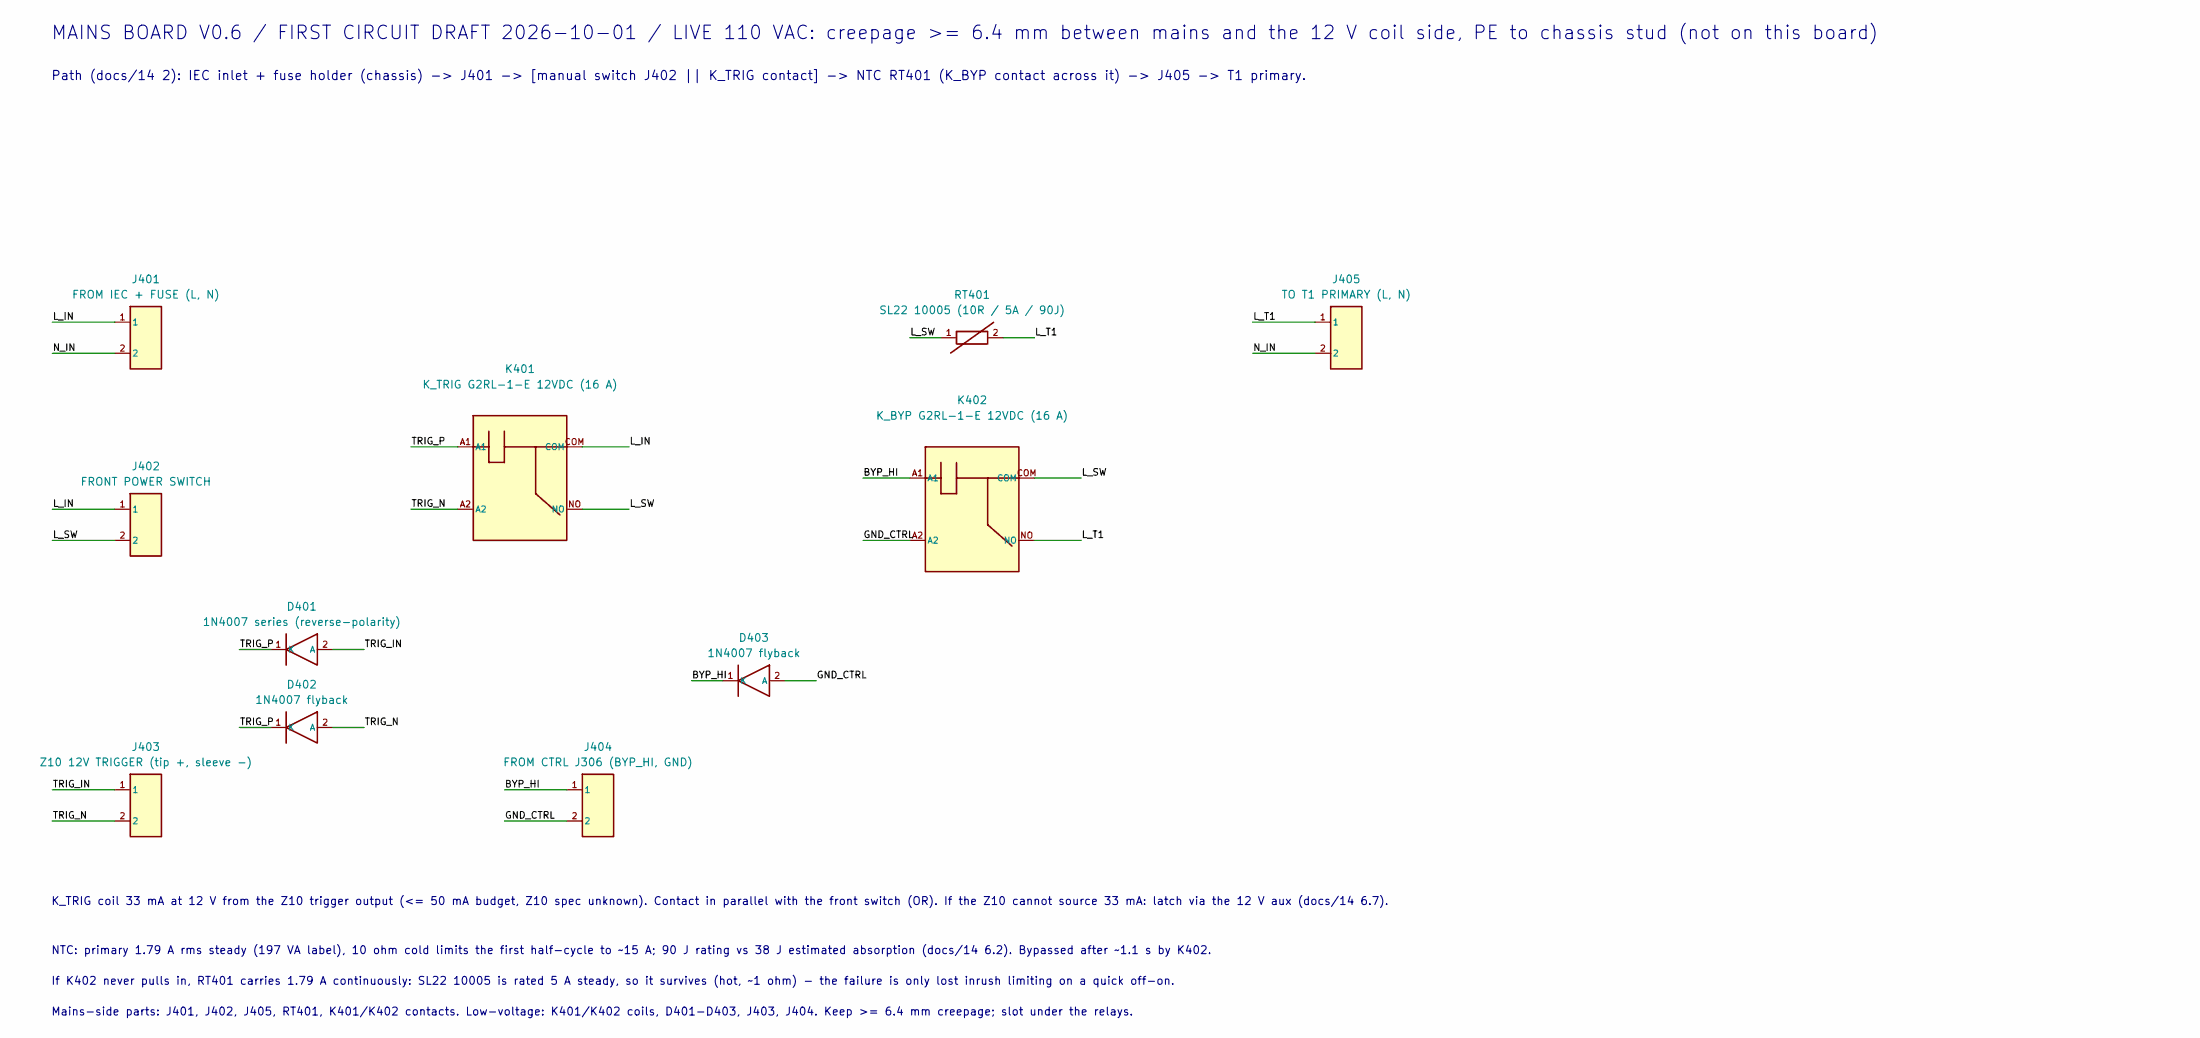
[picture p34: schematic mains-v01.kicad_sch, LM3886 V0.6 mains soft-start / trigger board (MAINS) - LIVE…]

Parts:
D401: 1N4007 series (reverse-polarity)
D402, D403: 1N4007 flyback
J401: FROM IEC + FUSE (L, N)
J402: FRONT POWER SWITCH
J403: Z10 12V TRIGGER (tip +, sleeve -)
J404: FROM CTRL J306 (BYP_HI, GND)
J405: TO T1 PRIMARY (L, N)
K401: K_TRIG G2RL-1-E 12VDC (16 A)
K402: K_BYP G2RL-1-E 12VDC (16 A)
RT401: SL22 10005 (10R / 5A / 90J)

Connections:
BYP_HI: D403.1 (K), J404.1, K402.A1
GND_CTRL: D403.2 (A), J404.2, K402.A2
L_IN: J401.1, J402.1, K401.COM
L_SW: J402.2, K401.NO, K402.COM, RT401.1
L_T1: J405.1, K402.NO, RT401.2
N_IN: J401.2, J405.2
TRIG_IN: D401.2 (A), J403.1
TRIG_N: D402.2 (A), J403.2, K401.A2
TRIG_P: D401.1 (K), D402.1 (K), K401.A1

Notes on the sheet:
MAINS BOARD V0.6 / FIRST CIRCUIT DRAFT 2026-10-01 / LIVE 110 VAC: creepage >= 6.4 mm between mains and the 12 V coil side, PE to chassis stud (not on this board)
Path (docs/14 2): IEC inlet + fuse holder (chassis) -> J401 -> [manual switch J402 || K_TRIG contact] -> NTC RT401 (K_BYP contact across it) -> J405 -> T1 primary.
K_TRIG coil 33 mA at 12 V from the Z10 trigger output (<= 50 mA budget, Z10 spec unknown). Contact in parallel with the front switch (OR). If the Z10 cannot source 33 mA: latch via the 12 V aux (docs/14 6.7).
NTC: primary 1.79 A rms steady (197 VA label), 10 ohm cold limits the first half-cycle to ~15 A; 90 J rating vs 38 J estimated absorption (docs/14 6.2). Bypassed after ~1.1 s by K402.
If K402 never pulls in, RT401 carries 1.79 A continuously: SL22 10005 is rated 5 A steady, so it survives (hot, ~1 ohm) - the failure is only lost inrush limiting on a quick off-on.
Mains-side parts: J401, J402, J405, RT401, K401/K402 contacts. Low-voltage: K401/K402 coils, D401-D403, J403, J404. Keep >= 6.4 mm creepage; slot under the relays.

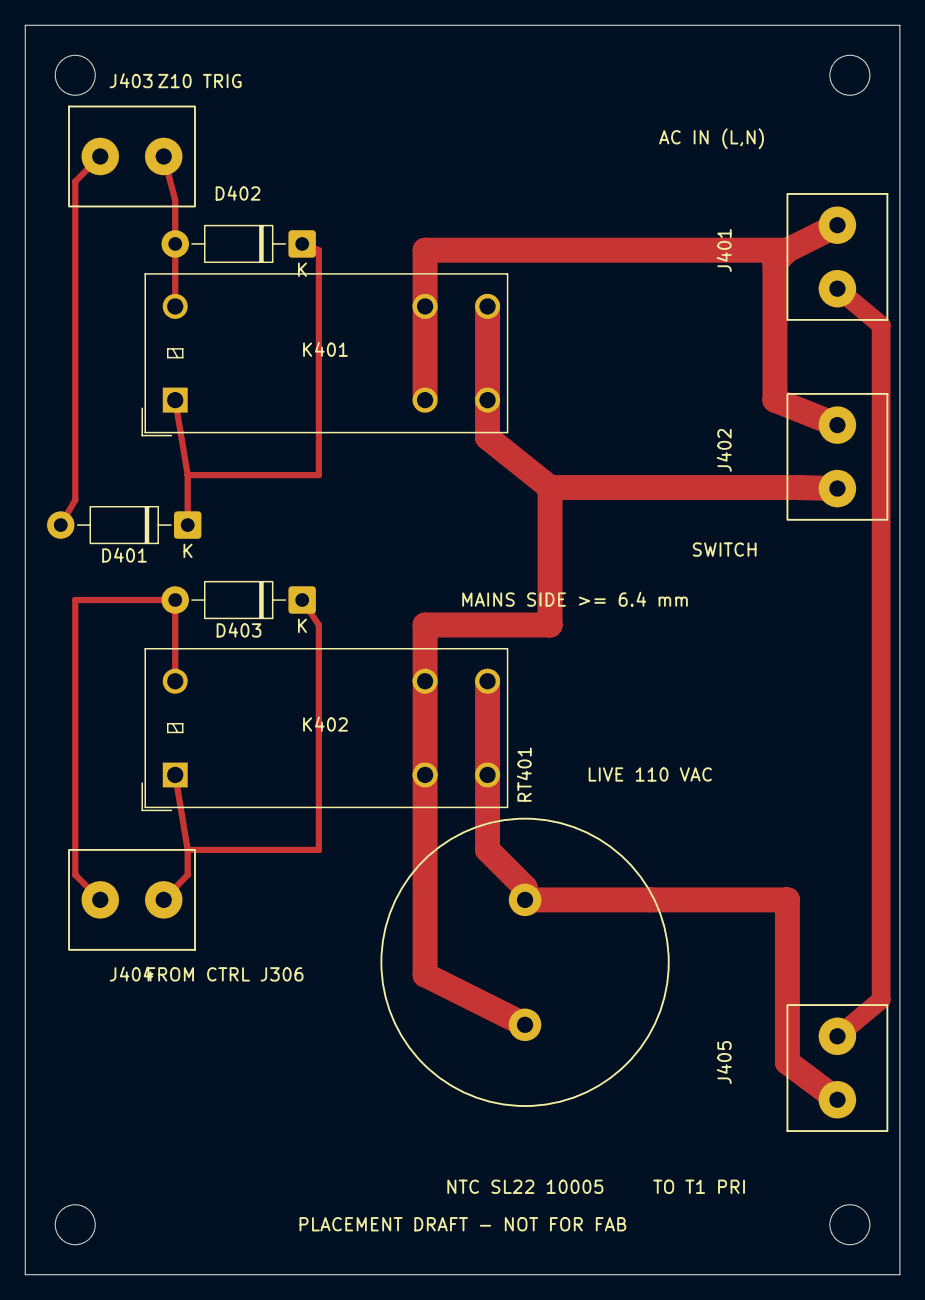
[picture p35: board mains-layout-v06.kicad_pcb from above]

Board: 2 copper layers, 70.0 x 100.0 mm, 15 parts (0 on the bottom side), 9 nets.

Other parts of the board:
H1, H2, H3, H4: M3 provisional

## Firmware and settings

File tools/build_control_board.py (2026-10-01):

"""Draw the V0.6 control / protection board (CTRL) and the separate mains soft-start board (MAINS).

Two schematic projects, like the amplifier / PSU split: electrical/control-v01.kicad_sch and
electrical/mains-v01.kicad_sch. Requirements and timing come from docs/13 and docs/14; this file is the
first circuit, not a verified design. Decisions taken 2026-10-01 with the user: self-built board around a
UPC1237 protector IC (UTC datasheet QW-R107-065.B), Omron G2RL-1-E 12 VDC relays (16 A, 33 mA coil, KiCad library footprint)
for the speakers, the soft-start bypass and the 12 V trigger, Ametherm SL22 10005 NTC (10 ohm / 5 A / 90 J)
in the mains, two boards (low-voltage CTRL near the RCA side, MAINS on the other side of the chassis).

Deviations from docs/14 section 3, both deliberate:
 * un-mute is tied to the speaker relay instead of a separate 1-2 s timer: the two mute opto-couplers
   are fed from the relay-drive node, so RUN = relay ON; the 2.2 s R8/C8 ramp on the amplifier board
   still makes the un-mute soft. One timer less, same safety (mute drops the moment the relay drops);
 * UPC1237 VCC is the regulated +12 V, not the 25-60 V of the datasheet. Pin 8 is an internal 3.4 V
   reference fed through a resistor (15 k from 45 V in the datasheet = 2.8 mA), so R301 = 3.3 k from 12 V
   gives the same current; the relay driver (pin 6, 80 mA max) drives a PNP so the two G2RL-1-E coils
   (2 x 33 mA) plus the opto/LED chain never load pin 6 directly. To be confirmed on the bench (docs/14 section 9 style check).
"""
from build_schematic import Drawing, define, passive, line

TRI = '(polyline(pts(xy 2.54 2.54)(xy -2.54 0)(xy 2.54 -2.54)(xy 2.54 2.54))(stroke(width 0.254)(type default))(fill(type none)))'


def symbols():
    define('Bridge', [('AC1', '~1', 'passive', -12.7, 5.08, 0), ('AC2', '~2', 'passive', -12.7, -5.08, 0),
                      ('P', '+', 'passive', 12.7, 5.08, 180), ('N', '-', 'passive', 12.7, -5.08, 180)],
           '(rectangle(start -10.16 10.16)(end 10.16 -10.16)(stroke(width 0.254)(type default))(fill(type background)))', 'BR')
    # diode: pin 1 = cathode (left), pin 2 = anode (right); current flows right -> left as drawn
    define('D', [('1', 'K', 'passive', -5.08, 0, 0), ('2', 'A', 'passive', 5.08, 0, 180)], TRI + line(-2.54, 2.54, -2.54, -2.54), 'D')
    define('NTC', passive, '(rectangle(start -2.54 1.016)(end 2.54 -1.016)(stroke(width 0.254)(type default))(fill(type none)))' + line(-3.5, -2.5, 3.5, 2.5), 'RT')
    define('UPC1237', [('1', 'OVL', 'passive', -17.78, 7.62, 0), ('2', 'DC', 'passive', -17.78, 2.54, 0),
                       ('3', 'LATCH', 'passive', -17.78, -2.54, 0), ('4', 'ACOFF', 'passive', -17.78, -7.62, 0),
                       ('8', 'VREF', 'passive', 17.78, 7.62, 180), ('7', 'DELAY', 'passive', 17.78, 2.54, 180),
                       ('6', 'RLY', 'passive', 17.78, -2.54, 180), ('5', 'GND', 'passive', 0, -15.24, 90)],
           '(rectangle(start -15.24 12.7)(end 15.24 -12.7)(stroke(width 0.254)(type default))(fill(type background)))', 'U')
    define('Relay', [('A1', 'A1', 'passive', -10.16, 5.08, 0), ('A2', 'A2', 'passive', -10.16, -5.08, 0),
                     ('COM', 'COM', 'passive', 10.16, 5.08, 180), ('NO', 'NO', 'passive', 10.16, -5.08, 180)],
           '(rectangle(start -7.62 10.16)(end 7.62 -10.16)(stroke(width 0.254)(type default))(fill(type background)))'
           + line(-7.62, 5.08, -5.08, 5.08) + line(-5.08, 7.62, -5.08, 2.54) + line(-5.08, 2.54, -2.54, 2.54) + line(-2.54, 7.62, -2.54, 2.54)
           + line(-2.54, 5.08, 2.54, 5.08) + line(2.54, 5.08, 2.54, -2.54) + line(2.54, 5.08, 7.62, 5.08) + line(2.54, -2.54, 6.5, -6.0), 'K')
    # NPN: collector on top, emitter below. PNP: emitter on top (toward +12V), collector below.
    body = line(-5.08, 0, -1.27, 0) + line(-1.27, 3.81, -1.27, -3.81) + line(-1.27, 1.5, 2.54, 5.08) + line(-1.27, -1.5, 2.54, -5.08)
    define('NPN', [('B', 'B', 'passive', -7.62, 0, 0), ('C', 'C', 'passive', 2.54, 7.62, 270), ('E', 'E', 'passive', 2.54, -7.62, 90)], body + line(0.6, -2.0, 2.54, -5.08), 'Q')
    define('PNP', [('B', 'B', 'passive', -7.62, 0, 0), ('E', 'E', 'passive', 2.54, 7.62, 270), ('C', 'C', 'passive', 2.54, -7.62, 90)], body + line(2.54, 5.08, 0.6, 2.0), 'Q')
    define('Opto', [('A', 'A', 'passive', -10.16, 5.08, 0), ('K', 'K', 'passive', -10.16, -5.08, 0),
                    ('C', 'C', 'passive', 10.16, 5.08, 180), ('E', 'E', 'passive', 10.16, -5.08, 180)],
           '(rectangle(start -7.62 7.62)(end 7.62 -7.62)(stroke(width 0.254)(type default))(fill(type background)))' + line(-2.54, 0, 2.54, 0) + line(1.27, 1.27, 2.54, 0) + line(1.27, -1.27, 2.54, 0), 'U')
    define('TL431', [('REF', 'REF', 'passive', -7.62, 0, 0), ('K', 'K', 'passive', 2.54, 7.62, 270), ('A', 'A', 'passive', 2.54, -7.62, 90)],
           '(polyline(pts(xy -2.54 -3.81)(xy 2.54 0)(xy -2.54 3.81)(xy -2.54 -3.81))(stroke(width 0.254)(type default))(fill(type none)))' + line(2.54, 3.81, 2.54, -3.81) + line(-5.08, 0, -2.54, 0), 'U')
    define('Reg78', [('IN', 'IN', 'passive', -10.16, 2.54, 0), ('OUT', 'OUT', 'passive', 10.16, 2.54, 180), ('GND', 'GND', 'passive', 0, -7.62, 90)],
           '(rectangle(start -7.62 5.08)(end 7.62 -5.08)(stroke(width 0.254)(type default))(fill(type background)))', 'U')
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

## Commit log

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2026-09-16 Shorten PCB bypass returns and add copper current analysis for v0.3
    [mono-layout-v03-footprints.csv, mono-layout-v03.kicad_pcb, psu-layout-v03-footprints.csv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]
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2026-09-17 Add PCB layer and assembly drawings, provisional 3D previews and parts audit
    [mono-layout-v03-preview.kicad_pcb, psu-layout-v03-preview.kicad_pcb]
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2026-09-18 歸檔 PCB V0.1／V0.2 板檔、舊腳本與舊 PDF；新增 tools/README
    依 HANDOFF 議定只搬位置不刪檔，全部 git mv 保留歷史：
    - pcb/archive/v01/、pcb/archive/v02/：板檔、DRC／驗證 JSON、封裝庫、預覽圖、舊 README
    - tools/archive/：v01（draft）與 v02 六支產生／繪圖／驗證腳本，根目錄改 parents[2]、輸出改指歸檔資料夾
    - docs/archive/：2026-09-11 舊完整 PDF
    - pcb/fp-lib-table 只留 DraftV03；v01／v02 各附自己的 fp-lib-table
    - analyze_pcb_v03.py 的 V0.2 對照來源改讀 pcb/archive/v02/，current-budget-v03.json 同步改路徑鍵
    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
    [footprint-assumptions.csv, mono-layout-v02-footprints.csv, mono-layout-v02.kicad_pcb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]
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2026-09-22 docs: 重建六張導讀圖與 PCB 預覽，同步 9/20 下單後狀態
    - build_diagrams.py：C1/C3/C4/C8 耐壓改實購 100V、R8 改 0.6W；過期採購文字改現況；
    修正 R4 標籤被橙框遮住、GND 註記壓線；IC→輸出圖頁尾改指向 pcb/README.md
    - sources.json 只綁生成器與 PDF（sch UUID 每次重建都變），文字來源 LF 正規化
    - render_pcb_v03.py：標題「B 方案」改「方案 C PCB V0.3（布局 B）」，副標改現況
    - 色塊導讀圖底圖仍為 9/16 PDF，待 KiCad 重建
    Claude-Session: https://claude.ai/code/session_01VZFcAZi4ZF5VMXyWsJWQww
2026-09-22 docs: 採購總表補型錄尺寸與漏列項，機器可讀資料改為已下單
    - 00 採購總表：新增 1.1 型錄尺寸 vs 現板封裝對照（TI/EIC/WIMA/Vishay/CDE）；
    補橋堆固定件、變壓器固定件、熱縮套管、假負載散熱片；2.1/2.2 小計；電感建議自繞
    - 發現：LM3886T 鑽孔 0.9 < 腳寬 0.97；KBPC2510 為 Faston 端子；C8 361R 為 Ø12.5/P5；
    381LX A052 料號不在現行 CDE 型錄
    - 10-planned-parts.json 全部改已下單待到貨，Mundorf/NCC 標未選；11 修 KF301 說明、加四項候選待找
    - parts-audit 逐項寫入採購狀態；footprints csv 狀態字串同步；verification.json 雜湊手動重算（LF）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
    [mono-layout-v03-footprints.csv, psu-layout-v03-footprints.csv]
2026-09-22 tools: 生成器與封裝庫依實購規格與型錄修正（板檔未重建）
    - build_schematic.py：C1/C3/C4/C8 → 100V、R8 → 0.6W、title block 移除 no PCB
    - build_power_supply.py：主電容註記改為已購
    - build_pcb_v03.py + DraftV03.pretty：LM3886T 鑽孔 1.1/焊盤 2.0；CP_D35_P10 鑽孔 2.5/焊盤 4.0
    - pcb_layout_v03.py：C8 改 CP_D12.5_P5
    - build_pcb_inspection_v03.py：採購狀態逐項化；3D 高度 Film_P15 15、Film_P5 6.5、LM3886T 22
    - .kicad_sch/PDF/BOM/.kicad_pcb/DRC 皆未重建，待封裝定案後在 KiCad 機器一次 rebuild；
    README/HANDOFF/electrical/pcb README/CHANGELOG 已註明
    Claude-Ses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
2026-09-23 docs: 修正 HANDOFF 中 KiCad 路徑的跳脫字元
    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
2026-09-23 rebuild: 原理圖與 PCB 以本機 KiCad 10.0.6 重建，兩板 DRC 0 違規
    - 原理圖：ERC 0；verify_electrical 期望值改為實購 100V／0.6W 後通過
    - PCB：修正首輪 DRC（C2/R1 保留區重疊、U1 絲印字高與壓字）與回地分組碰觸
    （靜音回流改經 via_mute_ret），DRC 0 違規 0 未連通，verify/analyze/test 通過
    - 工具：KiCad 在 Windows 寫出的 CRLF 轉 LF 後才雜湊；雜湊路徑改 as_posix()
    - 文件同步；pcb/inspection-v03 與 docs/diagrams 尚未重建
    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
    [bom-draft.csv, internal-psu-v02.kicad_sch, lm3886-v01.kicad_sch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]
2026-09-23 docs/preview: 複核後修正過期字樣、C2 距離與機殼寬度註記；重建電源圖並重綁雜湊
    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
    [internal-psu-v02.kicad_sch]
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2026-09-23 pcb: 整流橋定案鎖機殼（方案 A），電源板改 4 位端子並重建，DRC 0
    - BridgeTerminal4_P5.08 取代 Bridge_LOGICAL_UNVERIFIED（焊盤編號沿用 AC1/AC2/P/N）
    - BR1/BR2 轉 270°，四條 4 mm 進出線加轉折避開相鄰端子
    - 電源圖註記、採購總表（§1.1／§2.1，新增 Faston 端子與線材）、HANDOFF、pcb/README、CHANGELOG、README 同步
    - 兩板 DRC 0 違規 0 未連通；verify_electrical／power_supply／pcb、analyze、單元測試通過
    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
    [internal-psu-v02.kicad_sch, mono-layout-v03.kicad_pcb, psu-layout-v03-footprints.csv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]
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2026-09-24 psu: V0.4 原理圖加第二組輸出端子 J204 與每繞組 snubber 預留位（僅原理圖，PCB 未畫）
    - J203 給左聲道、J204 給右聲道，各自從匯流點供電，避免兩聲道共用端子與線電阻
    - R203/C207/C208、R204/C209/C210 為 Cx‖(Rs+Cs) 緩衝預留位，元件值待變壓器實測後定，首次上電不裝
    - verify_power_supply.py 期望值同步（22 元件、11 網路），ERC 0 違規
    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
    [internal-psu-v02.kicad_sch, psu-bom-draft.csv]
2026-09-24 pcb: V0.4 放大板變體 C（改良星型接地），DRC 0、分路檢查通過
    新增 pcb_layout_v04/build_pcb_v04/verify_pcb_v04/render_pcb_v04 與
    mono-layout-v04c 板檔、DRC、驗證、預覽。電路與封裝沿用 V0.3，只改位置
    與銅箔：C3/C4 貼 IC 腳、470µF 與 STAR 上移 IC 下方、J1 並排走線＋SG、
    Zobel 直入 STAR、C2 平放右半、過孔 0。變體 D 與電源板 V0.4 PCB 未畫。
    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
    [mono-layout-v04c-footprints.csv, mono-layout-v04c.kicad_pcb]
2026-09-24 pcb: V0.4 放大板變體 D（底層整面接地），DRC 0、鋪銅單一連通區
    座標與 C 相同，拿掉 GND 分路改底層 GND zone；生成器加 zone/填銅與 JSON
    匯出，render 畫鋪銅，verify 對鋪銅板檢查連通區數。C 板檔未變。
    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
    [mono-layout-v04d-footprints.csv, mono-layout-v04d.kicad_pcb]
2026-09-24 pcb: V0.4 電源板（每聲道端子＋snubber 預留位），DRC 0；三塊板齊
    新增 pcb_layout_v04_psu.py，build_pcb_v04 一次建 C/D/PSU。J203/J204 各一組
    3P 端子、STAR 移到端子旁、每繞組 Cx||(Rs+Cs) 預留位只留孔。verify 三板
    通過並綁雜湊，render 出三張圖。放大板 C/D 板檔未變。
    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
    [psu-layout-v04-footprints.csv, psu-layout-v04.kicad_pcb]
2026-09-24 pcb: 放大板選定 D 為主（C 保留）；D 輸出主幹改頂層，底層鋪銅完整
    輸出主幹與 Zobel 接線改 F.Cu，C7→pin1 V+ 改 B.Cu，拿掉 C3.1 多餘 V+ 分支。
    DRC 0、鋪銅單一連通區，verify 重綁雜湊。README/CHANGELOG/HANDOFF 記錄決定。
    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
    [mono-layout-v04d.kicad_pcb]
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2026-09-24 docs: 修正輸入級／IC→輸出級導讀圖的 PyMuPDF 巢狀 SVG 渲染錯誤
    embed() 改用 translate/scale 群組並移除子圖底色（PyMuPDF 不支援巢狀
    viewBox 與 clip-path）；兩張 PNG 重建，sources.json 重綁。
    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
2026-09-29 pcb: V0.5 候選——為塞進 BZ4312A2 縮板（放大板 90×90、電源板 125×130），兩板 DRC 0
    三板架構不變、電路不變，只改板形與零件位置：
    - 放大板 D 115×90→90×90：C2 EGW 47µF 躺式改站立（新封裝 BP_Axial_Vert_D20_P15，腳距 15 為假設）、
    R1/C1 直立、J1 內移、靜音零件搬右下、L_MUTE 沿上緣與右邊繞行；IC 區／輸出區／回授網路座標不動。
    - 電源板 160×120→125×130：AC 區搬上緣、輸出區搬下緣、每欄下顆電容轉 90°、洩放電阻進欄間、snubber 貼邊。
    - 新增 tools/pcb_layout_v05.py、pcb_layout_v05_psu.py、build_pcb_v05.py、verify_pcb_v05.py、
    render_pcb_v05.py、dr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
    [mono-layout-v05d-footprints.csv, mono-layout-v05d.kicad_pcb, psu-layout-v05-footprints.csv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]
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2026-10-01 pcb: V0.5.1 電源板候選——整流橋 GBJ2510 直立上板取代 KBPC2510 鎖機殼；板 125×130 不變，DRC 0
    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
    [psu-layout-v051-footprints.csv, psu-layout-v051.kicad_pcb]
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2026-10-01 docs: repo 整理——HANDOFF／tools README 重寫對齊 V0.5.1，inspection-v051 中間產物移出版控
    - HANDOFF.md 重寫：現況＋七步待辦＋V0.5.1 重建指令＋分支說明，移除 KBPC2510／機殼未選定等已作廢內容
    - tools/README.md 重寫：按 v03／v04／v05／v051 家族列出 24 支漏列腳本
    - README 目錄表、docs/diagrams/README 對齊 V0.5.1
    - .gitignore 補 inspection-v051 規則，24 個 3d 中間產物 git rm --cached
    - CHANGELOG 記錄
    Claude-Session: https://claude.ai/code/session_01Wf8BoQVARrqRCGh3NwuhH5
    [mono-layout-v05d-preview.kicad_pcb, psu-layout-v051-preview.kicad_pcb]
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2026-10-01 electrical: 控制／保護板（CTRL）與市電板（MAINS）第一版原理圖；機殼改向弘宙 102、散熱器內置
    - 新增 tools/build_control_board.py → electrical/control-v01.kicad_sch（46 件：UPC1237、7812 輔助電源、G2R-1-E ×2、H11D1 光耦靜音 ×2、TL431 旁通計時）與 electrical/mains-v01.kicad_sch（11 件：SL22 10005 NTC、K_BYP G2R-1-E、K_TR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
    - build_schematic.py：Drawing 增加 date/rev/comment；盒狀符號的參考與數值文字放符號上方
    - docs/14 狀態列、docs/00 控制板採購列、HANDOFF 現況與下一步、tools/README、CHANGELOG 同步；.gitignore 補 el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
    [control-v01.kicad_sch, mains-v01.kicad_sch]
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
